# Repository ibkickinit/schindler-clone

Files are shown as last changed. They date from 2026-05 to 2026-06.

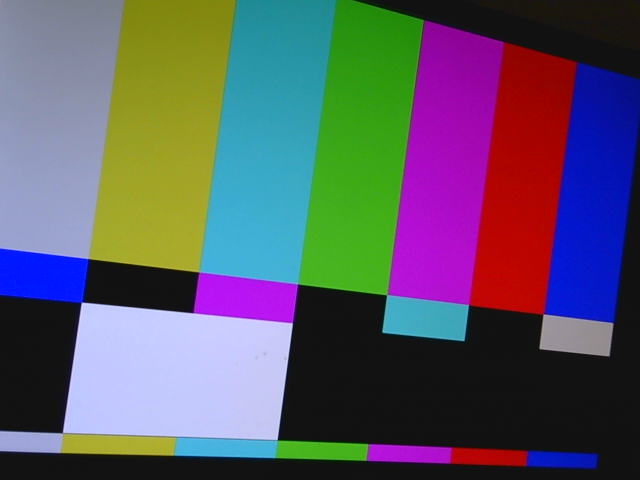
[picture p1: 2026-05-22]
Images/2026-05-21_iter2_printf_moved.jpg

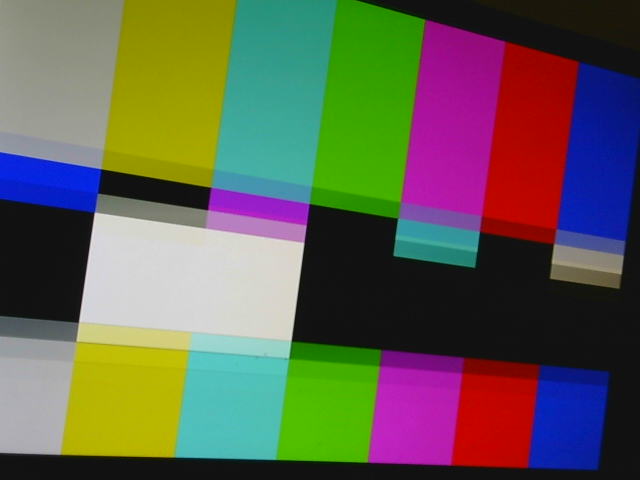
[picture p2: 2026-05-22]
Images/2026-05-21_iter4h_t2.0s.jpg

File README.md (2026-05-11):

# Schindler 2.0

A modern FPGA-based replacement for the Cal Media **Schindler MVPHD-24** — a 24fps video frame rate converter used to drive CRT monitors that appear in film shots. Roughly 75 MVPHD-24 units remain in service worldwide; this project is a from-scratch alternative scoped to modern workflows.

## Scope

- **Input:** HDMI + Composite + Component (with optional broadcast-tier SDI video IN/OUT/loop-through)
- **Output:** Composite + Component (YPbPr) + S-Video, driving 1970s consumer CRTs and broadcast monitors (Sony PVM/BVM); HDMI out for confidence monitoring or live output
- **Genlock:** to film camera reference (LTC, tri-level, black burst, word clock); SDI ref with VITC extraction
- **Frame rates:** 23.976, 24.000, 25.000, 29.97, 30.000, 47.95, 48.000, 50, 59.94, 60 fps (with 60 Hz → 50 Hz cadence conversion for cross-region content)
- **Color pipeline:** ported from the Screenie/NovaTool codebase
- **Control:** dual-band WiFi (concurrent AP + STA) + BLE setup pairing + GbE; web UI hosted on the Zynq PS under PetaLinux
- **Front panel:** 2.8-3.5" color TFT + rotary encoders + hardware buttons + status LEDs (no touchscreen)
- **Rear panel:** 2.2" color TFT (port status, 1Hz refresh) + port status LEDs (no touchscreen)
- 
## Why

The Schindler is unobtainable, expensive when found, and lacks modern color/EDID/web workflows. The market is small but underserved: rental houses, DPs shooting on CRTs, and music-video / period productions.

## Status

Early prototype phase, hardware ordered. See [`docs/01-spec.md`](docs/01-spec.md) for current spec & backlog and [`docs/schindler-playbook.md`](docs/schindler-playbook.md) for the development narrative.

## Hardware

### Development
- Digilent Zybo Z7-20 — FPGA bring-up (Zynq-7020 silicon, matches production target)
- STM32H735G-DK — UI MCU + TFT bench development
- Oscilloscope — signal analysis

### Production architecture
- Trenz TE0720 SOM — Zynq-7020 industrial (-40 to +85 °C), on custom carrier
- STM32H735IGT6 — dedicated front-panel UI MCU
- RP2040 + Si5351 — genlock PLL subsystem
- ADV7393 — composite/component/S-Video output DAC
- ADV7280 — composite/component input decoder
- Semtech GS3470 — SDI receiver (ref + optional broadcast video input)
- Semtech GS2962 — SDI transmitter (broadcast tier)
- Laird Sterling LWB5+ — pre-certified dual-band WiFi/BT module
- Custom 6-8 layer carrier PCB
- 1RU rack chassis

## License

TBD

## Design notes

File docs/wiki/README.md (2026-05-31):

# Schindler 2.0 Wiki

The conceptual + onboarding layer for the project. **Start with [START-HERE](START-HERE.md).**

## Page index

| Page | Purpose |
|---|---|
| **[START-HERE](START-HERE.md)** | 1-pager: what is Schindler, where are we now, what to read next by role |
| [OVERVIEW](OVERVIEW.md) | Product framing, market context, signal flow at 50-ft level |
| [BRANCHES](BRANCHES.md) | Which branch is production today and what each one represents |
| [PHASES](PHASES.md) | Phase A→G map. Status, sub-iter ledger |
| [ARCHITECTURE](ARCHITECTURE.md) | Pipeline topology, clock domains, AXIS interfaces, R-B-G byte order |
| [BUILD-AND-PROGRAM](BUILD-AND-PROGRAM.md) | Vivado + Vitis + program. Toolchain pinning. Common pitfalls |
| [BENCH-WORKFLOW](BENCH-WORKFLOW.md) | Osee switcher, monitor-only rule, no-coin-flip rule, verification protocol |
| [KNOWN-BUGS](KNOWN-BUGS.md) | Open bugs + recently-resolved with iter references |
| [DEBUGGING-PLAYBOOK](DEBUGGING-PLAYBOOK.md) | When-X-happens-do-Y. Core rules + symptoms → root causes |
| [FRC-ARCHITECTURE](FRC-ARCHITECTURE.md) | Methods A/B/C/D/E. RT4K three-mode. Mackin blend |
| [COLOR-PIPELINE](COLOR-PIPELINE.md) | sat → correct → matrix stages. UART tuning. R-B-G byte order |
| [FIRMWARE-INTERFACE](FIRMWARE-INTERFACE.md) | UART command reference (incl. `J` JSON-RPC). AXI GPIO map. DIAG print meanings |
| [PHASE-G-ANALOG](PHASE-G-ANALOG.md) | ADV7393 status, pin map, why blocked, resume plan |
| [PHASE-E-FRC](PHASE-E-FRC.md) | Phase E1/E2/E3/E4 state. Si5351, MMCM tracking, Triple buffer |
| [SCALER-KERNELS](SCALER-KERNELS.md) | iter14 runtime kernel-mode toggle (NN / 2-tap / 4-tap, H+V independent) |
| **[CONTROL-PLANE](CONTROL-PLANE.md)** | **V0a stack: catalog + firmware J + schindlerd + browser UI. Entry point for the V0a tier.** |
| [SCHINDLERD-RUNBOOK](SCHINDLERD-RUNBOOK.md) | Install / run / troubleshoot the daemon. Operator-facing |
| [CATALOG-EVOLUTION](CATALOG-EVOLUTION.md) | How to extend the catalog. Semver rules. Gating attributes |
| [STATUS-PANEL](STATUS-PANEL.md) | Status push protocol — firmware DIAG → telemetry parser → WS notifications |
| [FACTORY-PROFILES](FACTORY-PROFILES.md) | Four shipped baselines (identity, grayscale, warm, cool). Profile schema |
| [BRANCH-RESYNC-PLAYBOOK](BRANCH-RESYNC-PLAYBOOK.md) | How to resync mackin / phase-e1 with iter5 (task #65) |
| [HDMI-COMPLIANCE](HDMI-COMPLIANCE.md) | The rule: no out-of-spec MMCM / TMDS / vendor IP patches |
| [XILINX-IP-NOTES](XILINX-IP-NOTES.md) | Per-IP gotchas: VTC RU bit, v_vid_in sync wires, VDMA DMASR, CDC traps |
| [GLOSSARY](GLOSSARY.md) | 100+ domain terms across pipeline, phases, FRC, hardware, bugs |
| [MIGRATION-NOTES](MIGRATION-NOTES.md) | Overturned claims, stale references, restructuring notes |
| [HISTORICAL-NARRATIVE](HISTORICAL-NARRATIVE.md) | Chronological story May 2026: how we got here |

## What this wiki is (and isn't)

**Is:** the navigable conceptual map. Onboarding surface for new agents. Cross-referenced index pulling from `docs/` and memory entries.

**Isn't:** the canonical source of truth for current state. The load-bearing files at `../`:

- `../build-manifest.md` — **live build state**. Source of truth for "which build is buildable + bench-clean today."
- `../format-support-matrix.md` — **QA truth**. Source of truth for "what input/output combinations are supported."
- `../iter6-*.md`, `../iter4g-*.md`, `../scaler-*.md`, etc. — forensic records of past iter work.
- `../01-spec.md`, `../dev-roadmap.md`, `../packaging-skus.md`, `../bom-v1.md` — product SSOT.

The wiki cross-links to these; it doesn't replace them. When in doubt about current state, check the load-bearing file first; the wiki gives context.

## Finding pending work

Search the wiki for `AGENT_TASK` markers. Currently ~25 prompts categorized by role:

```bash
grep -rn 'AGENT_TASK' docs/wiki/
```

Pattern: `<!-- AGENT_TASK[role-N]: description -->`. Roles:
- `hdl-N` — RTL design tasks
- `fw-N` — Firmware tasks
- `bench-N` — Bench verification owed
- `docs-N` — Documentation tasks
- `test-N` — Test plans + execution

When you complete a task, remove the marker; reference the marker ID in your commit message.

## Wiki maintenance

This wiki was created 2026-05-30 from the audit-panel Wiki Editor proposal. It reflects state at that moment. To keep it useful:

- After any iter ships: update the relevant phase page + KNOWN-BUGS
- After branch tips move: update BRANCHES (cross-check against `../build-manifest.md`)
- New memory entries: cross-link from the appropriate page
- New domain terms: add to GLOSSARY
- Overturned claims: add to MIGRATION-NOTES
- Major events: add a section to HISTORICAL-NARRATIVE

The wiki is intentionally **lossy compression** of the corpus — not every memory entry deserves a wiki page. The point is navigation, not redundancy.

<!-- AGENT_TASK[docs-15]: DONE 2026-05-31 — SCALER-KERNELS.md authored. -->

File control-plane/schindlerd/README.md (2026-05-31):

# schindlerd

V0a host-side bridge daemon for the Schindler 2.0 control plane. Single-file Python implementation per `docs/control-plane-architecture.md` §V0a.

## What it does

- Loads the live catalog (currently `catalog-v0.2.0.json`) and validates control IDs / value coercion at the daemon boundary.
- Opens `/dev/ttyUSB1` and talks to the firmware's `J` UART command (JSON-RPC 2.0 over UART).
- Serves JSON-RPC over WebSocket on `ws://127.0.0.1:8081` for the web UI (and any future remote surface).
- Serves the web UI static files from `control-plane/web/` on `http://127.0.0.1:8080`.
- Stores profiles as JSON files in `~/.schindler/profiles/`.

## Install

```bash
cd control-plane/schindlerd
pip install -r requirements.txt
```

## Run

```bash
python schindlerd.py --port /dev/ttyUSB1 -v
```

Then open http://127.0.0.1:8080 in a browser, or connect a JSON-RPC client to ws://127.0.0.1:8081.

## Methods exposed

| Method | Params | Returns |
|---|---|---|
| `system.identify` | none | daemon+catalog+firmware versions |
| `system.catalog` | none | full catalog v0.1.0 JSON |
| `system.list_controls` | none | `[control_id, …]` |
| `control.get` | `{id}` | `{id, value}` (enum→string translated) |
| `control.set` | `{id, value}` | `{id, value}` after readback |
| `profile.list` | none | `[name, …]` |
| `profile.load` | `{name}` | `{name, applied: [id, …]}` |
| `profile.save` | `{name, controls?}` | `{name, saved: N}` |

Enum values cross the WS boundary as strings (`"boxcar_2tap"`); the daemon translates to integers (`1`) before talking to firmware.

## Protocol traces

When you turn on `-v -v` logging the daemon prints raw UART traffic. Firmware text-log lines (anything not starting with `{`) are mirrored to debug-level only.

## Limitations (v0.1)

- **No status push** — operator status bar polls via `control.get` until V0a+1.
- **No auth / TLS** — bind to localhost only by default. Reverse proxy when shipping.
- **One serial client at a time** — pyserial doesn't multiplex; daemon is the sole owner of `/dev/ttyUSB1` while running.
- **Profile validation is loose** — `profile.load` applies controls best-effort and skips failures; doesn't reject on catalog version mismatch yet.

## Where to extend

- Status push: add a polling task that reads `status.*` controls every N ms and broadcasts `notification` frames to subscribed WS clients.
- HTTP→WebSocket upgrade on the same port: rip out the stdlib HTTP and use `websockets.serve` with `process_request` to route static files.
- Profile validation: compare `profile.catalog_version` to `catalog.version` and reject majors.

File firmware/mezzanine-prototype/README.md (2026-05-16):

# Schindler 2.0 — Mezzanine UI Prototype Firmware

**Target:** RP2040-Zero (Waveshare) on a perfboard test rig.
**Purpose:** Validate encoder + button + OLED firmware against the actual production silicon and physical components before the Pro mezzanine PCB exists.

This firmware is the **production firmware brick** for the Pro mezzanine RP2040, just running on a Pico-class dev board instead of a custom mezzanine PCB. PIO programs, encoder decode logic, debounce parameters, and OLED rendering all port 1:1 to the production board when it's fabbed — pin reassignment is the only change.

## What it does

- Reads two EC11 encoders at 2 kHz (polling-based, software quadrature decode with state-transition LUT)
- Debounces all 9 switches/buttons at 5 ms (5-way nav + Set + BTN_B + two encoder shaft presses)
- Renders status to both 0.91" OLEDs at ~30 fps (independent I²C buses)
- Streams telemetry over USB-CDC for log analysis
- Encodes operational state via the on-board WS2812 RGB LED

## Hardware pin map

```
GP0     5-way nav: UP
GP1     5-way nav: DOWN
GP2     5-way nav: LEFT
GP3     5-way nav: RIGHT
GP4     5-way nav: CENTER (press)
GP5     Set button
GP6     BTN_B  (perfboard "Reset" — NOT hardware reset)
GP8     ENC A  quadrature A
GP9     ENC A  quadrature B
GP10    ENC A  push-switch (shaft press)
GP11    ENC B  quadrature A
GP12    ENC B  quadrature B
GP13    ENC B  push-switch (shaft press)
GP16    WS2812 RGB status LED (on-board RP2040-Zero)
GP26    I²C1 SDA -> OLED B
GP27    I²C1 SCL -> OLED B
GP28    I²C0 SDA -> OLED A
GP29    I²C0 SCL -> OLED A
```

Switches: active-low, internal pull-ups enabled by firmware.
OLEDs: SSD1306, I²C address `0x3C`, 128×32 (0.91").

## Build

### Prerequisites

- **Pico SDK** installed. If you don't have it:
  ```bash
  cd ~
  git clone -b master https://github.com/raspberrypi/pico-sdk.git
  cd pico-sdk
  git submodule update --init
  export PICO_SDK_PATH=$HOME/pico-sdk
  echo 'export PICO_SDK_PATH=$HOME/pico-sdk' >> ~/.zshrc   # or ~/.bashrc
  ```
- **ARM GCC toolchain**, CMake ≥ 3.13, make. On macOS:
  ```bash
  brew install cmake gcc-arm-embedded
  ```

### Copy `pico_sdk_import.cmake`

The Pico SDK ships with `pico_sdk_import.cmake` — a CMake glue file the project needs. Copy it from the SDK:

```bash
cd firmware/mezzanine-prototype
cp $PICO_SDK_PATH/external/pico_sdk_import.cmake .
```

### Build

```bash
mkdir build && cd build
cmake ..
make -j
```

Output of interest: `build/mezzanine_prototype.uf2`

## Flash

1. Hold the **BOOT** button on the RP2040-Zero
2. Plug in the USB-C cable (or press RESET if already plugged in while holding BOOT)
3. The board mounts as a USB drive named `RPI-RP2`
4. Drag `build/mezzanine_prototype.uf2` onto the drive
5. Board auto-reboots into the new firmware

## Test procedure

### Visual checks (OLEDs)

After flash + power-on, both OLEDs should show 4 lines of text within ~2 seconds:

**OLED A (driven by I²C0 on GP28/29):**
```
ENC A +0
RPM 0
CLK 0
BTN -
```

**OLED B (driven by I²C1 on GP26/27):**
```
ENC B +0
RPM 0
CLK 0
MIS 0
```

If only one OLED lights up: check I²C wiring for the dark one. If both are blank: check that the address is actually `0x3C` and pull-up resistors are present (typically 10 kΩ to 3.3 V on each SDA/SCL line — some OLED modules have these built in).

### Functional checks

- **Rotate ENC A clockwise** — `ENC A` counter on OLED A increments by 1 per detent click, `RPM` shows rotation rate, WS2812 LED turns blue
- **Rotate ENC A counter-clockwise** — counter decrements by 1 per click
- **Push the ENC A shaft** — `CLK` count on OLED A increments
- **Same for ENC B** — independent counter on OLED B
- **Press any button or nav direction** — OLED A's bottom line shows the button name (e.g. `BTN UP`, `BTN SET`), WS2812 turns yellow while held
- **WS2812 colors:**
  - Dim green: idle
  - Blue: encoder active in last 200 ms
  - Yellow: any button held
  - Red: missed encoder counts detected (something is wrong)

### USB-CDC telemetry

Connect a serial terminal at 115200 baud to the RP2040's USB-CDC interface:

```bash
# macOS - find the device first
ls /dev/cu.usbmodem*
# Then connect:
screen /dev/cu.usbmodem14201 115200
```

You should see startup banner + event-driven log lines like:

```
t=12345  a=+24 (det +12)  rpm_a=42  b=+0 (det +0)  rpm_b=0  btn=UP  miss=0
```

Rate-limited to 20 Hz for routine rotation; button events emit immediately.

## Direction sign

If a clockwise rotation makes the count go *down* on your perfboard, the A/B encoder pins are swapped vs the LUT's assumption. Two fixes:

1. **Swap pins in firmware:** in `main.c`, swap `ENC_A_PINA` and `ENC_A_PINB` (and/or B's), rebuild, reflash
2. **Re-wire the encoder:** swap the A/B leads physically

Either works. Firmware change is faster.

## What this validates (production-portable outcomes)

- PIO-free polling quadrature decoder under real EC11 contact bounce
- 5 ms software debounce parameter tuning (measure missed-count rate, adjust if needed)
- Two-encoder simultaneous handling with no shared-resource starvation
- I²C bus utilization at 400 kHz (two OLEDs at 30 fps, 512 bytes each = ~12 KB/s per bus)
- SSD1306 init sequence + 128×32 page layout
- WS2812 timing under the standard pico-examples PIO program
- USB-CDC printf overhead under encoder event rates

When the Pro mezzanine PCB exists, this firmware ports by:

1. Updating pin defines for the mezzanine carrier layout
2. Replacing the dual OLED render with BT817Q EVE command-list generation (different drawing API; encoder/button state aggregation logic stays)
3. Adding UART to Zynq PS for state sync (one new module)

## Known limitations (V1 firmware)

- Polling-based quadrature instead of PIO. Adequate for EC11 mechanical rates (max ~1000 edges/sec at extreme manual rotation) but production firmware should move to PIO for headroom + CPU savings. Polling left for V1 to keep the firmware accessible.
- No software acceleration on long scrolls (per the changelog 2026-05-10 note that 10° click pitch warrants accel). Add to V2.
- No menu state machine — this firmware is input characterization only. Menu logic comes next.
- USB-CDC log format is human-readable. Add CSV mode for log-to-file analysis later.
- Detent count = raw_count / 2 in display only. Internal counter tracks 4× quadrature edges for full precision; production may want explicit detent state machine.

## File layout

```
firmware/mezzanine-prototype/
├── main.c                   # firmware core
├── ssd1306.h                # OLED driver + 5x7 ASCII font
├── ws2812.pio               # PIO program for WS2812 (compiled to .pio.h by build)
├── CMakeLists.txt           # build config
├── pico_sdk_import.cmake    # (copy from $PICO_SDK_PATH/external/ — see Build section)
├── README.md                # this file
└── build/                   # CMake build directory (gitignored)
```

## Spec cross-reference

- `01-spec.md` § 15.1 — Mini front panel (5-way nav + buttons subset of this rig)
- `01-spec.md` § 15.2 — Pro mezzanine (dual EC11 encoders subset of this rig)
- `01-spec.md` § 17 — UI architecture (Pro mezzanine firmware role)
- `dev-roadmap.md` § 5.2 — Pro v2 mezzanine front panel build-out

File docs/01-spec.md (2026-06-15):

# Schindler 2.0 — Spec & Backlog

**Status:** Draft 2026-05-13 (post-merge unification)
**Working principle:** Stay Schindler-shaped. Width dilutes the product.

**SSOT** for the internal electronics architecture and feature set. SKU-specific packaging detail lives in [`packaging-skus.md`](packaging-skus.md). Active dev arc + deferred work in [`dev-roadmap.md`](dev-roadmap.md). Dated decision history in [`01-spec-changelog.md`](01-spec-changelog.md). Items marked **[PROPOSED]** are awaiting confirmation; everything else is confirmed.

---

## 0. Product structure

Schindler 2.0 ships in two SKUs that share **one internal electronics design** — same carrier PCB, same TE0720 SOM, same FPGA HDL, same control-plane firmware. The SKUs differ only in:

- **Chassis form factor** (Mini: half-rack 1RU / Pro: full-rack 1RU)
- **Front panel hardware** (Mini: mono OLED + tactile switches; Pro: NHD-2.9 TFT + mezzanine board + dual encoders + per-connector LEDs + rear status LCD)
- **Rear panel I/O complement** (Mini exposes the subset; Pro exposes everything)
- **Carrier stuffing variant** (Mini omits Pro-tier silicon: SDI chips, dual SYNC OUT driver chain, per-connector LED drivers, rear-LCD driver)

*(The **RF modulator** is **not** part of this stuffing-variant split — it's a truly optional standalone daughter-board module; see the note after the SKU table and §3.9.)*

| SKU | Positioning | Indicative retail |
|---|---|---|
| **Mini (v1)** | Lean entry. NTSC/film cadence workflows. HDMI + composite + component + genlock + Ethernet/WiFi. Half-rack chassis. | $1,500–2,500 |
| **Pro (v2)** | Full broadcast-grade. Adds SDI in/out, dual SYNC OUT with cross-rate conversion, rear status LCD, per-connector LEDs, full TFT + mezzanine UI. Full-rack 1RU chassis. RF modulator (period CRT support) available as an optional add-on module — see note below. | $2,500+ |

Pro v2 is gated on Mini v1 selling. **Engineering work targets the unified electronics design** — Mini and Pro are packaging + stuffing variants of one carrier, not two separate hardware development tracks.

**RF modulator (Period CRT support) — truly optional module (2026-06-12).** RF is a self-contained shielded daughter board, **orthogonal to the stuffing variant**: never fitted by default, added only when ordered. The carrier (common to both SKUs) always carries the u.FL + 6-pin interface footprints (~$1.70), so RF is a clean populate/omit on any build with no respin. Offered as a Pro-tier option; **Mini-eligibility is an open product/commercial call** (technically supported on any carrier). See §3.9 + [`rf-modulator-daughter-board-option.md`](rf-modulator-daughter-board-option.md).

See [`packaging-skus.md`](packaging-skus.md) for SKU-by-SKU stuffing tables and chassis detail.

---

## 1. Hardware foundation

### 1.1 SoC module

- **Trenz TE0720 SOM** — Xilinx Zynq-7020. **Production target: TE0720-04-62I33MA** (XC7Z020-2I speed grade, industrial -40 to +85°C, 1 GB DDR3L, 32 MB QSPI flash, 8 GB eMMC, GbE PHY on-module). 152 FPGA I/O via Samtec Razor Beam connectors. Module-level cost ~$300 at qty 100.
- Bench evaluation runs on a TE0720-04-31C33MA SOM (commercial -1 speed grade, same memory config, identical pinout) when available; primary bench dev platform is the Digilent Zybo Z7-20 which shares the same Z-7020 silicon family — HDL ports 1:1.
- **Explicitly ruled out:** -61C530A and similar 256 MB / no-eMMC TE0720 variants — insufficient memory for the Linux-hosted video pipeline (need 1 GB DDR3 for frame buffers + PetaLinux + Node.js + working memory; need eMMC for Linux rootfs).

### 1.2 Carrier PCB

- **Custom 4-layer FR-4 board, ENIG finish**, ~150 × 120 mm estimated, accepts the TE0720 SOM via 2× Samtec LSHM-150 100-pin + 1× Samtec LSHM-130 60-pin Razor Beam connectors (8 mm mating height, ~$30 connector set per unit).
- **What the carrier does NOT need:** BGA layout, DDR3 routing, HDMI differential routing, USB/Ethernet PHY layout. All of that's on the TE0720 SOM. The carrier is conventional mixed-signal PCB work — analog video chains, panel I/O, genlock front-end, WiFi module footprint, power tree, front-panel connector. Layout effort estimate: 3–5 weeks focused work.
- **One PCB design, two stuffing variants** (Mini / Pro). All silicon footprints exist on every carrier; stuffing differs at assembly.
- **Design rule:** unused TE0720 PL pins route to a 2× 20-pin (or 1× 40-pin) 2.54 mm expansion header. Preserves field-upgrade and prototype-extension paths.

### 1.3 Power & safety

- **Power budget:** ~10–14 W typical (Mini), ~14–18 W typical (Pro), ~22 W peak (Pro).
- **AC entry — pre-certified module path.** Custom AC-DC design intentionally avoided (would add ~$15–25K and 3–6 months of NRTL certification for negligible benefit at ~75 unit lifetime volume). All AC-side components carry their own certifications.
- **IEC inlet:** Schaffner **FN9260B-6-06** — C14 + 6 A + integrated fuse holder + 1-stage EMI filter. ~$18 BOM.
- **Mains fuse:** 2 A T (time-lag), 5×20 mm cartridge. Sized for 120 VAC worst-case (steady state ~0.21 A RMS, 7–10× headroom; comfortably absorbs ~25 A / 5 ms cold-start inrush).
- **No rocker switch.** IEC cord = service disconnect; front-panel soft power button handles daily on/off.
- **PSU module — primary:** Mean Well **LRS-50-12** — 50 W / 12 V single output, 85–264 VAC universal, enclosed aluminum case, convection-cooled, UL 62368-1, EN 55032 Class B. ~$15–20.
- **PSU module — alternate:** TDK-Lambda **HWS50A-12/A** — same form factor, lower switching noise. ~$50. Swap-in if Mean Well noise shows up as audible artifact during bench characterization.
- **Mains wiring inside chassis:** UL 1015 stranded, 18–20 AWG, three-conductor, short captive run from IEC inlet to PSU module screw terminals.
- **Earth bonding:** chassis ground stud as the single bond point. IEC earth + PSU earth + chassis enclosure all bonded to stud. Carrier digital ground tied to chassis earth at one point only (single-point earth, prevents ground loops through the analog signal chain).

**Carrier-side 12 V protection chain:**

| Function | Part | Notes |
|---|---|---|
| Protection eFuse | TI **TPS26601** | 60 V integrated FET: reverse-polarity + reverse-current, adjustable OVP, adjustable OCP (precise limit, no polyfuse thermal-derate), controlled inrush slew. EN = front-panel soft-power gate; I<sub>LIM</sub> ≈ 2.5 A. **Latch-off is the '601's MODE-open default (MODE left open, no strap)** — swapped from TPS26600 2026-06-13b (the '600 defaults to auto-retry). Replaces the prior reverse-FET + polyfuse + TVS chain. |
| Power monitor | TI **INA226** + 5 mΩ shunt | I²C 16-bit current+voltage on 12 V rail (telemetry alongside the eFuse). PSU-healthy proxy (LRS-50 has no DC-OK pin). |
| Bulk cap | 3× Murata GRM32 22 µF 25 V X7R MLCC | ~66 µF nominal (~35 µF effective at 12 V DC bias); MLCC over electrolytic for 10+ year service life. |
| PSU→carrier connector | Molex **Mini-Fit Jr.** 2-pin locking | 9 A rated. |
| Soft-power controller | ADI **LTC2954-1** | Pushbutton on/off controller in the always-on 12 V domain (2.7–26.4 V, 6 µA standby — no standby LDO needed). Debounced front-panel button → drives eFuse EN. **INT** → Zynq GPIO (orderly-shutdown request); **KILL** ← Zynq GPIO (clean power-down once Linux has synced); **PDT** watchdog (~5 s) force-off if the PS hangs; turn-on KILL-blank 512 ms lets the system raise KILL during boot. Resolves the chicken-and-egg where the RP2040 sits downstream of the rails it would switch. Button LED off EN state, with an RP2040 leg for status patterns once booted. |

**Per-rail regulators (downstream of protected 12 V) — committed 2026-06-11.** All bucks/LDOs with built-in OCP + thermal shutdown. The TE0720's Vccint 1.0 V, 1.8 V, and DDR3L 1.35 V are generated **on-module** (from VIN) — the carrier does NOT supply them. VIN is fed from the 5 V rail (see `sheet3-te0720-som-backbone.md` §2).
- **5 V (~3 A) — TI LMR33640 (4 A)** buck (12→5 V). Feeds module VIN, USB host, analog op-amps (single +5 V, AC-coupled at the BNCs — no negative rail).
- **3.3 V (~2.5 A) — TI LMR33640 (4 A)** buck (12→3.3 V), same part, 2nd instance. Feeds module 3.3VIN, all four VCCIO banks (3.3 V), carrier digital.
- **1.2 V (~0.4 A) — TI TLV62568** buck (5→1.2 V) [Pro]. GS3470 (~0.15 A) + GS2962 (~0.25 A) on 1.2 V core+analog — verified ~0.3–0.4 A total (GS2962 cable driver sits on 3.3 V analog, not here), so the 1 A part has ample margin.
- **1.8 V analog (~0.4 A) — per-chip low-noise LDOs (TI TPS7A20 / ADI ADP7142 class)** from 3.3 V via ferrite: AD9204 AVDD (dedicated POL), ADV7280 analog, ADV7393 VDD/PVDD (digital + PLL on a clean tap), and **ADV7511 analog/PLL (AVDD/PVDD = 1.8 V)**. Isolated from buck switching for precision genlock.
- **1.8 V digital (~0.1 A) — small LDO off 3.3 V (`+1V8_D`):** VCCIO33 (PL bank 33) + AD9204 DRVDD. Added 2026-06-13 when B33 was re-strapped to 1.8 V to match the AD9204's 1.8 V CMOS data outputs (the module allows 1.2–3.3 V on B33). Kept separate from the analog 1.8 V so ADC output-driver switching stays off the AVDD.
- **3.3 V analog branch — clean tap off the 3.3 V rail** (ferrite + local bulk): ADV7393 VAA (~0.15–0.2 A) only — **ADV7511 analog is 1.8 V, moved to the 1.8 V analog domain (corrected 2026-06-13)**; the **GS2962 cable driver gets its own ferrite branch** (SDI-rate transients kept off the DAC analog).
- **Clean analog rails — point-of-load ultra-low-noise LDOs** (ADP7142 class) per ADC/decoder, sized at schematic.

### 1.4 Resolution ceiling

- **1080p60 max** input + output for V1. HDMI 1.4 input handled by **Lontium LT8619C** RX (Z-7020 has no MGTs, no direct TMDS deserialize).
- 4K deferred to v2 / Schindler 3.0 — requires SoC upgrade (Zynq UltraScale+ ZU3EG/ZU4EV via TE0820/TE0822), DDR4, HDMI 2.0/2.1 silicon, HDCP 2.2/2.3 licensing. Treated as a separate product, not a V1 stretch goal.

---

## 2. HD pipeline architecture

### 2.1 Pipeline carries HD-bandwidth video throughout

RGB or YCbCr 4:2:2 at up to 1080p60 (148.5 MHz pixel clock) flows from input decoder through scaler / color / geometry to a shared HD signal bus. Downconversion to SD and rate-conversion happen **only inside per-output terminal encoders** that need it (composite, S-Video, SD component).

### 2.2 Outputs are independent and concurrent

The HD signal bus fans out to one terminal encoder per output. All terminals can run simultaneously at their own format and rate. Example: 1080p60 HDMI source can drive 1080p60 HDMI OUT + NTSC composite OUT (downconvert + 5:2 cadence + composite encode) + HD component OUT (YPbPr) all live from the same source.

### 2.3 Terminal encoders (independent FPGA blocks)

- **HDMI passthrough terminal** [All SKUs] — format-match or rate-convert, then HDMI 1.4 TX. Drives the external ADV7511 HDMI TX chip on the carrier. HDCP-protected content gated by UI consent dialog (§ 3.5).
- **NTSC/PAL composite encoder terminal** [All SKUs] — HD-to-SD downconvert + cadence convert + luma+chroma encode + sync gen. Drives ADV7393 in composite mode. HDL: `hdl/vid_timing.v` + `hdl/vbi_gen.v` + `hdl/chroma_gen.v` + `hdl/sample_gen.v` (Phase 2 first-light validated on Zybo + R2R DAC; chroma burst verification deferred per `dev-roadmap.md`).
- **Component YPbPr encoder terminal** [All SKUs] — HD passthrough or SD downconvert, drives ADV7393 in component mode.
- **SDI passthrough terminal** [Pro only] — HD re-serialize, drives GS2962.

### 2.4 Test pattern generator + still buffers as source

TPG + 4 still image buffers selectable as input source via the source mux (alongside HDMI / SDI / composite / component inputs), default at power-on. See `signal-flow.md` diagram 1.

---

## 3. Per-subsystem detail

### 3.1 HDMI input [All SKUs]

- **TPD12S016PWR** (TI) — HDMI ESD clamps + DDC/HPD level shift + 5V cable-power switch. ~$1.50.
- **LT8619C** (Lontium) — HDMI 1.4 RX, parallel RGB output to FPGA, embedded HDCP 1.4 keys (Lontium holds DCP Adopter Agreement). ~$2.
- Parallel RGB bus (24-bit + HSYNC + VSYNC + DE + pixel clock, ~28 lines) to TE0720 PL.
- I²C control from TE0720 PS — input mode, EDID (advertise V1's supported rates: 720p / 1080p / 1080i at 24/30/60 Hz; explicit reject of 25/50 Hz unless international firmware enables them).

### 3.2 HDMI output [All SKUs]

- **ADV7511KSTZ** (Analog Devices, LQFP-100) — HDMI 1.4 TX. Parallel RGB or YCbCr 4:2:2 input from FPGA on **its own dedicated 16-bit bus** (no longer shared with ADV7393); TMDS output. **Utility/monitoring output — no HDCP asserted on the TMDS output** (avoids the Xilinx HDCP-TX IP + DCP adopter license); a UI toggle disables the default HDCP block so protected content passes unencrypted per § 3.5. ~$7.
- **TPD12S016PWR** — second instance on output side for ESD/level shift.
- HDMI Type A panel-mount connector.
- I²C control from TE0720 PS.
- **Independent output buses (2026-06-11):** HDMI OUT, SDI OUT, and analog OUT each have their own FPGA read engine and parallel bus — no sharing. (Supersedes the earlier ADV7511/ADV7393 shared-bus optimization: the pin budget fits at ~119/152 PL without it, and sharing forced HDMI-out to track analog-out's format/rate — which broke concurrent 1080p60-HDMI + SD-composite, the headline §2.2 use case.)

### 3.3 Composite / component / S-Video input [All SKUs]

- **ADV7280AWBCPZ-M-RL** (ADI, AEC-Q100 grade, MIPI-capable variant) — multi-format decoder. CVBS + YPbPr + S-Video → BT.656 YCbCr 4:2:2 parallel bus to FPGA. ~$19.
- **SD-only input** — the ADV7280 decodes standard-definition only (480i/576i): CVBS, S-Video, and **SD component** YPbPr. **HD analog component (1080i/p) is not an input path** — HD enters via HDMI/SDI and the box upconverts SD analog → HD. (HD analog in would need an ADV7842-class decoder — out of V1 scope.)
- BNC 75 Ω panel-mount: 1× CVBS in + 3× YPbPr (component in). S-Video silicon-capable; no V1 mini-DIN connector (dropped 2026-05-11).
- I²C control from TE0720 PS.
- Passive front-end: input clamp diodes, switchable 75 Ω termination, AC-coupling, anti-alias LPF — schematic-phase.

### 3.4 Composite / component / S-Video output [All SKUs]

- **ADV7393BCPZ-REEL** (ADI) — triple 10-bit DAC with composite/S-Video/component encoding. I²C-switched runtime mode: composite/S-Video (DAC_A=CVBS, DAC_B=Y, DAC_C=C) OR component (DAC_A=Y, DAC_B=Pb, DAC_C=Pr). ~$16. Fed from the FPGA on **its own dedicated 16-bit parallel bus** (independent read engine; 16-bit carries SD composite/S-Video plus SD/ED/HD component per §2.2).
- **Output buffers (consolidated 2026-06-11):** 2× **LMH6643MAX/NOPB** dual op-amps (4 ch, 3 used) — one 130 MHz HD-capable channel per DAC output, serving both composite and component modes (single +5 V, AC-coupled at the BNCs). Replaces the prior OPA2350 SDTV-tier + single LMH6643: the 3-channel HD component path needs 3 HD buffers, so the two-tier split under-counted; all-LMH6643 is one part type, HD on every channel. ~$3 total. **One channel (4th of the 4) is spare.**
- **Optional second composite output [pre-layout decision, 2026-06-12]:** the spare LMH6643 channel can drive a second buffered CVBS output (its own 75 Ω back-term) to a rear BNC. Two ways to expose it: (a) an always-present second composite out — a composite mult/loop, useful for feeding a local monitor + a record path at once; or (b) in the **no-RF stuffing variant**, repurpose the rear F-connector position as this second composite BNC (RF fitted → F-connector; RF omitted → 2nd composite). Either way the footprint + back-term + panel position must be fixed **before carrier layout** (a respin to add later — same class as the 2nd-GbE-jack flag). The RF baseband tap is unaffected: it's a high-Z bridge off the *first* composite channel, not this spare one. Panel position tracked in `panel-layout.md`.
- **Rails:** ADV7393 draws 1.8 V (VDD digital + PVDD PLL) + 3.3 V VAA (analog, ~0.15–0.2 A). VAA sits on a clean 3.3 V branch (ferrite + local bulk); **the ADV7511 analog/PLL is 1.8 V — not on this 3.3 V branch (corrected 2026-06-13, see §1.3)**; the GS2962 cable driver gets its own ferrite branch so SDI-rate edges don't couple into the DAC analog. See §1.3.
- 4× BNC 75 Ω panel-mount (1× CVBS out + 3× YPbPr) with SMPTE-compliant back-termination.
- S-Video silicon-capable from ADV7393 in composite mode (Y + C on two DAC channels); no V1 mini-DIN connector.
- Modes: NTSC / NTSC-J / PAL / PAL-M (composite); SMPTE / Beta / Wide levels (component).

### 3.5 HDCP architecture [All SKUs]

- **Default-safe behavior:** HDCP-protected content (detected via LT8619C / GS3470 authentication state) is **blocked from HDMI OUT** by the HDMI passthrough terminal. Protected content can still flow to analog outputs (composite/component/S-Video don't carry HDCP) and to SDI OUT (broadcast workflow assumption).
- **UI consent gate (operator override):** unlocked via a UI dialog requiring explicit attestation ("I attest this is a non-violating use"). Once attested, HDMI passthrough permits HDCP-protected content through unencrypted. Attorney-advised posture.
- Non-protected content flows through HDMI OUT with no gate.
- **No HDCP encryption on HDMI OUT** — avoids the Xilinx HDCP IP license + DCP Adopter Agreement cost path.

### 3.6 SDI input/output [Pro only — carrier stuffing variant]

- **GS3470** (Semtech) — SDI 1.485/2.97 Gb/s RX. Recovers clock + VITC; feeds video pipeline AND genlock subsystem as a reference source. ~$15.
- **GS2962** (Semtech) — SDI TX. ~$17.
- 4× BNC 75 Ω panel-mount (Pro only): 1× IN + 1× **IN LOOP** (reclocked loop-through of the SDI input, for daisy-chaining the source downstream) + 1× processed OUT + 1× **OUT MIRROR** (buffered duplicate of the processed OUT).
- **SPI (GSPI) control from TE0720 PS** — GS3470/GS2962 use a 4-wire SPI host interface (CS/SCLK/SDIN/SDOUT), not I²C (confirmed 2026-06-13); shares the SDI SPI bus, separate CS each.
- Mini SKU: GS3470/GS2962 footprints on the carrier are unpopulated; Pro stuffing populates them. No daughter card; single PCB, factory-stuffed per SKU.
- **SDI IN LOOP [added 2026-06-13]:** an SDI input loop-through output, re-instating the GS3470 loop/mux path parked 2026-05-11. Implement as a **reclocked/buffered** loop — *not* the original passive tee (a passive 3G-SDI loop degrades the signal); confirm the exact GS3470 loop mechanism + any external reclocker/buffer at schematic. It is an **active** loop (drops on power loss), not a passive DA-style loop. SI-critical 3G serial → carrier-side, rear-panel **Row 1** next to the GS3470. *(HDMI IN loop was evaluated and **rejected** — no passive HDMI loop exists; it would need a TMDS splitter/redriver + HDCP-repeater handling, out of proportion for V1, and concurrent outputs per §2.2 already cover the downstream-monitor use case.)*
- **SDI OUT MIRROR [added 2026-06-13]:** the GS2962 exposes two serial-digital outputs (**C10 / D10**); the second SDO drives a buffered duplicate of the same processed SDI stream to a fourth SDI BNC. **Active** (drops on power loss), SI-critical 3G serial → carrier-side, rear-panel **Row 1** next to the GS2962. KiCad: placed as **J703** on Sheet 7. Use case: feed two downstream SDI destinations from one processed output without an external DA.

### 3.7 Genlock subsystem [All SKUs]

Auto-sensing reference input across LTC / black burst / tri-level sync.

**Front-end:**
- BNC 75 Ω panel-mount: **REF IN** + **REF LOOP** (passive loop-through for daisy-chaining).
- **REF interconnect — Option A pigtail (banked 2026-06-13):** the REF panel BNCs connect to the carrier genlock front-end by a short **75 Ω coax pigtail → Hirose U.FL-R-SMT-1** receptacle on the carrier — continuous coax from panel to silicon, no board-to-board mezzanine hop on the phase-critical sync lines (this is what lets the BNCs mount on the riser while the genlock front-end stays carrier-rooted). u.FL is 50 Ω / 6 GHz; the few-cm 50 Ω segment is an electrically negligible reflection at genlock/tri-level edge rates. **Upgrade path** (impedance-exact + serviceable, if ever needed on these 2 lines): swap to a 75 Ω MMCX PCB jack (~500 mating cycles, ~$3–6 ea). A 75 Ω blind-mate float-bullet was evaluated and rejected — effectively a custom part (the SMP/SMPM/AFI float catalogs are all 50 Ω). See `bom-v1.md` §2 and the 2026-06-13 changelog entry.
- Clamp diodes, switchable 75 Ω termination, AC-coupled buffer.
- **LTC6912CGN-2#PBF** (ADI/LTC) — 2-channel programmable gain amplifier. ~$8.
- **AD9204BCPZ-20** (ADI) — dual-channel 10-bit 20 MSPS ADC. ~$16. Pin-compatible upgrade path to AD9231/9251/9258/9268 if higher resolution becomes necessary.

**Signal classification + clock generation:**
- **RP2040** (carrier, dedicated to genlock) — owns slow-control: autosense decision, PGA gain commands, Si5351 register writes, status reporting to Zynq PS over UART. ~$1.
- **Si5351A-B-GT** (Skyworks/Silicon Labs) — programmable clock generator. ch0 → FPGA master clock; ch1/ch2 reserved for future GPSDO 10 MHz distribution. ~$2.

**FPGA-side logic (all SKUs):**
- Autosense classifier (LTC biphase mark / BB 15.734 kHz / tri-level pulse signature) running on the 20 MSPS ADC stream.
- Per-format decoders: LTC frame decoder + TC parser, BB sync separator + colorburst phase extract, tri-level decoder, SDI recovered clock + VITC from GS3470 (Pro only).
- Reference selector mux (operator override + autosense priority: LTC > tri-level > BB > SDI > free-run).
- Digital PLL: phase/frequency detector → loop filter (default ~0.5 Hz bandwidth, configurable) → NCO/integrator (holds last value on ref loss → free-run hold) → lock detector (Acquiring / Locked / Lost state + phase-error magnitude + 1 s stddev quality metric). Integrator's correction pushed to Si5351 via RP2040 over I²C.

**VITC:** extracted from SDI video input (Pro only) when SDI is selected as reference — removes need for separate LTC cable when SDI video is already connected.

### 3.8 Reference outputs — dual SYNC OUT [Pro only]

- 2× BNC 75 Ω panel-mount (SYNC OUT 1 + SYNC OUT 2).
- **SYNC OUT 1** — runtime format select: black burst / tri-level / LTC unbalanced (also DARS AES3id 48 kHz + Word Clock 48/96 kHz as firmware-only future). **SYNC OUT 2 — LTC only.** Driver bandwidth DC–10 MHz, output swing ≥2 Vpp into 75 Ω.
- Each OUT targets its own frame rate, locked to the input reference via rational ratios. Cross-rate sync conversion absorbed into V1 Pro (originally scoped as V1.5).
- **SYNC OUT 1 chain:** FPGA phase accumulator → waveform gen → **AD9742** (12-bit, 210 MSPS TxDAC, current-output; pin-compatible to AD9744 if 14-bit ever needed) → I-to-V + **LMH6643** 75 Ω cable driver. 13 PL pins (12 data + sample clock). **SYNC OUT 2 chain:** FPGA biphase-mark generator → 1 PL pin → slew-limited **LMH6643** (2nd channel of the same dual, SMPTE 12M ~25 µs edges) → 75 Ω BNC. **PWM dropped** — it cannot reproduce black-burst colorburst (3.58/4.43 MHz) or tri-level edges (~4 ns) at usable resolution; viable for LTC only.
- Mini SKU: unpopulated; the SYNC OUT 1 DAC + shared LMH6643 driver + SYNC OUT 2 LTC chain are omitted at assembly. REF LOOP BNC + REF IN BNC remain on Mini for genlock input.

### 3.9 RF modulator output [Optional module — Period CRT support]

Adds an RF modulated output on NTSC Ch3 or Ch4 (operator-selectable) for 1970s consumer CRTs with antenna-only inputs.

**Operator model:** picks one of three analog output modes via UI. F-connector lives beside the composite BNC; both physically present, only one electrically live per mode.

| Mode | Live connector | ADV7393 state | RF chain |
|---|---|---|---|
| Composite | composite BNC | composite mode | disabled |
| RF Ch3 | F-connector (+ composite BNC) | composite mode | enabled, Si5351 ch1 → 61.25 MHz |
| RF Ch4 | F-connector (+ composite BNC) | composite mode | enabled, Si5351 ch1 → 67.25 MHz |
| Component | 3× component BNC | component mode | disabled |

HDMI and SDI remain independently live; not part of the analog-output mode mux. The composite BNC stays live in RF mode (the RF chain taps the same buffered signal; the ADG419 series switch was dropped 2026-06-11 — a ~25 Ω switch in a 75 Ω video line degraded the composite output for no benefit).

**Architecture (separate daughter board — committed 2026-06-11):** the whole RF chain — ADL5391 analog multiplier (DSB-AM) + dedicated Si5351 RF carrier gen + silent CW audio pilot at video_carrier + 4.5 MHz + 5th-order LC bandpass (56–73 MHz, covers Ch3 + Ch4) + ERA-3SM+ MMIC amp + 50→75 Ω minimum-loss pad + ESD + F-connector — lives on a **standalone shielded, panel-mounted daughter board** (Masach MS643 two-piece can, 4-layer PCB), not on the carrier. The carrier feeds it baseband composite over **1× u.FL** + a **6-pin header** (12 V, 3.3 V, GND×2, I²C); no VHF crosses the interconnect (RF Si5351 + crystal are on the board). RF mute = disable the daughter-board Si5351 output over I²C. Cleanest FCC partition — all RF in one Faraday box — and makes the Mini-omit a populate/omit choice with no carrier respin.

**Truly optional (2026-06-12):** never fitted by default — added only when ordered. The carrier (both SKUs) always carries the unpopulated u.FL pad + 6-pin header, so RF is a clean populate/omit on any build with no respin. Offered as a Pro-tier option; Mini-eligibility is an open product/commercial call (technically fittable on any carrier).

Full spec: [`rf-modulator-subsystem.md`](rf-modulator-subsystem.md) (chain) + [`rf-modulator-daughter-board-option.md`](rf-modulator-daughter-board-option.md) (partition + build). BOM contribution (Pro): ~$40 daughter-board assembly + ~$1 carrier interface.

---

## 4. Frame rates

### 4.1 Pipeline throughput rates (HD path)

1080p23.98 / 1080p24 / 1080p25 / 1080p29.97 / 1080p30 / 1080p50 / 1080p59.94 / 1080p60 / 1080i50 / 1080i59.94 / 720p50 / 720p59.94 / 720p60.

### 4.2 Output rates per terminal encoder

- **Composite / component encoder (analog outputs):** 23.976 / 24.000 / 25.000 / 29.97 / 30.000 fps.
- **HDMI / SDI passthrough:** matches selected output rate (full pipeline rate matrix).

### 4.3 Cadence convert per output

- **3:2 auto-detect** (default Auto): when source is 30/60 fps with 3:2 cadence in the data (telecined 24p material), detects the cadence and extracts the original 24p sequence without motion filtering. Cleaner than blind frame-rate conversion. Auto-falls-back to motion filtering when 3:2 cadence isn't detected.
- Manual cadence ratios: 5:2 (60→24), 6:5 (60→25), 4:5 (24→30), 2:1 (60→30), 1:2 (24→48), Slip (23.98↔24 drift comp).
- **Motion filter selection:** Quadratic (default, 3-frame) / Linear (2-frame, lighter DSP) / Off (drop or repeat frames, produces judder).

---

## 5. Color pipeline (port from Screenie)

- 1D LUT per channel (gamma, 1024 entries × 12-bit)
- 3×3 color matrix (color space + white point)
- Per-channel gain/offset (fine trim)
- RGB white/black point controls
- Color temperature presets: 3200 K / 4800 K / 5600 K / 6500 K / 9300 K / Custom
- **YUV color-circle adjust** (X/Y axes on chroma plane) in addition to RGB controls. Preserves luminance + saturation when shifting color temp (vs RGB subtraction which darkens and desaturates). Inherited from MVPHD-24's approach; preferred by video colorists familiar with vectorscope X/Y.
- Saturation, hue, black level
- **Proc Amp Enable bypass toggle** — single per-input toggle disables all proc-amp adjustments (unity gain). Used for raw-vs-adjusted quick compare. Bindable to a front-panel quick-select button (default Q3).

---

## 6. Geometry

- Anamorphic / Letterbox / Pillarbox / 14:9 Letter / 14:9 Pillar / Cut-Crop / Custom — explicit ARC modes with both-direction labeling (16:9→4:3 + 4:3→16:9).
- Pincushion / keystone / 4-corner warp.
- Polyphase scaler (8-tap H / 4-tap V).
- Active window position trim (X/Y pixel offset).
- Overscan compensation modes: safe-area-only vs fill-with-overscan.

---

## 7. Effects library

13-effect EFX menu. Effects can be temporarily toggled OR saved into a per-CRT profile for permanent operation. Profile-persistent enables the "make this LCD look like a CRT in-shot" workflow (scanlines + slight blur + warm tint saved as a profile).

**Effects:**
- Freeze frame
- Random noise (snow)
- Block artifacts (intensity-configurable)
- CRT power-off (collapse + flash + black, ~1.5 s)
- CRT power-on (flash + scan-in)
- Vertical hold loss (rolling)
- Snow burst (channel change)
- Color rolling (chroma desync)
- VHS tracking error (drifting noise bars)
- Hum bars (slow horizontal dim bars)
- Burn-in ghost overlay (source from still buffer)
- Scanline emphasis (CRT look on downstream LCD)
- Blur (Gaussian — Tier 3 HDL cost, may land later in V1)
- Solarize
- Posterize

**Modifiers:** blend/mixer (0–100 % wet/dry), transition time (0–240 frames fade in/out), per-effect intensity params.

**HDL effort:** ~2–3 weeks for MVPHD-set + Tier 1 CRT effects post-pipeline-validation; blur deferred if needed.

---

## 8. Per-CRT calibration profiles

- JSON profiles in the NovaTool tile-profile pattern.
- Import / export via web UI; recall by name from front panel or web.
- Snapshots: color + geometry + sync structure + behavior + effects.
- 4× front-panel quick-recall buttons (Mini: P1–P4; Pro: bindable quick-selects).

---

## 9. CRT-specific signal controls

- Sync structure parameters (per profile): front porch, back porch, equalizing pulse count, serration pulse width.
  - **Wide-back-porch default for 24p camera shoots** — back porch ≈ 7–10 µs (1.5–2× SMPTE 170M nominal ~4.7 µs). Gives camera shutter a larger target window to land its capture inside the active video region without straddling V-blank — eliminates filmed-CRT sync bar. Industry wisdom (2026-05-11). Tunable per-profile so DPs can adjust to their shutter angle.
- Alternating 90° colorburst phase offset between fields (toggle). Improves CRT chroma stability (playbook Ch. 5).
- Subcarrier coherent vs non-coherent toggle (playbook Ch. 4).
- Sync tip voltage trim — ±100 mV around SMPTE −286 mV (for oddball-AGC CRTs).
- Setup pedestal: 7.5 IRE (NTSC-M) vs 0 IRE (NTSC-J).
- Output mode select: NTSC / NTSC-J / PAL / PAL-M.
- Field cadence / pulldown options for non-matching rates: off / hard switch / crossfade.
- VITC insertion in output.

---

## 10. Behavior controls

- Signal loss behavior: black / freeze / last-good-frame-for-N-seconds.
- Burn-in protection: auto-darken or pixel-shift after N minutes static.
- Burn-in recovery / repair mode: standalone scrolling white/black/gray patterns at user-set rate. Runs from front panel with no input. Known CRT repair technique.
- Degauss trigger output: GPIO/relay for pro CRTs that accept remote degauss.

---

## 11. EDID

- Editable / emulatable EDID on HDMI inputs.
- Resolution + rate + preset selectable independently (UI menu § 1.2).
- Force-mode presets: 1080p24, 1080p23.98, 1080p25, 720p, Custom (web-upload `.bin`).
- Without correct EDID, playback laptops negotiate to whatever they feel like and burn shoot time on format debugging. Day-1 critical.

---

## 12. Test pattern generator

- SMPTE color bars (75 % / 100 % / SMPTE).
- PLUGE.
- Color reference fields.
- Geometry grid (100 % / 95 % / 90 % safe area).
- Convergence pattern (operator CRT alignment, separate from content warp).
- Purity (full-field R/G/B).
- Focus / zone plate (center + corners).
- Burn-in repair scroll patterns.
- **Shutter Phase Reference** — alternating-field two-color signal for visually phasing a film camera's shutter to the CRT. Solid color in viewfinder = correctly phased; split color = mis-phased. Default Blue/Yellow (industry convention); color pair operator-configurable.
- **Custom user-loaded test signals** (8 slots) — operator uploads PNG/TIFF via web UI; stored on TE0720 eMMC, persist across power cycles.

---

## 13. Still image buffers

- 4 image buffers on TE0720 eMMC, selectable as input source via source mux. Persist across power cycles.
- **Format:** PNG up to 1920×1080. Downscaled on the fly to output rate. Typical ~1–5 MB per slot.
- **Primary storage:** TE0720 eMMC (8 GB total; ~25 MB used for 4 slots).
- **Storage:** on-module eMMC (8 GB) holds the image library; firmware updates + library load over network / USB-C. (Front-panel microSD dropped 2026-06-11 — only one free PS SDIO controller, taken by WiFi; see `sheet3-te0720-som-backbone.md` §4.)
- **Load time:** cold load from eMMC < 1 s; cached in DDR3 < 10 ms.
- **First-boot state:** Buffer 1 pre-populated at factory with a Schindler splash image (logo + IP + firmware version). Buffers 2–4 ship empty.
- **Use cases:** power-on splash, idle reference frame, custom brand ident, quick-recall reference for QC, signal-loss fallback, source for EFX burn-in ghost overlay.
- **Thumbnails:** Pro front-panel TFT shows 4-wide horizontal thumbnail strip; Mini OLED shows text-only buffer status; web UI shows full-quality thumbnails.

---

## 14. Networking + control plane

> ⚠️ **Partially superseded — see the 2026-06-13 direction update atop [`control-plane-architecture.md`](control-plane-architecture.md).** UI is now **unified across all SKUs on a standalone off-SoM MCU** (one firmware = front panel + web UI); `schindlerd` becomes a thin PS-side AXI register agent. The PS-hosted web server below is being reworked; the head-MCU choice (ESP32-S3 vs RP2040 + Ethernet/WiFi) is the open sub-decision. Propagated here once the MCU is locked.

- **Zynq PS (dual A9 Cortex @ 866 MHz) running PetaLinux** hosts the control plane on both SKUs: web UI server (Node.js / Flask), color calibration UI, configuration persistence, EDID negotiation, mDNS, OTA updates, SSH / SCP, NTP, status logging.
- **Wired:** GbE on TE0720 (PHY on-module) → RJ45 magjack on carrier → rear panel.
- **WiFi:** Laird Sterling LWB5+ module on carrier — pre-certified, 88W8997 chipset, dual-band a/b/g/n/ac + BT5.0. WiFi on **SDIO0 (PS MIO40–45, strapped to 1.8 V — direct, no level shifter)**; BT on a separate PS UART. ~$30. Concurrent AP + STA via Linux hostapd + wpa_supplicant. Mini may stuff lower-cost ESP32-WROOM (~$5) as a cost-down option; assembly-time decision per `packaging-skus.md`.
- **Antennas:** 2× RP-SMA stubs on rear panel (Pro) or internal chip antenna (Mini compact option).
- **BLE:** for initial pairing/setup. Companion app discovers Schindler via BLE, sends WiFi credentials over encrypted GATT.
- **USB-C** on rear panel for service / firmware update / debug. PetaLinux exposes console + ethernet-over-USB gadget for ops access without network.

---

## 15. Front panel — SKU variants

> ⚠️ **Partially superseded — see the 2026-06-13 direction update atop [`control-plane-architecture.md`](control-plane-architecture.md).** UI is now **unified across all SKUs on a standalone off-SoM MCU** (one firmware = front panel + web UI). The display *hardware* below still stands (Mini OLED / Pro TFT), but "no dedicated UI MCU on Mini" and the PS-driven Mini UI are retired — both SKUs run the off-SoM MCU head. Head-MCU choice (ESP32-S3 vs RP2040 + Ethernet/WiFi) is the open sub-decision; propagated here once locked.

### 15.1 Mini front panel [Mini only]

- Power button (lighted soft pushbutton).
- 1.3" mono OLED display (I²C, SH1106 or SSD1306) — status display + menu.
- 5-way navigation switch (D-pad + center enter) — GPIO via EMIO to Zynq PS.
- 4× tactile preset buttons (P1–P4) — GPIO via EMIO to Zynq PS.
- Single tri-color status LED (green=locked, amber=input issue, red=sync loss/error).
- **No dedicated UI MCU.** PetaLinux user-space app drives OLED via `/dev/i2c-N` and buttons via `gpio-sysfs` interrupt handlers.

### 15.2 Pro front panel [Pro only]

Separate mezzanine board mounted behind the front-panel aluminium, connected to main carrier via UART + power cable.

- Power button (lighted soft pushbutton).
- **Front TFT — Newhaven NHD-2.9-376960AF-ASXP** — 2.9" 376×960 IPS, mounted landscape (effective 960×376), ST7701SN driver. 24-bit parallel RGB. 1050 cd/m². Bezel-opening cutout 69×28 mm.
- **BridgeTek BT817Q EVE 4 graphics controller** — drives the NHD-2.9 over 24-bit parallel RGB, holds frame in 1 MB internal RAM_G, renders from high-level command lists sent by RP2040 over SPI. ~$10–13.
- **Mezzanine RP2040** (separate from genlock RP2040 on carrier) — UI MCU. Reads encoders + buttons via PIO/GPIO, sends EVE command lists over SPI, syncs UI state to Zynq PS over UART. ~$1.
- 2× ALPS EC11E18244AU rotary encoders (36 detents / 18 PPR, integrated push-switch, **knob shroud / guard** mandatory).
- 4 fixed tactile buttons: Home / Back / Menu / Confirm.
- 2–3 quick-select tactile buttons (defaults: BLACK / MONO / Proc Amp bypass).
- Front status LED column (mirrors rear per-connector LED state).
- **NHD-2.9 backlight: 6.0 V boost regulator** on mezzanine (TI TPS61040 class, ~$0.50).

---

## 16. Rear panel — SKU variants

### 16.1 Mini rear panel [Mini only]

| Connector | Qty | Notes |
|---|---|---|
| HDMI Type A | 2 | IN + OUT |
| BNC 75 Ω | 6 | 1× CVBS IN + 1× CVBS OUT + 3× component OUT + 1× genlock REF IN |
| Mini-DIN 4-pin | 0 or 1 | S-Video silicon-capable; connector optional per build |
| RJ45 magjack | 1 | GbE |
| USB-C | 1 | Service / firmware update |
| DC power jack OR IEC C14 | 1 | Pending PSU-style decision (external brick vs internal LRS-50-12) |
| RP-SMA WiFi antenna | 0 or 2 | Internal chip antenna or external |

### 16.2 Pro rear panel [Pro only]

| Connector | Qty | Notes |
|---|---|---|
| IEC C14 (FN9260B-6-06) | 1 | Mains + integrated fuse + EMI filter |
| HDMI Type A | 2 | IN + OUT |
| BNC 75 Ω | 16 | 1× CVBS IN + 1× CVBS OUT + 3× component IN + 3× component OUT + 2× REF (IN + LOOP) + 2× SYNC OUT + 4× SDI (IN + IN LOOP + OUT + OUT mirror) |
| F-connector | 1 | RF modulator output (on the RF daughter board's own panel edge) |
| RJ45 magjack | 1 | GbE |
| USB-C | 1 | Service / firmware update |
| RP-SMA WiFi antennas | 2 | Dual antennas for AP+STA |
| **Rear status LCD** | 1 | NHD-1.5 240×240 (see § 17) |
| Per-connector status LEDs | ~21 | Tricolor R/A/G (see § 18) |

### 16.3 Rear status LCD [Pro only]

- **Newhaven NHD-1.5-240240AF-CSXP** — 1.5" 240×240 IPS square, ST7789VI with internal controller + frame RAM. 32.52 × 35.32 mm module, ~28 × 28 mm active cutout. 1200 cd/m².
- Interface: 8-bit 8080-II parallel OR 3/4-wire SPI; **4-wire SPI hardwired via strap pins** IM0=0/IM1=1/IM2=1.
- **Backlight: 3.0 V / 100 mA** — small LDO from 3.3 V (~$0.20).
- Owned by Zynq PS over one dedicated SPI port. ~1 s refresh.
- Content: paginated summary view — selected ref + lock state + IP + page-through I/O detail. Read-only.

### 16.4 Per-connector status LEDs [Pro only]

- Tricolor R/A/G LED at every Pro rear-panel connector. **Lumex SSF-LXH409SISUGW** — 3 mm bi-color R/G **common-anode**, one-piece **right-angle PCB indicator** (emits parallel to the board → faces the rear panel; no holder or light pipe), ~$0.60–1.00 each (confirm at procurement). Banked 2026-06-13c.
- **Driver:** 3× **TLC59116F** (TI) — 16-channel constant-current I²C drivers with per-channel PWM dimming. ~$1.50 each.
- **Convention (inputs):** Red = expected/missing, Amber = present/not-in-use, Green = present/in-use, Off = disabled.
- **Convention (outputs):** Green = present/outputting, Amber = configured/no source, Off = disabled.
- **Convention (sync IN):** Red = invalid, Amber = locked/not selected, Green = locked/selected as ref, Off = nothing.
- Default brightness ~10 %; ramps up on fault.
- Owned by Zynq PS over I²C. Front-panel LED column mirrors rear state on Pro.

---

## 17. UI architecture

> ⚠️ **Partially superseded — see the 2026-06-13 direction update atop [`control-plane-architecture.md`](control-plane-architecture.md).** UI is now **unified across all SKUs on a standalone off-SoM MCU** — one firmware drives both the front panel and the web UI; the per-SKU split below (Pro RP2040+PS / Mini PS-direct) is retired. `schindlerd` shrinks to a thin PS-side AXI register agent. Head-MCU choice (ESP32-S3 vs RP2040 + Ethernet/WiFi) is the open sub-decision; propagated here once locked.

### 17.1 Pro UI [Pro only]

- Front-panel mezzanine owns its own subsystem: RP2040 UI MCU + BT817Q EVE + NHD-2.9 TFT + encoders + buttons + front LED column.
- Mezzanine ↔ main carrier link: UART + power only.
- RP2040 ↔ Zynq PS: UART for state sync.
- RP2040 ↔ BT817Q: SPI at ~30 MHz for graphics command-list streaming.
- UI framework: **BridgeTek EVE Asset Builder / EVE Screen Editor** + the FT8xx command set. No TouchGFX, no LVGL, no LTDC. Higher-level paradigm (display lists + co-processor commands) than the pixel-blit-and-DMA approach an STM32+LTDC path would require.
- UI alive in < 1 s from cold boot via RP2040; Linux takes 15–30 s to boot on Zynq PS behind the scenes with progress shown on TFT.

### 17.2 Mini UI [Mini only]

- 1.3" mono OLED + buttons + tri-color LED all wired directly to Zynq PS.
- PetaLinux user-space app `schindler-ui` handles event detection, menu state, preset save/recall (filesystem), and LED color/blink patterns.
- I²C via `/dev/i2c-N` for OLED; GPIO via `gpio-sysfs` interrupt handlers for buttons.
- **No dedicated UI MCU on Mini.** UI alive once PetaLinux user-space app starts (typically ~15–30 s post power-on; Mini accepts longer cold-boot vs Pro because the simpler UI doesn't need to be alive before the rest of the system).

Full menu hierarchy in [`ui-menu.md`](ui-menu.md).

---

## 18. Expansion header — design rule

- 2× 20-pin (or 1× 40-pin) 2.54 mm header on the carrier exposes unused TE0720 PL pins + 3.3 V / 5 V / GND rails + I²C bus tap + (optional) SPI bus tap.
- Preserves field-upgrade and prototype-extension paths for future add-on boards or experimental modules.
- ~$5 in connector + minimal PCB area. Insurance against early architectural lock-in.

---

## 19. Debug / dev interfaces

- 10-pin 2.54 mm JTAG header (Xilinx standard) for external JTAG cable access.
- 3- or 4-pin UART debug header for PetaLinux console fallback.
- Boot mode DIP switch or jumper block (QSPI / SD / JTAG boot selection).
- PS reset (POR) button.
- PL reset button (optional).
- Board-level status LEDs (power, PL_DONE, PS_BOOT, 2–4× user).

---

## 20. Cross-references

- **Active development arc:** [`dev-roadmap.md`](dev-roadmap.md)
- **SKU packaging details:** [`packaging-skus.md`](packaging-skus.md)
- **Bill of materials:** [`bom-v1.md`](bom-v1.md)
- **Signal flow diagrams:** [`signal-flow.md`](signal-flow.md)
- **Panel layouts (front + rear, both SKUs):** [`panel-layout.md`](panel-layout.md)
- **UI menu hierarchy (Pro):** [`ui-menu.md`](ui-menu.md)
- **MVPHD-24 comparison + gap analysis:** [`mvphd-comparison.md`](mvphd-comparison.md)
- **RF modulator subsystem detail:** [`rf-modulator-subsystem.md`](rf-modulator-subsystem.md)
- **Op-amp output stage design:** [`opamp-stage.md`](opamp-stage.md)
- **R-2R DAC bench reference:** [`r2r-dac.md`](r2r-dac.md)
- **Development narrative:** [`schindler-playbook.md`](schindler-playbook.md)

Decision history: [`01-spec-changelog.md`](01-spec-changelog.md).

---

## 21. Open questions / parked decisions

- **Mini WiFi chip:** LWB5+ (same as Pro, ~$30, dual-band a/c + BT5.0) vs ESP32-WROOM (~$5, 2.4 GHz only). Assembly-time stuffing decision. **Pending Justin's call.**
- **Mini PSU strategy:** internal LRS-50-12 + IEC inlet (matches Pro, same carrier wiring, ~$33 BOM) vs external 12V brick + DC barrel jack on carrier (cheaper, looser positioning, different rear-panel cutout). **Pending Justin's call.**
- **Mini S-Video output connector:** silicon-capable on the carrier (ADV7393 in composite mode). Add mini-DIN to Mini rear panel or omit. **Pending decision.**
- **S-Video input** to ADV7280 path: free in silicon, costs one mini-DIN + 2 traces. Common on retro source gear (VHS, S-VHS, Hi8). **Pending decision.**
- **SDI daughter card option (Pro):** the Pro SDI silicon is currently spec'd as factory-stuffed on Pro carriers. A daughter-card-on-headers approach was considered for field-upgrade of Mini → Pro SDI, but adds signal-integrity complexity (3G-SDI through mezzanine). Default: factory-stuff on Pro, no daughter card. **Confirm.**
- **Field-upgrade path Mini → Pro:** since Mini and Pro share the same carrier PCB with stuffing differences, a "Pro upgrade kit" (factory-installed silicon retrofit) is theoretically possible. Need to decide whether to support it as a product offering or treat the SKUs as one-way commitments at purchase. **Defer until Mini ships.**
- **VGA OUT [both SKUs]:** dedicated terminal encoder for driving VGA-input CRTs on camera at 24/30 fps film cadences. Architecture under consideration: ADV7125 triple 8-bit video DAC (~$6) + 74AHCT125 sync level shifter + HD-15 panel-mount + passives, ~$10/unit BOM addition each SKU. Frame-doubles source cadence to VGA-compatible refresh (24p → 48 Hz, 30p → 60 Hz) so VGA CRTs lock and camera shutter catches integer refresh cycles per camera frame. Requires new FPGA HDL block: HD bus tap → 1:2 frame doubler → VGA-rate pixel timing → RGB to DAC. Prototype path on Zybo via Pmod VGA (Digilent 410-345, on inbound) before committing carrier silicon. **Pending Justin's call to bank as confirmed feature.**

---

## 22. Out of scope (deliberately)

| Feature | Why not |
|---|---|
| NDI / SRT / RTMP input | Market wants deterministic frame-locked playback, not streaming. |
| ST 2110 | Wrong market. |
| HDR processing | HDMI 1.4 doesn't carry HDR metadata; CRTs and analog outputs can't display HDR; HDR pipeline DSP cost not justified. |
| Multiviewer | Single output by design. |
| Recording / capture | Downstream concern. |
| Logo / lower-third / CC overlay | Out of mission. |
| Touchscreen UI | Glare, smudges, no tactile, fails in production environments. Replaced by rotary encoders + dynamic TFT (Pro) or mono OLED + buttons (Mini). |
| DisplayPort IN | Dropped 2026-05-11 connector simplification. |
| VGA IN (HD-15) | Significant HDL complexity (auto-positioning + sample-phase recovery) for a declining input format. Out of scope for V1. |

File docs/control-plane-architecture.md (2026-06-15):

# Schindler 2.0 — Control-Plane Architecture

**Status:** Draft 2026-05-31
**Scope:** how operator-facing surfaces (web UI, front panel, future remote control) drive HDL state on the FPGA. Defines the protocol stack, schema, persistence model, and versioning.

> ## ⚠️ Direction update — 2026-06-13 (supersedes the PS-hosted-UI model below)
>
> **Committed:** the operator UI is **unified across ALL SKUs** and **hosted on a standalone off-SoM MCU** — not on the Zynq PS. One UI firmware drives **both** the front-panel TFT **and** the web UI, Mini and Pro alike. **Head = ESP32-S3 (locked 2026-06-13).**
>
> **Why:** the Mini can't host PetaLinux the way the Pro can, so a PS/PetaLinux-hosted UI (and a PS-served web app) can't be the universal solution. Rather than fork the UI (Pro = RP2040 panel + PS web; Mini = PS-direct OLED), all SKUs share one off-SoM UI head. This **kills the control-plane fork.**
>
> **What this changes vs. the model documented below:**
> - The **UI authority moves off the PS to the MCU** — catalog + profiles + panel rendering + web serving all live on the MCU.
> - **Control path = ESP32 ↔ UART ↔ PS thin agent ↔ AXI (FINALIZED 2026-06-13).** Both SKUs keep a TE0720, so both have a Zynq PS — the PS stays the register authority (`schindlerd`), as in the original plan. The ESP32 holds UI + catalog + profiles + web and sends operator-intent to the PS over the mezzanine UART; the PS writes the PL's AXI registers. On the **Pro** the agent runs under full PetaLinux (alongside the heavy pipeline + storage); on the **Mini** (a lighter-memory 0720 that won't host full PetaLinux) it runs as a thin/bare-metal agent — same UART contract. *(The earlier 'PS-independent FPGA-fabric AXI-Lite bridge' idea is dropped — it was insurance for a no-PS Mini we're not building. Staying on the 0720 makes the PS path simpler and reuses the original `schindlerd`.)*
> - The **catalog, JSON-RPC/COBS protocol, profile schema, and versioning rules below all still apply** — catalog + profiles + web server + panel UI run on the ESP32; it speaks the protocol to the PS agent over UART, and the PS writes the registers. The protocol shape is unchanged from the original doc.
> - The **web UI is served by the ESP32**, not a PS Node.js server.
> - **Front-panel interconnect (Pro):** the ESP32-S3 sits on the front-panel/mezzanine board with the BT817Q EVE, NHD-2.9 TFT, both EC11 encoders, buttons, and the LED column — all timing-sensitive UI I/O stays local (EVE↔TFT 24-bit parallel RGB never leaves the panel board; ESP32→EVE SPI is on-board; encoders/buttons on ESP32 GPIO). The mezzanine↔carrier link is a single **FFC** (~10-pin) carrying **power + GND + the ESP32↔PS UART (2) + the power-button line + the 2 ESP32 flash-control lines (EN, GPIO0/BOOT) for PS-driven recovery** (see *Firmware / update paths*). UART is cable-trivial, keeping the only fast signal (EVE SPI) on-board. The NHD-2.9's own FFC tail is the panel-board↔glass connection. **Mini:** same ESP32-S3 on the main board, driving the mono OLED directly (I²C) + buttons (GPIO) — identical firmware, EVE/TFT path disabled by SKU gating. WiFi: U.FL ESP32-S3 module → short coax → panel-mount antenna (keep off the front metal — layout item).
>
> **DECIDED 2026-06-13:** head = **ESP32-S3** (integrated WiFi; one chip drives the EVE + serves HTTP/WebSocket + reads encoders/buttons). Control transport = **ESP32 ↔ UART ↔ PS thin agent ↔ AXI** (PS is the register authority). **Mini = a lighter-memory TE0720** (has a PS, runs the thin agent; not full PetaLinux). The **Mini-silicon scope question is closed**: never below a 0720, so §0's one-carrier / same-SoM premise holds — no packaging rewrite for different silicon. **LWB5+ WiFi dropped** — the ESP32 provides WiFi (saves ~$30 + the SDIO routing).
>
> **Firmware / update paths (proposed 2026-06-13):**
> - **PS + FPGA bitstream + PS rootfs:** rear **USB-C → PS** (Zynq USB0, recovery / console / ethernet-gadget) + GbE/WiFi OTA + the §19 JTAG header; boot media = module QSPI/eMMC. The rear USB stays on the carrier/PS — the PS is what most needs a wired recovery path if the network is down.
> - **ESP32-S3 (UI/web/catalog/profiles):** primary = **OTA over its own WiFi** via the web UI it serves (add a firmware page). Recovery = **the PS reflashes it over the mezzanine UART** (ESP32 ROM serial bootloader), driving **EN + GPIO0(BOOT)** across the FFC — so the single rear USB-C is a whole-box recovery path and a bad ESP32 OTA isn't a brick. No dedicated ESP32 USB connector; its native USB → internal test pad only.
> - **Genlock RP2040 (U900):** rarely updated — add a small **SWD or BOOTSEL service header** near U900 (open-box service update), or a resident UART bootloader the PS can drive. Low frequency, not field-critical.
> - **Profiles / catalog data** (not firmware): on ESP32 flash, import/export via the web UI (§8).
>
> **Cascading / propagation (now unblocked):** GbE kept (Pro dev/OTA + Mini network). Into `refdes-map.md` Sheet 10/11 + A2 + BOM: drop the **LWB5+ (U1000)**; A2 mezzanine MCU → **ESP32-S3** (was RP2040); `J1100` FFC pin-count ~6 → ~10 (power + UART + PWR_BTN + EN + GPIO0); add the RP2040 service header. Spec §14/§15/§17 + `packaging-skus.md` get the rewrite to the ESP32-UI + PS-thin-agent model. Sheet 10/11 rework is now small.

## Why this doc exists

Today (bench): an ad-hoc UART command parser in `sw/phase-b/src/main.c` does direct AXI-GPIO writes. `s 100`, `m 50`, `b 0 0 0`, `w 255 255 255`, `a 8000` — one-char dispatch, no schema, no versioning, no introspection.

Production (per `docs/01-spec.md` §14 + `docs/ui-menu.md`): multiple concurrent operator surfaces (Pro front-panel TFT via RP2040 over UART, Mini OLED, Web UI on Linux), persistent JSON profiles, OTA updates, status logging, audit.

The gap: there is no documented schema or protocol library tying those surfaces to the HDL. This doc closes it.

## Three-tier stack

```
┌─────────────────────────┐    ┌─────────────────────────┐
│   Pro v2 front panel    │    │       Web UI            │
│   RP2040 ↔ EVE ↔ TFT   │    │   Browser ↔ Node.js     │
└────────────┬────────────┘    └────────────┬────────────┘
             │                                │
             │ Length-prefixed JSON          │ JSON-RPC over
             │ over UART + COBS framing      │ WebSocket
             │                                │
             └──────────────┬─────────────────┘
                            │
                  ┌─────────▼──────────┐
                  │  schindlerd        │  ← Single source of authority for
                  │  (Python daemon    │     all HDL state. No other process
                  │   on Zynq PS       │     touches the AXI registers.
                  │   PetaLinux)       │
                  └─────────┬──────────┘
                            │ mmap of UIO devices
                            │ ↓ direct register writes
                  ┌─────────▼──────────┐
                  │  AXI peripherals   │
                  │  (GPIOs, VDMA,     │
                  │   VTC, scaler,     │
                  │   color stack)     │
                  └────────────────────┘
```

- **`schindlerd`** is the only process that touches the FPGA. Everything else asks `schindlerd` over its protocol. Eliminates write-after-write races, makes audit logs trivial, makes UIs hot-swappable.
- **Web UI** is a Node.js (or Flask) HTTP+WebSocket server that exposes the daemon to a browser. Stateless toward the daemon.
- **RP2040 front-panel firmware** uses the same JSON catalog over UART. Different transport, same protocol shape.
- **Future remote control surfaces** (SDP-bridge, Companion module, OSC bridge, etc.) plug into the daemon's WebSocket exactly like the web UI.

## The control catalog

Every tunable in the system is declared in a single JSON document — the **control catalog**. The daemon, web UI, and RP2040 firmware all generate code from this catalog so they stay in sync.

### Catalog schema (JSON Schema definition)

```yaml
catalog:
  version: "0.2.0"   # semver; daemon advertises at handshake (current as of 2026-05-31)
  controls:
    - id: color.saturation                  # dot-namespaced key
      title: Saturation
      type: number                          # number | enum | bool | text | trigger
      unit: percent                          # display unit
      range: [0, 200]                       # for numbers
      default: 100
      persistent: true                       # included in profile snapshots
      hdl_address: 0x41200000               # AXI GPIO base
      hdl_encoding: q1_15                   # how the number maps to bits
      surface: [front, web]
      category: color
      tags: [bench, production]
    - id: color.matrix.preset
      title: Color matrix preset
      type: enum
      options:
        - { value: identity,  label: Identity (full color) }
        - { value: rec601_gray, label: Rec.601 grayscale }
        - { value: custom,    label: Custom (drag handles) }
      default: identity
      ...
    - id: scaler.kernel_h
      title: Scaler kernel — H
      type: enum
      options:
        - { value: nn,        label: Nearest neighbor (sharp, drops cols) }
        - { value: 2tap_box,  label: 2-tap boxcar (production) }
        - { value: 4tap_box,  label: 4-tap boxcar (softer) }
      default: 2tap_box
      requires_iter: 14                     # gated until iter14 ships
      ...
    - id: output.mode
      title: Output mode
      type: enum
      options:
        - { value: "720p60",  label: 720p60 }
        - { value: "1080p30", label: 1080p30 }
        - { value: "1080p60", label: 1080p60 (production carrier only) }
      default: "720p60"
      requires_hw: external_phy             # 1080p60 needs external HDMI chip
      ...
    - id: status.s2mm_sr                    # read-only telemetry
      title: S2MM status register
      type: number
      read_only: true
      poll_interval_ms: 100
      hdl_address: 0x40000000
      ...
```

### Required fields per control

- `id`, `title`, `type`, `default`, `persistent`, `surface`, `category`
- `range` / `options` per type
- `hdl_address`, `hdl_encoding` — daemon-only; not exposed to UI clients
- `requires_iter` / `requires_hw` / `requires_sku` — gating attributes that prevent broken controls from appearing on builds that can't honor them

### Versioning rules

- `version` follows semver
- **Patch** bump: bug fix in an existing control (e.g., range correction)
- **Minor** bump: new control added, OR existing control gains an `options` value, OR `default` changes
- **Major** bump: control removed, `id` changed, `type` changed, `options` value removed

Daemon advertises its catalog version at handshake; clients check compat. Web UI / RP2040 firmware reject majors they don't understand; tolerate minor mismatches.

## Daemon ↔ Web UI protocol (WebSocket + JSON-RPC 2.0)

```jsonc
// → from client to daemon
{ "jsonrpc": "2.0", "id": 7, "method": "control.set",
  "params": { "id": "color.saturation", "value": 110 } }

// ← response
{ "jsonrpc": "2.0", "id": 7, "result": { "value": 110, "applied_at": "2026-05-31T12:34:56.789Z" } }

// ← push (server-initiated, no id)
{ "jsonrpc": "2.0", "method": "status.update",
  "params": { "id": "status.s2mm_sr", "value": 0x11100 } }
```

### Methods

- `catalog.get(version?)` — fetch full catalog (optional version filter)
- `control.get(id)` / `control.set(id, value)` — single control
- `control.batch_set([{id, value}, ...])` — atomic group (one profile recall)
- `profile.list()` / `profile.save(name)` / `profile.load(name)` / `profile.delete(name)`
- `system.identify()` — model, serial, firmware version, catalog version
- `subscribe(ids[])` — opt into push for those control IDs

### Push channel

Telemetry (`status.*` controls) and async events (alarms, source-change notifications) come over the same WebSocket as pushes. UI clients subscribe to whatever they need; status bar subscribes to source/sync/profile; deep diagnostics page subscribes to telemetry.

## Daemon ↔ RP2040 (front panel) protocol

Same JSON message shape. Different transport:

- UART at 921600 8N1 (or higher; up to PS UART capability)
- **COBS** framing (Consistent Overhead Byte Stuffing) — zero byte = packet boundary; no escape sequences in payload
- Each frame: 1-byte type + 1-byte seq + 2-byte length-LE + JSON-or-binary payload + 0x00 terminator
- Types: `0x01` request, `0x02` response, `0x03` status-push, `0x04` log

The RP2040 only needs to handle the subset of controls that map to the front-panel UI hierarchy. The catalog's `surface` attribute filters: only entries with `front` or both surfaces. The same JSON schema validates on both sides.

## Daemon ↔ HDL (UIO + memory-mapped AXI)

PetaLinux exposes each AXI peripheral as a UIO device (`/dev/uio0`, `/dev/uio1`, ...) when the device tree is configured. The daemon mmaps each one and writes/reads registers directly. No kernel-mode driver needed for the slow control path; UIO is sufficient.

For the high-bandwidth telemetry (DDR3 frame buffer dumps, ILA streaming if added later), separate fast-path mechanisms apply — out of scope for v0.

## Profile format

JSON file, catalog-version-stamped, signed checksum:

```jsonc
{
  "schema": "schindler-profile",
  "schema_version": "0.1.0",         // profile-format schema (separate semver)
  "catalog_version": "0.2.0",       // catalog this profile was authored against
  "name": "BVM-D24",
  "created_at": "2026-05-31T08:00:00Z",
  "controls": {
    "color.saturation": 100,
    "color.matrix.preset": "rec601_gray",
    "output.mode": "720p60",
    ...
  },
  "checksum": "sha256:abc...def"
}
```

On load: validate against current catalog. Missing keys → use current default + warn. Extra keys (forward compat from a newer profile) → ignore + warn. Range violations → reject with operator-actionable error.

Profiles live in `/var/lib/schindler/profiles/<name>.json`. Importable via web UI drag-drop; exportable to USB via front panel.

## Persistence: where state lives

| Layer | What persists | Storage |
|---|---|---|
| Catalog | Read-only build artifact | `/opt/schindler/catalog.json` (shipped with firmware) |
| Active profile | Current `control.set` state | RAM-only by default; written to flash via explicit "Save" |
| Profile library | All named profiles | `/var/lib/schindler/profiles/` on eMMC |
| Telemetry / logs | Rolling history | `/var/log/schindler/` on eMMC, rotated |
| Hardware identity | Model, serial, calibration | `/etc/schindler/identity.json` (provisioned at factory) |

Default-on-boot behavior: load profile named in `/etc/schindler/default_profile` if present; otherwise apply catalog defaults.

## Audit + logging

Every `control.set` (and every `profile.load`) emits a structured log line:

```jsonc
{ "ts": "2026-05-31T12:34:56.789Z", "actor": "web:192.168.1.50",
  "method": "control.set", "id": "color.saturation",
  "old": 100, "new": 110 }
```

Audit lives in the same `/var/log/schindler/` directory; tail-able over SSH; rotated weekly.

## V0 minimum-viable build

The protocol can be developed and tested on the **current Zybo dev environment** before PetaLinux exists. Phased rollout:

### V0a — host-side bridge daemon (no PetaLinux required)

- Python `schindlerd` runs on the dev host (the laptop driving xsct)
- Talks UART over `/dev/ttyUSB1` to the existing bare-metal firmware
- Firmware adds a minimal JSON-RPC-over-UART command (one new `J` UART command that brackets a JSON payload)
- Catalog v0.2.0 covers current bench controls: `color.saturation`, `color.matrix.preset`, `color.correct.black_r/g/b`, `color.correct.white_r/g/b`, `scaler.kernel_h/_v`, plus status fields. (`frc.mackin_alpha` is declared but gated `requires_branch: mackin-impl-wip`.)
- Web UI is a single-page React/Vue app served by the daemon at `http://localhost:8080`
- Profiles persist on host filesystem
- Audit log lines to stdout / journald

**What this gives:** real protocol exercised end-to-end. UI engineers can build screens. Operators can save/load profiles. Logging works. No FPGA changes beyond the new UART command.

### V0b — PetaLinux on Zybo (intermediate)

- Boot PetaLinux on the Zybo PS (Cortex-A9 already idle alongside bare-metal in current config)
- Move `schindlerd` from host to Zybo PS user space
- Same protocol, same web UI; just hosted on the FPGA instead of the laptop
- Network reachable at `http://schindler-bench.local`
- Validates everything the production path needs except the front-panel MCU

### V0c — RP2040 front panel (Pro SKU dev)

- Build RP2040 firmware that speaks the protocol over UART to Zybo PS
- Add EVE BT817Q driver
- Build front-panel hierarchy from the catalog
- Cross-check that web + front-panel both render the same control set and stay in sync

## What's holding up V0a — *nothing serious*

V0a can be built **today** with what's in tree. Specifically:

| Need | Status | Effort |
|---|---|---|
| Firmware `J` UART command for JSON-RPC | not built | ~2 hours — extend existing `uart_poll_and_dispatch` |
| Catalog file (v0.2.0) covering current bench controls | ✅ shipped 2026-05-31 | `control-plane/catalog-v0.2.0.json` |
| Python `schindlerd` skeleton | not built | ~4 hours — UART transport + JSON-RPC dispatcher + WebSocket relay |
| Web UI scaffold (React/Vue) | not built | ~1 day for a minimal control panel (sliders, dropdowns, profile picker) |
| Profile save/load infra | not built | ~2 hours — JSON file read/write + validate against catalog |

**Total V0a effort: ~2-3 days of focused work.** Most of it parallelizable with current bench work.

## What's holding up V0b

- **PetaLinux build infrastructure not set up.** ~1 day to add `tcl/build_petalinux.tcl` (or move to Yocto, depending on Justin's preference). Requires Xilinx Vitis Linux tooling stack, which is in the same install as Vivado/Vitis already on disk.
- **Device tree changes** to expose AXI GPIOs / VDMA / VTC as UIO devices. ~1 hour.
- **Network bring-up** on Zybo. Memory `zybo_z7_clk125_phy` documents the 125 MHz refclk for the Ethernet PHY — should already work in PetaLinux's reference BSP.

V0b is realistic ~1 week effort once V0a is working.

## What's holding up V0c (front-panel RP2040)

- **Hardware:** Pro v2 mezzanine PCB doesn't exist. RP2040 + BT817Q + NHD-2.9 TFT need to be on a carrier. ~3-4 weeks PCB design + fab + assembly.
- **Firmware:** no RP2040 code in tree at all.

V0c is a separate hardware track. Not a v0 prerequisite for V0a/V0b control plane work.

## Open design questions for early review

1. **JSON-RPC 2.0 vs custom envelope?** JSON-RPC is standard and well-tooled. The only friction is that it's optimized for request-response — for status push we'd use the no-id variant ("notification"). Acceptable.

2. **Catalog hot-reload?** If the daemon re-reads `catalog.json` while running, clients need a notification to re-sync. Recommend: catalog is fixed at daemon start; firmware updates restart the daemon. Simpler.

3. **Auth model?** Web UI on a LAN: nobody assumes you have it. Add basic auth + TLS via reverse proxy when shipping. RP2040 over UART: physical access = trust. Not for v0.

4. **Audit retention.** Default: 30 days of rotated logs, ~50 MB cap. Operator-actionable knob in catalog?

5. **Profile vs preset distinction.** Per `01-spec.md` §278, profiles are NovaTool-pattern. Spec doesn't clarify whether "factory preset" is a separate concept from "user profile" — recommend: presets are profiles shipped as read-only in firmware.

6. **HDL discoverability.** Should the daemon read AXI ID registers from each peripheral at boot and validate they match the catalog? Catches firmware/HDL version skew at startup instead of at first wrong write.

## Related docs

- `docs/01-spec.md` §14 (Networking + control plane), §278 (Profiles)
- `docs/ui-menu.md` (operator-facing UI hierarchy)
- `docs/packaging-skus.md` (Mini vs Pro SKU differences)
- `docs/wiki/COLOR-PIPELINE.md` (current bench controls + AXI GPIO map)
- `docs/wiki/FIRMWARE-INTERFACE.md` (current UART command parser)

## Recommended next steps

1. **Author catalog v0.1.0** from current bench controls — ✅ shipped 2026-05-31, bumped to v0.2.0 same day with two new DIAG-derived status fields.
2. **Build V0a** — the host-side Python daemon + minimal web UI + JSON-over-UART firmware bridge. ~2-3 days.
3. **Bench-verify** parity between web UI and current UART commands.
4. **Iterate catalog** as iter14 + Phase E2 land — every new control = one catalog entry.
5. **Boot PetaLinux** on Zybo PS (V0b transition) when convenient — moves the same daemon to the target hardware.
6. **Pro v2 mezzanine PCB** when ready — V0c becomes feasible.

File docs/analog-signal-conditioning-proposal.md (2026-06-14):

# Schindler 2.0 Carrier — Analog Signal-Path Conditioning (PROPOSE-AND-RATIFY)

**Status:** PROPOSAL 2026-06-13d — values + topology for sign-off. **Nothing wired yet**; on ratification the agent wires per-sheet (component values from the ✅/🧮/🔧 columns), PL data buses stay flagged for the placement pass.
**Confidence flags:** ✅ standard video practice / datasheet typical-app · 🧮 computed/datasheet-constant — verify the eqn/constant · 🔧 starting value — bench-tune · ❓ genuine design decision — your call.
**Sources:** `refdes-map.md`, `signal-flow.md`, ADI/TI/Semtech reference designs + datasheets in `KiCad/Reference Files/`. Carrier video impedance = **75 Ω** throughout. Op-amp buffers (LMH6643) single **+5 V**, AC-coupled at the BNC.

> Ratify per row (or edit values), and the agent wires it. Anything left ❓ stays flagged in the schematic until you call it.

---

## 1. Sheet 5 — Analog video IN (ADV7280, J500 CVBS + J501–503 component)

Each BNC input → **fixed 75 Ω term** (end-of-line) → AC-couple → anti-alias → IC-side clamp → ADV7280 AINx. Front bidirectional low-cap TVS at the BNC = primary ESD. *(Wired 2026-06-13e.)*

| Block | Proposed | Flag |
|---|---|---|
| 75 Ω termination | **Fixed** 75 Ω 1% to GND at each BNC (analog video inputs are end-of-line — no loop-through). **U501 TS5A23159 term-switch dropped** (2026-06-13e). The switchable-term I²C GPIO expander (§7-3) now serves only the loop-capable input — REF (Sheet 8); SDI is internally terminated by the GS3470, so it needs no external switch either. | ✅ fixed term (§7-3 sanctions fixed for end-of-line inputs) |
| Input clamp | **2-rail** BAV99 (D5xx): signal at the series midpoint, **cathode → ADV7280 AVDD (1.8 V, `AVDD_DEC`)**, anode → GND. Clamp to **AVDD, not +3V3** — the AINx pins are AVDD-referenced, so a +3V3 clamp wouldn't protect them. Front bidirectional low-cap TVS is the primary connector ESD; this is the IC-side backstop. *(Or omit the IC-side BAV99 and lean on the TVS + ADV7280 internal ESD — also defensible.)* **NOTE 2026-06-13e:** agent wired it GND-side-only — fix to 2-rail-to-AVDD (or drop). | 🔧 confirm AINx abs-max vs the AVDD clamp |
| AC-couple | series **0.1 µF** + ADV7280 internal bias (ADV7280 AC-couples on-chip; ref design uses 0.1 µF series + 0.1 µF to GND) | 🧮 confirm vs ADV7280 ref design |
| Anti-alias LPF | 1st-order RC, fc ≈ 9–10 MHz (SD): series **75 Ω** + shunt **220 pF** (≈9.6 MHz) | 🔧 bench-tune corner |
| ADV7280 supplies | DVDDIO→+3V3, **DVDD→`+1V8_D`** (digital, re-homed 2026-06-13e — was +1V8_A), AVDD/PVDD→`AVDD_DEC` (U308, 1.8 V analog); 28.636 MHz xtal **Y500**; 0.1 µF/pin decoupling | ✅ |
| I²C | SDATA/SCLK → `I2C_VID`; ALSB strap → addr 0x20 (GND) | ✅ |

Refdes: R5xx (term 75 Ω ×4, anti-alias 75 Ω ×4), C5xx (AC-couple 0.1 µF, anti-alias 220 pF, decoupling), D500–D503 (front bidirectional TVS + IC-side BAV99 ×4), **Y500** (28.636 MHz xtal). **TVS-vs-BAV99 split RESOLVED (§7-4):** front low-cap bidirectional TVS (primary ESD) + IC-side BAV99 2-rail clamp. U501 dropped (fixed term).

---

## 2. Sheet 6 — Analog video OUT (ADV7393 + LMH6643, J600 CVBS + J601–603 component)

Per ADI ADV7393 ref design (NOT the opamp-stage.md R-2R divider). Triple current-output DAC → buffer → 75 Ω back-term → BNC.

| Block | Proposed | Flag |
|---|---|---|
| DAC load | ADV7393 DAC1/2/3 → **300 Ω to GND** (low-drive RL). Datasheet-confirmed pairing with RSET = 4.12 kΩ → ~4.3 mA × 300 Ω ≈ 1.3 V full-scale (≈ 1.0 Vpp active video) at the **buffer input**. **NOT 37.5 Ω** — that's the *full-drive* RL (pairs with RSET = 510 Ω) for direct doubly-terminated line drive with **no** buffer. | ✅ datasheet Rev. K Table 4 (corrected 2026-06-13e — was 37.5 Ω, ~8× low) |
| RSET | **RSET → 4.12 kΩ to GND = low-drive mode** (~4.3 mA FS). Correct for the buffered chain (DAC → 300 Ω → ×2 buffer → 75 Ω back-term → line). Set the ADV7393 **drive-mode register (subaddr 0x0D) to low-drive** to match the hardware (note: the chip's low-power auto-shutdown isn't available in low-drive — fine for a mains box). VOC compliance = 1.4 V; 1.3 V FS is within. | ✅ datasheet |
| Buffer | LMH6643 (U601 ch A/B, U602 ch A) — non-inverting ×2 or unity per level plan; +5 V single, AC-coupled | ❓ gain (×2 doubly-term vs unity) — your call |
| Back-term | **75 Ω series** at each buffer output → BNC | ✅ |
| AC-couple at BNC | **220 µF** (or DC-couple w/ bias) — SD video LF response needs large cap | 🔧 cap vs DC-couple decision ❓ |
| ADV7393 supplies | VDD_IO→+3V3, VDD/PVDD→+1V8_A, VAA→+3V3_A; CLKIN from clock-gen | ✅ |
| Composite tap → RF | CVBS buffer output also feeds the u.FL (J1200, Sheet 12) per refdes-map | ✅ |

> CVBS buffer output is shared to the RF daughter-board u.FL (Sheet 12) — single buffer drives both BNC + u.FL tap (confirm fan-out/level).

---

## 3. Sheet 8 — Genlock REF front-end (LTC6912 PGA + AD9204) — *structurally wired §11; values here*

| Block | Proposed | Flag |
|---|---|---|
| 75 Ω term | R800 = 75 Ω, switchable via U802 TS5A23159 (one SPDT section) on the term-resistor **ground leg**, IN1 driven by the PCA9555 expander. **U802 pinout — confirm vs TI datasheet (symbol pins unnamed):** wire **one switch** — IN1 (control), COM1, NO1, NC1 (TI numbering: IN1=1, NC1=2, COM1=3, NO1=4, GND=5; switch 2 = NO2/COM2/NC2/IN2 = 6–9, V+=10). **Do NOT mix switches** — the wired COM=2 / NO=9 / IN=1 is wrong: pin 9 = IN2 (the *other* switch's control), not a signal pin. | 🔧 name symbol pins from datasheet before lock |
| Clamp | D800 **BAV99S 2-rail** at the PGA input: cathode → +5V (PGA supply), anode → GND (PGA input is +5V-referenced) + <3 pF TVS at both REF BNCs (primary ESD) | ✅ (wired 2026-06-13e) |
| AC-couple | C800 = **0.1 µF** into PGA INA | 🔧 |
| Anti-alias LPF | before ADC: fc ≈ 8 MHz (AD9204 @ 20 MSPS, genlock BW ≪) — series R + shunt C | 🔧 |
| PGA→ADC | LTC6912 OUT_A → AD9204 VIN+A; VIN-A → VCM; **confirm PGA output swing fits AD9204 FS (2 Vpp) after AC-couple** | 🧮 ❓ |
| ADC ref | VREF bypass 470 nF X5R (set §13), SENSE→GND internal ref, RBIAS per datasheet | 🧮 |

---

## 4. Sheet 9 — SYNC OUT (AD9742 12-bit DAC → LMH6643 → BNC J900/J901)

| Block | Wired 2026-06-13e (verified) | Flag |
|---|---|---|
| FS_ADJ | **R900 = 3.83 kΩ** (E96) on FS_ADJ → IOUTFS ≈ 10 mA. Datasheet-verified: IOUTFS = 32 × IREF, IREF = VREFIO/RSET, VREFIO = 1.2 V (internal bandgap) → 32 × 1.2 / 3830 ≈ 10.0 mA; range 2–20 mA, 10 mA mid-range (headroom). | ✅ datasheet (Rev. C) |
| DAC I-V | **IOUTA → 100 Ω to GND** → 1.0 V swing (10 mA × 100 Ω); IOUTB → matched 100 Ω (balance). Single-ended IOUTA into the buffer (sync gen is baseband — no diff-amp needed). Within AD9742 output compliance (≈ −1.0 to +1.25 V). | ✅ single-ended endorsed |
| Buffer | LMH6643 ×2 (Rf=Rg=1k): 1.0 V → 2.0 Vpp → 75 Ω back-term + 75 Ω line ÷2 → **1.0 Vpp black-burst at the load**. Tri-level ±300 mV = 600 mVpp = 60% FS via codes. | ✅ |
| SYNC2 (LTC) | 1-bit FPGA biphase (B33, 1.8 V) → slew RC → LMH6643 ch B → 75 Ω → 220 µF → J901. **Slew RC CORRECTED:** target **~40 µs** edge per **SMPTE 12M** (spec ≈ 25–50 µs), not 2.2 µs — the wired R906=1k + C902=1nF (τ≈1µs, ~2.2µs edge) is ~20× too fast. Bump to **τ≈18µs** (e.g., 1k + ~18nF) for a compliant ~40µs 10–90% edge; buffer gain to ~1 Vpp LTC. | 🔧 bench-tune ~40 µs (was 2.2 µs) |
| AC-couple | 220 µF at BNC (per §7-1) | ✅ |

---

## 5. Sheet 4 — HDMI (J400 IN / J401 OUT, TPD12S016 + LT8619C / ADV7511)

| Block | Proposed | Flag |
|---|---|---|
| TMDS RX term | LT8619C **internal 50 Ω to VTERM** (VTERM = 3.3 V) — no external term | ✅ datasheet |
| TMDS TX | ADV7511 drives TMDS directly to J401; series 0 Ω/AC-couple per ADV7511 ref | 🧮 |
| ESD | TPD12S016 on TMDS + DDC + HPD (U400/U401) — pass-through, no values | ✅ |
| HDMI +5V | **CORRECTED 2026-06-13e — was backwards.** HDMI convention: the **source** drives +5V (pin 18), the **sink** receives it. So **OUT (J401, we're the source): carrier sources +5V to the downstream sink via TPD `5V_OUT`** (U401.5V_OUT → J401 pin 18). **IN (J400, we're the sink): +5V is an INPUT from the upstream source** — sense it for cable-detect into the LT8619C; do **not** drive it. **TPD12S016 is a source-side companion** (its 5V_OUT *sources* 5V) — correct on the OUTPUT (U401), **wrong on the INPUT** (U400 would back-drive the source's own 5V). The input needs a sink-side approach: a low-cap HDMI ESD array + LT8619C-native DDC/HPD/EDID referenced to the source's 5V (or a sink companion, e.g. TPD12S521-class). **Check the LT8619C input reference design.** | ⚠ Sheet 4 input-protection part needs rework |
| I²C | DDC (LT8619C DSDA/DSCL, ADV7511 DDCSDA/SCL) → HDMI connector DDC pins; config (CSDA/CSCL, SDA/SCL) → `I2C_VID`. **Pull-ups: 2.2 kΩ to +3V3** on each I²C/DDC | ✅ / 🔧 pull value |
| HPD | LT8619C RX_HPD, ADV7511 HPD → via TPD level-shift | ✅ |

---

## 6. Sheet 7 — SDI (GS3470 RX / GS2962 TX, J700/702 IN+loop, J701/703 OUT+mirror)

> **PARALLEL-WIDTH FLAG — RESOLVED 2026-06-13e (datasheet-confirmed):** the GS2962 (and GS2972 sister) **support 10-bit DDR @ 148.5 MHz for 3G** — datasheet: *“in 3G 10-bit mode the device operates in DDR mode… data sampled on both rising and falling edges of PCLK… reduces the I/O speed requirements of downstream devices.”* So strap **20BIT/10BIT = 10-bit (LOW)** and our **B34 11-pin/chip allocation HOLDS — no rework** (B34=1.8 V, AD9742→B35, pin budget all stand). Data Stream 2 on PCLK rising edge, Stream 1 on falling; H/V/F pulses optional (chip can insert TRS), so 10 data + PCLK = 11 pins suffices. FPGA: ODDR on the GS2962 TX bus, IDDR on the GS3470 RX bus (confirm GS3470 RX mirrors 10-bit DDR — same family, near-certain). The Fig 5-1 reference drew the 20-bit option; we use 10-bit DDR.

| Block | Proposed | Flag |
|---|---|---|
| SDI RX in | J700 → **AC-couple 4.7 µF** → GS3470 (internal adaptive EQ + 75 Ω term) | ✅ (4.7 µF standard SDI couple) |
| SDI ESD | **3G-SDI is in spec** → use **<0.3 pF** SDI ESD (e.g. 0.2–0.3 pF) on **all SDI BNCs** (GS3470 inputs + TX outputs J701/J703) — swap off the 0.5 pF TPD1E05U06 for return-loss margin at 2.97 Gbps. | 🔧 select <0.3 pF 3G part |
| SDI loop (J702) — U702 LMH0302 | **DECIDED (Justin): loop-out + cable driver.** GS3470 DDO (differential) → U702 **SDI/SDI̅** (100 Ω diff, self-biased → AC-couple OK) → **SDO** → 4.7 µF AC-couple → **J702** (SDO̅ terminated into 75 Ω). **LMH0302-specific wiring (≠ GS2962 — verify pinout vs TI datasheet, 16-WQFN, exposed pad→GND):** **RREF = 750 Ω to VCC** (the *only* allowed value; close to pin, clear copper below — NOT the GS2962's 75 Ω/CD_VDD); **SD/HD = LOW** for 3G (ST 424/292 slew — HIGH = 259M/SD, wrong for 3G; recheck the "~SD from +3V3" wiring); **ENABLE = HIGH** to enable (or GPIO); VCC = +3V3_SDIDRV. Use the LMH0302's own output network (RREF + AC-couple per SD302 eval), not the GS2962 5.6/75/10 nF net. No FPGA-pin impact. | 🔧 RREF 750→VCC, SD/HD=LOW(3G), ENABLE=HIGH; verify pinout |
| SDI TX out (J701 + J703) | GS2962 drives **two BNCs** per Fig 5-1: **SDO (C10) → J701**, **SDŌ (~D10) → J703**, identical per leg. **Return-loss network (corrected topology, Justin from datasheet):** output node → **5.6 nH ∥ 75 Ω** (inductor *parallel* resistor — note **nH, not Ω**) → **4.6 µF** AC-couple (≈ 4.7 µF std) → BNC; **and** output node → **75 Ω → CD_VDD** with **10 nF** CD_VDD→GND_A bypass. Both legs share a **common CD_VDD**; **BNC shells → GND_A**. SDI polarity-insensitive (NRZI+scrambling) → SDŌ is a valid mirror; no fanout driver. Both BNC traces 75 Ω controlled-impedance, 3G-rated. | ✅ datasheet topology |
| Cable driver supply | GS2962 CD_VDD → `+3V3_SDIDRV` (FB303 branch, set §2.8) | ✅ |
| 27 MHz ref | **RESOLVED (GS3470 datasheet):** 27 MHz **crystal** on XTAL/XTAL pins — spec **≤±100 ppm** freq variation, **≤50 Ω ESR**. Y700 = 9 pF-CL + 8 pF loads (self-consistent w/ ~5 pF stray) ✅. Crystal is used only for **frequency acquisition — no impact on output jitter once locked to incoming data**, so a standard crystal is fine (no low-jitter premium). Alt: 27 MHz external clock into XTAL, **DC-coupled, ≤1.2 V**. Only the GS3470 RX needs it; GS2962 TX is FPGA-parallel-clocked. | ✅ ±100 ppm / ≤50 Ω ESR |
| Supplies | **GS2962 (per Fig 5-1):** CORE→+1V2; **analog rails ferrite-bead-isolated** — **+1V2_A** (ferrite off +1V2) + **+3V3_A** (ferrite off +3V3), each 10 nF+1 µF+1 µF decoupled to a separate **GND_A** analog ground, placed close to the chip; **IO_VDD→+1V8** (B34); **CD_VDD→`+3V3_SDIDRV`**. Use **ferrite isolation + GND_A partition** (not the earlier 10 Ω RC). **GS3470 (datasheet Rev. 9):** CORE→+1V2 digital; **analog = 1.2 V + 1.8 V** (both); **I/O = 1.8 V** (selectable 1.8/2.5, *not* 1.2 — confirms B34 = 1.8 V). **DDI/DDO rails (datasheet-confirmed):** DDI (equalizer) → filtered **+1V2_A** (eq output stage = 1.2 V); **DDO_VDD (serial-output 50 Ω buffer) → 1.2 V *or* 1.8 V analog**, so the agent's filtered +1V8 (FB700) is **valid**. | ✅ DDI→+1V2_A, DDO 1.2/1.8 OK; add +1V2_A/+3V3_A + GND_A |

---

## 7. RATIFIED 2026-06-13e (Justin) — wire to these

1. **AC-couple** the analog/sync outputs (sheets 6 + 9). 220 µF series at the BNC; CRT/PVM clamp restores DC (consistent with `opamp-stage.md` intent). 470 µF acceptable for extra APL margin. Not DC-couple — that's the deferred DC-accurate variant only.
2. **×2 gain, doubly-terminated** (buffer 2.0 Vpp source → 75 Ω back-term + 75 Ω load → 1.0 Vpp). Set the ADV7393/AD9742 full-scale so the **load** lands standard levels (1.0 Vpp composite / 700 mV component). Re-check the "1.4 Vpp" 🧮 against the ADV7393 datasheet under this gain.
3. **Per-input switchable term, driven from an I²C GPIO expander on `I2C_HK`** (not dedicated MCU pins — kills the pin-count concern). The loop-through inputs (REF, SDI) *require* it; composite/component inputs may be fixed 75 Ω (end-of-line) if you'd rather save switches. Switch sits on the term-resistor **ground leg** → SI-clean (not in the signal path).
4. **Low-cap (<3 pF) video TVS at every external panel BNC + BAV99 as the IC-side rail clamp.** **SDI is the exception** — GS3470 inputs need an **ultra-low-cap (<0.5 pF) SDI ESD** device, **not** BAV99 (1.5 pF is too much at 3G). No standard high-cap TVS on any video line.
5. **SDI rails (datasheet-confirmed):** **GS2962** (TX) — 1.2 V core, **PLL/VCO = 1.2 V analog (RC-filtered)**, **sensitive AVDD = 3.3 V analog**, I/O = 1.8 V (per the B34 re-strap), cable driver on `+3V3_SDIDRV`. **GS3470** (RX) — 1.2 V core, **1.2 V + 1.8 V analog (RC/ferrite-filtered)**, I/O = 1.8 V, **needs an external 27 MHz reference clock** (feed from clock-gen). Derive the analog sub-rails off `+1V2` / `+1V8` via dedicated RC/ferrite filters (like the ADC POLs).

**B34 follow-on (Option A, ratified same day):** B34 → 1.8 V LVCMOS18 for GS3470 + GS2962 (both 1.8 V I/O); **AD9742 SYNC-1 DAC relocated B34 → B35** (3.3 V; the AD9742 is a 2.7–3.6 V part). Folded into `sheet3-te0720-som-backbone.md`, `pin-budget.md`, `power-tree-design.md`, `refdes-map.md`, changelog.

> Wiring notes for the agent: (a) the digital-1.8 V pins (ADV7280 DVDD, ADV7393 VDD, LT8619C VDD18) belong on **`+1V8_D`** (digital), not the precision analog `+1V8_A` — re-home in the power-budget pass. (b) New parts to add at wiring: per-input I²C GPIO expander (TERM_EN) on `I2C_HK`; low-cap video TVS at the BNCs; ultra-low-cap SDI ESD at the GS3470 inputs; BAV99 IC-side clamps. Reconcile these into `bom-v1.md` as they're placed.

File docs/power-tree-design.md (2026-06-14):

# Schindler 2.0 Carrier — Power-Tree Design (Sheet 3)

**Status:** Decisions locked 2026-06-13; corrections 2026-06-13b (datasheet verify pass, see §0a) — Justin delegated the open calls ("this carrier board is your brain child"); the ❓ items are now Claude's committed calls (see §0), each flagged so any can be overridden at wiring time. Topology + netlist unchanged; 🧮/🔧 values keep their verify-before-fab flags. Derived from `01-spec.md` §1.3 + `bom-v1.md` §3 + `refdes-map.md` (300s block). Resolves capture-log gap #1 (no pin-level netlist / no passive values) and gap #6 (3 under-specified connections).
**How to read the confidence flags:** ✅ deterministic (datasheet typical-app or spec) · 🧮 computed, equation shown — **verify the datasheet constant** · 🔧 starting value, **bench-tune** · ❓ genuine design decision — **Justin's call**.
**Scope:** Sheet 3 only. TE0720 core rails (Vccint 1.0 V / 1.8 V / DDR3L 1.35 V) are made **on-module** from 5 V VIN — not on the carrier.

---

## 0. Decisions locked (2026-06-13, Claude's calls under delegation)

- **eFuse enable / UVLO (was gap #6a) — RESOLVED.** The placed TPS2660x symbol exposes **separate `SHDN`, `UVLO`, `OVP` pins** — no coexistence conflict. **LTC2954 `EN` → TPS26601 `SHDN`** (soft-power gate); **`UVLO`** divider from `+12V_RAW`; **`OVP`** divider from `+12V_RAW`. ⚠ At wiring, verify `SHDN` polarity (active-low shutdown) vs the LTC2954 `EN` sense — add an inverter only if they oppose.
- **eFuse `MODE` — latch-off; part = TPS26601 (DECIDED 2026-06-13b, see §0a-1).** The '601's `MODE`-open default *is* circuit-breaker-with-latch, so **`MODE` is left open — no strap**. (Swapped from the '600, whose open default is auto-retry; identical pinout, symbol reused.) Pairs correctly with LTC2954 → `SHDN` reset (button cycle clears a latched fault).
- **INA226 (was gap #6b) — RESOLVED.** Shunt **R300 in `+12V_PROT`** (load current; bus ≈ PSU); **VS from `+3V3`**; address **0x40** (A0/A1→GND); **I²C master = Zynq PS** on `I2C_HK_SDA/SCL`.
- **ADP7142 POLs.** U307 → AD9204 clean AVDD (**1.8 V**) · U308 → ADV7280 analog (**1.8 V**) · U309 → **`+3V3_A`** (ADV7393 VAA, **3.3 V** — *ADV7511 analog removed, it's 1.8 V; see §0a-4*). `+3V3_A` is a **dedicated LDO (U309), not a bare ferrite tap** — cleaner for the DAC analog. POLs may relocate to their load sheets during wiring (**set each ADJ divider there, against the device datasheet**).
- **L302 added.** The 1.2 V buck needs its own inductor → L-block becomes L300 / L301 / **L302** (extends the refdes-map allocation).
- **TPS2660x symbol — DONE.** OUT pins retyped in JustinLibrary 2026-06-13: pin 15 `OUT` → `power_out`, pin 16 `OUT-1` → `passive` (kills the false pin-to-pin error, gives `+12V_PROT` a driver). *(Symbol reused for the TPS26601 — identical pinout; set value/MPN to '601.)*
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

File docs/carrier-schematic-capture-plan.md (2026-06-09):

# Carrier Schematic — Component Capture Plan

**Status:** TO-DO / build-ready · created 2026-06-09
**Purpose:** Block-by-block checklist for capturing carrier silicon into `KiCad/SchindlerSchematic_V1.kicad_sch`. Banked from the 2026-06-09 BOM-vs-schematic audit. Work top-to-bottom; check off per block.
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

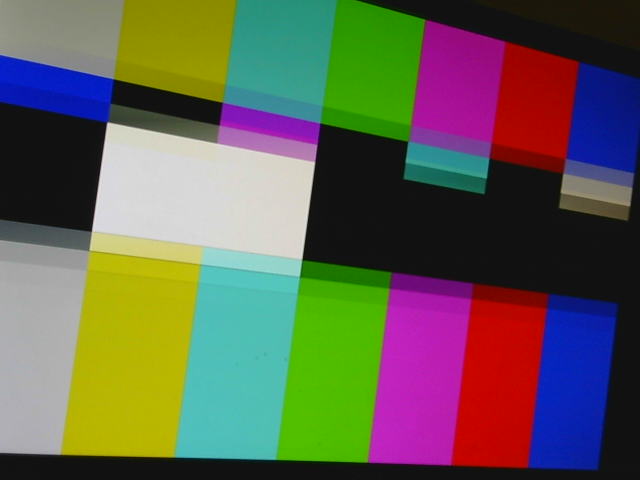
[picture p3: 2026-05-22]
Images/2026-05-21_iter4h_t3.0s.jpg

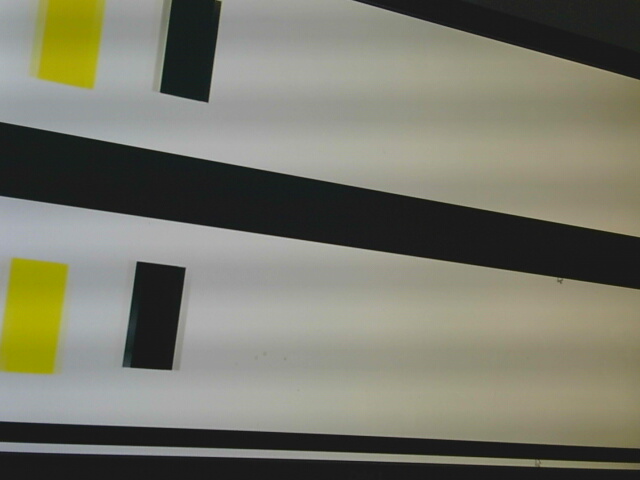
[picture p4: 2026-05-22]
Images/2026-05-21_iter1_scaler_top_frame090.jpg

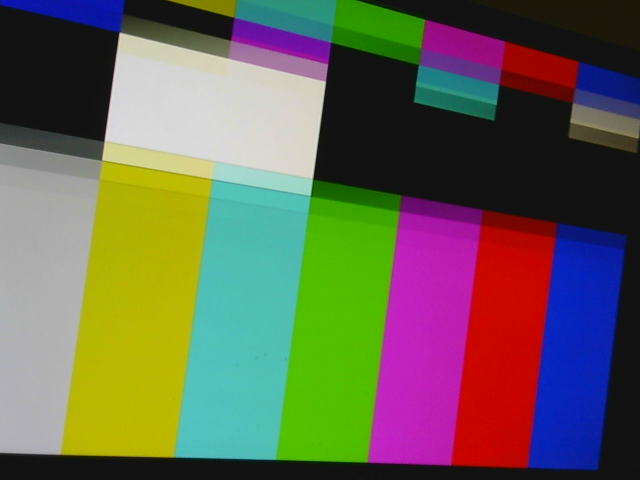
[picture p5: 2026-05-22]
Images/2026-05-21_iter4h_t4.0s.jpg

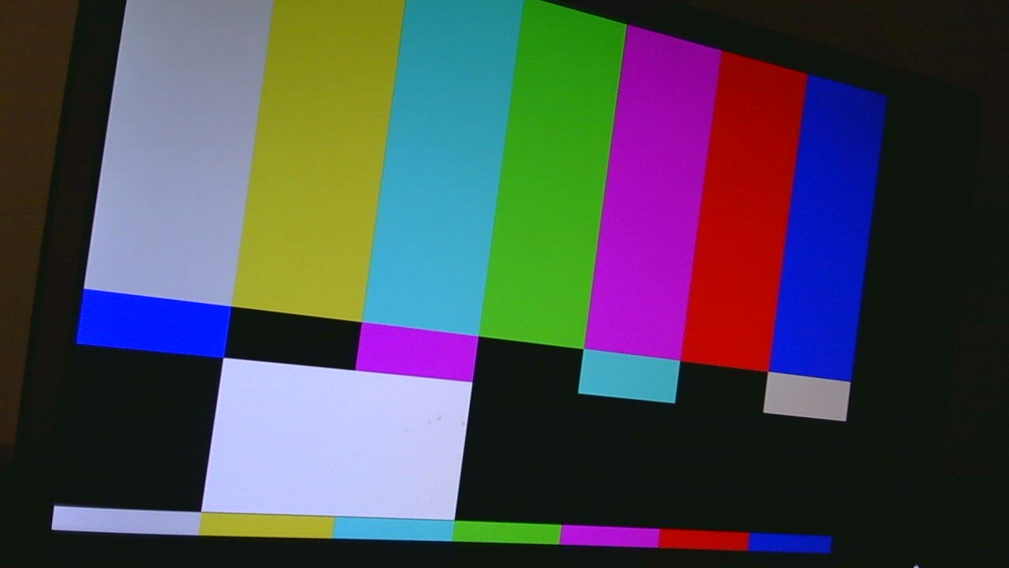
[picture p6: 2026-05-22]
Images/2026-05-21_iter1_input1_static_bottomBars.jpg

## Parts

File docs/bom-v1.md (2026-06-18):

# Schindler 2.0 — Bill of Materials

**Status:** Draft 2026-05-13 · **Production part-lock pass 2026-06-12** (all connector / switch / LED / MCU placeholders resolved to specific MPNs)
**Scope:** all silicon, modules, connectors, mechanical, and bench-eval boards. **One BOM covers both SKUs** — Pro v2 is the full stuffing; Mini v1 omits the Pro-tier silicon (SDI, RF modulator, dual SYNC OUT driver chain, per-connector LED drivers, rear LCD circuitry, Pro front-panel mezzanine). SKU stuffing matrix lives in [`packaging-skus.md`](packaging-skus.md).
**Detailed tracker:** `Parts List.xlsx` (authoritative for procurement state, notes, supplier links). This doc is the markdown-readable summary mapping parts onto the architecture in [`signal-flow.md`](signal-flow.md) + [`panel-layout.md`](panel-layout.md) + [`01-spec.md`](01-spec.md).

## Status legend

- ✅ **On order / received** — placed via DigiKey / Mouser / vendor
- 📋 **Banked / planned** — part selected and recorded in spec, not yet ordered
- 🔬 **Bench eval** — eval board on order or in use, production variant pending
- ❓ **TBD** — placeholder, selection deferred to carrier-schematic phase

---

## 1. Signal Path

Block-level breakdown of the video signal path per `signal-flow.md` diagram 1.

### HDMI Input
- **Chip 1 (HDMI IN ESD — sink-side, reworked 2026-06-14):** **2× TPD4E05U06DQA** (4-ch ultra-low-cap <0.5 pF TMDS ESD) + **1× TPD3E001DRLR** (DDC/HPD ESD); DDC/HPD/EDID handled natively by the LT8619C (no level-shifter on a sink). TI — ~$0.80 — 📋. *(Replaces the IN-side TPD12S016 — that part is source-side; kept only on the HDMI OUTPUT.)*
- **Chip 2:** `LT8619C` — HDMI 1.4 RX, parallel RGB out, embedded HDCP 1.4 keys — Lontium — ~$2 — ✅ (raw chip + LT8619C-EVB)
- **Connector:** HDMI Type A R/A PCB receptacle — Amphenol ICC **10029449-001RLF** — ~$1.20 — 📋

### SDI Input *(broadcast tier — factory-populated option)*
- **Chip 1:** `GS3470` — SDI receiver (3G-SDI); recovers clock + VITC; feeds video path AND genlock subsystem — Semtech — ~$15 — 📋
- **Connector:** 2× BNC 75 Ω R/A PCB bulkhead — Molex **73101-0120** (IN + IN LOOP, board-locks) — 📋 (prototype `0731010401` = same 73101 family — 🔬)

### Composite + Component Input
- **Chip 1:** `ADV7280AWBCPZ-M-RL` — multi-format analog decoder (CVBS / YPbPr / S-Video → BT.656 YCbCr 4:2:2 over parallel bus); AEC-Q100 auto grade; `-M` variant adds MIPI option — Analog Devices — ~$19 — ✅
- **Connectors:** 4× BNC 75 Ω — Molex **73101-0120** (1× CVBS + 3× YPbPr) — 📋
- **Passives:** input clamp = **BAV99** dual diode + input TVS; switchable 75 Ω term = TI **TS5A23159** analog switch + 75 Ω; AC-coupling + anti-alias LPF — values set at schematic — 📋

### FPGA Fabric (Zynq-7020)
All compute / pipeline blocks run inside the Zynq-7020 silicon carried on the TE0720 SOM.

- **SoC module:** Trenz **TE0720-04-62I33MA** — production target (Zynq-7020 -2I industrial, 1 GB DDR3L, 8 GB eMMC, 32 MB QSPI, GbE PHY on-module, 152 FPGA I/O via Samtec Razor Beam) — ~$300 — 📋
- **SoC module (bench):** Trenz **TE0720-04-31C33MA** — commercial -1 speed grade, same memory config, identical pinout — ~$230 — 📋
- **Heatsink:** Trenz **33337** springloaded — passive thermal — ✅
- **Carrier-side SoM sockets:** 2× Samtec **LSHM-150** (2×50, 100-pin → JM1/JM2 = refdes **J200 / J201**) + 1× Samtec **LSHM-130** (2×30, 60-pin → JM3 = **J202**) Razor Beam, 8 mm mating — ~$30/set — 📋. The TE0720 module mates to these three sockets; the $300 SoM line above is a mechanical/module BOM item with **no schematic refdes of its own** (the 3 sockets are its carrier interface). *(KiCad 2026-06-13: J200/J201 placed with a synthesized `Conn_02x50_Odd_Even` placeholder in `CarrierGen.kicad_sym`; swap to the real LSHM-150 symbol at layout for correct body/pin-1.)*
- **HDL blocks** (Xilinx IP, free): AXI VDMA. *(The Xilinx HDMI 1.4 TX IP is the **dev-board/Zybo** direct-TMDS path; production HDMI out is the external ADV7511 fed by an FPGA parallel video bus — see HDMI Output below + §3.2.)*
- **HDL blocks** (custom, in `hdl/`): polyphase scaler (8-tap H / 4-tap V), color pipeline (1024-entry gamma LUT + 3×3 matrix + per-channel trim), geometry (pincushion / keystone / 4-corner warp), test pattern generator (`sample_gen.v`), NTSC raster (`vid_timing.v` + `vbi_gen.v`), NTSC chroma (`chroma_gen.v`), luma+chroma combiner (inline in `top.v`)

### Analog Video Output (Composite + Component + S-Video)
- **Chip 1 (composite/component/S-Video):** `ADV7393BCPZ-REEL` — **triple 10-bit** output DAC/encoder; one chip serves composite/S-Video OR component, runtime mode-switched via I²C; SD/ED/HD component — Analog Devices — ~$16 — ✅
- **Chip 2 (output buffers):** `LMH6643MAX/NOPB` ×2 — dual op-amp, 130 MHz BW, low distortion; one HD-capable channel per DAC output (4 ch, 3 used), serving composite + component modes, single +5 V AC-coupled — TI — ~$1.50/dual — ✅ (10× prototype stock). **Consolidated 2026-06-11** — replaces OPA2350 SDTV tier + single LMH6643 (3-ch HD component needs 3 HD buffers; all-LMH6643 = one part type). OPA2350 (5× stock) freed for other use.
- **Connectors:** 4× BNC 75 Ω — Molex **73101-0120** (1× CVBS + 3× YPbPr) — 📋
- **Output ESD (added 2026-06-13e):** low-cap **<3 pF video TVS** at each panel BNC (TPD1E10B06-class) — generic — 📋; **220 µF** AC-couple at each BNC (×2 doubly-terminated, 75 Ω back-term); DAC load 37.5 Ω + RSET 4.12 kΩ + ×2 buffer gain resistors (per ADV7393 ref design). All on Sheet 6.
- **Note:** S-Video out is generated free from ADV7393 in composite mode (Y + C on two DAC channels) but the mini-DIN connector was dropped from V1 panel.

### SDI Output *(broadcast tier — factory-populated option)*
- **Chip 1:** `GS2962` — SDI transmitter (3G-SDI); processed output, not passive loop-through — Semtech — ~$17 — 📋
- **Connector:** 2× BNC 75 Ω — Molex **73101-0120** (OUT + OUT MIRROR, GS2962 C10/D10) — 📋

### HDMI Output (Monitoring/Analysis)
- **Chip 1:** `TPD12S016PWR` — HDMI ESD + level shift (same part as input) — TI — ~$1.50 — ✅
- **Chip 2 (HDMI TX):** `ADV7511KSTZ` — HDMI 1.4 transmitter; parallel RGB/YCbCr 4:2:2 in from FPGA (own dedicated 16-bit bus) → TMDS out; **non-HDCP variant** (no encryption asserted on the output — monitoring/analysis posture per §3.5) — Analog Devices, LQFP-100 — ~$7 — 📋. *(Production TX. The Xilinx free HDMI 1.4 TX IP / direct-FPGA-TMDS is the **dev-board / Zybo** bring-up path only — not production; see §3.2 + the 2026-06-13 changelog entry.)*
- **Connector:** HDMI Type A R/A PCB receptacle — Amphenol ICC **10029449-001RLF** — 📋

### Section subtotal (silicon only, per V1 unit)

| Item | Base | Broadcast |
|---|---:|---:|
| TPD12S016 ×2 | $3 | $3 |
| LT8619C ×1 | $2 | $2 |
| ADV7511 ×1 (HDMI TX) | $7 | $7 |
| ADV7280 ×1 | $19 | $19 |
| ADV7393 ×1 | $16 | $16 |
| Output buffers (2× LMH6643) | ~$3 | ~$3 |
| GS3470 ×1 | — | $15 |
| GS2962 ×1 | — | $17 |
| **Signal-path silicon** | **~$50** | **~$82** |

---

## 2. Sync Subsystem

Per `signal-flow.md` diagram 2 — genlock + dual SYNC OUT.

### Reference Input (Genlock Front-End)
- **Chip 1:** `LTC6912CGN-2#PBF` — 2-channel programmable gain amplifier; AGC loop driven by classifier — Analog Devices (Linear Tech) — ~$8 — ✅
- **Chip 2:** `AD9204BCPZ-20` — dual 10-bit 20 MSPS ADC; pin-compatible upgrade path to AD9231/9251/9258/9268 for 12/14/14/16-bit if future need — Analog Devices — ~$16 — ✅
- **Eval boards:** **MIKROE-2555** ×2 (LTC6912 GainAMP click, ~$25 ea) + **AD9204-80EBZ** (AD9204 eval, ~$278, 80 MSPS bench variant) — 🔬
- **Connectors (carrier PCB):** 2× **Hirose U.FL-R-SMT-1** (REF IN + REF LOOP carrier landing = **J802/J803**) — 📋. *(Carrier-schematic J800/J801 removed 2026-06-18.)*
- **Connectors (chassis/panel BOM — NOT carrier PCB):** 2× BNC 75 Ω **Molex 73101-0120** (REF/SYNC IN + LOOP, panel) **+ 2× 75 Ω U.FL↔BNC pigtail** (Option A: panel BNC → pigtail → carrier U.FL, no riser hop on phase-critical sync) — 📋
- **REF carrier interconnect (Option A, banked 2026-06-13):** 2× **Hirose U.FL-R-SMT-1** carrier-side receptacles (50 Ω / 6 GHz, ~$0.65–1.30 ea) + 2× 75 Ω coax pigtails (panel BNC → u.FL) — 📋. Keeps continuous coax across the riser gap on the phase-critical sync lines; the few-cm 50 Ω u.FL segment is negligible at sync edge rates. **Upgrade path** (impedance-exact + serviceable): 75 Ω MMCX PCB jack, ~$3–6 ea. A 75 Ω blind-mate float-bullet was rejected — effectively custom (float catalogs are 50 Ω).
- **Passives:** clamp = BAV99 + TVS, switchable 75 Ω term (TS5A23159), AC-coupling, switchable analog LPF — values at schematic — 📋

### Slow Control + Clock Generation
- **Chip 1:** **RP2040** (bare QFN-56) + **W25Q128JVSIQ** QSPI flash + 12 MHz crystal — autosense slow-control, PGA gain commands, Si5351 register writes, status reporting to Zynq PS over UART — Raspberry Pi — ~$1.50 — 📋 (production = bare chip, not module; same pattern as mezzanine RP2040)
- **Chip 2:** **Si5351A-B-GTR** — 3-output I²C clock generator (MSOP-10); ch0 → FPGA master, ch1+ch2 reserved — Skyworks/Silicon Labs — ~$2 — 📋 production (confirmed variant)
- **Eval boards:** **Adafruit 2045** Si5351 breakout ×2 — 🔬

### Genlock Loop Core
All in FPGA fabric — no discrete chips. Listed for completeness.
- Autosense classifier (LTC biphase / BB 15.734 kHz / tri-level signature)
- Per-format decoders: LTC frame decoder, BB sync separator, tri-level decoder, SDI recovered clock+VITC (from GS3470)
- Reference selector mux (operator override + autosense priority)
- Digital PLL: phase/frequency detector, loop filter (~0.5 Hz default), NCO/integrator, lock detector (state machine + quality metric)

### Dual SYNC OUT Generation
- **SYNC OUT 1 DAC:** `AD9742` — 12-bit, 210 MSPS TxDAC, current-output — Analog Devices — ~$7 — 📋 (pin-compatible to AD9744 14-bit; serves BB / tri-level / LTC, 13 PL pins)
- **SYNC OUT 2:** LTC-only — 1-bit FPGA biphase → slew-limited op-amp, **no DAC** (1 PL pin)
- **Cable drivers (both OUTs):** `LMH6643` dual op-amp — reused from the analog-output HD buffer; one dual covers SYNC 1 + SYNC 2 into 75 Ω — TI — ~$1.50 — 📋
- **Connectors:** 2× BNC 75 Ω — Molex **73101-0120** (SYNC OUT 1 + SYNC OUT 2) — 📋
- **Per-OUT phase accumulator + waveform gen:** FPGA fabric, no discrete chip

### Section subtotal

| Item | Per unit |
|---|---:|
| LTC6912 ×1 | $8 |
| AD9204-20 ×1 | $16 |
| RP2040 ×1 | ~$1 |
| Si5351 ×1 | ~$2 |
| AD9742 12-bit DAC ×1 (SYNC 1) | ~$7 |
| LMH6643 dual driver ×1 (both OUTs) | ~$1.50 |
| **Sync-subsystem silicon** | **~$35** |

---

## 3. Power

Per `01-spec.md` Power & safety section.

### AC Entry
- **Connector:** Schaffner **FN9260B-6-06** — IEC C14 + 6 A rating + integrated fuse holder + 1-stage EMI filter, panel-mount — ~$18 — ✅ (2 on order)
- **Fuse:** Littelfuse **0213002.MXP** — 2 A T (time-lag), 5×20 mm cartridge — ~$1 — 📋

### PSU Module
- **Module (primary):** Mean Well **LRS-50-12** — 50 W / 12 V single output, 85–264 VAC universal, enclosed aluminum case, convection-cooled, UL 62368-1, EN 55032 Class B — ~$15–20 — ✅
- **Module (alternate / lower-noise swap-in):** TDK-Lambda **HWS50A-12/A** — same form factor, lower switching noise for pro-audio-adjacent applications if bench characterization shows the Mean Well noise floor as audible — ~$50 — 📋
- **PSU → Carrier connector:** Molex Mini-Fit Jr. **0039291028** (2-ckt vertical PCB header) + 5557-02R receptacle housing — 9 A — ~$0.80 — 📋

### Carrier 12 V Input Protection Chain
- **U1 (protection eFuse):** TI **TPS26601** — 60 V integrated FET; reverse-polarity + reverse-current, adjustable OVP + OCP (precise current limit, no thermal derate), controlled inrush; EN = soft-power gate; I<sub>LIM</sub> ≈ 2.5 A. Replaces the DMP3098L + polyfuse + TVS chain — ~$2.50 — 📋 *(swapped from TPS26600 2026-06-13b: the '601's MODE-open default is circuit-breaker-with-**latch**, matching the chosen latch-off posture — MODE left open, no strap. Pinout identical to the '600; KiCad symbol reused, set value to '601.)*
- **U2 (power monitor):** TI **INA226** — I²C 16-bit current+voltage telemetry alongside the eFuse — ~$1.50 — 📋
- **Sense resistor:** 5 mΩ, 1 % — generic — ~$0.20 — 📋
- **C bulk:** 3× Murata **GRM32** 22 µF 25 V X7R MLCC in parallel (~66 µF nominal, ~35 µF effective at 12 V bias) — ~$2.40 — 📋
- **U3 (soft-power controller):** ADI **LTC2954-1** — pushbutton on/off controller in the always-on 12 V domain (2.7–26.4 V, 6 µA standby — no standby LDO). Debounced front-panel button → drives the eFuse EN gate; **INT** → Zynq GPIO (orderly-shutdown request), **KILL** ← Zynq GPIO (clean power-down), **PDT** watchdog (~5 s) force-off if Linux hangs. 8-pin ThinSOT — ~$2.50 + ~$0.30 timing/PB passives — 📋. Resolves the "RP2040 is downstream of the rails it would gate" chicken-and-egg.

### Per-Rail Regulators (Downstream of 12 V)
Committed 2026-06-11. VIN fed from the 5 V rail; Vccint 1.0 V / 1.8 V / DDR3L 1.35 V are generated **on-module** (not carrier-supplied).
- **5 V buck** (~3 A) — TI **LMR33640 (4 A)** (12→5 V; module VIN + USB host + analog op-amps; op-amps single +5 V, AC-coupled at BNCs) — ~$1.30 — 📋
- **3.3 V buck** (~2.5 A) — TI **LMR33640 (4 A)** (12→3.3 V; module 3.3VIN + all VCCIO banks + carrier digital), same part 2nd instance — ~$1.30 — 📋
- **1.2 V buck** (~0.4 A) [Pro] — TI **TLV62568** (5→1.2 V; GS3470 ~0.15 A + GS2962 ~0.25 A on 1.2 V core/analog — verified ~0.3–0.4 A, GS2962 cable driver sits on 3.3 V) — ~$0.40 — 📋
- **1.8 V analog LDO** (~0.3 A) — TI **TPS7A2018PDBVR** low-noise (3.3→1.8 V; AD9204 AVDD + ADV7280 analog) — ~$1 — 📋
- **Clean analog LDOs** — ADI **ADP7142** (adjustable, ultra-low-noise), one per ADC/decoder, output set at schematic — ~$1 — 📋
- **1.8 V digital LDO (`+1V8_D`)** — small 1.8 V LDO off the 3.3 V rail (~0.1 A) for **VCCIO33 (PL bank 33) + AD9204 DRVDD**; added 2026-06-13c when B33 was re-strapped to 1.8 V for the AD9204 1.8 V CMOS interface — kept off the analog 1.8 V so DRVDD switching doesn't couple into the ADC AVDD — ~$0.30 — 📋 (U310)

### Section subtotal

| Item | Per unit |
|---|---:|
| FN9260B-6-06 ×1 | $18 |
| Fuse | $1 |
| PSU module (LRS-50-12 primary / HWS50A-12/A alternate) | $15–50 |
| Carrier protection + soft-power | ~$10 |
| Per-rail regulators | ~$5 |
| **Power subsystem total** | **~$49–84** |

---

### Analog/genlock conditioning parts (added 2026-06-13e/14, sheets 4/5/6/8)
- **BAV99S** (series dual diode, SOT-363) — IC-side **2-rail clamp** to AVDD/GND on analog-in (ADV7280) + genlock (LTC6912 PGA) inputs — generic — 📋. (Replaces the common-anode BAV99 for proper 2-rail clamping.)
- **Low-cap <3 pF video TVS** (TPD1E10B06-class) at every external analog/genlock panel BNC — generic — 📋.
- **ADV7280 crystal** — 28.63636 MHz + 18 pF loads (Y500) — generic — 📋 (required by the decoder; was missing from the parts list).
- **PCA9555** I²C GPIO expander (on I2C_HK) — drives the switchable 75 Ω termination ground-leg switches (REF/SDI loop-through inputs) — NXP/TI — ~$1 — 📋.
- HDMI: 2.2 kΩ DDC/I²C pull-ups, CT_HPD + supply decoupling (TPD12S016) — generic — 📋.
- **ADV7511 (U403) R_EXT + AVDD fix (2026-06-18):** **R406 887 Ω 1%** from pin 28 (R_EXT) → GND (bias reference, was floating); pin 29 (AVDD) wired → +1V8_A (was floating — 1 of 3 AVDD pins unpowered). Symbol mislabels (28='EXT', 29='R_EXT') — relabel pending, wired by pin number. — generic — 📋.
  - **TPD12S016 (U401, HDMI OUT) supply decoupling (2026-06-14):** VCC5V (pin 11) = **C405 1 µF bulk + C406 0.1 µF X7R** (C406 added directly in the wired sheet 4); VCCA (pin 24) = **C403 0.1 µF X7R** (already present). All X7R, to GND — generic — 📋.
  - **LT8619C (U402, HDMI RX) decoupling — added 2026-06-14, standard multi-supply HDMI-RX practice (no exhaustive per-pin table in datasheet):**
    - **14× 0.1 µF X7R 0402** — one per supply pin to GND: **C407/C408** (VCCA18 p1/p13 → +1V8_A), **C409** (PVCC18 PLL p59 → +1V8_A), **C410/C411/C412** (VDD18 p25/p58/p67 → +1V8_D), **C413** (VCCA33 p7), **C414/C415** (VCC33 p20/p64), **C416/C417** (VCC33_TTL p36/p57), **C418** (VCCA33_XTAL clock p62), **C419/C420** (VTERM TMDS-term p4/p10) — all → +3V3.
    - **3× 10 µF X7R/X5R 0805 bulk** — one per rail near chip: **C421** (+1V8_A), **C422** (+1V8_D), **C423** (+3V3).
    - **Optional PLL/clock ferrite isolation (jitter):** **FB400** (+1V8_A→+1V8_A_PLL, C409 moves there), **FB401** (+3V3→+3V3_XTAL, C418 moves there) — generic — 📋.
- Output stage (ADV7393 low-drive): 300 Ω DAC loads, 4.12 kΩ RSET, ×2 buffer gain resistors, 75 Ω back-term, **220 µF AC-couple** at BNC — generic — 📋.

## 4. UX / Panel I/O

### Front Panel — Pro mezzanine board (RP2040 + EVE)
Separate mezzanine behind the front-panel aluminium, UART + power to the carrier. Per spec §15.2 / §17.1.
- **Front TFT:** Newhaven **NHD-2.9-376960AF-ASXP** — 2.9" 376×960 IPS (mounted landscape, 960×376), ST7701SN, 24-bit parallel RGB, 1050 cd/m² — ~$30 — 📋 (bezel cutout 69×28 mm)
- **Graphics controller:** BridgeTek **BT817Q** EVE 4 — drives NHD-2.9 over 24-bit RGB, 1 MB RAM_G, command-list rendering from RP2040 over SPI — ~$10–13 — 📋
- **TFT backlight boost:** TI **TPS61040** class 6.0 V boost on mezzanine — ~$0.50 — 📋
- **UI MCU:** **ESP32-S3-WROOM-1U-N8R2** (module — **production target**) — UI MCU on A2: reads encoders/buttons, streams EVE command lists to the BT817Q over SPI, syncs to Zynq PS over UART, WiFi OTA. **The module integrates the ESP32-S3 + 8 MB flash + 2 MB PSRAM + 40 MHz xtal + RF front-end + U.FL antenna connector**, so the separate W25Q128 flash + 12 MHz crystal A2 carried for a bare chip are **deleted** (integral to the module). **`-1U` = external antenna** (U.FL → coax → panel RP-SMA J1002). **R2 (2 MB PSRAM) keeps the full −40~85 °C** range (R8 caps at 65 °C); 2 MB is sufficient because the **BT817Q EVE owns the framebuffer** — the ESP32 only streams display lists, never holds a frame buffer. **Pre-certified (FCC/IC modular approval)** — the radio needs no intentional-radiator cert on our end (only whole-box Part 15B), a major cert simplification vs a bare chip. ~$3.50 — 📋. **Bench part in hand: ESP32-S3-WROOM-1U-N16R8** (16 MB / 8 MB PSRAM, −40~65 °C) — over-provisioned for bring-up (won't hit a memory ceiling while developing); N8R2 is ~2 months out but fine for the production timeline. *(Caveat: don't treat the N16R8's R8 65 °C ceiling as representative — the production R2 is rated to 85 °C; validate thermal against that.)*
- **Encoders:** 2× Alps **EC11E18244AU** — 36 detents / 18 PPR, integrated push switch, -40 to +85°C industrial — ~$3 ea — ✅ (5 on order)
- **Encoder alternates for UX testing:** **3315Y-025-016L** ×2, **EC111012010H** ×1 — ✅
- **Knob options for evaluation:** CP34501, FC7229NML, CL178883, FC1611, 1202CY (production knob selection deferred) — ✅
- **Buttons:** 4× tactile (Home, Back, Menu, Confirm) + 2–3 quick-select (BLACK / MONO / Proc-Amp bypass) — C&K **PTS645SM43SMTR92LFS** (6 mm SMT) + panel actuator/cap (cap at mech) — 📋
- **Front status LED column:** mirrors rear per-connector LED state
- **Power button:** **E-Switch PV6** series 16 mm anti-vandal ring-illuminated momentary, lower-left — gated by the **LTC2954-1** soft-power controller (see §3 Power); LED off EN / RP2040 — 📋 (color/voltage suffix at mech)
- **Knob shroud / guard:** mechanical, recessed encoder pocket (HARD REQUIREMENT — must survive face-down drop in road case) — schematic+chassis phase

*(Reconciled 2026-06-11 from the stale STM32H735 + ILI9341 entry to the committed RP2040 + BT817Q EVE + NHD-2.9 mezzanine per spec §15.2/§17.1. STM32H735IGT6 UI MCU + STM32H735G-DK eval dropped — superseded by the EVE/RP2040 path.)*

### Rear Panel — Status Display
- **LCD:** Newhaven **NHD-1.5-240240AF-CSXP** — 1.5" 240×240 IPS square, ST7789VI + frame RAM, 32.52 × 35.32 mm module (~28×28 mm active), 1200 cd/m² — ~$15 — 📋. **4-wire SPI** (strap IM0=0/IM1=1/IM2=1).
- **Backlight:** 3.0 V / 100 mA small LDO from 3.3 V — ~$0.20 — 📋
- **Mounting:** recessed bezel cutout with anti-glare film
- **Owner:** Zynq PS via dedicated SPI port, ~1 s refresh, read-only status grid

*(Reconciled 2026-06-11 from the "2.4 16:9" placeholder to the committed NHD-1.5 on SPI per spec §16.3.)*

### Per-Connector Status LEDs
- **LED:** Lumex **SSF-LXH409SISUGW** — 3 mm bi-color red (636 nm) / green (574 nm) **common-anode**, **one-piece right-angle PCB indicator** (housed RA CBI — emits parallel to the board → faces the rear panel; no separate holder or light pipe), 3-lead offset-cathode, 60° dome — qty ~21 (one per rear connector) — ~$0.60–1.00 ea (housed RA CBI; confirm at procurement) — 📋. Common-anode suits the TLC59116 current-sink (2 ch/LED → 42 of 48 ch). **Selected 2026-06-13c** over the bare Kingbright L-3VEGW-CA (vertical-emit — would have needed a holder or light pipe) and the Dialight 551-3513F (common-*cathode* — wrong polarity for a sink driver). Amber = R+G; **balance the two channels in TLC59116 PWM** (red 350 mcd > green 130 mcd at equal current). Internal die = SSL-LX3059SISUGW.
- **Driver chips:** 3× TI **TLC59116F** — 16-channel constant-current with per-channel PWM dimming — ~$1.50 ea — 📋
- **Bus:** I²C from Zynq PS

### Section subtotal

| Item | Per unit |
|---|---:|
| Front TFT (NHD-2.9) | ~$30 |
| BT817Q EVE + 6 V boost | ~$13 |
| Mezzanine ESP32-S3-WROOM-1U module (N8R2; was bare RP2040+flash+xtal) | ~$3.50 |
| 2× Alps EC11 encoder | $6 |
| 4 tactile + 3 quick-select buttons | ~$3 |
| Power button (lighted soft) | ~$3 |
| Rear LCD (NHD-1.5) + backlight LDO | ~$15 |
| 21× tricolor LEDs (Lumex SSF-LXH409 RA CBI) | ~$13–16 (confirm) |
| 3× TLC59116F | $4.50 |
| Knob hardware | ~$10 (est.) |
| **UX/Panel subsystem total (Pro)** | **~$90** |

---

## 5. Control + Networking

### Wired Control
- **GbE PHY:** integrated on TE0720 SOM (no external PHY needed) — 📋
- **RJ45 jack with magnetics:** Pulse **JXD1-0001NL** — Gigabit integrated-magnetics magjack with LEDs — ~$3 — 📋
- **USB-C service port:** GCT **USB4085-GF-A** (USB 2.0 Type-C, R/A SMT) + ESD **TI TPD4S014DBVR** — ~$3 — 📋. USB 2.0 only (gadget console + ethernet-over-USB); no PD/SS.

### Wireless
- **WiFi/BT module:** Laird Sterling **LWB5+** — pre-certified, 88W8997 chipset, dual-band a/b/g/n/ac + BT5.0. WiFi on **SDIO0 (PS MIO40–45, 1.8 V strap — direct, no level shifter)**; BT on a separate PS UART — ~$30 — 📋
- **Antennas:** 2× Linx **CONREVSMA001** RP-SMA bulkhead jack + Linx **ANT-DB1** dual-band 2.4/5 GHz stub — ~$5 ea — 📋. **Must be on the LWB5+ FCC grant's permitted-antenna list — confirm before order.**

### Compute (Linux Side)
- **Zynq PS** — dual Cortex-A9 on TE0720 SOM under PetaLinux; hosts web UI, REST API, EDID, mDNS, OTA, config persistence, color pipeline runtime (Screenie port), I/O state aggregator. Listed under Signal Path; no separate silicon.

### Section subtotal

| Item | Per unit |
|---|---:|
| LWB5+ WiFi/BT module | $30 |
| RJ45 mag jack | ~$3 |
| USB-C connector + ESD | ~$3 |
| 2× RP-SMA + antennas | ~$10 |
| **Control/networking total** | **~$46** |

---

## 6. Chassis + Mechanical

### Enclosure
- **Chassis:** 1RU full-rack 19" extruded aluminum body — **Hammond** (RM1U-series, exact model at mech) — ~$50–80 — 📋
- **Front panel:** Front Panel Express milled aluminum, anodised, silkscreened — fab deliverable from `panel-layout.md` — ~$40 — 📋
- **Rear panel:** Front Panel Express milled aluminum, panel cutouts for all rear I/O (incl. RF daughter-board F-conn cutout) — fab deliverable from `panel-layout.md` — ~$60 — 📋
- **Rack ears:** integrated with the Hammond 1U chassis — ~$10 — 📋

### Thermal
- **Fan:** Noctua **NF-A4x20 PWM** — 40 mm, ~14 dB low RPM, conditional/silent (only spins on SOM temp threshold) — ~$15 — 📋
- **SOM thermal pad:** silicone gap pad between Zynq SOM and chassis top cover (top acts as primary heatsink for fanless operation at typical 14–16 W load) — ~$2 — 📋

### Hardware
- **M3 standoffs** for PSU mounting (×4) and carrier PCB mounting (×6–8) — generic brass M3 — ~$3 total — 📋
- **Earth bonding stud** for chassis ground — M4 brass stud — ~$1 — 📋
- **Mounting screws** (mix of M3 panhead + M2.5 for board mounts) — generic — ~$3 — 📋

### Mechanical Reservations
- **Knob shroud / encoder guard** on front panel (HARD REQUIREMENT) — milled into front panel or separate bezel piece — schematic+chassis phase
- **Spare panel space** ~67 mm on right side of rear panel — reserved for V1.x expansion (potential XLR return, 10 MHz GPSDO BNCs, or vented airflow grille)

### Section subtotal

| Item | Per unit |
|---|---:|
| Chassis | ~$70 (est.) |
| Front panel | ~$40 |
| Rear panel | ~$60 |
| Rack ears | ~$10 |
| Noctua fan | $15 |
| Thermal pad | $2 |
| Hardware (standoffs/screws/stud) | ~$7 |
| **Chassis/mechanical total** | **~$200** |

---

## 7. RF Modulator Output *(RF daughter-board — separate shielded assembly)*

**Partition committed 2026-06-11:** the RF modulator is a standalone, shielded, panel-mounted **daughter board**, not carrier-resident. It connects to the carrier by 1× u.FL coax (baseband composite in) + a 6-pin header (DC + I²C). Adds an RF modulated output on NTSC Ch3 or Ch4 (operator-selectable) for 1970s consumer CRTs with antenna-only inputs. The RF *chain* parts below are unchanged from the prior bake-in spec — they relocate onto the daughter board. Partition + physical-build spec: [`rf-modulator-daughter-board-option.md`](rf-modulator-daughter-board-option.md). Chain architecture: [`rf-modulator-subsystem.md`](rf-modulator-subsystem.md).

**Operator picks one of three analog output modes** via UI: composite (BNC live), RF Ch3 / RF Ch4 (F-connector on the daughter board live; ADV7393 stays in composite mode; carrier feeds composite to the board over u.FL), or component (3× component BNC live, ADV7393 in component mode). **RF mute** = disable the daughter-board Si5351 output over I²C (no amp-enable pin needed). HDMI and SDI remain independently live. F-connector lives on the daughter board's own rear-panel edge, beside the composite BNC.

### Modulator + carrier generation
- **AM modulator (primary):** `ADL5391ACPZ-R7` — Analog Devices, DC–2.0 GHz analog multiplier, modern symmetric-core architecture, 16-LFCSP, 7" reel cut for single qty — ~$15 single qty / ~$18 at qty 100 — 📋
- **AM modulator:** committed to **ADL5391** (2026-06-07). `AD835ARZ` head-to-head **dropped, not ordered**; if a cheap second-topology bench comparison is ever wanted, the MC1496 balanced modulator (~$1) is the option, not another precision multiplier.
- **RF carrier gen:** **Si5351A-B-GTR** — dedicated to RF subsystem (separate from genlock Si5351 to avoid cross-coupling) + 25 MHz crystal — Skyworks/Silicon Labs — ~$2 — 📋
- **Si5351 channel allocation:** ch1 = video carrier (Ch3 61.25 MHz / Ch4 67.25 MHz), ch2 = audio pilot CW (Ch3 65.75 MHz / Ch4 71.75 MHz), ch0 free.

### RF chain
- **RF amp:** Mini-Circuits **ERA-3SM+** — MMIC, DC–3 GHz, ~22 dB gain, SOT-89, 50 Ω native — ~$3.50 — 📋
- **Output bandpass filter:** **5th-order Butterworth** LC, centered ~64 MHz, passband 56–73 MHz (covers Ch3 + Ch4 carriers; suppresses 2nd harmonics at 122.5–134.5 MHz) — Coilcraft 0805CS-class inductors + C0G caps, ~9 parts — ~$1.50 — 📋. **Butterworth committed** (tolerance-insensitive across 100 units; ~1-octave 2H separation gives ample rejection without Chebyshev ripple). Nominal L/C captured at schematic; final values bench-tuned on the prototype.
- **50→75 Ω MLP (minimum-loss pad):** 43.2 Ω series + 86.6 Ω shunt resistors (off-the-shelf 43 Ω + 82 Ω 1% is close enough). Two 1% resistors total. 5.7 dB insertion loss — mathematically optimal for resistive 50↔75 Ω conversion. Broadband DC-to-GHz, no tuning, no drift. ERA-3SM+ has 22 dB gain headroom so pad loss is rounding error. **Replaces prior transformer option** (TC4-1W+/MABAES0061 are 1:4 ratio = 50↔200 Ω, NOT 50↔75 — confirmed by datasheet 2026-05-11 PM). — ~$0.10 — 📋
- **Audio combiner:** 3-resistor resistive combiner that sums Si5351 ch2 audio pilot CW with ADL5391 output before bandpass filter — generic resistors — ~$0.50 — 📋

### Mode selection (no RF-path switches)
- **RF mute:** disable the daughter-board Si5351 output via I²C (OEB / clock power-down) — no carrier, nothing to gate. **The ERA-3 bias FET gate was dropped 2026-06-11** with the move to a daughter board (amp is powered whenever the board is; mute happens upstream at the Si5351). No amp-enable pin on the interconnect.
- **ADV7393 mode:** I²C-switched between composite mode (serves composite BNC + the daughter board's u.FL feed) and component mode (serves 3× component BNC) — no additional silicon, configuration only.
- **Composite BNC gate (ADG419) dropped 2026-06-11** — a ~30 Ω SPST switch in series with the 75 Ω composite line degraded return loss/level for no benefit; the composite BNC stays live and the daughter board taps the same buffered signal over u.FL. See `rf-modulator-subsystem.md`.

### Output protection + connector
- **DC block on RF output:** C0G **1 nF** 50 V MLCC (`KGM21BCG1H102FT` class) — generic — ~$0.10 — 📋 (corrected 2026-06-07 from 0.1 µF: at 67 MHz a 0.1 µF cap is past self-resonance and goes inductive; 1 nF C0G is a clean block — applies to all RF-path blocks)
- **ESD on F-conn:** `PESD3V3L1BA` low-cap TVS or equivalent — NXP — ~$0.20 — 📋
- **F-connector:** Amphenol RF **82-4421** class panel-mount 75 Ω, threaded — ~$1.50 — 📋

### Shielding
- **Shield can:** Masach **MS643-10F-NS** frame + **MS643-10C-NS** cover — nickel-silver, two-piece, 64.3 × 20.3 × 6.7 mm, over the whole RF section (modulator + amp + dedicated Si5351 + bandpass) — ~$3.50 — 📋 (required for FCC Part 15 compliance — not optional). Two-piece for bench tuning; long-narrow footprint gives natural I/O isolation along the chain.
- **Feedthrough caps (at can wall):** 2× Murata `NFM21PC104R1E3D` 0.1 µF 25 V (DC lines) + 2× `NFM21CC102R1H3D` 1 nF 50 V (I²C) — ~$0.55 — 📋. Optional 2× `BLM21PG600SN1D` series ferrite (~600 Ω @ 100 MHz) — ~$0.20.
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

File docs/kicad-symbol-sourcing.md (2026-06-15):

# Schindler 2.0 — KiCad Symbol Sourcing Checklist

**Generated:** 2026-06-12 · **Against:** [`part-lock-2026-06-12.md`](part-lock-2026-06-12.md) / [`bom-v1.md`](bom-v1.md) · **Refdes:** [`refdes-map.md`](refdes-map.md)

**Purpose:** before any symbol-placement pass (Claude Code or hand), every part needs a KiCad **schematic symbol**. This sorts all locked parts into three tiers so the **ADD** list is your shopping list of symbols to import/build first.

## Tiers

- ✅ **STOCK** — in KiCad's standard symbol libraries (KiCad 9/10). Use as-is. Symbol name given is the expected `Library:Symbol`.
- 🔎 **VERIFY** — almost certainly in stock libs; confirm with one lookup in the Symbol Chooser. If absent, grab from SnapEDA.
- ⛔ **ADD** — not in stock. Download (SnapEDA / Ultra Librarian / SamacSys) or build from datasheet / vendor files. **These are the gaps.**

> Best symbol sources for the ADD list, in order: **vendor KiCad files** (Trenz, BridgeTek, Newhaven) → **SnapEDA** → **Ultra Librarian / SamacSys (ComponentSearchEngine)** → hand-build. ADI/TI/Semtech parts are nearly all on SnapEDA.

---

## ✓ Already in JustinLibrary (checked 2026-06-12)

`_PROJECTS/_KiCad/JustinLibrary.kicad_sym` already contains custom symbols for these — **no action needed** (Justin built them). Reconciled against the live file (17 at first check; **+4 added since** — LMH6643, TPS26600, LTC2954-1, ADL5391):

| In library as | Covers (refdes) |
|---|---|
| `AD9204BCPZ-20` | genlock ADC (U801) |
| `ADV7280AWBCPZ-M` | analog decoder (U500) |
| `ADV7393BCPZ` | analog enc/DAC (U600) |
| `ADV7511KSTZ` | HDMI TX (U403) |
| `ERA-3SM_` | RF MMIC amp (RF U3) |
| `GS2962-IBE3` | SDI TX (U701) |
| `GS3470-IBE3` | SDI RX (U700) |
| `INA226` | power monitor (U301) |
| `LT8619C` | HDMI RX (U402) |
| `LTC6912CGN-2#PBF` | genlock PGA (U800) |
| `RP2040` | both RP2040s (U900, mezz U1) — custom; stock also exists |
| `SI5351A-B-GT` | both Si5351s (U902, RF U2) — “GTR” is tape/reel of same die |
| `Sterling LWB5+` | WiFi/BT module (U1000) |
| `TE0720-03-61C33FAS` | Zynq SoM (J200–J202) — ⚠ **variant flag**, see below |
| `TLC59116FIPWR` | LED drivers (U1100–U1102) |
| `TPD12S016PWR` | HDMI ESD/level ×2 (U400/U401) |
| `LMH6643` *(added)* | video buffers ×3 (U601/U602/U904) — not in KiCad stock |
| `TPS26600` *(added)* | protection eFuse (U300) |
| `LTC2954-1` *(added)* | soft-power ctrl (U302) |
| `ADL5391` *(added)* | RF AM modulator (RF U1) |
| `DMP3098L-7` | ⚠ **legacy/unused** — the old reverse-polarity FET, superseded by the TPS26600 eFuse. Ignore; don't place. |

**⚠ TE0720 variant flag:** the library symbol is `TE0720-03-61C33FAS` (a **-03** module); production target is **-04-62I33MA**. Spec §1.1 calls the carrier pinout identical across TE0720 variants, so the symbol is reusable — but **confirm the -03 vs -04 Razor-Beam pin map matches before relying on it**, and consider renaming the symbol to a variant-agnostic `TE0720` to avoid confusion.

This collapses the original 20-item ADD list to the short set below.

---

## Pull-sheet corrections caught here

- **ADV7511KSTZ** (HDMI TX, `U403`) was missing from the part-lock active-silicon table — it's in the BOM §3.2 and refdes-map sheet 4. Added below.
- **Crystals**: 2× 25 MHz (Si5351 genlock + RF) and 2× 12 MHz (RP2040 genlock + mezz) aren't called out as line items. Stock symbol, but they need placing — added below.

---

## Generic / passive / connector (mostly STOCK)

| Part (refdes) | KiCad symbol | Tier |
|---|---|---|
| Resistors / caps / inductors | `Device:R` / `Device:C` / `Device:L` | ✅ |
| Ferrite bead (FB, BLM21) | `Device:Ferrite_Bead` | ✅ |
| Crystal 25 MHz / 12 MHz (Y9xx, Y1) | `Device:Crystal_GND24` (or `Crystal`) | ✅ |
| Trim pot (Bourns 3224W, RV1/RV2) | `Device:R_Potentiometer_Trim` | ✅ |
| BAV99 clamp (D5xx/D7xx/D8xx) | `Diode:BAV99` | ✅ |
| Input TVS / PESD3V3L1BA (D1, ESD) | `Device:D_TVS` | ✅ |
| Fuse (F300) | `Device:Fuse` | ✅ |
| Fan (Noctua, PWM 4-pin) | `Device:Fan` | ✅ |
| Status LED bi-color CA (L-3VEGW-CA, D11xx) | `Device:LED_Dual_ACA` (common-anode dual) | 🔎 confirm CA pin order |
| BNC 75 Ω (Molex 73101-0120, J*) | `Connector_Coaxial:BNC` | ✅ |
| SMA / RP-SMA (Linx CONREVSMA001, J100x) | `Connector_Coaxial:SMA` | ✅ |
| u.FL (RF board J1, carrier J1200) | `Connector_Coaxial:U.FL` | ✅ |
| HDMI Type A (Amphenol 10029449, J400/J401) | `Connector:HDMI_A` | ✅ |
| USB-C 2.0 (GCT USB4085, J1001) | `Connector:USB_C_Receptacle_USB2.0` | ✅ |
| RJ45 magjack (Pulse JXD1-0001NL, J1000) | `Connector:RJ45` + magnetics | 🔎 generic stock; magjack-with-magnetics pinout may need the specific symbol |
| Mini-Fit Jr 2-ckt (Molex 0039291028, J301) | `Connector:Conn_01x02` / `Connector_Molex` | ✅ |
| Pin headers (6-pin RF, expansion, JTAG, UART) | `Connector_Generic:Conn_*` | ✅ |
| Antenna (Linx ANT-DB1) | `Device:Antenna` | ✅ |
| F-connector (Amphenol 82-4421, RF J3) | `Connector_Coaxial:F_*` | 🔎 |
| Rotary encoder (Alps EC11, SW1/SW2) | `Device:Rotary_Encoder_Switch` | ✅ |
| Tactile (C&K PTS645, SW3–SW9) | `Switch:SW_Push` | ✅ |
| Power button illum. (E-Switch PV6, SW10) | `Switch:SW_Push_LED` | ✅ |
| FFC for NHD displays (J1101, mezz J2) | `Connector:Conn_01xNN` (per panel pinout) | 🔎 |

---

## ICs — STOCK / VERIFY / in-library

*(✓lib = in JustinLibrary; ✅ = confirmed in KiCad stock. **Update 2026-06-12: this table is fully resolved.** Every 🔎 was checked — stock libs cover them; LMH6643 was the one exception, not in stock, now added to JustinLibrary.)*

| Part (refdes) | KiCad symbol | Status |
|---|---|---|
| RP2040 ×2 (U900, mezz U1) | `JustinLibrary:RP2040` (or stock `MCU_RaspberryPi:RP2040`) | ✓lib |
| INA226 (U301) | `JustinLibrary:INA226` | ✓lib |
| TLC59116F ×3 (U1100–U1102) | `JustinLibrary:TLC59116FIPWR` | ✓lib |
| Si5351A-B-GTR ×2 (U902, RF U2) | `JustinLibrary:SI5351A-B-GT` | ✓lib |
| TPD12S016PWR ×2 (U400/U401) | `JustinLibrary:TPD12S016PWR` | ✓lib |
| LMH6643 ×3 (U601/U602/U904) | `JustinLibrary:LMH6643` *(added — not in stock)* | ✓lib |
| W25Q128JVSIQ ×2 (U901, mezz U2) | `Memory_Flash:W25Q128JVSxIQ` | ✅ |
| TS5A23159 (U501/U802) | `Analog_Switch:TS5A23159` | ✅ |
| LMR33640 ×2 (U303/U304) | `Regulator_Switching` family | ✅ |
| TLV62568 (U305) | `Regulator_Switching:TLV62568` | ✅ |
| TPS7A2018 (U306) | `Regulator_Linear:TPS7A20*` | ✅ |
| ADP7142 ×3 (U307–U309) | `Regulator_Linear:ADP7142` | ✅ |
| TPS61040 (mezz U4) | `Regulator_Switching:TPS61040` | ✅ |
| TPD4S014 (U1001) | `Power_Protection:TPD4S014` | ✅ |

---

## ICs — ⛔ ADD — CLEARED

**Update 2026-06-12 (final): zero symbol gaps.** Every part has a symbol — stock, in JustinLibrary, or built into `Schindler.kicad_sym`.

**Built by Claude → `_PROJECTS/_KiCad/Schindler.kicad_sym`** (validated: parses clean, pin counts correct):
- `NHD-2.9-376960AF-ASXP` — 40-pin 0.5 mm FFC, full pinout (R0–R7/G0–G7/B0–B7, PCLK/HS/VS/DE, RESETX, CSX/DCX/SCL/SDA, LED-A/K, VDD/GND). Ref `J`.
- `NHD-1.5-240240AF-CSXP` — 28-pin 0.5 mm FFC, full pinout (IM0-2, RESX/CSX/DCX/WRX/RDX/SDA/SDO/TE, DB0–DB7, LED_A/K, VDD/GND). Ref `J`. Driver = ST7789VI; 4-wire SPI for our use (IM0=0/IM1=1/IM2=1).
- `FN9260B-6-06` — 6-terminal power-entry block (L/N/PE in → L'/N'/PE' out). Ref `J`. *(B = medical, no Y-caps.)*
- `NFM21_Feedthrough` — generic 3-terminal feedthrough (IN/OUT/GND). Ref `FC`. Value per instance: `NFM21PC104R1E3D` (0.1 µF DC) / `NFM21CC102R1H3D` (1 nF I²C).

**Resolved earlier this pass (by Justin):**
- **AD9742 (U903)** → found + added. *(Note: AD9742/AD9744 are pin-compatible 12/14-bit TxDACs — if the symbol Justin added is the AD9744, it's electrically fine; just confirm the value field reads the part actually being ordered.)*
- **BridgeTek BT817Q** (mezz U3, QFN-64) → found + added.
- **TPS26600, LTC2954-1, ADL5391** → added to JustinLibrary.

Already in JustinLibrary (no action): TE0720, LT8619C, ADV7280/7393/7511, GS3470/GS2962, LTC6912, AD9204, ERA-3SM, LWB5+, INA226, Si5351, TLC59116, TPD12S016, RP2040, LMH6643, TPS26600, LTC2954-1, ADL5391, **AD9742, BT817Q**.

**Not a symbol (mechanical / no schematic part):**
- Masach **MS643** shield can → footprint/mechanical only.
- Mean Well **LRS-50-12** → off-board; represented by the Mini-Fit input connector `J301` + power flags, no IC symbol.
- Trenz **33337** heatsink, gap pad, chassis, FPE panels, standoffs → mechanical.

---

## Footprint note (separate pass)

Symbols are done; **footprints** are the next pass. Assignments for the four built symbols:

| Symbol | Footprint to assign | Source |
|---|---|---|
| `NHD-2.9-376960AF-ASXP` | **Molex 54104-4031** — 40-ckt, 0.5 mm, **top-contact** FFC/FPC connector (this is what solders to the board; the panel flex plugs into it) | KiCad `Connector_FFC-FPC` (Molex 54104) if present, else SnapEDA |
| `NHD-1.5-240240AF-CSXP` | **Molex 5051102891** — 28-ckt, 0.5 mm FFC/FPC connector | KiCad `Connector_FFC-FPC` (Molex 505110) if present, else SnapEDA |
| `FN9260B-6-06` | **No PCB footprint** — chassis/panel-mount IEC inlet with 6.3×0.8 mm fast-on spade tabs. Wired, not soldered. Mark **exclude-from-board** (same treatment as the LRS-50 PSU). | n/a |
| `NFM21_Feedthrough` | Murata **NFM21 3-terminal feedthrough** land (2012/0805 body, signal IN/OUT + ground castellations) — **not** a 2-pad 0805 | Murata land pattern / SnapEDA |

**FFC note:** the symbol pin numbers map 1:1 to the FFC connector pads. Top- vs bottom-contact determines which way the panel flex folds — confirm the Molex contact side matches the mechanical layout before ordering.

Still-custom footprints elsewhere (separate from symbols): TE0720 Razor Beam land (Samtec LSHM), Molex 73101-0120 BNC, Amphenol 10029449 HDMI, Masach MS643 can outline, LWB5+ castellated module. Stock footprints cover generic passives, headers, SOT/SOIC/QFN ICs, USB-C, SMA/u.FL.

---

## Suggested order of operations

1. **All symbols resolved.** Custom builds live in `_PROJECTS/_KiCad/Schindler.kicad_sym` (4 symbols); the rest are in JustinLibrary or stock.
2. **Confirm the 🔎 VERIFY list** in the Symbol Chooser (fast); SnapEDA-fill any misses. **Point the project lib-table at JustinLibrary** so the ✓lib parts resolve.
3. **Confirm the ⚠ TE0720 -03 vs -04 pinout** before trusting the existing symbol on the live carrier.
4. ✅ STOCK parts need nothing.
5. Only then run a placement pass — every symbol must resolve to a library entry or KiCad drops it.

Once the ADD list is filled, capture (or any scripted placement) has a complete symbol set to resolve against.

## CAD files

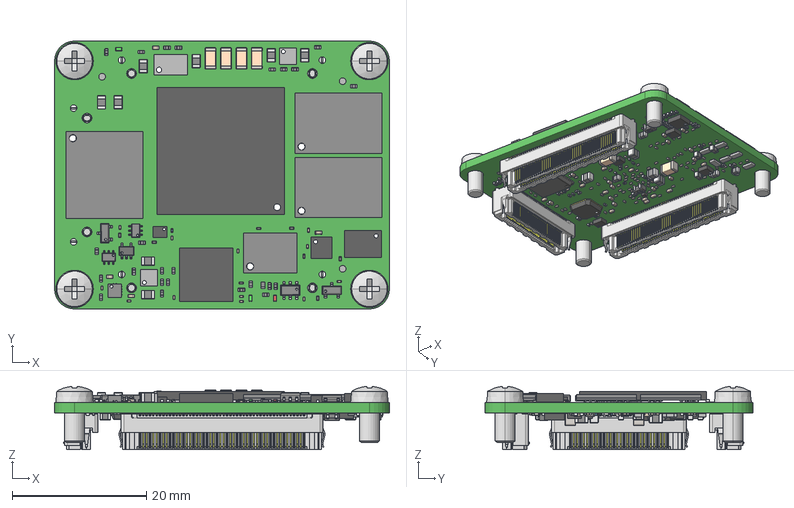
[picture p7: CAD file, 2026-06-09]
KiCad/Reference Files/BOM Docs/STP-TE0720-04-No Variations.step
50.0 x 40.0 x 9.43 mm
Extruded x 41
RES_0603-0201 x 27
User_Library-SMD_0201_CAPACITOR x 116
User_Library-SMD_CAPACITOR0402 x 31
User_Library-CAPC3216X___CAPC3216X180N x 6
SW3dPS-YC124 x 6
led_0402-red
led_0402LED0402_green x 2
User_Library-SOT353-1
User_Library-QFN32
_STRLSHM-30-04.0-DV-A-S
_C-185--30-04.0-DV1P
User_Library-QFN56_(8x8)
_STRLSHM-50-04.0-DV-A-S x 2
_C-185--50-04.0-DV1P x 2
622173x6 x 4
User_Library-SOT323_(SC70-3)-1_K_X_F6rper_1 x 2
User_Library-SOT323_(SC70-3)-1_Beschriftung_1 x 2
User_Library-SOT323_(SC70-3)-1_Pins_1 x 6

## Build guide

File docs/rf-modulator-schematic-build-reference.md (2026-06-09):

# RF Modulator Daughter Board — Schematic Build Reference (KiCad)

**Status:** Capture guide, 2026-06-07. Build the schematic in Eeschema, assign footprints, then **Update PCB from Schematic (F8)** — that is the live link the netlist-only path was missing. Net-level source of truth is the verified connection table in [`rf-modulator-schematic-skeleton.md`](rf-modulator-schematic-skeleton.md); this doc is the capture order + symbol/footprint sourcing.

---

## 0. Why schematic-first

A SKiDL/imported netlist is a one-shot seed with nothing behind it to re-sync. The schematic is KiCad's source of truth: assign footprints on the symbols, press F8, and the board stays in lockstep with the schematic forever after. The SKiDL netlist (`rf_mod_daughter.net`) is kept only as a **connectivity cross-check** (see §7).

---

## 1. Symbol + footprint sourcing (do this first)

The three RF ICs are **not** in stock KiCad — pull a matched symbol+footprint pair for each (SnapEDA / Component Search Engine / Ultra Librarian, search the exact P/N). That is the real fix for the "footprint not found" errors. Everything else is stock.

| Ref | Part | Symbol | Footprint |
|---|---|---|---|
| U1 | Si5351A-B-GT | **import** (SnapEDA P/N) | MSOP-10; matched, or stock `Package_SO:MSOP-10_3x3mm_P0.5mm` |
| U2 | ADL5391ACPZ | **import** | **LFCSP-16, 3×3 mm, 0.5 mm pitch, ~1.5 mm EP** (matched; *not* 4×4/0.65) |
| U3 | ERA-3SM+ | **import** / draw 4-pin | **Mini-Circuits WW107** land pattern (MCL supplies it) — do **not** substitute SOT-89 |
| U4 | 12→5 V LDO | `Regulator_Linear` generic | per chosen part (see §5 note on dissipation) |
| Y1 | 25 MHz xtal | `Device:Crystal` (2-pin) | per your crystal package |
| RV1 | 10k trim 3296W | `Device:R_Potentiometer` | `Potentiometer_THT:Potentiometer_Bourns_3296W_Vertical` |
| FL1 | BPF 56–73 MHz | *capture as discrete L/C* (§4) | none yet — topology TBD, leave unplaced |
| J1 | interconnect hdr | `Connector_Generic:Conn_01x06` | `Connector_PinHeader_2.54mm:PinHeader_1x06_P2.54mm_Vertical` |
| J2 | U.FL composite in | `Connector:Conn_Coaxial` | `Connector_Coaxial:U.FL_Hirose_U.FL-R-SMT-1_Vertical` |
| J3 | F-connector out | `Connector:Conn_Coaxial` | panel F-connector — custom/verify |
| D1 | PESD3V3L1BA TVS | `Device:D_TVS` | `Diode_SMD:D_SOD-323` |
| R1–R8 | resistors | `Device:R` | `Resistor_SMD:R_0805_2012Metric` |
| C1–C11 | caps | `Device:C` | `Capacitor_SMD:C_0805_2012Metric` (C10/C11 = 10 µF — 0805 OK or bump to 1206) |
| L1, L2 | inductors | `Device:L` | `Inductor_SMD:L_0805_2012Metric` (L2 = 0805CS-152, 0805 land) |

---

## 2. Sheet setup

Single sheet is fine (small board). Set the title block (project = Schindler 2.0, sheet = RF Modulator Daughter Board, rev/date). Add your imported libraries (Preferences → Manage Symbol/Footprint Libraries → project-specific).

---

## 3. Capture order, by block

Place symbols, then wire nets. Pin numbers are the verified datasheet pinouts. Use net labels (not long wires) for the rails and the carrier/video/output nets — it keeps the sheet readable.

### Block A — Power in & rails
- **J1**: 1 P12V · 2 P3V3 · 3 SDA · 4 SCL · 5 GND · 6 GND
- **U4 LDO**: VIN ← +12V · GND → GND · VOUT → +5V
- **+12V** = J1·1, U4·VIN, R4·1, C10·1
- **+3V3** = J1·2, U1·1 (VDD), U1·7 (VDDO), R7·1, R8·1, C7·1
- **+5V** = U4·VOUT, U2·2/3/4 (VPOS), U2·15 (ENBL), RV1·1, C8·1, C11·1
- **GND** = J1·5/6, U4·GND, all decap grounds, and the per-block grounds below
- Add **PWR_FLAG** to +12V, +5V, +3V3, GND (or ERC will flag "no driver").

### Block B — Clock generator (U1 + Y1 + I²C)
- **Y1**: across U1·2 (XA) and U1·3 (XB)
- **SDA** = J1·3, U1·5, R7·2 (pull-up to +3V3)
- **SCL** = J1·4, U1·4, R8·2
- U1·1/7 → +3V3, U1·8 → GND, C7 decoupling
- **CLK0 (U1·10)** → CARRIER_SQ · **CLK1 (U1·9)** → PILOT
- **U1·6 (CLK2)** → place a **no-connect** flag (unused)
- Note: 10-MSOP has no A0 → I²C addr fixed **0x60**; this must be its own I²C segment vs the genlock Si5351.

### Block C — Carrier LPF + modulator (U2)
- **CARRIER_SQ** = U1·10, L1·1, C2·1  *(L1/C2/C3 = LPF1, recover sinusoid from the square clock)*
- **CARRIER_SIN** = L1·2, C3·1, U2·13 (XPLS)
- **COMP_IN** = J2·1 (SIG), C1·1     **VIDEO_Y** = C1·2, R1·2, U2·11 (YPLS)
- **RV1** wiper (pin 2) → R1·1 (sets Y DC-bias / mod depth); RV1·1 → +5V, RV1·3 → GND
- **VMID** = U2·16 (VMID), U2·12 (YMNS), U2·14 (XMNS), U2·9/10 (Z), U2·6 (WMNS), C9·1; C9·2 → GND
- U2·2/3/4 → +5V · U2·1/7 (COMM) + EPAD → GND · U2·15 (ENBL) → +5V
- **U2·8 (GADJ)** → **no-connect** flag (open = α 1, unity gain)
- **MOD_OUT** = U2·5 (WPLS), R2·1
- (Bench item, not wiring: 56.2 Ω input match on the X carrier input; AM-with-carrier method — DC-bias Y vs inject via Z. See skeleton §4.)

### Block D — Combiner + BPF
- **PILOT** = U1·9, R3·1
- **COMB_NODE** = R2·2, R3·2, FL1·IN
- **FL1 (BPF)**: topology TBD until harmonics measured — capture as a labeled 2-port stub or a small hierarchical sheet and **leave it without a footprint** for now. It won't block the rest of the board from pushing to PCB; you backfill the discrete L/C once measured.
- **BPF_OUT** = FL1·OUT, C4·1 (Ca)

### Block E — Amplifier + 75 Ω output
- **AMP_IN** = C4·2, U3·1 (RF-IN)
- ERA-3 bias: +12V → **R4 (240 Ω)** → **BIAS_MID** → **L2 (1.5 µH choke)** → AMP_OUT
- **AMP_OUT** = U3·3 (RF-OUT+DC), L2·2, C5·1 (Cb)
- U3·2/4 → GND
- **MLP_IN** = C5·2, R5·1 (43 Ω) · **MLP_OUT** = R5·2, R6·1 (82 Ω), C6·1 (Cc); R6·2 → GND
- **RF_OUT** = C6·2, D1·1 (TVS), J3·1 (SIG); D1·2 → GND; J3 shell → GND

---

## 4. ERC checklist
- PWR_FLAG on every rail (+12V, +5V, +3V3, GND).
- No-connect flags on **U1·6 (CLK2)** and **U2·8 (GADJ)**.
- U2 exposed pad → GND (the imported symbol should expose an EP/pin 17; if not, tie the pad in the footprint).
- Run ERC clean before assigning footprints.

## 5. Footprints + push to PCB
- Assign footprints (Tools → Assign Footprints / they come pre-bound on the imported IC symbols).
- **U4 dissipation note:** ADL5391 draws ~130 mA at 5 V; a linear 12→5 V drop burns ~0.9 W. Size the LDO package (SOT-223/DPAK + copper) accordingly — or, if you'd rather, add a 5 V wire to the J1 interconnect and delete U4 + its heat entirely (one extra conductor vs. a hot regulator on a small board). Bench call.
- **Tools → Update PCB from Schematic (F8)** to push to the board. This is the sync that was missing.

## 6. Cross-check against the SKiDL netlist
After capture, Eeschema → export netlist, and diff against `rf_mod_daughter.net` (the verified skeleton) to catch any transcription miswires before you route.

## 7. Cross-references
- Verified pinouts + full net table + SKiDL source: [`rf-modulator-schematic-skeleton.md`](rf-modulator-schematic-skeleton.md)
- Partition / interconnect rationale: [`rf-modulator-daughter-board-option.md`](rf-modulator-daughter-board-option.md)
- Parts spec + BOM: [`rf-modulator-subsystem.md`](rf-modulator-subsystem.md)

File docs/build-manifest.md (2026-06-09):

# Schindler Build Manifest

> **New to the project?** Start at [`wiki/START-HERE.md`](wiki/START-HERE.md). This manifest is the live build ledger; the wiki has the conceptual map. Both are canonical for different things.

**Status:** living document. Source of truth for **which builds exist, which ones produce a clean image, and what's broken.** Pairs with [`format-support-matrix.md`](format-support-matrix.md) — that doc tracks **format axis** (what input→output combos), this doc tracks **build axis** (what bitstream lineage).

Last updated: 2026-05-31 (44 commits this day — see HISTORICAL-NARRATIVE for the long form). Headline events: iter5-1080p-clean promoted ⚠️→✅; HDMI compliance rule + 1080p60 silicon limit on Zybo Z7-20; V0a control plane shipped end-to-end (catalog v0.2.0 + firmware J + schindlerd + browser UI); V0a+1 polish (status push, version handshake, multi-client, factory profiles); V0a+2 hardening (auth scaffold, multi-client throttle, profile schema + version-mismatch reject, catalog version derived from build, KERNEL_GPIO_INDEX parameterization); 7-agent re-audit absorbed into 5 follow-up bundles; iter13c backported to mackin + phase-e1; test harness from 0 → 78 tests + make ci + make sim + make sim-vivado + make web-smoke all green.

## Why this document exists

Justin 2026-05-21: "If you cant look at any particular build and identify whether that build passes clean image, we have failed somewhere. Every build should be snapshotted and recreateable. every snapshot should have clear notes on IS THIS BUILDABLE. If not, why, and what is broken."

Memory entries claiming `SHIPPED` or matrix entries claiming `✅` are **point-in-time observations**, not live state. This document is the live state.

## How to use this document

- Before bench-testing: look up the substrate row. If status is anything other than `✅ CLEAN (verified <date>, N boots)`, **do not bench-test other features on it** — see memory `schindler-no-coin-flip-rule`.
- After every build + bench session: update the relevant row (or add a new one).
- Bench claims require: explicit reboot count, explicit modes tested, explicit symptom if any.

## Legend

**Buildable:**
- `✅` — verified buildable today (clean run, .bit + .xsa + .elf produced, exit 0)
- `⚠️` — last build OK but source may have drifted since (e.g., uncommitted edits, dep changes)
- `❌` — known to fail at build time (specify which stage)
- `?` — never tried or no evidence on disk

**Bench-image (1080p60 input passthrough/scaling, the primary regression-detection mode):**
- `✅ CLEAN` — phase-correct picture, stable across ≥3 reboots, on date in cell
- `⚠️ LUCKY-BOOT` — appeared clean at least once but coin-flip not ruled out
- `❌ COIN-FLIP` — stable horizontal tear (vsync phase coin-flip per memory `schindler-phase-d-vsync-phase`)
- `❌ SCROLL` — slow vertical scroll (per memory `schindler-iter5-bisect-findings`)
- `❌ OTHER` — see notes
- `?` — never bench-tested or no recent bench evidence

---

## Branches snapshot — 2026-05-30 (current)

> 2026-05-21 snapshot retained below as historical record.

Live tips as of 2026-05-30 walk of `git branch -a` + `git log`:

| Branch | Tip | Date | Buildable | Bench-image | Notes |
|---|---|---|---|---|---|
| `main` | `045f09b` | 2026-05-16 | ? | ? | Cold storage — frozen at pre-iter5. **GitHub default branch flipped to `iter5-1080p-clean` 2026-05-31.** Will force-update at v1 ship; don't target until then. |
| `iter5-1080p-clean` | `abb83e8` | 2026-05-31 | ✅ Vivado+Vitis 2026-05-31 | ✅ CLEAN (verified 2026-05-31, iter12+13+13b 3-reboot rule satisfied; iter14 hands-on verified across 3 Osee sources) | **PRODUCTION SUBSTRATE / EFFECTIVE MAIN.** GitHub default branch as of 2026-05-31. iter4d-3 + 1080p substrate + color stack + iter6 S2MM hardware fsync + iter12 (H 2-tap `(s_axis_tdata + window[0])/2`) + iter13 (V 2-tap `(tap2 + tap3)/2`) + iter13b (+1 round-to-nearest) + iter13c (lbuf_fresh emit suppression) + iter14 (runtime kernel-mode toggle via UART `k h/v <0-3>`). Auto-archive system live. |
| `mackin-impl-wip` | `fedb51a` | 2026-05-24 | ✅ Vivado+Vitis 2026-05-24 | ⚠️ LUCKY-BOOT-fingerprint (DDR3 byte dump matches iter5; no end-to-end picture test — placeholder axis_clone wiring still in place) | iter12+13 backport on `4b8067e` + dump_slot_head_pixels diag firmware on `fedb51a`. Pushed to origin. **Mackin blender still placeholder until dual-VDMA bench wiring lands.** |
| `phase-e1-pll-spike` | `81df37b` | 2026-05-24 | ✅ Vivado+Vitis 2026-05-30 | ⚠️ LUCKY-BOOT (1 boot, monitor-clean under ImagePro diagonal 2026-05-30 — no 3-boot rule yet) | iter12+13 backport (`78ee7ad`) + `F` UART command for live framebuffer dump (`81df37b`). MMCM tracking loop active; ±500 ppm tracking range per `[[schindler_phase_e1_state]]`. Pushed to origin. |
| `phase-g-iter1` | `d94f6cb` | 2026-05-21 | ⚠️ (Vivado not re-run since 2026-05-21) | N/A | ADV7393 BD + Si5351 Phase A-D firmware. **All 9 commits of Si5351 progression** (Phase A→B→C-lite→D-WIP) pushed to origin 2026-05-30. Both ADV7393 and Si5351 are hardware-blocked (chips dead/marginal). |
| `iter5-bisect-720p` | `81e17a8` | 2026-05-17 | ? | ⚠️ LUCKY-BOOT | **ARCHIVED 2026-05-31** via tag `archive/iter5-bisect-720p`. Forensic — the bisect endpoint that proved iter4h structurally wrong. Keep for archaeology; don't ship from. |
| `iter4h-axis-fifo` | `7d5fe09` | 2026-05-17 | ? | ❌ SCROLL | **ARCHIVED 2026-05-31** via tag `archive/iter4h-axis-fifo`. **DO NOT USE.** S2MM VSIZE=747 caused 1-row-per-frame scroll. Forensic only. |
| `iter5-wip` / `iter4f-wip-pattern-diag` / `iter4g-counter-infra` | various | May 16-17 | ? | various | **ARCHIVED 2026-05-31** via tags `archive/<name>`. Abandoned WIPs / forensic. |

### G1 adjustable-scaler builds (on `iter5-1080p-clean`) — 2026-06-01

| Commit | Buildable | Bench-image | Notes |
|---|---|---|---|
| `ffcd4ce` | ✅ Vivado+Vitis (sim no-regression) | ✅ CLEAN at default | G1 runtime output-size in `scaler_h`/`scaler_v`/`scaler_top`. Bit-identical to pre-G1 at out=1280×720. **Wrong layer** for geometry per agreed design — will be reverted/repurposed by the route-B redesign. Harmless as-is. |
| `64aabe6` | ✅ Vivado+Vitis (WNS +0.150, DRC 0) | ❌ OTHER — **HDMI goes BLACK on any sub-full geometry** | G1 BD size-GPIO (`axi_gpio_8`) + firmware `scaler_reframe`. **DEAD-ON-ARRIVAL, DO NOT USE.** `scaler_reframe` stops/reconfigs S2MM VSIZE to the sub-window → diverges from MM2S 720 → dynamic-genlock handshake breaks → "No Signal." DDR framebuffer is correct (frame-dump good); only the genlock output leg dies. Full-size reset recovers. Reachable only via raw `J` (geometry controls NOT in catalog/UI) so the live bench is safe at full passthrough. Full root cause: [`g1-bench-finding-genlock.md`](g1-bench-finding-genlock.md). Redesign → post-color output compositor (route B). |

**2026-05-31 — Phase 4 of Direction A: branch retirement (tag-only):** Five stale branches tagged as `archive/<name>` and remain on origin (not deleted). Branches stay visible in `git branch -a` but are marked dead in this manifest. Use the tags to recover history if ever needed.

Active branches going forward (4):
- `main` — cold storage (pre-iter5)
- `iter5-1080p-clean` — **production substrate**
- `mackin-impl-wip` — temporal blender (placeholder wiring)
- `phase-e1-pll-spike` — MMCM tracking spike
- `phase-g-iter1` — analog out (hardware-blocked)

## Branches snapshot — 2026-05-21 (historical)

Original walk of `git branch` 2026-05-21 16:30, retained for archaeology. **DO NOT USE FOR CURRENT WORK** — see 2026-05-30 table above.

| Branch | Tip | Date | Buildable | Bench-image | Notes |
|---|---|---|---|---|---|
| `main` | `045f09b` | 2026-05-16 | ? | ? | Merged PR#3 = iter4g-counter-infra. Pre-iter5. Never tested on current bench. Treat as cold storage. |
| `iter4f-wip-pattern-diag` | `383f173` | 2026-05-16 | ? | ? | Abandoned WIP. Re-added scaler_v row-index test pattern for artifact diag. Not a production candidate. |
| `iter4g-counter-infra` | `14a693e` | 2026-05-16 | ? | ? | Per-stage counter infrastructure. Bug narrowed but not fixed at branch close. See memory `schindler-phase-d-iter4g-state`. |
| `iter4h-axis-fifo` | `7d5fe09` | 2026-05-17 | ? | ❌ SCROLL | iter4h S2MM VSIZE=747 + AXIS FIFO + c_flush_on_fsync=1. Later proved **structurally wrong** by iter5-bisect — caused 1-row-per-frame scroll. **DO NOT USE.** See memory `schindler-iter5-bisect-findings`. |
| `iter5-wip` | `f5a9aa6` | 2026-05-17 | ? | ❌ SCROLL | Pre-bisect iter5 attempt with iter4h additions still present. Same scroll bug. Superseded by `iter5-bisect-720p`. |
| `iter5-bisect-720p` | `81e17a8` | 2026-05-17 | ? | ⚠️ LUCKY-BOOT | The bisect endpoint — iter4d-3 restoration with iter4h additions stripped AND iter3i +STRIDE shift dropped. Claimed CLEAN at 2026-05-17 bench but pre-dates the no-coin-flip rule. **Status: UNTESTED under multi-reboot methodology.** |
| `iter5-1080p-clean` | `f97da45` + iter6 WIP (uncommitted) | 2026-05-22 | ✅ (verified 2026-05-22 15:16) | ⚠️ LUCKY-BOOT (1 boot, iter6 applied) | Tip = iter5-bisect-720p + 1080p substrate + color stack + iter6 S2MM fsync fix. **2026-05-22 ~15:20 bench on 1080p60→720p60: monitor CLEAN, DDR3 dump confirms no leak.** Needs ≥3 cold-boot re-validation + motion-source test + commit before promoting to CLEAN. See "2026-05-22 — iter6" section below. |
| `mackin-impl-wip` | `aff2c43` | 2026-05-18 | ? | ? | Mackin HDL + sim suite (3360/3360 PASS) + placeholder axis_clone wiring. Sim is golden; bench placeholder validated by UART roundtrip only. Dual-VDMA real wiring deferred. **No clean-image bench-validation under no-coin-flip rule.** |
| `phase-e1-pll-spike` | `54a464d` | 2026-05-20 | ? | ? | Phase E1 MMCM tracking work. Memory `schindler-phase-e1-state` claims "Phase E1 SHIPPED 2026-05-19" at `42fe057` — tip has moved since with experiments. **Tip status uncertain; ship-point may be earlier commit.** Untested under no-coin-flip rule. |
| `phase-g-iter1` | `d94f6cb` | 2026-05-21 | ⚠️ (likely; ADV7393 BD + Si5351 BD) | N/A | Today's WIP commit on top of Phase G ADV7393 + Phase E2 Si5351. Both BLOCKED on hardware (chips dead, replacements ordered). No video-path regression — Phase G isn't about image quality. |

---

## Bitstream artifacts on disk — 2026-05-21 16:30

Only artifacts newer than the 2026-05-11 `schindler-2.0.bit` baseline. All sized 4045694 bytes (Zynq-7020 standard).

| Path | Mtime | Branch when built | Commit | Status |
|---|---|---|---|---|
| `build/vitis-phase-b/phase_b_pf/export/phase_b_pf/hw/phase_b.bit` | 2026-05-21 16:25 | `iter5-1080p-clean` | `f97da45` | Today's rebuild. Tested at bench → COIN-FLIP at 720p60 output. |
| `build/vitis-phase-b/vdma_init/_ide/bitstream/phase_b.bit` | 2026-05-21 16:25 | same | same | Same .bit, Vitis duplicate. |
| `build/vitis-phase-b/phase_b_pf/hw/phase_b.bit` | 2026-05-21 16:24 | same | same | Same .bit, Vitis duplicate. |
| `build/phase-b-vdma-passthrough/phase-b-vdma-passthrough.runs/impl_1/phase_b_bd_wrapper.bit` | 2026-05-21 16:23 | same | same | Source bitstream from Vivado impl_1 run. Same content. |
| `build/phase_b.bit` | 2026-05-18 01:41 | `iter5-1080p-clean` | `7af40e1` | Previous build, **older by one commit** (firmware-only diff to current `f97da45`). Bitstream identical. Pre-2026-05-21 build evidence — **untested under no-coin-flip rule**. |

**All other older .bit/.xsa on disk:** Phase A (`schindler-2.0.bit`, 2026-05-11), Phase-TPG, ila-capture-victory builds, etc. **None are current production candidates.** Listed in `git log` archaeology, not regularly maintained.

---

## Current bench state — 2026-05-21

**Loaded on FPGA:** `iter5-1080p-clean` @ `f97da45` (today's rebuild, programmed via XSCT at 16:25).

**Last bench observation 2026-05-21 16:27:** SMPTE-like color bars from ImagePro fed as 1080p60 → output to bench monitor at 720p60 with scaler. Stable horizontal/vertical offset mid-screen — top half shifted relative to bottom half. Initially suspected vsync-phase coin-flip.

**EOLLate** flag set every frame on S2MM_SR.

**2026-05-21 ~17:00 follow-up (cold-boot from QSPI ×3):** offset is **DETERMINISTIC** — identical offset across 3 cold boots. **Rules out vsync-phase coin-flip** from [[schindler-phase-d-vsync-phase]] (that one is random per boot). This is a different, systematic bug. Three candidate root causes under investigation:

1. **EOLLate-driven buffer offset.** S2MM stalls per frame → row pointer rolls forward by fixed N → consistent offset.
2. **Firmware VTC alignment off by deterministic delta.** Boot prints "VTC aligned to source vsync" but the math may miss by a fixed line count.
3. **Scaler pipeline latency unaccounted.** v_v polyphase warmup (4-8 input rows) shifts the first valid output line; if VTC TX starts before that warmup completes, the picture is offset by exactly that amount every boot.

Next probe: read S2MM_SR + MM2S_SR over many frames to characterize EOLLate cadence; check firmware vtc_setup() for the alignment math; compute expected scaler latency vs. VTC TX start.

**Status on builds in QSPI:** unknown which commit was last `program_flash`'d. Boot was from QSPI, shows similar offset → strongly suggests the bug pre-dates today's rebuild and exists in whatever-was-burned-last. Likely the same `iter5-1080p-clean` lineage. **No "previously known clean" build is currently identifiable** — all candidates are now suspect.

**2026-05-21 ~17:30 — Critical re-read of session record.** Mining `tests/phase-e1/` session docs (`phase0_baseline.md`, `phase_e2_bench_session_2.md`) reveals:

1. **`phase_e2_bench_session_2.md` documented this exact bug** as a product-blocker on 2026-05-20: *"the picture shows the same vertical wraparound pattern... Top of one frame fills the upper ~80% of screen; bottom ~20% shows the top of the next frame. This is a product-blocker failure mode."* Bug was diagnosed but **never resolved** — Phase E2 was abandoned at that point and work pivoted elsewhere.

2. **Root cause per that session doc:** VTC TX alignment is run once at boot via `wait_for_aligned_source_vsync()` but has a deterministic offset of ~120 lines at 720p50. PI rate-only controller cannot fix phase offset. Phase E2 session 2 author proposed two fixes (discrete phase jump via VDMA park-pointer write at SOF, OR re-run alignment after `r src` ref-switch) but neither was implemented.

3. **MS2109 verification trap.** Per [[schindler-ms2109-masks-artifacts]], MS2109 capture stick has its own framebuffer that absorbs vertical-wraparound artifacts. Builds previously stamped "PASS" or "✅" that were verified via MS2109 capture may NOT have been clean on the bench monitor. **Justin's report 2026-05-21 ~17:25:** "I am seeing things on the monitor I didnt see in the usb capture, which means I cant trust my own 'good'." All prior PASS claims now require re-verification on monitor specifically.

4. **Phase 0 baseline (`d71c994`, 2026-05-18 22:14)** claimed PASS with WNS +0.389 / WHS +0.013. May or may not be monitor-verified — phase0_baseline.md says "user-reported 'completely clean'" without specifying which display. Treat as ⚠️ pending re-verification under no-MS2109 rule.

5. **Phase A (`top_phase_a.bit`, branch `phase-a-hdmi-passthrough` era, 2026-05-13)** is architecturally incapable of having this bug. No DDR3 buffer, no scaler, no separate output clock — output vsync IS recovered source vsync. Phase A doc explicitly states "validated stable at 1920×1080@60p ... → external monitor." Monitor-verified PASS. WNS +0.23 / WHS +0.06. **This is the substrate to return to as ground truth.**

## Revised plan: bisect from Phase A forward

Walk forward from Phase A one architectural change at a time, monitor-verified at each step:

| Step | Substrate | What it adds | Should expose bug if it's in this layer |
|---|---|---|---|
| A | Phase A passthrough | nothing — direct dvi2rgb→rgb2dvi | (baseline — must be clean) |
| B0 | Phase B VDMA passthrough | DDR3 buffer in path (S2MM + MM2S, both at source clock) | Tests DDR3 / VDMA ring without rate mismatch |
| B1 | Phase B + scaler | scaler_top in path | Tests scaler latency/sync |
| B2 | Phase B + scaler + output MMCM | separate output pixel clock | Tests rate-domain crossing — likely where offset originates |
| D | iter4d-3 substrate | + FRC dynamic genlock | Tests Dynamic Genlock alignment |

At each step: cold-boot ≥3 times, eyeball bench monitor (not MS2109), document outcome here. Stop bisect at first step that introduces the offset → root cause localized to that layer.

---

## 2026-05-21 17:18 — Phase A confirmed clean on NEW MONITOR

**The previous bench monitor had a fault.** Justin moved to a different monitor and re-loaded today's Phase A rebuild (commit `89f3eff` at `build/phase-a-hdmi-passthrough/phase-a-hdmi-passthrough.runs/impl_1/top_phase_a.bit`, WNS +0.229 / WHS +0.060). Source: ImagePro 1080p60. Result: **clean passthrough confirmed monitor-verified.**

**Implications:**
- **All today's bench observations on the prior monitor are tainted by monitor fault.** Today's iter5-1080p-clean "horizontal tear" and "deterministic 20-30 line offset" findings may have been monitor-driven artifacts on a faulty display, not real bugs in the iter5 substrate.
- The QSPI-boot "flickering and offset" observation also tainted by old monitor.
- **Until each candidate build is re-verified on the new monitor, NO conclusions about iter5/Phase E/iter4 substrate quality from today's session are trustworthy.**
- The Phase A baseline is solid. WNS reproducible, bitstream produces clean output on a known-good monitor.

**Lesson banked:** when bench observations don't match HDL/architectural expectations, suspect bench equipment (monitor, cable, source) BEFORE rebuilding/reverting. The MS2109 verification trap had a sibling: the monitor itself can be a confounder.

**Re-verification queue under new monitor:**
| Build | Was reported as | Re-test |
|---|---|---|
| Phase A (`89f3eff`) | ⚠️ flicker (old monitor) → ✅ CLEAN (new monitor, 2026-05-21 17:18) | DONE — baseline holds |
| iter5-1080p-clean (`f97da45`) | ❌ tear (old monitor) → **❌ flicker + EOLLate (new monitor, 2026-05-21 17:35)** | DONE — real bug, not monitor |
| iter4d-3 (`d71c994`) | claimed clean 2026-05-18 | Untested today |
| Each other candidate | various | Untested today |

## 2026-05-21 17:35 — iter5-1080p-clean confirmed broken on NEW MONITOR

Re-programmed today's iter5-1080p-clean rebuild (.bit from 16:24, ELF from 16:25) on the new monitor. **Flicker is still present.** UART telemetry confirms:
- `S2MM_SR=0x0001D000[FrmCnt EOLLate frmcnt=1]` set EVERY FRAME
- `MM2S_SR=0x00011000[FrmCnt frmcnt=1]` clean
- `PHASE deltas={1,1,1,...}` — 1:1 matched rate (no FRC active)
- `RDSTORE=0 WRSTORE=0` — parked (WRSTORE reads-as-0 per `xilinx-vdma-dmasr-bits`)
- Source detected at 1920×1080, scaler programmed IN_W=1920 IN_H=1080
- Output VTC = 720p60 (firmware default; scaler downscale 1080→720 active)

**Diagnosis:** EOLLate every frame = S2MM AXI write side reports it couldn't end-of-line in time. This is a real pipeline issue, not the prior monitor's confound. The scaler→S2MM path has a back-pressure or sync issue that's been there since at least 2026-05-18.

**Visual evidence:** `~/Pictures/Webcam/2026-05-21-173328.jpg` (Dell monitor, ImagePro SMPTE bars source) — shows the iter5-1080p-clean failure mode: SMPTE bars with **multiple horizontal discontinuity bands** at fixed positions, bars not aligned across split lines. Consistent with EOLLate-driven row-pointer drift creating cumulative within-frame offsets at specific scanlines. Canonical reference image for this bug.

## 2026-05-21 17:40 — ROOT CAUSE HYPOTHESIS: scaler/firmware config mismatch

Reading `tcl/build_phase_b.tcl` line 304-305: `SCALER_MODULE` env var default is **`scaler_bypass_1080p`** (introduced in iter5; pre-iter5 default was `scaler_top`).

`scaler_bypass_1080p` is a **no-op pass-through** — output dimensions equal input dimensions. With 1080p60 input, it delivers 1920×1080 frames downstream.

Firmware `main.c` line 1180 default: `MODE_720P60` — configures VTC TX for 1280×720 timing AND configures VDMA S2MM/MM2S with HSIZE=3840 (1280×3 bytes) and VSIZE=720.

**These are incompatible:**
- Data path: 1920×1080 per frame (5760 bytes/line × 1080 lines)
- VDMA S2MM expectation: 1280×720 per frame (3840 bytes/line × 720 lines)
- S2MM sees end-of-line at byte 3840 but pixel data keeps streaming → **EOLLate every frame** (matches UART observation)
- The visible flicker = S2MM corrupting frame buffers because its line/frame boundaries don't match what the data delivers

This appears to be **a regression that landed during iter5** when someone flipped the SCALER_MODULE default from `scaler_top` to `scaler_bypass_1080p` to test 1080p paths, but the firmware MODE default was never updated to match. Format-matrix Row 2 ✅ entry explicitly references `scaler_top` — that combination was the validated one.

**Two paths to fix (next iteration):**
- **A.** Rebuild with `SCALER_MODULE=scaler_top` → restores the matrix-validated combination (1080p60→720p60 with real downscale). Same firmware works.
- **B.** Change firmware mode to `MODE_1080P30` or `MODE_1080P24` → matches `scaler_bypass_1080p` no-op (1080p frames end-to-end, FRC on rate axis only). Different test path.

A is the "back to known-good config" iteration. Doing it first.

## 2026-05-21 18:00 — Iter1: SCALER_MODULE=scaler_top result

**Build:** branch `iter5-1080p-clean` @ `f97da45`, `SCALER_MODULE=scaler_top vivado -mode batch -source tcl/build_phase_b.tcl`. WNS=-3.747 / WHS=+0.014 (timing closure same character as previous color-stack-async-CDC build — ASYNC_REG mitigated). Bitstream 17:57, ELF 17:58, programmed 17:58.

**UART telemetry verdict: substrate is healthy.**
```
DIAG: px=1080 lines=1080 maxpx=720 mm2s=0  S2MM_SR=0x00011000[FrmCnt frmcnt=1] MM2S_SR=0x00011000[FrmCnt frmcnt=1]  RDSTORE=2 WRSTORE=3  src=59 out=60
PHASE: deltas[12]={1,1,1,1,1,1,1,1,1,1,1,1}
```
- **EOLLate eliminated** (was 0x0001D000, now 0x00011000). Real win — confirms config-mismatch hypothesis.
- Both S2MM and MM2S status registers clean every frame.
- VDMA Dynamic Genlock pointers cycling (RDSTORE=2, WRSTORE=3).
- Source rate matched 1:1 (PHASE deltas all 1).
- Full UART capture: `Images/2026-05-21_iter1_scaler_top_uart.log`

**Visual verdict on bench monitor (via Brio webcam /dev/video10): STILL BROKEN, but DIFFERENTLY.**

Three webcam captures across ~3 sec each show different content positions:
- Frame 030: `Images/2026-05-21_iter1_scaler_top_frame030.jpg` — yellow rectangles lower-right
- Frame 090: `Images/2026-05-21_iter1_scaler_top_frame090.jpg` — yellow rectangles upper-left
- Frame 150: `Images/2026-05-21_iter1_scaler_top_frame150.jpg` — yellow gone, small dark blocks on left

**SMPTE bar features are DRIFTING across screen.** This is the vertical wraparound + slow phase drift bug documented in `tests/phase-e1/phase_e2_bench_session_2.md` (2026-05-20). It was always present in iter5-1080p-clean — the prior EOLLate was just SO bad that it masked the wraparound visually.

**Net iter1 result:**
- ✅ EOLLate root cause confirmed and fixed (config-mismatch: SCALER_MODULE=scaler_bypass_1080p default mismatched MODE_720P60 firmware default; using scaler_top restores matrix-validated combination)
- ❌ Vertical wraparound + drift persists (a SECOND bug, documented Phase E2 product-blocker, not fixed by this iteration)

The drift implies output VTC vsync is not phase-locked to source vsync — output rate is *averaged* close to source (deltas=1) but absolute phase is sliding. Per `tests/phase-e1/phase_e2_bench_session_2.md`: VTC TX alignment runs once at boot (`wait_for_aligned_source_vsync()` per the firmware) but has deterministic offset; rate-only control cannot fix phase offset; needs either a discrete phase jump at SOF or a re-run of the alignment dance.

## 2026-05-21 18:00 — Iter2 plan

Two diagnostic paths to disambiguate WHICH alignment layer is broken:

**A. Try `MODE_1080P30` firmware + `scaler_bypass_1080p` HDL** — matched 1080p frame size end-to-end, scaler bypassed entirely, ONLY rate-axis FRC (drop every other frame). If wraparound persists → bug is in VTC TX alignment math, independent of scaler. If wraparound goes away → bug requires scaler in path.

**B. Try a passthrough sub-case: 1080p60 in → 1080p60 out** — would require BD reconfig for 148.5 MHz output clock (clk_wiz change), so not a firmware-only test. **Skipping for now** since it's an extra Vivado+BD-rebuild.

Iter2 is path A. Firmware-only change (edit MODE_720P60 reference → MODE_1080P30 in main.c), Vitis rebuild, reprogram. ~3 min cycle. No Vivado rebuild needed; current scaler_top bitstream still works because scaler with IN_W=IN_H is a no-op when output dimensions are not configured (actually need to verify this — scaler may not gracefully handle out_w=in_w; might need scaler_bypass_1080p HDL for that test).

Reconsider: iter2 may need both Vivado rebuild (revert to scaler_bypass_1080p HDL) AND firmware change (MODE_1080P30). ~30 min cycle for full iter2.

## 2026-05-21 18:10 — Drift characterization (15s window, 450 frames)

Captured 15 seconds of webcam frames after iter1 build was running. ImagePro had auto-cycled from SMPTE bars to a checkerboard + "Quantum" text test pattern between captures. Result:

| Frame | Time | "Quantum" text position |
|---|---|---|
| 000 | 0.0 s | middle-right |
| 100 | 3.3 s | top edge |
| 200 | 6.7 s | middle-right |

**Text sweeps the screen vertically with a period of ~6.7 seconds.** This is monotonic vertical wraparound at ~150 lines/sec drift = ~2.5 lines/frame at 60 Hz output = ~2300 ppm rate mismatch between source and output clocks.

**Root cause confirmed: independent output clock without tracking.**
- Source pixel clock: recovered from `dvi2rgb` at whatever rate ImagePro is sending (likely NTSC 1000/1001 = 59.94 Hz, possibly slightly different given measured ~2300 ppm offset).
- Output pixel clock: `clk_wiz_pixclk_out` MMCM at nominal 74.25 MHz, free-running. No feedback path from source-vsync drift to MMCM frequency.
- Dynamic Genlock keeps S2MM/MM2S frame buffer pointers in lockstep BUT cannot fix output-clock-vs-source-clock rate difference.
- The slow drift accumulates → visible roll on monitor.

**This is exactly the architectural problem Phase E1 MMCM tracking was built to solve.** Per [[xilinx-mmcm-psincdec-tracking]] and `tests/phase-e1/phase_e1p6_baseline_root_cause.md`: closed-loop nudges MMCM phase via DRP to track source vsync. Phase E1 ground-up plan ships at commit `42fe057` per [[schindler-phase-e1-state]] (claimed bench PASS for tracking loop + cadence handoff).

## Iter1 net findings

| Symptom (before iter1) | Status after iter1 |
|---|---|
| EOLLate every frame (S2MM_SR bit 15 set) | ✅ FIXED — config mismatch eliminated. Confirmed by `S2MM_SR=0x00011000` (clean). |
| Stable horizontal banding (multiple discontinuities) | ✅ FIXED — was a downstream effect of EOLLate. |
| Vertical wraparound + drift | ❌ PERSISTS — architectural (independent output clock). Cannot be fixed at iter5-1080p-clean substrate level. Needs MMCM tracking layer (Phase E1) or shared-clock architecture (Phase A-style). |

**iter5-1080p-clean is fixable for matched-rate-passthrough by using `SCALER_MODULE=scaler_top` + `MODE_720P60` firmware, BUT will always exhibit slow visible drift due to free-running output MMCM.** This is the FRC substrate's inherent limitation pre-Phase-E1.

## Iter2 plan (next session)

Switch to `phase-e1-pll-spike` branch + verify MMCM tracking eliminates the drift. The Phase E1 ground-up plan session docs (`tests/phase-e1/phase_e1p6_baseline_root_cause.md`, `phase7_states.md`, `phase8_cadence.md`) all claim PASS for tracking loop + reference mux + cadence handoff. Build, program, capture webcam over 15+ seconds, check for drift.

- If Phase E1 build is drift-free → Phase E1 work was real, iter5 + E1 tracking is the production substrate.
- If Phase E1 build also drifts → Phase E1 "PASS" claims may have been MS2109-tainted; tracking loop needs real bench fix.

Build artifacts/logs for iter1 archived under `Images/2026-05-21_iter1_*` for diff-reference next session.

## 2026-05-21 19:15 — Iter1 visual conclusion INVALIDATED then CORRECTED

**Topology discovery that invalidated iter1's drift claim:** The bench monitor's HDMI input is fed from the **Osee GoStream Duet switcher's PGM output** at `192.168.0.10:19010`. The Osee selects between 3 sources:
- input 1 (protocol value 0) = ImagePro 1080p60 static SMPTE bars (the only known-static source)
- input 2 (protocol value 1) = motion loop (the "Quantum" text source I captured during iter1)
- input 3 (protocol value 2) = laptop (remote-controllable)

When I did the iter1 webcam captures autonomously, the Osee was on **input 2 (motion loop)**, NOT a static source. The "rolling/drifting" I observed and characterized as 2300 ppm output-clock drift was actually **the motion loop's own intrinsic content motion** passing through iter5 — the FPGA pipeline was faithfully reproducing motion.

**Re-test with Osee on input 1 (static ImagePro):**

- Two frames captured 5 seconds apart at `Images/2026-05-21_iter1_static_t0.jpg` and `Images/2026-05-21_iter1_static_t5.jpg`.
- Both frames **visually identical** in content/positions (MD5 differs only from webcam JPEG/exposure noise).
- Output shows clean SMPTE bars **with a small thin strip at the very bottom of the screen** containing what looks like the start of the next frame (~5-10% of vertical height = ~36-72 lines at 720p output).
- No motion, no drift, no roll — the wraparound stays at the same position frame after frame.

**Corrected iter1 verdict:**

| Symptom | Status |
|---|---|
| EOLLate every frame | ✅ FIXED by SCALER_MODULE=scaler_top |
| Output rate drift (claimed earlier) | ❌ FALSE — was Osee input 2 motion loop content; not a pipeline bug |
| Deterministic vertical wraparound | ❌ EXISTS — ~5-10% of frame at bottom is from next-frame top |
| Output stability with static source | ✅ STABLE — no drift, no roll |

**The wraparound IS the same bug `tests/phase-e1/phase_e2_bench_session_2.md` documented:** VTC TX alignment runs once at boot with a deterministic line-count offset. ~50 lines at 720p60 (today) vs ~120 lines at 720p50 (their test) — same order of magnitude, consistent with the same firmware bug.

**Tools added 2026-05-21:**
- `/tmp/osee_switch.py` — minimal GSP client for Osee at 192.168.0.10:19010. Usage: `osee_switch.py <1|2|3|status>`. User-label inputs are 0-indexed in protocol (input N = protocol value N-1).

**Bench methodology lesson:** Always check Osee input before drawing visual conclusions from the monitor. ImagePro on input 1 is the only known-static source. Saved as memory feedback.

## Iter2 plan (revised)

The drift bug doesn't exist. The vertical wraparound is the remaining bug. It's deterministic — a firmware alignment math problem.

Iter2 should be **a firmware investigation**, not another build. Read `sw/phase-b/src/main.c::wait_for_aligned_source_vsync()` and `vtc_setup()` to find the alignment math. The Phase E2 session 2 doc proposed two fixes: (a) discrete phase jump via VDMA park-pointer write at SOF, or (b) re-run alignment after ref-switch. Neither requires a Vivado rebuild — just firmware. ~3 min cycle per attempt.

## 2026-05-21 20:17 — Iter2: move printf in vtc_setup AFTER CTL write

**Hypothesis:** `xil_printf("VTC: configuring %s...", ...)` at the TOP of `vtc_setup()` adds ~3.5 ms delay (UART at 115200 baud × ~40 chars) before the CTL register write that triggers VTC generator start. This violates the caller's explicit "NO printfs between wait_for_aligned and CTL write" rule at `main.c:1156-1168`. ~3.5 ms = ~227 source lines of misalignment at 1080p60.

**Change:** moved `xil_printf` from line 1019 (before register writes) to after the CTL register write at line 1054-1058.

**Result:** VISUALLY IDENTICAL to iter1. Wraparound at the bottom of frame remains the same size and same position. Saved at `Images/2026-05-21_iter2_printf_moved.jpg`.

**Conclusion: the existing comment at main.c:1161 was correct** — "alignment is driven by VDMA frame-buffer timing rather than VTC vsync_out phase." Latency between `wait_for_aligned_source_vsync()` and VTC GE-write does not affect the displayed image. The printf move is a cleanup (matches the caller's stated design intent) but does NOT address the wraparound bug.

**Iter2 firmware change kept** in source as a correctness improvement (it doesn't hurt and matches the documented design contract), but the bug is elsewhere.

**Where the wraparound actually originates — narrowing the search:**

| Suspect | Evidence | Status |
|---|---|---|
| VTC GE-write timing (printf) | iter2 disproved | RULED OUT |
| Source clock vs output clock drift | iter1 static-source proves no drift | RULED OUT |
| EOLLate-driven buffer corruption | iter1 telemetry shows no EOLLate | RULED OUT |
| MM2S +STRIDE shift (1 row offset) | Math checks out — only 1 row | INSUFFICIENT — wraparound is ~25-50 lines |
| GUARD region not zeroed | Code zeroes it before Xil_DCacheDisable() which flushes | UNLIKELY but worth confirming |
| Scaler emits more than 720 rows | Unknown — need to read scaler HDL | **OPEN — iter3 candidate** |
| VTC TX VTOTAL/V_BACK math off | MODE_720P60 looks standard CEA-861 | UNLIKELY |
| VDMA reads past buffer end | HSIZE=3840 VSIZE=720 per UART, should be exact | UNLIKELY but a diagnostic memcmp would confirm |

## 2026-05-21 20:20 — Iter3 plan

Two diagnostic candidates:

**A. Buffer-fill diagnostic.** Fill all DDR3 frame slots with a recognizable color (e.g., red), DON'T start VDMA S2MM, only start MM2S to read from buffers. Whatever shows on monitor = what MM2S is actually reading. If wraparound shows red at the bottom → MM2S reads stale buffer data past valid region (GUARD not protecting). If wraparound shows other content → it's coming from elsewhere.

**B. Scaler emit row count.** Read `hdl/scaler_top.v` and `hdl/scaler_v.v` to check whether scaler emits exactly OUT_H rows per frame or potentially overruns. The scaler is the most complex part of the pipeline and the +STRIDE shift comment suggests row-count edge cases exist.

I'd start with B — purely reading code, no rebuild needed.

## 2026-05-21 20:30 — Bug identified as the documented bottom-bars artifact

Read `docs/iter4g-diagnostic-findings.md` (2026-05-16). The wraparound today is **exactly** the bug that doc describes:

- Symptom: "~25 rows of next-frame-top at bottom" of every output frame
- Counter telemetry shows scaler emits 720 rows correctly, but **slot rows 694..719 contain wrong data** (next frame's top color bars instead of current frame's PLUGE bottom)
- +STRIDE offset moves visible boundary by 1 row but doesn't change the bug

**Bug history:**
- 2026-05-16: identified in iter4g; documented as open question.
- 2026-05-16 evening: iter4h tried fix via S2MM VSIZE=747 (over-allocate by 27 rows, spillover written into GUARD area). Confirmed fixed bottom-bars by bench observation. Memory `schindler-bottom-bars-artifact`.
- 2026-05-17 evening: iter5 bisect found iter4h's VSIZE over-allocate caused a 1-row-per-frame slow scroll. Bisect removed iter4h fix to eliminate scroll. Memory `schindler-iter5-bisect-findings`.
- 2026-05-17 / 2026-05-21: bottom-bars present again on current iter5-1080p-clean substrate, but bench claimed "clean" — likely because validation was MS2109-tainted (memory `schindler-ms2109-verification-trap`).

**Today's iter1+iter2 work made the bug visible for the first time on a monitor.** Phase A baseline + Osee topology fix + EOLLate elimination + new monitor all combined to make the previously-hidden artifact unambiguous.

**Open question from iter4g still open:** Why does scaler emit 720 rows (per counter) but slot rows 694..719 contain wrong data? Either:
- Scaler emit counter is wrong (TUSER timing); or
- Scaler MAC pulls wrong data for last ~25 emits (lbuf or v_phase issue at frame boundary); or
- S2MM partially writes frame N+1 into frame N's slot during frame transition; or
- Dynamic Genlock advances S2MM to next slot mid-write under some condition.

Per iter4g doc proposed next step: "Add a counter at scaler_v's m_axis output (count m_axis_tlast firings vs v_cross firings — should be equal but verify)." That's an HDL change + Vivado rebuild.

## Session close 2026-05-21 20:30

Real wins this session:
- ✅ Phase A baseline reconfirmed clean on new (working) monitor
- ✅ Bench equipment confounders banked as feedback memories (faulty monitor, MS2109 trap, Osee topology)
- ✅ EOLLate root cause identified + fixed (SCALER_MODULE / firmware mode mismatch)
- ✅ Drift hypothesis disproven (it was source motion via Osee input 2)
- ✅ Bottom-bars wraparound visually quantified (~25-50 lines)
- ✅ Bug identified as the documented unresolved iter4g artifact
- ✅ Iter2 printf-move ruled out as cause; that hypothesis now negative-falsified

Active state: board on Phase A (clean baseline). Iter5-1080p-clean rebuild artifacts on disk + new firmware (printf moved). Bottom-bars artifact is the next real work — requires HDL diagnostic counters per iter4g doc's open question.

**Iter3 (next session):** Either add m_axis_tlast counter to scaler_v's output, OR test the S2MM VSIZE over-allocate fix paired with a different S2MM completion mechanism that doesn't introduce scroll. Both require Vivado rebuild.

## 2026-05-21 21:20 — iter4h-axis-fifo bench validation REWRITES memory

Built and tested `iter4h-axis-fifo` @ `7d5fe09` on new monitor with Osee input 1 (static SMPTE bars). Memory `schindler-phase-d-iter4h-state` claimed it "fixes bottom-bars but introduces 1-row-per-frame scroll." Today's monitor-verified test shows:

**Build numbers:** WNS=+0.238, WHS=+0.009. Clean timing (no color stack → no async CDC paths). Vitis ELF rebuilt, programmed via XSCT. UART telemetry: `DIAG: h_in=1080 v_in=1080 v_emit=720 ... S2MM_SR=0x0001D000[FrmCnt EOLLate frmcnt=1] MM2S_SR=0x00011000[FrmCnt frmcnt=1] RDSTORE=2 WRSTORE=0`. EOLLate IS still set every frame (S2MM VSIZE=747 over-allocate produces it).

**Visual observation across 5 seconds (150 webcam frames captured):**

| Time | What's at top of screen | What's at middle | What's at bottom |
|---|---|---|---|
| t=0.0s | thin strip (PLUGE remnant + I/Q) | SMPTE bars | PLUGE (white box, Q-square) |
| t=1.0s | SMPTE bars (full) | I/Q strip | PLUGE + thin strip of next-frame bars |
| t=2.0s | SMPTE bars (top portion) | PLUGE + I/Q | larger strip of next-frame SMPTE bars |
| t=5.0s | PLUGE at top + thin strip | SMPTE bars (top half) | SMPTE bars (bottom half) |

Reference images: `Images/2026-05-21_iter4h_t{0.0,1.0,2.0,3.0,4.0,5.0}s.jpg`.

**Findings — both memory claims OVERTURNED:**

1. **❌ "Fixes bottom-bars"** — FALSE. The bottom-bars wraparound strip is **STILL PRESENT in every frame**, exactly like iter1. iter4h does NOT eliminate the artifact.
2. **✅ "Introduces scroll"** — TRUE, but rate is **~1.5 lines/frame** (≈90 lines/sec at 60Hz), not 1.0 as memory said. Picture moves UPWARD continuously, content cycles fully in ~8 seconds.

**iter4h is STRICTLY WORSE than iter1** (iter5-1080p-clean + scaler_top + MODE_720P60). Iter4h has the same bottom-bars artifact PLUS continuous scroll. The previous "iter4h fixed bottom-bars" claim must have been MS2109-tainted — the capture stick's internal framebuffer absorbs the scroll AND the wraparound, making everything look stable on capture.

**Memory corrections required:**
- `schindler-phase-d-iter4h-state` — claim "FIXES bottom-bars" needs strikethrough; revised to "introduces scroll without fixing bottom-bars"
- `schindler-bottom-bars-artifact` — claim "RESOLVED 2026-05-16 evening: Path 2 (S2MM VSIZE=747 + fsync wiring) eliminates the leak" needs strikethrough; the leak is NOT eliminated.
- `schindler-iter5-bisect-findings` — the bisect's "iter4h was structurally wrong" verdict stands, but the rationale needs adjustment: iter4h is wrong because it adds scroll WITHOUT fixing the actual bug.

**Path forward:** the bottom-bars fix is NOT in S2MM VSIZE over-allocate. The actual cause needs identification — likely scaler_v emit-at-frame-boundary issue per the iter4g doc's open question. That's HDL-level investigation (m_axis_tlast counter at scaler_v output).

**The previous "deterministic 20-30 line offset" finding (Justin observing QSPI boot) is consistent** with EOLLate-driven row-pointer drift: S2MM rolls into the next row late, accumulates a fixed offset per frame, visible on monitor as deterministic mid-frame discontinuity. The old monitor's panel issue made it look like a single horizontal tear; the new monitor reveals the actual flicker character.

## Next bisect step: Phase B VDMA passthrough (no scaler)

To localize whether the bug is in (a) the DDR3/VDMA path itself, or (b) the scaler:

- Need: a Phase B variant with **VDMA in path but scaler bypassed**, 1080p60 in → 1080p60 out (matched rate, no scaling, no rate conversion).
- If Phase B passthrough is **clean** → bug is in scaler interactions with S2MM (most likely candidate).
- If Phase B passthrough also **has EOLLate / flicker** → bug is in the DDR3 / VDMA / AXI write path itself.

Candidate substrates:
- `scaler_passthrough.v` (HDL exists per `tcl/build_phase_b.tcl`) — was Phase B's no-scaling variant
- Earlier Phase B commit `3d67170` ("Phase B + C: VDMA frame buffer + polyphase scaler") — might need to roll back to a pre-scaler Phase B commit if such exists

---

## How to recreate any build

For Schindler builds (Phase B and later), the canonical flow is:

```bash
cd /home/justin/Dropbox/_PROJECTS/Schindler-2.0
git checkout <branch>            # e.g. iter5-1080p-clean
git status                       # must be clean (or document edits)

# Bitstream + XSA
source /tools/Xilinx/2025.2/Vivado/settings64.sh
export BOARD_PARTS_REPO_PATHS=$HOME/fpga/vivado-boards/new/board_files
export DIGILENT_IP_REPO_PATH=$HOME/fpga/vivado-library/ip
vivado -mode batch -nojournal -log build/build_<name>.log -source tcl/build_phase_b.tcl

# Firmware ELF
source /tools/Xilinx/2025.2/Vitis/settings64.sh
xsct tcl/build_phase_b_app.tcl

# Program
xsct tcl/program_phase_b_full.tcl
```

**Timing for full rebuild:** ~25-30 min Vivado synth+impl, ~2-3 min Vitis app build. WNS reference: `iter5-1080p-clean` builds at WNS ≈ -3.57 (known async-CDC false-path issue from color stack; functional via ASYNC_REG per memory `schindler-color-pipeline`).

## 2026-05-22 — iter6: bottom-bars artifact RESOLVED via S2MM fsync

**Status:** **CLEAN.** Monitor + DDR3 dump verified on `iter5-1080p-clean` head with iter6 changes. Single bench session, single reboot — not yet re-verified under multi-cold-boot rule but visually unambiguous and the DDR3 dump is byte-conclusive.

### Diagnostic chain that landed iter6 (single session, ~5 hours)

1. **iter3 — firmware DDR3 dump probe.** Fixed `dump_slot_bytes` (was using iter4h stride + 1920-wide cols). Confirmed slot 0 rows 694-719 contain identical fingerprint to slot 1 rows 0-8 (SMPTE main-bars top) on static SMPTE source. **LEAK CONFIRMED, 26 rows.**
2. **iter4 — two-shot dump for A1/A2 disambiguation.** Dump 1 at iter 1 + dump 2 at iter 4 (~3 s apart), motion source on Osee input 2. Dumps showed byte-different content in slot rows 694-719 → leak is LIVE, not stale-from-boot. **A1 REFUTED, A2 confirmed.**
3. **iter5 — scaler_v `m_axis_tlast` output counter.** Added new 16-bit snapshot output to `scaler_v.v`, forwarded via `scaler_top.v`'s new `out_tlast_snap` port, rewired `diag_concat/In1` from the dead `axis_to_vid_io_0/mm2s_tlast_snap` to the new source. First read returned `v_out_tlast=0` — uncovered a **48→64-bit CDC truncation bug** in `axi_sync_inputs.v` that had been silently dropping `diag_counts_async[63:48]` since iter4g. Widened CDC to 64-bit, rebuilt, second read returned **`v_out_tlast=720` per frame**. Scaler emits 720 valid TLAST handshakes per source frame; **A2-scaler REFUTED, A2-S2MM CONFIRMED.**
4. **iter6 — S2MM external fsync.** Set `c_use_s2mm_fsync=1`, `c_flush_on_fsync=1`, instantiated `vsync_cdc_pulse` to emit a 1-cycle pclk_in pulse on rising edge of `dvi2rgb_0/vid_pVSync`, wired pulse to `axi_vdma_0/s2mm_fsync`. Monitor: **clean.** DDR3 dump: slot 0 rows 690-719 all show PLUGE fingerprint (`col90=000000 col270=FFFFFF col460=FFFFFF col640=000000 col820=000000 col1010=000000`), no leak. Slot 1 row 0 = `0x000000` (the known scaler_v lbuf_fresh cosmetic), rows 1+ = SMPTE main-bars top. **LEAK ELIMINATED.**

### Files changed in iter6

| File | Change |
|---|---|
| `tcl/build_phase_b.tcl` | `c_flush_on_fsync 0→1`; `c_use_s2mm_fsync 0→1`; added `vsync_cdc_pulse.v` to add_files; added `s2mm_fsync_pulse_gen` module-ref cell + 4 wire connections after rst_axi block. Rewired `diag_concat/In1` from `axis_to_vid_io_0/mm2s_tlast_snap` → `scaler_0/out_tlast_snap`. |
| `hdl/scaler_v.v` | Added `out_tlast_count_snap` output + counter logic (increments on `m_axis_tvalid && m_axis_tready && m_axis_tlast`; snapshot+reset at input TUSER). |
| `hdl/scaler_top.v` | Added `out_tlast_snap` output port; wired from `scaler_v/out_tlast_count_snap`. |
| `hdl/axi_sync_inputs.v` | **Fixed pre-existing latent bug.** Widened `diag_counts_q1`, `diag_counts_q2`, and `diag_counts_sync` from 48 to 64 bits. Upper 16 bits had been silently truncated. |
| `hdl/vsync_cdc_pulse.v` | No code change — was orphan HDL until now. Reused as-is. |
| `sw/phase-b/src/main.c` | Renamed `mm2s_tlast` → `v_out_tlast` in `diag_counters_read` + DIAG print. Fixed `dump_slot_bytes` slot stride (iter4h `+27 over-allocate` → iter5 `FRAME_BYTES+STRIDE`) and sample columns (1920-wide → 1280-wide). Two-shot dump trigger logic. |

### Verification at bench (2026-05-22 ~15:20)

- **Source**: Osee GoStream Duet PGM = input 1 = ImagePro 1080p60 static SMPTE bars.
- **Path**: dvi2rgb → scaler_top (1080p→720p downscale) → S2MM (slot K) → MM2S (slot K-1, FrameDelay=1) → axis_to_vid_io → rgb2dvi → HDMI TX → bench monitor.
- **Monitor**: clean. No thin colored strip at the bottom of the SMPTE bars frame.
- **UART telemetry**:
  - `h_in=1080 v_in=1080 v_emit=720 v_out_tlast=720` — scaler healthy.
  - `S2MM_SR=0x00011810[SOFLate FrmCnt frmcnt=1]` — `SOFLate` flag (bit 11) sets each frame, benign side effect of `c_flush_on_fsync=1` + source-vsync-edge-anchored fsync arriving slightly before AXIS TUSER. No `EOLLate` (bit 15). No actual data error.
  - `RDSTORE=2 WRSTORE=0` — VDMA cycling slots correctly.
- **DDR3 dump**: slot 0 rows 690-720 = uniform PLUGE fingerprint, guard row 720 = `000000`, slot 1 row 0 = `000000` (scaler cosmetic), slot 1 rows 1+ = main-bars-top.

### Outstanding (not blockers)

- Multi-cold-boot validation under [[schindler_no_coin_flip_rule]] to formally retire the "COIN-FLIP" status in the branches table above.
- Motion-source re-test (Osee input 2) to confirm leak stays gone under non-static content.
- SOFLate flag suppression (cosmetic).
- Memory updates: [[schindler_bottom_bars_artifact]] → RESOLVED; [[schindler_phase_d_iter4h_state]] → workaround obsolete.

### Full write-up

See [`docs/iter6-s2mm-fsync-fix.md`](iter6-s2mm-fsync-fix.md) for: detailed root-cause analysis, diagnostic procedure, fix details with code snippets, and replication procedure for other branches that have the same bug.

---

## 2026-05-22 evening — iter6 H-shift discovered on ALL branches (re-opened)

After closing out iter6 across three branches, Justin re-checked iter5-1080p-clean carefully on the monitor and **the 2-3 pixel per-line H-shift is present here too**. Originally seen on phase-e1-pll-spike and attributed there to branch-specific differences (FRC mode, c_num_fstores=3). That theory is now **refuted** — same H-shift on iter5 substrate.

**Net iter6 status:**
- ✅ 27-row vertical bottom-bars artifact: **FIXED** (DDR3 dump confirms uniform PLUGE in slot tails, no leak).
- ❌ 2-3 pixel per-line horizontal shift: **NEW REGRESSION (or pre-existing + unmasked).** Each output row starts ~3 pixels late; last 3 pixels of row N appear at start of row N+1.

**Tomorrow's investigation needs to disambiguate:** was the H-shift pre-existing (hidden behind the more dramatic V-wrap and the MS2109's framebuffer) or newly introduced by the iter6 fsync wiring? Hypotheses ranked in `docs/iter6-s2mm-fsync-fix.md`'s new "Known residual: H-shift" section.

**Matrix Row 2 demoted** back to ⚠️ until H-shift fix lands.

---

## 2026-05-24 — iter7→iter13: scaler kernel rework, H-shift RESOLVED

iter6 left a residual artifact ("each line starts 2-3 pixels late, last pixels of row N appear at start of row N+1"). DDR3 boundary-col dumps localized the bug to **scaler_h.v's MAC window**, not S2MM or MM2S as originally hypothesized: the polyphase 8-tap horizontal scaler was using NN-bypass single-tap output WITHOUT clearing the shift register at row boundaries, so the first 2-3 pixels of each output row read leftover tail data from the previous row. Vertical missing-lines was the same class of bug in scaler_v.v (NN-bypass `mac_r = tap1` dropped 1 of every 3 source rows for 1080→720).

**Tested branch:** `iter5-1080p-clean`. Output config = **720p60** (1280×720 @ 1650×750, ~74.25 MHz pixclk).

### Patch progression

| iter | Change | Bench result |
|---|---|---|
| iter7 | scaler_h.v: clear `window[0..7]` on TLAST | 2-pixel left margin — window now correctly zero at row start, but old-tap-pick reads pre-row pixel |
| iter8 | tap window[3] → window[0] (= newest pre-shift) | Left margin gone but image shifted left ~3 cols, right edge falls off screen |
| iter9 | tap = window[1] (intermediate) | 1-col left + 2-col right hard black margin — better balance but still NN band-aid |
| iter10 | 8-tap boxcar MAC (all 1/8 coefficients) | Vertical lines too soft (~7-col fade), right edge content past col ~1910 still invisible |
| iter11 | 2-tap boxcar `(window[0] + window[1])/2` | Tight 2-col blur, lines visible, **right edge still missing** (last MAC reads cols 1917,1918) |
| **iter12** | **2-tap with newest = `s_axis_tdata`** | **✅ Full src col range 0..1919 sampled. Left + right vertical lines at output cols 0 + 1279 as half-bright.** |
| **iter13** | **scaler_v.v: NN tap1 → 2-tap `(tap2 + tap3)/2`** | **✅ All horizontal grid lines now visible (no dropouts). Previously hidden every-other-line restored. Visible as 2 output rows half-bright (= V-equivalent of H scaler's 2-col half-bright vertical lines).** |

### Verdict

`iter5-1080p-clean` @ iter12+iter13 = **canonical post-iter6 scaler substrate.** Patches are:
- `hdl/scaler_h.v` ~lines 164-179 (2-tap with newest = `s_axis_tdata`).
- `hdl/scaler_v.v` ~lines 170-184 (2-tap with newest = tap3 post-rotation).

### Generalization (for replicating to other output resolutions)

| Output res | Ratio | Min taps | Pattern |
|---|---|---|---|
| 1920→1920 (passthrough) | 1.0 | 1 | NN `s_axis_tdata` only |
| 1920→1440 | 4:3 | 2 | iter12 as-is |
| **1920→1280 (current)** | **3:2** | **2** | **iter12 = sweet spot** |
| 1920→960 | 2:1 | 2 | iter12 |
| 1920→720 | 8:3 | 3 | extend MAC to `(s_axis_tdata + window[0] + window[1]) / 3` |
| 1920→640 | 3:1 | 3 | same as 720 |
| 1920→480 | 4:1 | 4 | 4-tap newest |

Rule: tap count ≥ `ceil(IN_W / OUT_W)`, with newest tap = `s_axis_tdata`. V scaler same pattern with line-buffer taps (newest = tap3 after `tap0_slot` rotation).

### Deferred (planned iter14)

Runtime kernel-mode toggle via AXI GPIO + UART `kh`/`kv` commands, independent H/V:
- mode 0: NN (newest tap only)
- mode 1: 2-tap boxcar (current iter12/13)
- mode 2: 4-tap boxcar (more blur)
- mode 3: reserved (future polyphase or separate blur module)

Cost: ~5 LUTs, ~30 min Vivado rebuild, ~30s UART parser extension. Add when needed for live A/B.

### Known cosmetic

- **First output row of frame:** tap3 lbuf may not be fresh yet (lbuf_fresh gating). Output row 0 reads as half-bright instead of full where source row 0 is bright. Pre-existing warmup; not from iter13.
- **Horizontal lines now half-bright across 2 output rows** instead of full-bright across 1 row. Symmetric to vertical lines on H. Inherent to 2-tap boxcar; user-accepted trade.

### Outstanding

- Replicate iter12+iter13 to `mackin-impl-wip` and `phase-e1-pll-spike`.
- Re-test SMPTE bars / motion (Osee inputs 1 and 2) on iter12+13 substrate; current grid-pattern tests were on input 3.
- iter14 kernel-mode toggle when desired.

---

## 2026-05-30 — Motion-source verification on phase-e1 + iter12+13

Bench-tested phase-e1-pll-spike @ `81df37b` (iter12+iter13 scaler kernel +
F UART command for DDR3 dump) with Osee input 2 (4K motion loop) then
ImagePro diagonal full-frame motion. Output: 720p60.

**Result:** CLEAN. Eyeball verification of diagonal-motion content on bench
monitor (the strictest tearing test — full-frame movement makes any seam
instantly visible) showed no tearing, no judder, no smear, no glitches.
Earlier webcam photos with apparent multi-frame ghosting were camera
exposure-integration artifacts only; not visible on direct monitor view.

**MMCM tracking loop** (phase-e1's primary feature) held cleanly under
60→60 matched-rate motion. No slip events observed.

**Scope established:** phase-e1 is designed for near-matched rates
(±500 ppm). 5:2 or other large FRC ratios are explicitly out of scope
for this branch — use iter5-1080p-clean (Method D drop/repeat) or
mackin-impl-wip (temporal blend) for those.

**Bench rule reinforced:** all motion-artifact verification MUST be on
the bench monitor directly, not webcam or MS2109 (both have integration
windows that mask tearing/race artifacts). Webcam useful only for
captured-to-disk record of static content.

---

## 2026-05-31 — iter5-1080p-clean ⚠️→✅ promotion (3-boot rule satisfied)

Bench-tested iter5-1080p-clean @ `ec13ab2` (post-iter13b round-to-nearest
fix on top of iter12+13 scaler kernel rework). Output: 720p60. Source:
ImagePro static SMPTE bars via Osee input 1.

**Verification:** 3 cold reloads via xsct, picture identical across all 3.
Boot 1: clean. Boot 2: clean ("is good"). Boot 3: clean ("looks identical").

**Result:** ✅ CLEAN. Formally satisfies the no-coin-flip rule. Promoted in
branch snapshot table above. Format matrix Row 2 (1080p60→720p60) was
already ✅ on `f8f143e` based on multi-reload-in-spirit evidence; now
formally backed by a documented 3-boot run on the iter13b substrate.

**What this resolves:**
- iter12+iter13 LUCKY-BOOT → CLEAN on production substrate ✅
- iter13b rounding fix verified at the bench (visual; the −0.5 LSB DC bias
  is below monitor visibility threshold, so this is a "no regression"
  result rather than a "visible improvement" result — exactly as expected)

**Open:**
- Backport iter13b to mackin-impl-wip and phase-e1-pll-spike (queued)
- Motion test on iter5 (ImagePro diagonal) still owed — phase-e1 got it
  2026-05-30 but iter5 didn't
- 3-boot verification of mackin and phase-e1 substrates still owed

---

## 2026-05-31 (later) — 1080p investigation + infra parametrization + Tier-1 audit cleanup

After the iter5 ✅ promotion (above), this session tackled two threads:

### 1080p output investigation (Row 1 + passthrough testing)

User asked to verify Row 1 (1080p60→1080p60). Three builds + thorough investigation:

| Build | Config | Result | Cause |
|---|---|---|---|
| 1080p60 + scaler_bypass + color enabled | rgb2dvi kClkRange=2 (production default) | Vivado AVAL-46 CRIT WARN — VCO 1485 MHz > 1200 MHz -1 max + timing failure | kClkRange=2 → MULT_F=10; correct for 720p60 at 74.25 MHz pclk, wrong for 1080p60 at 148.5 MHz |
| 1080p60 + scaler_bypass + COLOR_PIPELINE=bypass + kClkRange=1 | tcl rgb2dvi auto-derived from OUTPUT_MODE | Build closed timing (WNS +0.13) BUT bench monitor reported "signal out of spec" | OSERDESE2 SerialClk = 5 × 148.5 = 742.5 MHz exceeds -1 BUFIO 600 MHz max → non-HDMI-compliant TMDS |
| 1080p30 + scaler_bypass + color enabled | 74.25 MHz pclk (same as 720p60) | Build clean; bench monitor reported "signal out of range" — sink rejected sub-50Hz refresh | Dell desktop monitor doesn't accept 1080p30 (CEA-861 mode 34); pipeline output is correct |

**Result: Row 1 reclassified as "❌ on Zybo / ✅ planned on production"** — production carrier has external HDMI PHY chip + -2 silicon, either alone solves the row. Caught a VTC mode #ifdef hardcode bug in firmware along the way (commit `083239a`). New project rule established: HDMI output must be spec-compliant (memory [[hdmi_compliance_rule]]).

### Infrastructure parametrization (commits `891e834`, `ce1b671`, `0625876`)

tcl/build_phase_b.tcl + tcl/build_phase_b_app.tcl now have three orthogonal env vars, all defaulting to production behavior:

- **OUTPUT_MODE** = `720p` (default) | `1080p30` | `1080p60`
- **SCALER_MODULE** = `scaler_top` (default) | `scaler_bypass_1080p` | `scaler_crop_bypass`
- **COLOR_PIPELINE** = `enable` (default) | `bypass`
- rgb2dvi kClkRange auto-derived from OUTPUT_MODE (1080p60 → 1=MULT_F=5; else 2=MULT_F=10)
- Firmware `OUTPUT_1080P` compile define auto-set from `OUTPUT_MODE`; selects FRAME_W/FRAME_H + VTC mode

Default build (no env vars) = bit-identical to production 720p60 + color stack.

### Tier-1 audit cleanup (queued for next Vivado run)

Commits `0937574`, `5881322` — picked up next time Vivado runs:

- **SOFLate DIAG suppression** — cosmetic firmware noise, gone (S2MM only; MM2S not suppressed)
- **iter7 window-clear** — only clear `window[0]` (tap[1..7] are dead post-iter12; saves 168 flop-loads/row)
- **iter13c lbuf_fresh emit suppression** — top-of-frame black band → clean blank when both tap2/tap3 lbufs unfresh
- **XDC false-paths for color_matrix + scaler_top** — fixes the chronic WNS=-3.5 ns false-positive from missing constraint coverage

Production substrate continues to be `iter5-1080p-clean` @ `ec13ab2` (verified ✅ CLEAN). Subsequent commits (`5881322` onwards) add the queued fixes; verification of those happens on the next Vivado-cycle program + bench run.

### Forward-looking work also produced

- `docs/control-plane-architecture.md` (308 lines) — designs the production web UI / RP2040 / Linux daemon stack. V0a buildout plan (host-side bridge daemon) ~2-3 days, no PetaLinux required. Tabled by user for now.
- Memory entries `zynq7020_rgb2dvi_1080p60_limit` + `hdmi_compliance_rule` capture the 1080p60 investigation findings as durable rules.

### Outstanding

- 720p60 production substrate rebuild in progress (verifying queued Tier-1 fixes don't break the production path); user to bench-verify after program
- iter13b backport to mackin + phase-e1 still owed (~50 min wall-clock; pure cherry-pick)
- Matrix scope cut decision (Risk #4 mitigation) deferred to strategic-mind session
- Phase G vs E2 priority decision deferred

---

## Going-forward convention

Every bench session must end with an update to this manifest:
- Date + branch + commit
- What was tested (input format, output format, modes engaged)
- What was observed (image clean? coin-flip? scroll? EOLLate? frame drops?)
- How many reboots verified the result
- If broken: what's the symptom, what's the next investigation step

Memory entries are point-in-time; this manifest is the canonical "current state" SSOT.

---

## Reproduction — toolchain + external dependencies

Pinned 2026-05-30 to remove the "what version of X did this build use" ambiguity. If a future build breaks, check these commits first.

| Dependency | Version / commit | Path | Why this matters |
|---|---|---|---|
| Vivado | **2025.2** | `/tools/Xilinx/2025.2/Vivado` | IP versions (`axi_vdma 6.3`, `v_tc`, `dvi2rgb`, `rgb2dvi`) move between Vivado releases. A Vivado upgrade silently changes BD-generated wrapper code. |
| Vitis | **2025.2** | `/tools/Xilinx/2025.2/Vitis` | `importsources` stale-copy gotcha is version-specific; see `[[vitis_importsources_stale_copy]]`. |
| Digilent board files | `36f34ab687b7fa9c778b779d027f3bce63b3ace9` ("Fix typo in README", 2025-07-15) | `~/fpga/vivado-boards/new/board_files` | The Zybo Z7-20 board preset definitions. Pulled via `BOARD_PARTS_REPO_PATHS` env var in `tcl/build_phase_b.tcl`. |
| Digilent IP library | `f4613fff005b098065fd5d619a2b88e55720a423` ("Fixed zmod ID GUI parameter", 2024-05-16) | `~/fpga/vivado-library/ip` | Source of `dvi2rgb` + `rgb2dvi`. The `kClkRange` patch (`[[digilent_rgb2dvi_kclkrange_limit]]`) lives in this checkout and must persist across updates. |
| Target device | Zynq-7020 (XC7Z020-1CLG400C) on Zybo Z7-20 dev board | — | All MMCM/PLL/BRAM/DSP budgets are this device's. |

**If `~/fpga/vivado-boards` or `~/fpga/vivado-library` ever change tip**, re-verify Phase A passthrough + iter5-1080p-clean 720p60 build before continuing. Patch state (kClkRange edit, etc.) lives in those checkouts, not in this repo.

---

## Branch model — soft consolidation (committed 2026-05-31)

**`iter5-1080p-clean` is the effective `main`** as of 2026-05-31. GitHub default branch was flipped via `gh repo edit --default-branch`.

**Rules going forward:**
- New features land directly on `iter5-1080p-clean` whenever possible.
- Existing feature branches (`mackin-impl-wip`, `phase-e1-pll-spike`, `phase-g-iter1`) merge BACK to `iter5-1080p-clean` when their feature is bench-stable — NOT parallel-and-cherry-pick like the iter12+13/iter13b/iter13c three-way fan-out we did before today.
- `main` branch stays frozen at cold-storage (`045f09b`) until v1 ship, then gets force-updated to `iter5-1080p-clean`'s tip and `iter5-1080p-clean` is retired.
- New short-lived feature branches off `iter5-1080p-clean` are fine; they should merge back within a week or two.

**Why this and not full consolidation now:** force-updating `main` mid-development carries risk (PR refs, external links, watchers). Soft consolidation gets the benefit of one effective trunk (no more 3-way cherry-picks of every fix) without the disruption. At v1 ship the model converges to industry norm.

**Why not status quo:** today's session cost three separate `iter13b` cherry-picks across branches plus a fourth on `iter13c`. If we keep that model, every new feature pays that tax. Soft consolidation makes `iter5-1080p-clean` the gravity well — features land there first, propagate to feature branches only when needed.

### Reference: Phase G hardware test

User has a test carrier board for TE0720 verification (the production target -2 silicon). **TE0720 builds are available on request** when 1080p60 OUT verification or other production-silicon work is needed. Not gating any current v1 path.

## 2026-05-31 — V0a control plane: end-to-end bench smoke ✅

V0a build (catalog + firmware J bridge + Python schindlerd daemon + browser UI) reached green end-to-end on `iter5-1080p-clean`.

**Build provenance**
- Branch: `iter5-1080p-clean`
- Commit at smoke: `9eaab60` (firmware bridge); polish lands at `3d393c6`
- HDL substrate: identical to `abb83e8` (iter14 runtime kernel mode) — XSA reused, only firmware ELF rebuilt
- Archive tag: `iter5-1080p-clean-720p-scaler_top-enable-8bb72e9` in `build/artifacts/`
- Firmware ELF: `build/vitis-phase-b/vdma_init/Debug/vdma_init.elf` (324 KB)
- Toolchain: Vitis 2025.2

**What was verified (bench, 2026-05-31 ~15:00-15:15)**
- Boot banner clean; source detected 1920×1080 @ 60.895 Hz; output 720p60; passthrough regime; no error bits
- `?` UART help shows new `J <json>` line
- `control-plane/schindlerd/jsmoke.py` direct-UART smoke: 9/9 happy + 2/2 error paths PASS
- WebSocket round-trip via daemon: identify / control.set / control.get / enum string↔int translation all clean
- Browser UI at http://127.0.0.1:8080: 3 sections render (Color / Scaler), saturation slider drags smoothly post-coalesce fix, kernel-mode dropdowns toggle live, profile snapshot+load round-trip works
- `frc.mackin_alpha` correctly hidden via daemon firmware-availability probe (depends on `mackin-impl-wip` branch which isn't this substrate)

**Issues found and fixed in-session**
- UI was firing 100 control.set/sec during slider drag → daemon UART queue overflow → 1.5 s timeouts. Fix: per-control coalescing in `web/index.html` — only newest queued value sent next; intermediates dropped.
- UI was rendering controls firmware doesn't implement (mackin alpha placeholder, status entries). Fix: daemon probes firmware `system.list_controls` at first `system.catalog` request and tags each catalog entry `available: true/false`; UI skips `false`.
- UI was calling `control.get` on read-only / trigger controls → noisy daemon stderr (firmware doesn't expose status reads). Fix: skip these in `refreshAllValues`.

**Open items (V0a+1)**
- Status push: daemon polling task for `status.*` controls → broadcast `notification` frames to subscribed WS clients. Status entries currently show "—".
- Catalog version compatibility handshake at WS open.
- Multi-client coordination — second open browser doesn't see first's changes until refresh.
- Mackin alpha will turn on automatically once dual-VDMA wiring lands on `mackin-impl-wip` and the firmware J table gains the control.

**Pass/fail**: ✅ PASS — V0a stack is end-to-end functional and ready for daily bench use. The "rebuild + re-program + run schindlerd → browser" loop replaces the picocom + manual UART commands workflow.

## 2026-06-02 — Read-engine-B full-master: shear root-caused, NBUF=4 fix (build #10) ⚠️ in-flight

Route-B post-color read-engine (runtime size/position/matte). Full doc:
[`readengine-b.md`](readengine-b.md); live resume state:
[`readengine-b-SESSION-HANDOFF.md`](readengine-b-SESSION-HANDOFF.md).

**Branch:** `readengine-b-integration` (off `iter5-1080p-clean`). **Last commit:** `5407677`
(build #9). Build #10's `NBUF=4` HDL is **uncommitted working-tree** at this writing.

**Build lineage (bench, monitor-verified):**
| # | Change | Build | Bench |
|---|---|---|---|
| #7 | genlock frame-follow, 720p master (H 1:1) | met | ✅ CLEAN — core validated, steady windowed scaling |
| #8 | full-master 1920×1080 | met | ❌ crop fixed but SHEARS ("lines late") |
| #9 (`5407677`) | DataMover burst 16→256, out FIFO 16→64 | met (WNS +0.091/WHS +0.014) | ❌ no change — disproves throughput-tuning |
| #10 | `pg_linefetch` → `NBUF=4` ring + `pg_compose` 2-row lookahead | *building* | *pending — discriminator (see below)* |

**Root cause (2026-06-02):** shear = two independent ceilings, both in the line-fetch path.
(1) **Depth/latency** — old 2-buffer/1-ahead double buffer had zero slack for the 3-master DDR
contention (S2MM + VDMA-MM2S + read-engine). FIXED in #10. (2) **Rate** — `pg_unpack` fills at
1 px/clk = 1920 clk/line; full 1280×720 window needs 720·1920 = 1.382M clk/frame > 720p60 budget
1.2375M (~11% over) → rate-bound, depth can't fix. 960×540 window fits (1.037M) → there the
wobble was pure latency.

**Build #10 is a discriminator.** Predict: `G 960 540 0 0` CLEAN, boot `1280×720` still wobbles.
If confirmed → build the **packed-beat fill** (store 64b beats @1 beat/clk, extract pixel on
read; 2.4× margin) per `readengine-b.md` §5. If both clean → done, skip packed-beat.

**Provenance:**
- Sim: `pg_compose_tb` + `pg_read_engine_top_tb` run directly = `Total errors = 0` at `NBUF=4`
  (the `make sim-pg` wrapper mis-reports an xsim exit and aborts after genlock — run TBs by hand).
- Build env (mandatory): `BOARD_PARTS_REPO_PATHS=$HOME/fpga/vivado-boards/new/board_files`,
  `DIGILENT_IP_REPO_PATH=$HOME/fpga/vivado-library/ip`.
- Firmware: `READENGINE_FULLMASTER=1 make build-app` (full-master, VTC stays 720p).
- Verify on **monitor only** — MS2109 + PS-cache frame-dump both mask the artifact.

**Pass/fail:** ⚠️ IN-FLIGHT — #10 not yet bench-verified; do NOT mark ✅ until the §3 experiment
+ 3-boot rule pass. Builds #8/#9 are ❌ (shear). Build #7 (720p master) was the last clean
read-engine build.

## 2026-06-02 (cont.) — Read-engine-B: ILA proves ALIASING, not an engine bug ⚠️ open

Continues the read-engine-B entry above. Builds #11–#13 on `readengine-b-integration`
(uncommitted working tree; last commit `5407677`).

| # | Change | Bench |
|---|---|---|
| #11 | read-during-write collision fix (read-select excludes fill_buf) + `NBUF=5` + `LOOKAHEAD=NBUF-3` | ❌ ghost UNCHANGED → collision was not the cause |
| #12 | +ILA (first attempt) | killed mid-synth (my pkill); ILA dbg-probe unconnected (missing `C_PROBE0_WIDTH`) |
| #13 | +ILA hardened (`C_PROBE0_WIDTH`, probe-name match) | **ILA captured cleanly** |

**ILA verdict (build #13, both `ila_re_dbg` 96-bit + `ila_re_beats`):** the read-engine is
CORRECT — `src_col` is a perfect `floor(col×1.5)` decimating DDA (monotonic, resets per row),
`src_row` steps right, `rd_data`/`up_pdata` bit-clean (grid black runs = pure `000000`). The
visible artifact is therefore **nearest-neighbor decimation aliasing** — full-master storage
(`scaler_bypass_1080p`) bypassed `scaler_h/scaler_v`'s anti-alias boxcar. All earlier theories
(lines-late shear, buffer depth, fill rate, read-during-write collision, stride, addressing skew)
are **disproven** by hardware capture.

**Fix (4-agent consensus):** un-bypass the input scaler (`SCALER_MODULE=scaler_top`) → pre-filtered
1280×720 master, read-engine does size/position/matte = the build #7 clean config. Read-path box
filter is G2-only (full record + golden-model spec: `docs/readengine-b.md` §10).

**⚠️ OPEN / BLOCKING:** truly-flat GREEN/RED/ORANGE fields ALL show the same fine pattern, which
pure aliasing does not predict and the ILA-on-grid couldn't test (only flat black, which is clean).
Resolve before the fix via engine on/off toggle on a flat color + `ila_re_dbg` on a flat color
(`docs/readengine-b.md` §11 Q1). Leading hypothesis: laptop dithers solid colors; the dither is
aliased. **Status: ⚠️ root cause of the GRID artifact known (aliasing); the FLAT-COLOR pattern is
unresolved. Do NOT mark ✅ until Q1 closes + the fix lands + 3-boot verify.** Capture tooling:
`tcl/capture_re_ila.tcl`, `/tmp/decode_dbg.py`. Verify on monitor (MS2109 masks this class).

## 2026-06-02 (cont.) — Build #16: SOF-gated frame realign (option 1) ✅ built, sim-proven, ⚠️ bench-pending

Branch `readengine-b-integration`, on the packed-beat substrate (prior commit `911b16d` =
build #15, full-master read-engine + packed-beat line fill). This build adds **AXIS frame
framing (TUSER=SOF / TLAST=EOL)** end-to-end so the output adapter anchors each frame to its
SOF beat instead of free-running — making frame-start alignment **independent of producer
latency** (engine engage, geometry change, genlock-slot change) and ensuring a stale/partial
beat can never be latched as pixel 0.

| Module | Change |
|---|---|
| `hdl/pg_compose.v` | emit `m_tuser`(SOF on pixel 0) + `m_tlast`(EOL each row); ofifo widened to carry sof/eol bits via `push_col`/`first_done` |
| `hdl/pg_read_engine_top.v` | expose `m_axis_tuser`/`m_axis_tlast` |
| `hdl/axis_mux2.v` | carry `tuser`/`tlast` on s0/s1/m (this mux was **silently dropping SOF** before the color stack — the reason the adapter couldn't use it) |
| `hdl/axis_to_vid_io.v` | SOF-gated realign: drain pre-SOF beats (emit black), lock pixel 0 to the SOF beat, free-run; re-arm each frame at vtg_vsync. **Does NOT require TLAST** (VDMA MM2S asserts SOF via fsync but not per-line TLAST) → safe for the proven VDMA passthrough |

**Why the mux was the gap:** the color stack (`color_saturation/correct/matrix`) already
forwarded TUSER/TLAST, and VDMA MM2S asserts SOF via `c_use_mm2s_fsync` — but `axis_mux2` had
no TUSER/TLAST ports, so SOF died at the mux. Widening the mux lets Vivado re-infer the s0/s1/m
AXIS interfaces with TUSER/TLAST; existing `connect_bd_intf_net`s carry them automatically (no
BD edit needed — confirmed in build log: re_mux s0/s1/m inferred, generation complete, no
interface mismatch).

**Sims (gate, all green before build):**
- `sim/axis_sof_tb.v` (NEW): **PASS, 164 checks, 0 errors** — clean frames bit-exact (no
  regression), pre-SOF junk drained, late-SOF latency-independent, mid-frame starve re-anchors
  next frame. (frame 1 = warmup, excluded; `enable` rises mid-raster.)
- `pg_read_engine_top_tb` (capstone golden): **Total errors = 0** (producer TUSER/TLAST additions bit-exact).
- `pg_latency_tb`: **starv=0, full delivery** (packed-beat intact).
- (`pg_compose_tb` does not compile — pre-existing stale TB referencing the removed `fetch_last`
  port from before packed-beat; NOT a regression of this change.)

**Build:** `write_bitstream completed successfully`, DRC 0 errors, exit 0.
**Timing MET: WNS = +0.139 ns, WHS = +0.0066 ns** (vs #15's WNS +0.205 — SOF logic cost a little
slack, still positive setup + hold). Bitstream:
`build/phase-b-vdma-passthrough/phase-b-vdma-passthrough.runs/impl_1/phase_b_bd_wrapper.bit`.
**No firmware change** (pure AXIS side-band, no register-map change → existing ELF applies).
Build env (mandatory): `BOARD_PARTS_REPO_PATHS`, `DIGILENT_IP_REPO_PATH` (see "How to recreate").
Reproduce: `READENGINE_B=1 OUTPUT_MODE=720p make build`.

**Scope note:** SOF realign is frame-*alignment* robustness, BELOW the FRC layer. It does **NOT**
fix the "wrap" (source 59.94 vs output 60.00 rate drift) — that is genuine FRC and needs the
per-engine **cadence controller** (next step; see `docs/dual-engine-frc-plan.md`). Expect the
wrap to still be present after this build.

**Pass/fail:** ✅ built + timing-met + sim-proven. ⚠️ **bench-pending** — verify VDMA passthrough
AND read-engine both clean on **monitor** (no regression), ≥3 cold boots (no-coin-flip rule).
Do NOT mark fully ✅ until bench + 3-boot verify.

---

## 2026-06-03 — Read-engine-B: pg_cadence integration + per-line wrap fixed (builds #21b/#22/#23) ✅ silicon-confirmed

Branch `readengine-b-integration`. Three builds this session; net result = the route-B read engine
runs the FRC **cadence controller** in gen-lock mode AND the long-standing per-line horizontal
**wrap** (the "few-pixel offset") is fixed and confirmed on silicon.

**Build #21b — `pg_cadence` gen-lock integration** (commit `8a4849d`/`5223565`). Replaces
`pg_genlock` with `pg_cadence` (`blend_mode=0` = drop/repeat, single fetch). WNS +0.235.
- Central discovery: `s2mm_frame_ptr_out` is **Gray-coded**; both `pg_cadence` and `pg_genlock`
  now `gray2bin()` decode before use (was a latent binary-decode bug that only looked clean on a
  static grid). All 3 TBs green.
- **Bench: motion CLEAN** (Osee input 2 motion + input 3 1080p60 laptop) — no judder/roll/tear/
  hitch. This is what validated the cadence, the Gray decode, AND the decode→slot mapping on live
  motion (the static grid could not disambiguate). `in=1920x1080 src=60 out=60`.

**Build #22 — δ-measurement diag** (commit `62a09a3`). Added `axis_to_vid_io.predrain_snap` →
diag GPIO ch1 (the dead-in-route-B scaler field), firmware `DRAIN:` line. WNS +0.153.
- Measured the residual per-line wrap: **`DRAIN: delta_px=6 (stale=6 starve=0)`**, constant every
  frame. Root cause (agent-confirmed): the **shared color stack** (sat→correct→matrix) holds the
  prior frame's last ~6 pixels in its pipeline at the frame boundary; with `tready` gated to
  active-video only, those residual beats were drained by burning the first 6 ACTIVE pixels →
  pixel 0 landed at column 6 → per-line wrap. NOT a VTC porch issue (a porch shift can't wrap
  end-of-line content); NOT the resample/addr math (output(0,0)→source(0,0) verified clean).

**Build #23 — bounded blanking-flush fix** (commit `78ce592`). WNS +0.190, WHS +0.015. **Current
substrate.**
- Fix in `hdl/axis_to_vid_io.v`: drain pre-SOF residue during VBLANK (emitted black, not shown) so
  the SOF beat is at the FIFO head when active begins → pixel 0 at column 0. **Bounded to
  `MAX_DRAIN=16`** beats/frame so a missing/late SOF reverts to the old 1-frame-black-flash instead
  of eating the whole ~49.5k-cycle vblank and cascading (failure mode flagged in agent review).
  `vtg_vblank`-scoped. `axis_to_vid_io` is **shared** by read-engine + VDMA passthrough → fix
  applies to both (the wrap was common to all builds).
- **Sim** `sim/axis_sof_tb.v`: **PASS 230+6 checks, 0 errors** — existing anchor/clean checks intact
  (no regression on the shared module) + new δ==0 assertion on the residue frame (was δ=3 pre-fix)
  + missing-SOF frame proving the drain is capped and does not cascade (frame 9 re-anchors).
- **Bench (silicon-confirmed):** `DRAIN: delta_px=0` across **static, 2× zoom (`G 960 540 480 270`),
  full (`G 1920 1080 0 0`), and passthrough (`G 0`, sel=0)** — δ holds at 0 through geometry
  transitions and on the VDMA path (the shared-adapter change did not regress passthrough). Monitor:
  position perfect, wrap gone, motion clean. (`bflush=1` not ~6 because the pre-fix δ=6 was the
  color pipeline's traversal latency, which the chain now advances through during blanking; only 1
  valid residue beat needs flushing — δ=0 is the thing that matters.)
- **Color aside:** a separate "too warm" report was chased to ground — MS2109 digital capture of the
  output measured whites = `(255,255,255)`, all channels reach 255, global B/R=1.00 (neutral). The
  box's color is accurate; the warmth was **f.lux** running on the test machine. Channel-isolation
  probe also confirmed correct R/G/B mapping (no R-B-G swap). Not an FPGA issue.

**Reproduce:** `READENGINE_B=1 OUTPUT_MODE=720p make build` then `READENGINE_FULLMASTER=1
OUTPUT_MODE=720p make build-app && make program`. Build env: `BOARD_PARTS_REPO_PATHS`,
`DIGILENT_IP_REPO_PATH`.

**Pass/fail:** ✅ built + timing-met + sim-proven + silicon-confirmed (δ=0 across static/zoom/
passthrough, motion clean). Full-master boots sel=1 (engine); sel=0 passthrough is a non-viable
fallback in this build (can't downscale 1080→720). ⚠️ **3-cold-boot verify still owed** before
promoting to the no-coin-flip ✅ CLEAN standard (per `schindler-build-provenance-rule`).
Reviewed by external agent (diagnosis + fix + cap + verification plan all endorsed).

### 2026-06-03 (cont.) — FRC validated at 30→60 on build #23 ✅ (monitor-confirmed)

Fed the read engine a **1080p30** source (Osee GoStream `outFormat` index 4; index 7 = 1080p59.94)
→ output stays 720p**60** → the cadence does a clean **1:2 repeat**:
- `PHASE` delta ring = `{1,0,1,0,1,0,…}` (each source frame shown for exactly 2 output frames).
- `DRAIN: delta_px=0` holds (wrap fix robust at 30→60).
- **Monitor: image looks great** — smooth, no tear/corruption. This is the drop/repeat cadence
  doing real frame-rate conversion, visibly validated at a clean integer ratio (the near-1:1
  59.94→60 wrap is correct too but its single repeat per ~16 s is too rare to see).

**Benign-at-30Hz note:** at 30 Hz input the **capture** VDMA flags `S2MM_SR = SOFEarly | EOLEarly`
(`0x11990`; MM2S/output side stays clean `FrmCnt` only). The S2MM is tuned for 60 Hz and the 30 Hz
frame boundary lands off its genlock/size expectation — but the captured image is **clean on the
monitor**, so these are cosmetic status bits at off-nominal input, NOT corruption. Decoupled from
the read-engine/cadence. (Would matter to revisit if a build needs guaranteed 30 Hz *input*
capture; not a blocker for FRC, where 60 Hz input is nominal.)

Osee output-format map (Zybo-measured): index **4 = 1080p30**, index **7 = 1080p59.94**.
`setOutFormat`: `{"id":"outFormat","type":"set","value":[N]}` (same frame as `osee_switch.py`).

### 2026-06-03 (cont.) — fractional cadence confirmed at 29.97→60; Osee format map corrected

**Osee `outFormat` index → rate (per Justin's confirmation + bench):**
| index | rate |
|---|---|
| 3 | 1080p29.97 |
| 4 | 1080p30 (Justin-confirmed) |
| 5 | 1080p50 |
| 6 | 1080p59.94 |
| 7 | 1080p60 |

Note: the Zybo rate measurement (~0.1–0.4% accuracy) CANNOT distinguish 29.97 from 30 (index 3
boot-measured 30.118 Hz); the map above comes from the GoStream's known list ordering, not the
instrument. The `DIAG src=` field is a per-second vsync edge count (coarse); precise rate only
printed once at boot (`TELEMETRY: src=NN.NNN Hz`).

**29.97→60 fractional cadence (Osee index 3), 75 s soak on build #23:** base **2× repeat** PHASE
ring `{1,0,1,0,…}`, with a caught **slip** at t≈64 s: `{0,1,0,1,0,1,0,1,0,1,0,0}` — the trailing
`0,0` is the cadence inserting an EXTRA repeat (a source frame held for 3 output frames) to absorb
the 2.002 (=60/29.97) ratio. `delta_px=0` across all 74 samples; no drift, no tear. This is the
fractional-ratio handling working — distinct from the pure-integer 30→60 (which is perfectly
periodic). Completes the FRC validation span: 60→60 (gen-lock), 59.94→60 (near-1:1), 30→60 (2:1),
29.97→60 (2.002, fractional). All clean, δ=0.

### 2026-06-03 (cont.) — FULL FRC cadence matrix validated on build #23 ✅

All driven by changing the **Osee GoStream output rate** (re-clocks every input to its output
format) into the read engine, output fixed at 720p**60**, `pg_cadence` in gen-lock mode. Every
ratio held `delta_px=0` (wrap fix robust) with the expected drop/repeat pattern in the per-output-
frame `PHASE` delta ring. Bench-measured on the Zybo UART telemetry; monitor-clean where noted.

| src → 60 out | ratio (out:src) | cadence | PHASE signature | result |
|---|---|---|---|---|
| 60.00 | 1:1 | gen-lock (no repeat) | `{1,1,1,1,…}` | clean (motion-confirmed) |
| 59.94 | ~1000:1001 | near-1:1, rare repeat | all-1s + a `0` every ~16 s | clean, δ=0 (soak) |
| 50.00 | 6:5 | 1 repeat per 5 src | `{1,1,1,1,1,0}` periodic | clean, δ=0 |
| 30.00 | 2:1 | pure 2× repeat | `{1,0,1,0,…}` | clean, **monitor-confirmed** |
| 29.97 | ~2.002 | 2× + slip | `{1,0,1,0,…}` + caught `…,0,0` slip @ t≈64 s | clean, δ=0 |
| 24.00 | 5:2 | **3:2 pulldown** | `(1,0,0)(1,0)` = 3×,2×,3×,2× | clean, δ=0 |

The cadence produces correct drop/repeat (incl. textbook 3:2 pulldown at 24→60) across every
common rate with **no per-ratio special-casing** — it falls out of the runtime Δnewest phase
tracking. This validates the cadence's core purpose on silicon. (Output stayed 720p60 throughout;
true 60→30/24 *output* conversion would need an output-mode build — separate task.)

**Osee `outFormat` index map** (list ordering, fractional-then-integer pairs; Zybo can't resolve
the .x97/.98 fractionals vs their integers, ~0.4% measure accuracy): 0=23.98, 1=24, 2=25,
3=29.97, 4=30, 5=50, 6=59.94, 7=60. Set via `{"id":"outFormat","type":"set","value":[N]}` (same
frame as `osee_switch.py`). **GoStream accepts ONE control client at a time and is slow to recycle
the socket** → one command per TCP connection, pause between (back-to-back connects → "No route to
host" until the prior closes). Osee left on **index 7 = 60 (nominal)** after this session.

### 2026-06-03 (cont.) — build #23 PROMOTED to ✅ CLEAN (3-cold-boot verified)

`readengine-b-integration` build #23 (commit `78ce592`: bounded blanking-flush wrap fix +
`pg_cadence` gen-lock) **passes the no-coin-flip 3-boot rule**:

| boot | rate/regime | delta_px | S2MM err-flags | monitor |
|---|---|---|---|---|
| 1 | 60p 1:1 | 0/6  | 3/6 → **transient** (Osee settling post-flip) | clean (Justin) |
| 2 | 60p 1:1 | 0/18 | 0/19 | clean (Justin) |
| 3 | 60p 1:1 | 0/17 | 0/17 | clean (Justin) |

Each boot = fresh JTAG reprogram (PL re-init → MMCM/TX-VTC restart → re-rolls vsync phase, the
coin-flip surface). All 3 came up clean on the monitor (no roll/tear) with `delta_px=0`; the boot-1
err-flags did not recur (boot 2/3 = 0) → confirmed transient, not a build defect. **Status: ✅
CLEAN (verified 2026-06-03, 3 boots).** This is the production read-engine substrate (gen-lock
cadence + wrap fixed). Base for Mackin blend (`blend_mode=1`) next.

### 2026-06-04 — build #28: Mackin blend ENGAGES (7 framestores + mode-dependent lag) ✅ silicon

`readengine-b-integration` build #28 (timing MET, WNS +0.145). Unblocks the Mackin blend that
#24–#27 built but couldn't engage at 5 framestores (cadence lag pinned at 1; blend needs lag≥2 for
a completed S+1 partner). Agent-reviewed/green-lit (Round-5 packet).
- **Coordinated 5→7** (kept equal): VDMA `c_num_fstores`, `pg_re_0 NUM_FRAMES`, `pg_read_engine_top`
  default, firmware `#define NUM_FRAMES`, `fp_mon`. SLOT_STRIDE/FRAME_BUF_BASE unchanged (7×6.2 MB
  = 43.6 MB @ 0x10000000, within 1 GB DDR).
- **Mode-dependent lag** (pg_cadence): lag bound to LATCHED user mode — off→1 (min latency),
  intelligent/force→2 (blend partner), capped. NOT per-frame α (would self-judder at near-1:1).
  +1-frame interpolation latency is opt-in per mode.
- **Bench (silicon), Osee 1080p24→720p60:** `BLEND: 0/60` (off) → **`60/60` (intelligent & force)**;
  `DRAIN δ=0`; **errflags=0** (no EOLLate/EOLEarly/SOFEarly → shared DDR holds at 7 stores +
  dual-fetch — the agent's open bandwidth concern, resolved on HW). Justin monitor: blend visibly
  smooths motion, clean (no tear). **Mackin FRC works on silicon.**
- Also: daemon `geom.set` scale clamp 1920→2560 (200% zoom was capped at 1.5×; daemon-only fix,
  commit `a4b8aa8`).
Gate `pg_cadence_tb`: N=5 blend=0, N=7 blend=130/437, collisions=0, min_lap=4. ⚠️ 3-boot verify owed.

## Build #30 — signed window translation + scale anchor (2026-06-04) ✅ CLEAN (verified under #31)
- Branch `readengine-b-integration`, commit `29d3aaa`. WNS **+0.225**, WHS **+0.009**.
- Read-engine "shift" reworked from #29's source-crop (a wrong turn) to a SIGNED output-window
  origin: shift pushes the image off the left/top edge, pixels leave the frame, matte fills the
  opposite edge — at any scale incl. 100%. `pg_addrgen` membership is signed; `src_col0/src_row0`
  are the firmware-computed DDA seed (source col/row at first on-screen pixel). One seed formula
  yields BOTH center-anchor zoom (negative base pos) and off-screen shift.
- Scale anchor restored: center (default) / top-left, UI checkbox → `G w h sx sy a`. Seed packed
  into GEO_C ch2 free bits [26:3] (no new GPIO IP). Geometry CDC widened to GW=144.
- Sims: capstone `pg_read_engine_top_tb` Total errors=0 (shift R/L/up, 2× zoom centered + shifted);
  `pg_blend_tb` bit-exact, starv=0. Justin monitor: "perfect, best ever." Supersedes #29 (`7f044eb`).
- See memory [[schindler_signed_window_geometry]].

## Build #31 — read-side 2-tap H anti-alias filter (2026-06-04) ✅ CLEAN (3-boot verified)
- Branch `readengine-b-integration`, commit `7dccf04`. WNS **+0.222**, WHS **+0.020**.
- 2-tap horizontal box filter on the read-engine resample (NN was aliasing on zoom). col+1
  neighbour is free (already in pg_linefetch's 128-bit window). Applied to both Mackin frames;
  filt_h=0 → exact NN. Runtime toggle: UI "Anti-alias (2-tap H)" / UART `F 0|1` / GEO_C ch2 bit27.
  Sims bit-exact (capstone + blend). Justin monitor A/B: softens zoom, "works well enough, pass."
- **3-BOOT VERIFICATION (2026-06-04, JTAG-reprogram ×3, this build stacks #28 Mackin + #30 geometry
  + #31 filter):** all 3 boots IDENTICAL — 1080p24→720p60, FRC locks at 5/12 cadence, `DRAIN
  delta_px=0`, error bits benign (FrmCnt only, no EOLLate), **Mackin BLEND 60/60 every boot**,
  geometry repeatable. Justin monitor: all three came up identical, stable, same vertical position,
  no roll/tear. → **#31 ✅ CLEAN; closes the owed #28 Mackin 3-boot; #30 verified by inclusion.**
- This means the whole read-engine stack (FRC cadence + Mackin blend + signed-window geometry +
  anti-alias) is now 3-boot-verified on one substrate → **gate for #106 FF-merge to trunk is clear.**
- Deferred (own task): vertical 2-tap (needs 2nd line-read port), bilinear-by-DDA-fraction,
  NUM_FRAMES single-source, blend-metric denominator.

## Build #32 — Tier-1a effects: H/V flip + 180° rotate (2026-06-04) ✅ bench-approved
- Branch `readengine-b-integration`, commits `c3654c1` (HDL) + `7c1fc92` (flip-seed direction) +
  `a7e519a` (daemon: send 'P' only on flip change). Reversible DDA in `pg_addrgen` (h_dir/v_dir
  count down from far-end seed) + **ring flush on v_dir change** (fixes cross-frame have_row
  round-robin deadlock). Justin monitor: "h v looks great"; shift+flip seed corrected (mirrored
  frame still translates the right way); drag-glitch killed (no redundant 2nd GPIO write per drag).
- **ELF-only turns layered on this bitstream (no HDL/bitstream):** Parity Phase 1 operator harvest
  (MONO / BLACK / bypass / color-temp ladder, **D65 6500K = neutral** / fade-to-black — #110),
  ARC presets fill/zoom/4:3/14:9/letterbox (#111), Freeze attempt (#111 — VDMA-halt un-freeze
  unreliable, **abandoned → Phase-4 still-buffer**), frame-grab PNG download (res UART-limited).

## Build #33 — gamma_lut color stage (2026-06-05) ❌ FAILED TIMING — do not use
- Commits `e9e0a28` (gamma_lut.v) + `e87441e` (BD splice + axi_gpio_11). WNS **−3.495**: the
  gamma_lut load-field CDC `*_q1` regs had no `set_false_path` (the recurring −3.5 WNS trap, same
  as color_matrix). Programmed but timing-violating. Superseded by #34.

## Build #34 — gamma_lut + CDC false-paths (2026-06-05) ✅ CLEAN — PRODUCTION gamma substrate
- Commit `0e7406d` (XDC false-paths on `gamma_lut_0/inst/{t,byp,ch,ad,da}_q1_reg`). WNS **+0.222**,
  WHS **+0.016**. `gamma_lut.v` = per-channel 256-entry async-read distributed-RAM tone LUT,
  AXIS-transparent, spliced `color_matrix_0 → gamma_lut_0 → axis_to_vid_io_0`. Load GPIO =
  **axi_gpio_11 @ axi_ic_lite/M14** (NUM_MI 14→15), bits 0=bypass,1=tog,[3:2]=ch,[11:4]=addr,[19:12]=data.
- **ELF-only turns on #34 (no bitstream):** continuous gamma via **on-device fixed-point** curve
  compute (`92d9231`, Q16 isqrt+pow, ≤1 LSB vs float pow — replaced a bulk-UART LUT transport
  `1f6f8d7` that corrupted under status-print bursts → RX-FIFO overflow); slider load-over-live
  no-flash (`9687e66`); write-spacing `usleep` so the toggle-CDC catches every LUT write (`dfa863a`);
  **Phase 3.5 input RANGE override** Full/Limited via color_correct preset (`ab01614`). Latest ELF `dfa863a`.
- Bench (Justin monitor): gamma presets + 0.1 slider clean on normal content; Full/Limited range correct.
- ⚠️ **OPEN #114 (non-blocking) — RE-ATTRIBUTED:** smooth gradients under gamma show periodic
  per-channel chroma. NOT the read engine (sim agent proved `pg_linefetch` bit-exact gray-in→gray-out,
  2 new gray TBs) and NOT the 2-tap AA (toggle = no change). It's the **gamma LUT load**: non-atomic
  per-address R/B/G writes loaded OVER the live LUT, so a fast/large slider change displays a
  half-updated (chromatic) LUT mid-load (load-speed dependent; γ=1.0 clean; small bump clears it).
  Mitigated: slider commits on release (`aa55d42`). Real fix queued: double-buffer `gamma_lut`
  (atomic vsync swap) + agent's `beat_valid && beat_ready` insurance. See [[schindler_gradient_chroma_readengine]].
- **Artifacts archived:** `artifacts/34-720p60/` — re-flash in ~30 s via `scripts/program-archived.sh
  34-720p60` (no rebuild). Per-build archiving (`scripts/archive-build.sh`) is now standard; closes the
  "recreatable but not snapshotted" gap. **GOTCHA:** JTAG re-flash needs the control daemon stopped
  (free /dev/ttyUSB1) or the HDMI input won't re-lock — power-cycle otherwise.

## 1080p30-OUT attempt — UNVERIFIED (2026-06-05) ⚠️ revisit at bench (#115)
- `OUTPUT_MODE=1080p30` build (WNS **+0.030**, timing closed). Only deltas vs 720p60: VTC raster
  1280×720@1650×750 → 1920×1080@2200×1125 (same 74.25 MHz pclk) + firmware `OUTPUT_1080P=1`.
  Read-engine HDL / gamma / color byte-identical.
- Bench: monitor would not display; MS2109 showed wrap ~3× + top-⅓ fill. **INCONCLUSIVE** — the bench
  monitor likely doesn't accept 1080p30 (oddball mode) and the MS2109 mangles a 1080p30 source. Telemetry
  was healthy (VTC configured 1080p30, FRC running, `DRAIN delta_px=0`). Open Q (#115): does the read
  engine emit a true 1920×1080 raster under OUTPUT_1080P, or 720-shaped data into a 1080 raster? Needs a
  1080p30-capable display / scope. Do NOT trust the monitor/MS2109 verdict. 1080-OUT columns blocked on this.

## Build #38 — gamma double-buffer (#114) + H-bilinear resample (#107a) (2026-06-06) ✅ CLEAN, bench-ready
- Commits up to `4a49211` on iter5-1080p-clean. WNS **+0.109**, WHS **+0.016**. Bundles two HDL features,
  both sim-verified bit-exact (latency-independent golden) and built off-bench. **Archived:**
  `artifacts/38-720p60-gamma-bilinear/` → `scripts/program-archived.sh 38-720p60-gamma-bilinear` (~30 s, no rebuild).
- **#114 gamma double-buffer:** `gamma_lut` 2-bank, firmware loads the hidden bank then swaps atomically at
  SOF → kills the load chroma + restores live-drag (replaces the re-attributed read-engine theory; sim TB
  proves loads don't touch the display, swap only at SOF).
- **#107a H-bilinear:** `pg_addrgen` exposes the DDA fraction; `pg_compose` does a fraction-weighted col/col+1
  lerp (filt_mode 2). Firmware Q0.16 reciprocal (`axi_gpio_12`), `filt_mode` GEO_C ch2 [31:30], UART `F 0|1|2|3`,
  UI "Resample" selector. Smooth zoom vs old NN-blocky. TB golden cross-checked (unsigned ref ≡ HW signed lerp).
- **Timing grind (4 builds):** the bilinear lerp blew WNS −7.8 (#35); fixed by pipelining — fw precompute at
  skid-push, stage R0 (register taps), stage R (register lerp), and dropping the provably-dead clamp:
  −7.8 → −5.6 → −0.056 → **+0.109**. Framing is push-time (latency-independent) so the +3 pipeline stages
  only needed +ospace reserve; no SOF/EOL impact.
- ✅ **BENCH-VALIDATED 2026-06-06** (Justin): H-bilinear clean ("works great"); gamma chroma initially
  PERSISTED → root cause = a **multi-bit CDC RACE in the LUT load** (gamma_put wrote data+toggle in one
  GPIO word). **Fixed in firmware** (ELF `ae42930`, data-then-strobe; #38 bitstream unchanged) + re-archived
  `38-720p60-gamma-bilinear`. Gamma chroma GONE + stable across reloads; live-drag restored (`d4c05fb`).
  #114 closed. See [[schindler_gradient_chroma_readengine]].
- Next read-engine: **#107b V-bilinear** (2nd read port; row+1 resident — no 2nd fetch).

## Warp read-engine — TIMING CLOSED + first bench build (2026-06-08) ✅ PROGRAMMED, bench-ready
Experimental arbitrary-geometry read path (pg_affine → pg_tilecache_rt2 tile cache → bilinear → AXIS),
`WARP_ENGINE=1` variant on `iter5-1080p-clean`. Real-time + 7020-fit were already done; this session
**closed timing** and **programmed the first warp build to the board**.

**Timing march (WNS @74.25 MHz, each step both sim gates green + committed):**
| Step | commit | WNS@74.25 | note |
|---|---|---|---|
| storage-shape fix (set-indexed wide-word tag/vld/rsv → LUTRAM) | `ec95a04` | -15.38 → **-4.69** | TIDW 24→16 too |
| avm-snapshot 3-stage prefetch (tag-read out of issue loop; no CAM) | `bf9f0fd` | **-3.60** | prefetch cone SOLVED |
| CDC false-path (warp affine-coeff axi_gpio→pclk async) | `a277861` | **-1.26** | XDC only; removed artifact |
| consumer-private tag+vld replica (cut gather route) | `c12fca3` | **-0.93** | |
| consumer setf-pipeline (×13/×7 mult out of looka) | `441cd6f` | **+0.240** ✅ | TIMING MET (WHS +0.007) |
- Build log `build_logs/warp_build_consumer_setfpipe.log`. Worst path was the consumer gather; the prefetch
  issue cone (the whole prior focus) dropped out. Config: 4-way/NTILE=512/PD=DREQ=64, NO_ILA.
- `lead_rt` runtime-LEAD port added (`7a6b99b`, tied 0 = build-param LEAD; GPIO wiring deferred).

**1080p-out finding (sim):** 4-way/512 holds rot10/rot45/aniso at 1080p-out but worst-angle rot20 needs a
*shallow* lead (≈2048) while rot45 needs *deep* (≈32768) — no single lead covers all angles, so full-angle
1080p rotation needs **runtime per-geometry LEAD** (the `lead_rt` GPIO, iteration 2). Not a capacity wall
(4-way≡8-way at NTILE=512; angle works with the right lead). 1080p60 HDMI out stays Zybo-blocked → the
benchable 1080 target is **1080p30 @ 74.25 MHz** (same timing-closed logic, bigger frame).

**Firmware (first warp bench, `9ca5a8b`):** warp build reuses axi_gpio_8/9/10 as the 6 affine coeffs
(Q20.12); `warp_set_rotation(deg,invx,invy)` (Q12 sin table) writes them; boot = 45° rot; UART `W <deg>
[invx] [invy]` for live rotation. `build_phase_b_app.tcl`: `WARP_ENGINE` → `-DWARP_BUILD -DREADENGINE_FULLMASTER`.

**PROGRAMMED 2026-06-08 (this host, JTAG):** bitstream = setf-pipe `441cd6f` (WNS +0.240, archived
`artifacts/iter5-1080p-clean-720p-scaler_top-enable-441cd6f` and `…-7a6b99b`) + warp fw. UART boot CLEAN:
source 1920×1080 detected, full master captured, `VDMA running`, `WARP rot=45: a=2896 b=2896 c=1036160
d=-2896 e=2896 f=3022720` (coeffs verified correct), `WARP engaged: 1920x1080 → 1280x720`, output VTC
`LOCK=1`, per-row pixel dumps flowing. **Awaiting Justin's monitor verification of the 45° rotated 720p
image.** ⚠️ monitor only, never MS2109. Re-flash: `scripts/program-archived.sh` or `xsct tcl/program_phase_b_full.tcl`
(stop the schindlerd daemon first to free /dev/ttyUSB1). NEXT: 1080p30 build + runtime-LEAD GPIO.

## Warp FIRST BENCH (2026-06-08) — programmed + running; ⚠️ output black: HW deadlock after ~1 line
First warp build on the board. Bitstream = setf-pipe `441cd6f` (WNS +0.240). Firmware = warp affine
(`9ca5a8b`+): reuses axi_gpio_8/9/10 as the 6 affine coeffs (Q20.12), boot rotation, UART `W <deg>`.
Boots CLEAN: source 1920×1080 captured (all 7 DDR slots have image), VDMA running, mux=warp, output VTC
LOCK=1, coeffs verified correct. **But monitor output is BLACK.**

**Triage (eliminated):** capture, frame_base (base 0x10000000 / stride 6226560 match fw), DMA cmd
(addr/len correct, btt=48, 8-byte aligned — unaligned theory dead), mux (found+fixed latent axi_gpio_12
conflict: route-B INVW write flips the warp mux to passthrough → guarded with !WARP_BUILD), output
framing (axis_mux2 passes warp SOF/EOL), color pipeline (boots passthrough), DataMover clocking + HP1
(byte-identical to working route-B).

**Diagnostic instrumentation (pg_warp_top `dbg` → axi_gpio_2, firmware "WARP DBG" telemetry):**
- v1 (`3f3d5f1`): fetch/fill/ovalid ALL active, sts_err=0 → **the warp ENGINE works** (issues DMA cmds,
  fills cache, produces valid pixels). Black is downstream of pixel production.
- v2 (`9979fac`): **opix_nz=1** (real non-black pixels), **lines/frame=0**, fetch_fr/fill_fr FROZEN →
  warp produces ~1 line of correct pixels then **HARD-DEADLOCKS** (prefetch hit LEAD because the consumer
  stopped advancing). Hardware-specific (sim is real-time, never triggers it).
- v3 (`7b94cf0`, building): adds o_ready + stall_oc to classify — o_ready stuck 0 ⇒ OUTPUT-side
  (axis_to_vid_io framing/blanking-flush stopped pulling → backpressure); o_ready=1 + stall_oc growing ⇒
  cache/DMA-bound. **Pending readout.**

**Shell gotcha logged:** `pkill -f schindlerd` self-matches the wrapping shell → exit 144; use `fuser
/dev/ttyUSB1` to free the UART instead. **Daemon caveat:** route-B daemon sends 'G' → clobbers warp coeffs;
INVW guard added but stop it (free ttyUSB1) before warp UART debug.
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

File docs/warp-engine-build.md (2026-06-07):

# Warp read engine — phased build tracker

Greenlit 2026-06-06 (gate passed, corrections math validated). Replaces the line-ring read path
(`pg_addrgen` + `pg_linefetch`) with an **arbitrary-geometry** path (`pg_affine` + `pg_tilecache`),
reusing the existing bilinear / Mackin / compose / FRC-genlock tail unchanged.

| Phase | Module | Status |
|---|---|---|
| 1 | **`pg_affine`** addrgen — incremental 2×3 affine DDA | ✅ done, sim bit-exact (`0a850e6`) |
| 2 | **`pg_tilecache`** fetch — tile DMA + LRU + prefetch | M1 ✅; M2 ✅ model; M3a ✅ gather; **M3b ✅ concurrent real-time cache — tear-free + bit-exact in RTL** (`d9b0e15`, `pg_tilecache_rt2.v`: identity/rot25/rot45/shrink all pass) |
| 3 | **integrate** (`pg_warp_engine`) | **datapath ✅ end-to-end bit-exact + real-time in RTL** (`239e8a8`, `pg_warp_engine_tb` rot20: 0 bit-err, 38376<56100 cyc). Remaining to bitstream: DataMover 2×2-block reorder · genlock/FRC wrap · BD swap · firmware affine coeffs |
| 3 | integrate (swap in for linefetch; wire bilinear/Mackin/compose) | pending |
| 3d | **`pg_tile_dma`** — tile fetch + 2x2 reorder (real DataMover fill) | ✅ real-time + bit-exact (`d63ebec`, `pg_warp_dma_tb`: warp+tile_dma+behavioral DataMover, VTC-paced + V-blank warmup, rot20 underruns=0/bit-err=0/56026<56100 cyc) |
| 3e | cache silicon rework (fits + logic-timing-clean) | ✅ `docs/warp-cache-timing.md` (12k LUT / 48 BRAM, logic 3.9ns) |
| 4a | BD swap: pg_warp_engine + pg_tile_dma into readengine_b_bd.tcl (DataMover, VTC sof, GPIO coeffs, output) | pending |
| 4b | firmware: affine coeffs (a..f) from geometry | pending |
| 4c | Vivado build + timing (the real in-context timing test) | pending |
| 5 | bench (owner) | pending |
| 5b | layer pincushion (radial) + keystone (projective divide) on addrgen | pending |

## Phase 2 — `pg_tilecache` architecture (the design to build)

**Job:** given a stream of source coords `(sx,sy)` from `pg_affine` (with bilinear neighbours), return
the 2×2 source pixels, fetching 32×32 tiles from the genlock-selected DDR frame through a BRAM LRU
cache, **without ever starving the genlocked output** (the real-time gate).

**Params (from the gate, `docs/affine-warp-gate-results.md`):** 32×32 tiles (3 KB), **128-tile cache
(384 KB BRAM)**, prefetch run-ahead + ~128-tile FIFO to absorb the ~115-tile/row worst burst.

**Blocks:**
1. **Tag/LRU store** — 128 entries: {tile_id (frame-relative), valid, lru_age}. Lookup = associative
   compare (or a hashed set-assoc to cut comparators). Hit → BRAM read; miss → enqueue fetch.
2. **Tile BRAM** — 128 × (32×32×3 B). Dual-port: write side = DMA fill; read side = the 2×2 sampler.
3. **Prefetch walker** — runs the SAME affine DDA *ahead* of the consumer by P pixels; for each
   look-ahead pixel, computes its tile(s); if not resident/pending, issues a DMA. This is what hides
   miss latency (the gate showed avg « budget, so run-ahead has slack to pre-pull bursts).
4. **DMA engine** — AXI DataMover (reuse the existing one's pattern): tile = 32 rows × 32×3 B at
   stride = frame width; 32 short bursts, or a 2D descriptor. Fill the inactive tile-BRAM slot.
5. **Sampler** — on the consumer coord, read the 4 neighbour pixels from tile BRAM (handle the 2×2
   straddling up to 4 tiles, like pg_linefetch's window), present to the existing bilinear.
6. **Stall/underrun guard** — consumer stalls if its tile isn't resident yet; the output FIFO
   (existing in compose) covers the slack. The TB must prove FIFO never empties for the worst case.

**Real-time gate (Phase 2 sim):** a behavioral DDR model (latency + burst throughput) drives the
tile DMA; the TB runs the worst transforms (pincushion, rotate-45, shrink) and asserts **the output
FIFO never underruns** + the sampled pixels are **bit-exact** vs a golden warp. This sim IS the
cycle-accurate real-time proof (the Python gate proved bandwidth; this proves no-stall with real
latency). If it underruns: deepen prefetch run-ahead / FIFO, or raise cache associativity — knobs,
not walls (avg bandwidth has headroom).

**Risks / open:**
- Prefetch run-ahead depth P vs DMA latency — tune in sim.
- Frame coherence under FRC: cache invalidates when the genlock ring switches source frame (per-frame
  cold, as the gate modeled). Simplest: flush-on-frame (tag includes frame slot; mismatch = miss).
- BRAM budget: 384 KB cache + ~FIFO vs the 7020 ~600 KB shared with VDMA/scaler — verify at Phase 4.
- Associative tag compare timing at 128 entries — use set-associative (e.g. 4-way × 32 sets) if needed.

## M2 real-time gate findings (cycle-accurate, `tools/tilecache_realtime_gate.py`) — 2026-06-06

Cycle-accurate model: full 720p60 timing (active + blanking), prefetch walker, single-channel DDR
(latency + throughput), output FIFO. Underrun cycles must be 0. **This inverts a bandwidth-gate
assumption** (which counted only avg miss bandwidth): cycle-timing tells a different story.

- **Tile SIZE is the dominant lever.** 32×32 (3 KB/tile) FAILS everything — one bursty row needs
  ~60 misses × 384 cyc ≫ a row. **16×16 tiles (same 384 KB cache)** is the design point.
- **CORRECTIONS are real-time ✅** at 16×16 + ONE DDR port (16 B/cyc): **pincushion, shrink/scale**
  (and keystone, same locality class) — 0 underruns. These are the stated-priority features.
- **The rotation "wall" was a MODEL ARTIFACT (cold start).** First runs put V-blank AFTER active, so
  the cache started cold at pixel (0,0) — manufacturing the rotation underruns. Real 720p60 has ~25
  blank lines BEFORE active (~41k cycles of free prefetch warmup).
- **With correct timing (leading-blank warmup) + a deep prefetch lead (~8192 px ≈ 6 rows): EVERY
  transform is TEAR-FREE at the BASE config — 16×16 tiles, 512-tile (384 KB) cache, ONE DDR port
  (16 B/cyc).** pincushion, rotate-90/30/45, shrink: 0 underruns. Also passes at 2× and 4× DDR, so
  there's large headroom if real DDR is slower than modeled.

**Design point for M3 HDL (LOCKED):** 16×16 tiles, 512-tile (384 KB) cache, **prefetch run-ahead
~6 rows + output FIFO, pre-filled during V-blank**, single DDR port (parameterize port count for
margin). Tear-free for the whole geometry family — corrections AND arbitrary rotation. The two
non-obvious requirements the HDL MUST honor: (1) 16×16 tiles (32×32 is too coarse — bursty rows),
(2) deep prefetch that runs through V-blank so the cache is warm at the first active pixel.

## Phase 5b — corrections on the addrgen (after the engine benches)
Math already validated (`tools/correction_preview.py`): pincushion = radial post-multiply on
`(sx,sy)` (~4 mults/px, pipeline); keystone = projective + per-pixel reciprocal-LUT divide; warp =
9×9 mesh + 2D-bilinear of source coords. Each is an addrgen variant; the fetch is unchanged.

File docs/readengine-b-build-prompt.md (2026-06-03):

# Build prompt — read-engine-B fill-rate fix (post review #2)

Hand this to the implementing agent. Full reviewer findings: `docs/readengine-b-review2-findings.md`.

---

The route-B read-engine's on-screen artifact has been root-caused and independently confirmed (two
review rounds + build #14 192-bit ILA). **It is NOT dither aliasing and NOT corrupted pixels.** It is
an **output-FIFO underrun** (a blank/held band that drifts frame-to-frame) caused by a structural
line-fill rate deficit: the fill is pixel-limited at 1 px/clk through `pg_unpack` (~2200 cyc per
1920-px master line, measured), while one output row's budget is htotal ≈ 1650 cyc, and fetches are
serialized (one in flight). Confirmed bottleneck is the unpack, not DDR (`up_pvalid`=87% during the
fetch). Working dir `/home/justin/Dropbox/_PROJECTS/Schindler-2.0`, Zynq-7020, Vivado 2025.2.

**STEP 0 — confirm the scope fork before writing HDL.** Ask Justin one question: *is zoom-IN past
720-native required for this milestone, or is a 720 master sufficient (zoom deferred to G2)?*

- **If 720 is sufficient → do the cheap fix, not packed-beat.** Un-bypass the input scaler
  (`SCALER_MODULE=scaler_top`), store a 1280×720 master, set the read-engine back to
  `IN_W=1280 IN_H=720 STRIDE=3840` + matching `SLOT_STRIDE`, drop `READENGINE_FULLMASTER`. A 1280-px
  line fills in 1280 < 1650 → no deficit, no stall, no read-side gearbox. One build. Verify ≥3 cold
  boots clean on the **monitor** (not MS2109). Done.
- **If full-master zoom is required → build packed-beat fill** (rest of this prompt).

**STEP 1 — build a latency-modeling sim FIRST (mandatory gate; do not skip).** The current TB cannot
reproduce this bug — `pg_linefetch.v:90-92` says the long-HBLANK sim never overlaps a fill with a
read of the same row. Write a behavioral DataMover model that delivers 64-bit beats at a realistic
rate (≈1 beat/clk with occasional gaps) and drive the compositor from an htotal-bounded output row
clock so the fill (1920 px @ 1px/clk) races the row budget (1650). **Reproduce the underrun in sim
(`m_tvalid=0 & m_tready=1` mid-frame) before changing any RTL.** If you cannot make the stall appear
in sim, stop — you cannot prove the fix.

**STEP 2 — implement packed-beat fill.**
- Store raw 64-bit DataMover beats in the ring at 1 beat/clk, `ceil(IN_W·3/8)` beats per line
  (derive from `IN_W`/`STRIDE` params — NOT a literal 720). `pg_unpack` leaves the fill path.
- **Read side: even/odd beat banks (the highest-risk part).** A pixel straddles two 8-byte beats
  when `(3·rd_col) mod 8 ≥ 6` (i.e. `rd_col mod 8 ∈ {2,5}`). Store even/odd beats in separate banks
  (or true dual-port both-read) so beat `b` and `b+1` come back in ONE cycle; barrel-shift by
  `((3·rd_col) mod 8)·8` and take the low 24 bits. Preserve the single-cycle `rd_data` contract
  (`pg_linefetch.v:109`, consumed by `pg_compose` C0→C1 at `:151-171`). Byte order stays
  low-24-bits = `{R,B,G}` per `pg_unpack.v:8-10` — no swizzle. NN pick → no rounding.
- Keep the decimating DDA exactly where it is (read-time `src_col`/`src_row` pick). This fix is
  pure throughput; it must not change which pixel each output position selects.

**STEP 3 — prove it against the STEP-1 sim.** Require all of:
1. the modeled underrun is gone (no `mtv=0 & mtr=1` during active video, across ≥2 frames);
2. `rd_data`/`push_data` is bit-exact to the existing nearest-neighbor golden at 1:1 and at 1.5×;
3. **no read-rate stall at the straddle columns** (`rd_col mod 8 ∈ {2,5}`) — assert 1 px/clk holds
   there specifically;
4. timing closes (report WNS).

**STEP 4 — one bench build, verify on the MONITOR.** Engage via `uart_cmd.py "G 1280 720 0 0"`,
steady solid color AND grid (Osee input 1). Confirm the drifting band is gone across ≥3 cold boots.
Re-capture `tcl/capture_re_ila.tcl` + `python/bench/decode_re_ila.py` and confirm: no 600-cyc
residency stalls, no underrun, `push_en`-gated pixels clean.

**Do NOT:** reprogram or start a competing Vivado/xsct session while a build is running; `git
checkout` mid-build; trust an MS2109 capture for the visual verdict; or add the anti-alias box filter
in this change — that's a separate G2 step on top of a clean engine.

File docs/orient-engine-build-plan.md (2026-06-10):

# Orient Engine — clean build plan (spec → bench)

**Date:** 2026-06-10. **Decision:** clean restart (per `orient-engine-decision.md`). This is the
self-contained build plan for a fresh agent to take the orient engine **all the way to a verified
bench test.** Companion: `orient-engine-decision.md` (why), this doc (how).

> **The one architectural idea that makes this clean:** the final scope (cardinal orientations + mild
> warps) is **deterministic** — known-ahead, structured source access. So the engine is a
> **deterministic, double-buffered output-tile pipeline with a direct region buffer — NOT an
> associative cache.** Every hard problem the prior branch fought (set-hash resonance, eviction,
> LEAD×associativity, the 512:1 mux, the −28 ns prefetch cone, the soft-reset black-flash) was an
> artifact of a cache built for *arbitrary* rotation. We don't need that cache. Build the deterministic
> pipeline and those whole problem families never appear.

---

## 1. Spec (frozen)

A production read-engine: captured **1080p source** → **oriented + scaled + positioned** output.

- **Orientation:** the four cardinals **0 / 90 / 180 / 270** only. (Arbitrary rotation is a separate
  future feature — do **not** build for it.) 90/270 are transposes.
- **Scale:** zoom; **100% = fit-to-output** (oriented source fits the raster, letterboxed,
  aspect-preserved). Zoom-in crops, zoom-out shows matte.
- **Position:** signed pan in output pixels; matte fills the vacated edge.
- **Mild warps (phase 2):** keystone / 4-corner / pincushion — bounded-local 2-D warps, bilinear.
  Architect the bilinear path for them; wire them after cardinals+scale+pan are clean.
- **Output:** 1280×720 on the Zybo bench; **1080p60 on production TE0720, same RTL** (Zybo just can't
  serialize 1485 MHz TMDS — `[[zynq7020_rgb2dvi_1080p60_limit]]`).
- **Quality (hard):** no tearing, **no per-change black flash**, clean at all four orientations across
  the full zoom/pan range, stable across ≥3 cold boots.
- **Constraints (hard):** XC7Z020-1; **140 BRAM, ~100% used**; one HP port **≈1.14 GB/s**; per-pixel
  datapath closes **148.5 MHz** (1080p60). Per `orient-engine-decision.md` §3 the per-pixel path is
  shallow (read-BRAM→bilinear, +1.8 ns @148.5) — **timing is not the risk; DMA throughput is.**

## 2. Architecture (the clean engine)

```
 1080p source ─ S2MM (tiled geom) ─► DDR as 16×16 tiles  [pg_raster_to_tile / ORIENT_TILED]
                                          │  (layout chosen in Step 2 — Z-order / 2-copy / strided+coalesce)
   pg_affine_tile (output-tile DDA) ──────┤  per OUTPUT tile: which SOURCE tile(s) it samples + frac + in-window
        (fit-scale + pan + orient,         ▼
         firmware coeffs)          pg_tile_dma TILED ─► REGION BUFFER ─► bilinear ─► pg_tile_to_raster ─► AXIS
                                  (coalesced 768B/tile)  (direct, double-   (2-stage)  (band→raster,        │
                                                          buffered, 4-bank,            SOF-early framing)   ▼
                                                          NO eviction/hash/LEAD)                    color stack ─ axis_to_vid_io ─ HDMI
```

- **Region buffer = the cache replacement.** Sized for **one output tile's source footprint**
  (worst case 90° fit s≈2.67 → ~4×4 source tiles, decision §9 Q3), **double-buffered** (fill next
  output tile's tiles while gathering the current). **4 parity banks** for a 1-cycle 2×2 bilinear
  gather. **No eviction, no set-hash, no LEAD** — it's a direct buffer over a deterministic walk.
- **Transpose (90/270)** is handled by the affine mapping (output tile → transposed source tile) and
  the DMA layout chosen in Step 2 — *not* by any cache cleverness.
- **Framing:** use `pg_tile_to_raster`'s band reorder with **SOF-early** to replace the line-FIFO
  entirely (decision §9 Q5) → kills the wrap *and* the black-flash; emit **TUSER=SOF / TLAST=EOL** for
  the downstream SOF-realign in `axis_to_vid_io`.

## 3. Reusable assets — cherry-pick to the fresh branch (do NOT re-derive)

| Asset | File | State |
|---|---|---|
| Fit/pan/orient affine + UART | `sw/phase-b/src/main.c` `warp_set_rotation`, `W`/`L` | bench-correct |
| Tile-order affine DDA | `hdl/pg_affine_tile.v` | sim bit-exact |
| Output band→raster reorder | `hdl/pg_tile_to_raster.v` | sim bit-exact |
| Raster→tiled-DDR writer | `hdl/pg_raster_to_tile.v` | sim bit-exact |
| Tiled tile-DMA | `hdl/pg_tile_dma.v` `TILED=1` | sim-valid (needs coalescing — Step 2) |
| Tiled-DDR BD recipe + S2MM geom | `build_phase_b.tcl` splice, `main.c` `#ifdef ORIENT_TILED` | bench-running |
| Throughput proof / golden / OOC | `tools/orient_throughput_proof.py`, `orient_golden.py` | done (re-derive in Step 2) |

**DROP (the baggage — do not carry forward):** `hdl/pg_warp_engine.v`, `hdl/pg_tilecache_rt2.v`, the
soft-reset, the line-FIFO. These are the arbitrary-warp cache the scope no longer needs.

## 4. Build sequence (each step has a gate that must pass before the next)

**Step 1 — Fresh branch + asset transfer.** Branch from trunk (`iter5-1080p-clean`). Cherry-pick the
§3 files. Confirm they `add_files`/build on trunk. *Gate:* clean branch, proven modules present, the
DROP list absent.

**Step 2 — RISK-FIRST: prove the transpose-DMA budget before building the core.** This is the only real
unknown and it gates the architecture. The old throughput proof assumed 768 B bursts sustain all
orientations — **the bench showed they do NOT** (command overhead + page-misses; decision §9 Q2.b).
- Re-derive `orient_throughput_proof.py` **with realistic command/page overhead and coalescing**, and
  **with S2MM write sharing the port** if it does.
- Decide the transpose layout: **Z/Morton-order tiles** (both axes semi-contiguous, one copy) vs **two
  copies** (raster + transposed, +1 write pass) vs **strided + coalesce the contiguous axis**. Pick by
  the proof, not by preference.
- *Gate:* amortized read **≤ ~70% of 1.14 GB/s for ALL orientations including 90/270 + max zoom-out**,
  with overhead modeled. If no layout hits it on one HP port, escalate (2nd HP port? read-sequential
  /reorder-on-chip?) **before** building the core — do not build the core on an unproven budget.

**Step 3 — Build the deterministic core.** Region buffer (direct, double-buffered, 4-bank, no cache) +
output-tile walk + bilinear + the Step-2 coalescing/layout. *Gate:* `xsim` **bit-exact vs
`orient_golden.py`** for: 0/90/180/270, one fit-scale (e.g. 50% zoom-out), one pan, and (phase 2) a
keystone + a pincushion. Underruns=0 at the modeled fill rate.

**Step 4 — Integrate.** BD splice (tiled S2MM + the recipe), output-tile→raster reorder with **SOF-early
framing (no line-FIFO)**, color stack, `axis_to_vid_io`. *Gate:* `pg_warp_top`-equivalent TB passes
(TUSER@px0, TLAST@EOL, frame completes).

**Step 5 — In-context build.** Vivado synth→impl→bitstream, **`NO_ILA=1`**. *Gate:* **WNS ≥ 0 @148.5
MHz**, BRAM fits 140 (reorder band ~40 + region buffer + the rest — budget explicitly), DRC clean,
`.xsa` produced. (Per decision §3 the path is shallow, so this should close — if it doesn't, the core
re-introduced cache-depth; check for it.)

**Step 6 — Bench (the acceptance test).** *Gate (all required):*
- **Monitor truth, not MS2109** (`[[schindler_ms2109_verification_trap]]`); verify the Osee input first
  (`[[schindler_osee_switcher_topology]]`).
- All **four orientations** correct (0/90/180/270), **full zoom range** (fit → zoom-in crop → zoom-out
  matte), **full pan range**, matte clean at edges.
- **No tearing, no black-flash on any orientation/scale/pan change**, **≥3 cold boots identical**
  (`[[schindler_no_coin_flip_rule]]`, `[[schindler_build_provenance_rule]]`).
- Record the result in `docs/build-manifest.md` with reboot count + modes tested.

## 5. Gotchas (paid for already — respect every one; decision §8)

- `export BOARD_PARTS_REPO_PATHS=$HOME/fpga/vivado-boards/new/board_files` before any Vivado.
- `NO_ILA=1` frees ~32 BRAM / ~10k LUT — use it; UART telemetry (`starved=`, `opix/frame=`) is separate.
- **BRAM is 100% full** — the reorder band alone is ~40 BRAM (16×OUT_W×24 deep). Budget the region
  buffer + band explicitly against 140 before building.
- `add_files` module-ref HDL in `build_phase_b.tcl` **before** `create_bd_cell`. AXIS splice needs
  `s_axis_*/m_axis_*` port naming for interface inference.
- **1080 is not a multiple of 16** (67.5 tile-rows) — **pad source to 1088** (simplest) or handle the
  partial last band in writer+reader. Decide once, early.
- Tiled S2MM geom: HSIZE=768, VSIZE=tiles/frame, STRIDE=768 (`#ifdef ORIENT_TILED`).
- **Progress only happens via launched builds** — background tasks re-invoke the agent; "status"
  without launching a build = no progress.
- Daemon: venv `/tmp/schindlerd-venv/bin/python3` (ephemeral — recreate if gone), catalog
  `control-plane/catalog-v0.2.0.json`, launch from `control-plane/schindlerd/`; check with
  `ps -eo args | grep schindlerd.py | grep -v grep` (pgrep self-matches).

## 6. Discipline (the lessons this project paid for in blood)

- **Sim-gate every module bit-exact before silicon**, and gate the *real* failure — model fill/throughput
  with realistic overhead, not an idealized DataMover (the 768B-burst assumption already lied once;
  the long-blanking sims lied before that).
- **Test the failure a fix introduces**, not just the one it cures.
- **Monitor is truth.** Every MS2109-verified "pass" in this project's history was later overturned.
- **3-boot or it didn't happen** — no coin-flip builds, no lucky boots.
- **Deterministic beats clever.** The entire win here is choosing a structure with no eviction/hash/LEAD
  to tune. If a design choice reintroduces "tune this parameter per transform," it's the wrong choice.
- The prior weeks were **not wasted** — they proved the spec, the tiled-DDR backend, and the output-tile
  structure. This build reassembles validated pieces on a clean foundation; the only genuinely new work
  is the transpose-DMA proof (Step 2) and the cache→region-buffer core (Step 3).

## 7. Definition of done
A fresh-branch bitstream that, on the bench monitor, renders the 1080p source at **all four cardinal
orientations + full zoom/pan**, **tear-free and black-flash-free across live changes**, **identical
over ≥3 cold boots**, closing **148.5 MHz** and fitting **140 BRAM** — recorded in `build-manifest.md`.
Keystone/4-corner/pincushion follow as phase 2 on the same proven bilinear path.

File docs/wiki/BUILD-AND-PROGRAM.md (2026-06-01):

# Build and Program

How to go from source code to a board with running firmware.

## Toolchain (pinned)

| Tool | Version | Path |
|---|---|---|
| Vivado | 2025.2 | `/tools/Xilinx/2025.2/Vivado` |
| Vitis | 2025.2 | `/tools/Xilinx/2025.2/Vitis` |
| Digilent board files | `36f34ab687b7fa9c778b779d027f3bce63b3ace9` (2025-07-15) | `~/fpga/vivado-boards/new/board_files` |
| Digilent IP library | `f4613fff005b098065fd5d619a2b88e55720a423` (2024-05-16) | `~/fpga/vivado-library/ip` |

Re-verify Phase A passthrough + iter5-1080p-clean 720p60 build after any tool/board/IP update. See `../build-manifest.md` Reproduction footer for the canonical list.

## Vivado build

```bash
cd /home/justin/Dropbox/_PROJECTS/Schindler-2.0

source /tools/Xilinx/2025.2/Vivado/settings64.sh

export BOARD_PARTS_REPO_PATHS=$HOME/fpga/vivado-boards/new/board_files
export DIGILENT_IP_REPO_PATH=$HOME/fpga/vivado-library/ip

# Default scaler module (production):
SCALER_MODULE=scaler_top vivado -mode batch -nojournal \
    -log build/build_iter5_$(date +%s).log \
    -source tcl/build_phase_b.tcl
```

`SCALER_MODULE` env var picks the scaler. Options:
- `scaler_top` — production (iter12+iter13+iter13b 2-tap boxcar)
- `scaler_crop_bypass` — iter4h-era diagnostic: 1280×720 crop, no scaling. Useful for bisection.
- `scaler_bypass_1080p` — 1080p substrate diagnostic

Vivado build time: ~25-30 min on typical workstation. Output: `build/phase_b.xsa`.

## Vitis ELF build

```bash
source /tools/Xilinx/2025.2/Vitis/settings64.sh
xsct tcl/build_phase_b_app.tcl
```

~30 seconds. Output: `build/vitis-phase-b/vdma_init/Debug/vdma_init.elf`.

**Stale-copy gotcha:** Vitis `importsources` copies source into the project tree. Subsequent edits to the original do NOT propagate to incremental builds. **Solution:** after editing `sw/phase-b/src/*.c`, force re-copy by re-running the full Vitis tcl, not just an incremental rebuild. Cost us 3 lost iterations on 2026-05-14; see memory `vitis_importsources_stale_copy`.

## Program the board (JTAG)

```bash
source /tools/Xilinx/2025.2/Vitis/settings64.sh
xsct tcl/program_phase_b_full.tcl
```

Programs the .bit then loads + starts the .elf. ~30 seconds.

**Verify it worked:** open serial on `/dev/ttyUSB1 @ 115200 8N1`. Should see VDMA init + telemetry within a few seconds.

## Build artifact archive — swap builds in 30 seconds

Every successful Vivado + Vitis build auto-archives its `phase_b.bit`, `phase_b.xsa`, `ps7_init.tcl`, `vdma_init.elf`, and a `manifest.txt` into `build/artifacts/<tag>/`. Tag scheme:

```
<branch>-<output_mode>-<scaler_module>-<color_pipeline>-<commit>
```

Examples:
- `iter5-1080p-clean-720p-scaler_top-enable-6e4bd80`
- `iter5-1080p-clean-1080p30-scaler_bypass_1080p-enable-083239a`
- `phase-e1-pll-spike-720p-scaler_top-enable-e0b62b7`

**Disk cost:** ~5.6 MB per saved build (`phase_b.bit` = 4 MB, `phase_b.xsa` = 1.3 MB, ELF = 305 KB, ps7_init.tcl = 35 KB, manifest = 0.5 KB). 100 saved builds ≈ 560 MB. `build/` is gitignored so this never pollutes the repo.

### Reprogram from a saved build (no rebuild)

```bash
source /tools/Xilinx/2025.2/Vitis/settings64.sh

# List available builds:
xsct tcl/program_artifact.tcl

# Program a specific one (substring match works if unique):
xsct tcl/program_artifact.tcl 1080p30
xsct tcl/program_artifact.tcl iter5-720p-scaler_top-enable-6e4bd80
```

Same canonical Zynq-7000 bring-up sequence as `program_phase_b_full.tcl`. ~30 seconds vs ~30 min rebuild.

**Caveat:** archive happens at successful end of build. If you run only Vivado without Vitis, the tag dir gets the XSA + manifest but not the `.bit`/`.elf`. Re-running Vitis backfills.

## Interacting with the running firmware

Two options, **mutually exclusive** because both want exclusive access to `/dev/ttyUSB1`:

### Option A — picocom (human-facing UART)

```bash
picocom -b 115200 /dev/ttyUSB1
```

Type `?` for the command list. See [FIRMWARE-INTERFACE](FIRMWARE-INTERFACE.md) for the full reference.

### Option B — schindlerd + browser (V0a control plane)

```bash
# One-time install
python3 -m venv /tmp/schindlerd-venv
/tmp/schindlerd-venv/bin/pip install -r control-plane/schindlerd/requirements.txt

# Run
/tmp/schindlerd-venv/bin/python control-plane/schindlerd/schindlerd.py -v
```

Then open [http://127.0.0.1:8080](http://127.0.0.1:8080). Daemon owns `/dev/ttyUSB1` while running; pkill it to switch back to picocom. See [SCHINDLERD-RUNBOOK](SCHINDLERD-RUNBOOK.md) for troubleshooting + ports + flags.

## Makefile shortcuts

Top-level `Makefile` wraps the common operations:

```bash
make test          # pytest harness (53+ tests, ~1s, no bench)
make sim           # Python kernel-compare sim + sha256 diff vs golden
make ci            # test + sim
make build         # Vivado HDL build (Vivado env required)
make build-app     # Vitis ELF build (xsct env required)
make program       # JTAG program (xsct env required)
make sim-vivado    # xsim testbenches (Vivado env required)
make sim-bootstrap # regenerate sim/golden/ from a legitimate kernel change
make help          # one-line summary of every target
```

`make ci` is the recommended check before committing — fast, no bench, catches catalog/parser/daemon regressions plus kernel-sim divergence.

## Common pitfalls

### IP version sensitivity

Memory `digilent_rgb2dvi_kclkrange_limit`: Digilent's rgb2dvi only accepts `kClkRange={1,2,3}` → blocks 480p over HDMI. The patch lives in `~/fpga/vivado-library/ip/dvi2rgb/component.xml` — if you re-pull vivado-library upstream, the patch is gone.

### Pin naming confusion

Memory `pmod_pin_naming`: ALWAYS reference "Pmod JB Pin 7" (physical pin), never "JB5" (Digilent signal-index). The two conventions don't agree and miswiring is easy.

### MMCM budget

Memory `zynq7020_mmcm_budget`: Zynq-7020 has only 4 MMCMs. iter5-1080p-clean uses 2 (`clk_wiz_pixclk_out`, `clk_wiz_ref`); the dvi2rgb IP may consume one or two internally. Any 5th clock generator must be `PRIMITIVE=PLL`.

phase-g-iter1 is at the budget ceiling (4 clk_wiz cells active). See `schindler_phase_g_clkwiz_zombie` memory.

### Async-CDC WNS soft fail

Vivado will report WNS=-3.5 ns (or thereabouts) on color-pipeline paths. This is a known issue — the timing-ignore constraints don't match Vivado's hierarchical names. Functional via `ASYNC_REG`. Documented for fix; not blocking.

<!-- AGENT_TASK[hdl-4]: Fix the async-CDC false-path constraint pattern so WNS reports clean. Currently functional via ASYNC_REG but Vivado complains every build. -->

## Building other branches

Same workflow; just `git checkout <branch>` first. Each branch is self-contained (no submodule indirection). Vivado will pick up whatever `tcl/build_phase_b.tcl` is at the checked-out tip.

See [BRANCHES](BRANCHES.md) for what each branch produces.

## CI / automation

**There is no CI.** The 2026-05-30 Risk Auditor flagged this as a structural risk. All build verification is manual.

<!-- AGENT_TASK[test-1]: Build a minimum-viable CI pipeline. Vivado batch + Vitis batch + Python sim suite (`python/` directory) on push to iter5-1080p-clean. Skip programming step (no bench). -->

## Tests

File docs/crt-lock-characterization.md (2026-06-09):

# Schindler 2.0 — CRT Lock Characterization & Composite-Output Crafting

**Status:** Draft 2026-06-06 — captures the CRT-compatibility model, the MVPHD-24 trick catalog, the preset framework, the active-line/scaler coupling rule, and the composite-output ownership map. Decisions banked from the 2026-06-06 session. **Not yet bench-validated** — the per-model lock ranges are a bench output, not a literature output (see §11).

**Purpose:** SSOT for two questions — *"how much range do we have to coax a CRT into locking at film rate, and how do we craft the signal to do it"* and *"which block owns the composite output."* Grounds the intelligent-timing-module design in the MVPHD-24 reference behavior so we mimic it rather than reinvent it.

**Sources:**
- `MVPHD-24-flyer-v2.pdf` — Appendix A Specifications, "COMPOSITE OUTPUT FORMATS" table (the format recipe).
- `MVPHD-24-OM-v0-9-0.pdf` — Ch. 4 "Overview of 24 Fps Video Playback" (pp. 45–48); Ch. 5 "Tips and Suggestions" (pp. 49–53).
- NTSC receiver vertical-sync pull-in patents (US 4,425,576; US 4,489,343) for the count-type lock windows.
- Internal: [[signal-flow]], [[dev-roadmap]], [[mvphd-comparison]], [[rf-modulator-subsystem]].

---

## 1. The core constraint: horizontal is free, vertical rate is the whole game

For driving a CRT at film cadence, the horizontal oscillator is a non-issue — 24 fps lands the line rate at ~15.6–15.75 kHz, within a few hundred Hz of standard NTSC (15.734 kHz), inside every set's horizontal AFC capture range. **The entire problem is vertical.** 24 fps forces a field rate (48 Hz interlaced, or 24 Hz progressive) that sits below where most sync circuits will lock, and how much room exists depends almost entirely on the set's **vertical-sync architecture**. That architecture sorts CRTs into hard buckets (§2).

The whole premise (MVPHD OM Ch. 4, p. 45): make the video frame rate equal the camera frame rate, so exactly one whole image is exposed per shutter opening and the rolling light/dark band disappears. Everything else is in service of getting the CRT to *accept* that film-rate signal.

---

## 2. CRT buckets by vertical-sync architecture

| Bucket | Vertical-sync type | Lock behavior | 24 fps native? |
|---|---|---|---|
| **A — IC count-type** (~mid-80s consumer onward) | Digital line-counter, no user controls | Hard pull-in window: broadcast mode ~57.8–61.5 Hz, widest (VTR) mode ~54.6–65.6 Hz. Rejects anything below ~54.6 Hz. | **No.** MVPHD OM (p. 49): these "must be modified in order to be used." |
| **B — Pro CRT monitors** (PVM/BVM/Ikegami) | Multiformat autolock | Lock standard rates 50/60 Hz; 50 Hz is the lowest native. External-sync inputs allow a CUSTOM genlock rate. Native 24 not a documented CRT mode. | Marginal — via the PAL/50 window or ext-sync CUSTOM. |
| **C — Analog-hold vintage** (~50s–early 80s) | Free-running oscillator + vertical-hold pot | Wide, adjustable, can be coaxed off-standard. **The trickable class** — the '73 Zenith. | **Yes**, native 48 Hz field, if the hold range reaches ~48 Hz. |

**The multistandard sub-case (cuts across A and B).** A set that accepts PAL (50 Hz) switches into a **PAL vertical window** when it sees PAL-class line counts/horizontal — and that window is centered on 50 Hz reaching *down to ~44 Hz* (PAL count range 288–356 lines). 48 Hz (= 24 fps) sits inside it. This is the lever the MVPHD's PAL-dialect exploits (§3.2). A truly **NTSC-only** count-type set has no PAL window and cannot be reached this way.

**Honest ceiling:** the MVPHD itself does not have a software trick for NTSC-only count-type sets — it tells the operator to modify the hardware (OM p. 49). We inherit that ceiling. Our presets help the *multistandard* subset and the analog sets; NTSC-only IC sets are modify-or-3:2.

---

## 3. The MVPHD trick catalog (mimic, do not reinvent)

### 3.1 Two 24 fps dialects + the full format table

The MVPHD outputs **genuine 24 fps** — interlaced 2:1, 48 Hz field rate — with a non-standard line count chosen to keep the horizontal rate in the CRT's comfort zone. From the flyer's COMPOSITE OUTPUT FORMATS table ("interlaced 2:1 with user controlled active lines of video"):

**NTSC / NT443 / PAL-M family:**

| Fps | Horizontal | Lines/frame |
|---|---|---|
| 23.976 | 15.752 kHz | 657 |
| 24.000 | 15.720 kHz | 655 |
| 25.000 | 15.625 kHz | 625 |
| 29.970 | 15.734 kHz | 525 |
| 30.000 | 15.750 kHz | 525 |

**PAL / SECAM / PAL-N family:**

| Fps | Horizontal | Lines/frame |
|---|---|---|
| 23.976 | 15.608 kHz | 651 |
| 24.000 | 15.624 kHz | 651 |
| 25.000 | 15.625 kHz | 625 |
| 29.970 | 15.734 kHz | 525 |
| 30.000 | 15.750 kHz | 525 |

Mechanism: to drop the frame rate to 24 while holding the horizontal near-standard, **add lines** (525 → 655 NTSC, → 651 PAL). Field rate is 48 Hz either way.

### 3.2 The PAL-dialect is native 24 in PAL clothing (not a speed conform)

The PAL-family 24 fps row keeps horizontal at **15.624 kHz ≈ exact PAL (15.625)**. A multistandard set sees PAL-class horizontal + line count, enters **PAL mode**, and opens its 50-Hz-centered vertical window that reaches down to ~44 Hz — which brackets the 48 Hz field rate. Result: the set locks a **genuine 24 fps** signal. No speed change, no post conform — it's native 24 dressed as PAL so the lower PAL sync window accepts it.

A literal "run 25, slow to 24 in post" conform is only a **fallback** for a set whose PAL window locks 50 Hz solidly but won't quite reach 48 (§4, §5).

### 3.3 Vertical lock requirement — the honest ceiling (OM p. 49)

Sets with a vertical-hold control (analog, Bucket C) generally have enough range to lock 24 fps. Newer sets with a digital locking circuit and no controls (Bucket A) may not lock at 24 fps and **must be modified** to be used. The reference device does not crack count-type sets in software; neither do we.

### 3.4 Shutter angle ↔ blanking: the active-line lever (OM Ch. 4–5, pp. 47–53)

The blanking interval hides the field seam, giving shutter-angle latitude around 180°:
- Standard 24 fps ≈ **300 active lines/field of 655 total**.
- Min shutter angle = 300/655 = 45.8% → **164.9°** (captures all of field 1).
- Max shutter angle = (655−300)/655 = 54.2% → **195.1°** (before field 2 begins to expose).
- Standard ~8% blanking → tolerance of ±14° around 180° before a visible band appears; tolerance tightens as you approach the edge.

**Extending the range:** reduce vertical active size to widen blanking. Floor is **150 active lines/field** (50%), giving max angle (655−150)/655 = 77.1% → **278°**. The picture then looks vertically compressed on the CRT; the operator re-stretches it with the **monitor's own vertical-size control** (use the Sizing Chart pattern). Add extra guard blanking to cover phase/frequency tolerance when running near the limits.

So **active-line count is a first-class parameter** (a shutter-angle lever), not just a porch tweak. See §8 for how it ties to the scaler.

### 3.5 Genlock to anything; camera-as-reference (OM p. 51)

The MVPHD locks to a frame square wave, vertical drive, composite sync (no burst), black burst, or HD tri-level — and can lock directly to a **single camera's shutter/frame/V-drive signal** with no sync box (the monitor is phase-adjusted instead of the camera). Matches our camera-as-reference plan.

**Gotcha:** if the camera's shutter signal is *mechanically* generated, color-phase (tint) errors can appear on composite/Y-C outputs — for mechanical shutter signals, recommend **component output**. Bank in operator guidance.

### 3.6 Shutter phasing — F1-BLU/F2-YEL (OM p. 52)

Field-alternating pattern (blue field 1, yellow field 2) that reads as flashing gray to the eye. With a 180° shutter the camera sees one field — solid blue or solid yellow when phased; split blue/yellow when mis-phased. Already banked in our spec as **Shutter Phase Reference** (color pair operator-selectable). This is also the natural manual aid alongside the camera-feed auto-phasing loop (§7).

---

## 4. Rate strategies to land inside a lock window

| Strategy | Field rate | Works on | Notes |
|---|---|---|---|
| **Native 48 (NTSC dialect)** | 48 Hz | Bucket C analog-hold | 655 lines / 15.720 kHz. Relies on vertical-hold range reaching 48 Hz. |
| **Native 48 (PAL dialect)** | 48 Hz | Multistandard A/B | 651 lines / 15.624 kHz. Locks via PAL window (§3.2). Native 24, no conform. |
| **60 Hz + 3:2 pulldown** | 59.94 Hz | Bucket A (incl. NTSC-only) | CRT runs standard; content is 24p-origin via 3:2. Cadence judder handled by shutter sync. The only path for NTSC-only IC sets short of hardware mod. |
| **25→24 conform** | 50 Hz | Multistandard A/B that won't reach 48 | Shoot camera + CRT both at 25 (coherent), conform 25→24 in post (4.2% slowdown). Fallback only; PAL-dialect native-48 is preferred. |
| **72 Hz (3 fields/frame)** | 72 Hz | Rare wide/multisync | Pushes *up* instead of down. Above the count-type 65.6 Hz ceiling, so only very tolerant sets. |

---

## 5. Presets (3 + CUSTOM, mirroring the MVPHD dialects)

1. **Vintage Analog / Native 24** — Bucket C. NTSC dialect (655 lines / 15.720 kHz), 48 Hz field, wide back porch, classic equalizing/serration VBI, generous hold margin.
2. **PAL-dialect 24** — multistandard A/B. 651 lines / 15.624 kHz, native 24 in PAL clothing. (This is the "make it look like PAL" idea — it's a real MVPHD mode.)
3. **Modern Consumer / 3:2** — Bucket A (incl. NTSC-only). 59.94 Hz + 24p-origin 3:2, shutter-synced. The "can't get native 24 but can still shoot it" fallback.
4. **25→24 conform** — fallback for sets that lock 50 solidly but not 48 (post-conform required; flag in operator notes so a US crew doesn't shoot a day at 25 thinking it's native 24).
5. **CUSTOM** — always available; per-set tuning never goes away.

---

## 6. Intelligent timing module — decision logic (PS-side)

The module sits on the Zynq PS, above `vid_timing.v`, and chooses parameters; the genlock loop fixes the frame rate; the module decides the raster *shape*. Decision flow:

- **Set is analog-hold (Bucket C)?** → Native 48, NTSC dialect. Tune active-lines/porch via the camera-feed loop.
- **Set is multistandard (A/B with PAL window)?** → PAL-dialect native 48 first; fall back to 25→24 conform if it won't reach 48.
- **Set is NTSC-only count-type?** → 60 Hz + 3:2 + shutter management (or hardware mod — out of our scope).
- Always expose **CUSTOM**.

Free parameters the module controls (everything the locked frame rate leaves open): total line count + dialect, field/interlace structure, front/back porch + sync widths, VBI (equalizing/serration counts), burst phase per field, sync/pedestal levels, and **active-line count** (the shutter-angle lever, §3.4 / §8).

Tier question is open (§12): Tier 2 (model-based solver from a few measured CRT constants) is the v1 target; Tier 3 (closed-loop adaptive via the camera feed) is the headline R&D bet.

---

## 7. Sensor: the camera feed (not a yoke pickup)

Decision 2026-06-06: lock quality is observed from the **camera shooting the CRT**, not a magnetic yoke pickup. Rationale: the only thing that matters is the on-camera result, so optimize directly against it — analyze the operator's return feed (or a tap) for the rolling-bar signature (vertical unlocked), tearing (horizontal unlocked), and shutter-beat flicker. This folds shutter phasing (§3.6) into the same loop. Yoke-pickup path dropped.

---

## 8. Active-line ↔ scaler coupling rule (resolved 2026-06-06)

**One parameter drives both** the composite present-geometry resampler's vertical output size *and* `vid_timing.v`'s active-line count. When active lines are reduced for shutter-angle headroom (§3.4), the composite read engine **resamples the full master image down into exactly that many active lines — it shrinks, it never crops.** The freed-up lines go to blanking, distributed symmetrically (image centered).

This is the MVPHD "Vertical Size" behavior (OM p. 53): shrinking active size compresses the picture on the CRT; the operator re-stretches with the monitor's vertical-size control. **We cannot un-compress it in our pipeline** — the CRT sweeps full screen height regardless of active-line count; we only control how many lines carry picture. Our job is to keep all content intact and centered.

Implementation notes:
- The vertical resize lives in the **composite present-geometry stage** (the per-output analog resampler in [[signal-flow]]), downstream of the shared master — *not* the input format-scaler.
- The polyphase vertical scaler already does arbitrary scale factors; this is a parameter change, not new hardware. 50% floor (150/300 active) from the reference device.
- Active-line change must update the scaler's V scale factor **and** the timing's blanking split in the **same frame** — coordinated atomic write via the sequence-numbered AXI bridge (`PL_BRIDGE`), or it glitches.

---

## 9. Composite-output ownership map (Q2)

**The composite signal is generated by the composite terminal encoder in the FPGA PL fabric.** Concretely, the Phase 2 HDL cluster:

- `vid_timing.v` — raster engine: line counts (655/651 dialect), sync widths, porches, pixel clock, **active-line count**. *Every timing trick lands here.*
- `vbi_gen.v` — vertical blanking structure: equalizing/serration pulses, blanking-line distribution (incl. the extra blanking when active size shrinks).
- `chroma_gen.v` — colorburst and (Phase G onward) I/Q chroma modulation: NTSC-vs-PAL color encoding, per-field burst-phase alternation.
- **composite present-geometry resampler** — the per-output reader that does the §8 vertical resize ("present-geometry — analog" stage in [[signal-flow]]).

Blocks that *direct* the encoder but don't generate the signal:
- **Genlock loop** — sets the frame rate (locks master clock to the camera reference).
- **Intelligent timing module** (PS) — chooses parameters (dialect, active lines, preset) and pushes them to `vid_timing.v` over the AXI bridge.
- **DAC** — ADV7393 (production) / R-2R ladder (Zybo bench) — converts the encoder's digital samples to analog composite. Makes zero decisions.

**Roadmap location:** all composite-output crafting is **Phase G** ("re-attach the analog terminal encoders") in [[dev-roadmap]], building on the scope-validated Phase 2 HDL. The intelligent timing module is the new PS-side layer on top.

---

## 10. Over RF (carrier-coherence correction)

**Correction to bank** (and to propagate into [[rf-modulator-subsystem]] — see §12): the RF **picture carrier** does *not* need to phase-lock to the genlock loop or be reprogrammed when timing changes. NTSC RF is negative-modulated AM; the tuner recovers the composite envelope, and all frame/line timing lives in that recovered baseband. The carrier is just transport — it needs to be frequency-stable and in-channel, nothing more. The only line-rate-coherence requirement is the **3.58 MHz color subcarrier**, which is a baseband concern handled inside `chroma_gen.v`, identical whether the output goes to the BNC or the modulator. The RF doc's dedicated, fixed, stable RF Si5351 was correct; the earlier verbal claim that it must track genlock was wrong.

Consequence: the intelligent timing module is **RF-transparent** — the CRT recovers the same crafted composite and locks the same way. RF adds only three couplings the module must respect:
1. **Modulation-depth ↔ sync-level coupling** — sync tip → max carrier, peak white → min carrier (negative mod); composite levels and RF modulation index set together.
2. **IF-bandwidth edge rounding** — the tuner's VSB IF (~4.2 MHz) softens sync edges; may need slight pre-comp (widen sync / pre-shoot edges) so they arrive clean at the sync separator.
3. **Clamp-aware back porch** — RF detection is AC-coupled with DC restoration off the back porch; the wide-back-porch default matters *more* over RF.

---

## 11. Bench characterization protocol (fills in the per-model data)

The count-type window is precise (silicon, documented). The **analog-hold pull range per model is empirical and unpublished** — it only exists on the bench. Protocol per set:

1. Genlock the Schindler to a swept reference; step the field rate down from 60 Hz toward 44 Hz (and up toward 72 Hz).
2. At each rate, observe the **camera feed** (§7) for lock: roll-bar stopped, no tearing.
3. Log the lockable field-rate range and the rate where lock is most stable (centered, not edge).
4. Assign the set to a bucket (A/B/C) and record which preset + dialect achieves lock.
5. Sweep active-lines at the chosen rate to map the usable shutter-angle range for that set.
6. Save as a per-CRT JSON profile (NovaTool-pattern profile system).

A single afternoon per set builds the profile library that Tier 2 generalizes from.

---

## 12. Open decisions / to-dos

- [ ] **Tier choice for v1** — Tier 2 (model solver) ships; Tier 3 (closed-loop camera-feed adaptive) is the headline R&D bet. Decide commitment.
- [x] **Propagate the §10 RF carrier-coherence correction into [[rf-modulator-subsystem]]** — DONE 2026-06-07; clarification note added to the RF doc's "Si5351 dedicated to RF subsystem" section (the doc's architecture was already correct).
- [x] **Modulator chip choice** — DONE 2026-06-07; ADL5391 committed, AD835 head-to-head dropped. RF-modulator bench parts ordered (DigiKey SO 99663237); amp/filter/output substrate = Manhattan copper-clad. RF-modulator subsystem phase banked.
- [ ] **Validate the preset list** against real sets via §11.
- [ ] **Operator guidance** — mechanical-shutter → component output (§3.5); 25→24 conform is a flagged post step (§5).
- [ ] Confirm whether `vid_timing.v` parameter set already exposes per-dialect line counts (655/651) or needs extending in Phase G.

---

## Cross-references

- Reference device: `MVPHD-24-flyer-v2.pdf`, `MVPHD-24-OM-v0-9-0.pdf` (project root); feature gap analysis [[mvphd-comparison]].
- Architecture: [[signal-flow]] (composite terminal + present-geometry), [[dev-roadmap]] (Phase G).
- RF path: [[rf-modulator-subsystem]] (apply §10 correction).
- Profile system precedent: NovaTool per-tile JSON profiles.

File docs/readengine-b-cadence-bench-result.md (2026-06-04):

# Read-engine-B cadence — bench result (2026-06-03)

Build #21b: `pg_read_engine_top` with `pg_cadence` in **gen-lock mode** (`blend_mode=0`,
drop/repeat, single fetch) replacing `pg_genlock`. Branch `readengine-b-integration`,
WNS +0.235. Programmed, firmware alive. Verification surface = **bench monitor** (MS2109 masks
artifacts — see `schindler_ms2109_verification_trap`).

## What passed

- **Static grid (Osee input 1, ImagePro SMPTE):** clean, no regression vs prior builds. Same
  small constant pixel offset as every prior read-engine-B build (see "Open" below).
- **Motion (Osee input 2, ~60 Hz motion source) and laptop (input 3, 1920×1080@60):**
  **motion is clean** on the monitor — no judder, no roll, no tearing, no periodic hitch.
  Telemetry tracked throughout (`in=1920x1080 src=60 out=60`, frame_ptr Gray cycle advancing).

  This is the decisive test the static grid could not give us. It validates, on live motion:
  - the **gen-lock cadence** (per-output-vsync slot pick from the S2MM write pointer);
  - the **Gray decode** (`fp_use = gray2bin(fp_stable) % NUM_FRAMES`) — a wrong decode would
    have shown a constant temporal offset / hitch on motion, which it did **not**;
  - the **decode→slot mapping** (round-3 open risk #1) — `gray2bin(fp) % 5` is pointing at the
    freshest completed frame; motion plays temporally correct.

- **Color pipeline verified at identity** (UART `i`): sat=0x8000 (100%), black=(0,0,0),
  white=(255,255,255), matrix `[4000 0/0 4000 0/0 0 4000]` diag (1.0 Q2.14), offsets (0,0,0).
  The box is not altering color; any tint in webcam captures is camera white balance.

## Open: constant per-line horizontal WRAP (pre-dates cadence — "same as before")

**Observed symptom (bench, 2026-06-03):** source pixel 0 lands a few pixels IN from the left;
each line's last few pixels wrap to the START of the next line; the pattern is **identical on
every line and does NOT accumulate** (vertical grid lines stay straight, no shear). Constant δ
≈ a few pixels, source-independent (static/motion/laptop all show it).

**This is a horizontal phase offset in the AXIS→video stream, NOT a rigid raster shift.** A VTC
porch shift moves the whole active rectangle and blanks the edge — it cannot wrap end-of-line
content into the next line. The wrap is the giveaway: pixel 0 is landing at active column δ.

**Datapath resample/address math is clean** (output(0,0)→source(0,0)): `pg_addrgen` DDA resets to
`src=0,frac=0` at SOF (no init phase); `pg_linefetch` `rd_col=0 → o=0,beat_b=0,sub=0` = source
pixel 0; `pg_compose` `push_col` from 0, SOF on genuine first pixel. So the content is correct;
only its horizontal *anchor* in the output raster is off by δ.

**Lead hypothesis — `axis_to_vid_io` SOF-realign drains pre-SOF residue inside the active window:**
`s_axis_tready = vtg_active_video && enable` → the adapter consumes **only during active video**.
The SOF-realign re-arms each frame (`started<=0` at vsync) and discards non-SOF head beats until
the SOF beat appears (then SOF = pixel 0). But because tready is active-gated, those δ residual
beats (frame N's tail still queued in the output FIFO at blanking start) can only be drained by
**burning the first δ active-pixel slots** (shown black at top-left). So the **SOF beat lands at
active column δ**, every subsequent line is shifted +δ, and each line's last δ pixels wrap into
the next line's head — constant, non-accumulating. δ is counted in 64-bit beats (≈2.67 px each)
→ "a few pixels." Matches the symptom exactly.

**Proposed fix:** flush pre-SOF residue during **blanking**, not active video. While `!started`,
assert `tready` to drain non-SOF head beats during blanking; once the FIFO head IS the SOF beat,
hold (deassert) so SOF waits at the head and becomes the first pixel at active column 0. Then gate
to active-video as today. Makes pixel-0 placement deterministic at column 0 → kills the wrap.

**CONFIRMED (build #22, 2026-06-03):** `axis_to_vid_io.predrain_snap` routed to diag GPIO ch1,
firmware `DRAIN:` line. Measured every frame, perfectly constant:

    DRAIN: delta_px=6 (stale=6 starve=0)

δ = **6 px constant**, **100% stale, 0 starve**. So pixel 0 lands at output column 6 because six
residual beats from the prior frame's tail are discarded inside active video; the producer is
never late (starve=0 ⇒ not a `pg_compose` priming issue). This selects the **blanking-flush** fix
unambiguously. NOTE: `axis_to_vid_io` is **shared** by the scaler/VDMA path and the read-engine
path, so the fix affects both (expected — the wrap is common to all builds, "as before").

**Lower-likelihood alternates:** producer leaves a deterministic FIFO residue at frame end
(fixable producer-side instead); rgb2dvi DE-vs-sync skew (but that wouldn't wrap content).

## RESOLVED (build #23, 2026-06-03) — bounded blanking-flush

Root cause (agent-confirmed): the shared color stack (sat→correct→matrix) holds the prior frame's
last ~6 pixels in its pipeline at the frame boundary; they emerge ahead of the new frame's SOF
pixel 0. Fix in `hdl/axis_to_vid_io.v`: drain pre-SOF residue during **VBLANK** (black, not shown)
so the SOF beat is at the head when active begins → pixel 0 at column 0. **Bounded to
`MAX_DRAIN=16`** beats/frame so a missing/late SOF reverts to the old 1-frame-black-flash instead
of cascading (the failure the cap introduces, raised in review). `vtg_vblank`-scoped.

- **Sim** (`sim/axis_sof_tb.v`): PASS 230+6 checks, 0 errors — anchor/clean intact (no regression on
  the shared module), δ==0 on the residue frame (was δ=3 pre-fix), missing-SOF frame capped + clean
  re-anchor.
- **Silicon:** `DRAIN: delta_px=0` across static, 2× zoom (`G 960 540 480 270`), full
  (`G 1920 1080 0 0`), and passthrough (`G 0`). δ holds at 0 through geometry transitions and on the
  VDMA path. Monitor: position perfect, wrap gone, motion clean.
- Commit `78ce592` on `readengine-b-integration`. Reviewed + endorsed by external agent.
- ⚠️ 3-cold-boot verify still owed before the no-coin-flip ✅ CLEAN promotion.

## Color note (separate, closed)

A "too warm" report was chased to ground: MS2109 digital capture of the output measured whites =
`(255,255,255)`, all channels reach 255, global B/R = 1.00. Channel-isolation probe confirmed
correct R/G/B mapping (no R-B-G swap). The box's color is accurate — the warmth was **f.lux** on
the test machine. Not an FPGA issue.

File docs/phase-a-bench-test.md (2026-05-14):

# Phase A — Bench Test Instructions

**Goal:** validate HDMI passthrough on the Zybo Z7-20. Computer HDMI → Zybo HDMI-IN → FPGA fabric → Zybo HDMI-OUT → external monitor. No processing — just pixel-domain pass-through. First milestone of the HD pipeline development arc per [`dev-roadmap.md`](dev-roadmap.md) Phase A.

## What's built

- **Top-level HDL:** [`hdl/top_phase_a.v`](../hdl/top_phase_a.v) — pure-PL design (no Zynq PS), instantiates Digilent's `dvi2rgb_0` (TMDS RX) and `rgb2dvi_0` (TMDS TX) IP cores.
- **Constraints:** [`constraints/zybo_z7_20_phase_a.xdc`](../constraints/zybo_z7_20_phase_a.xdc) — Zybo Z7-20 pin assignments for both HDMI ports + LEDs + clock + reset.
- **Build script:** [`tcl/build_phase_a.tcl`](../tcl/build_phase_a.tcl) — Vivado Tcl batch build, independent of the Phase 2 project at `build/schindler-2.0/`.
- **Bitstream:** `build/phase-a-hdmi-passthrough/phase-a-hdmi-passthrough.runs/impl_1/top_phase_a.bit` (~4 MB).

## Build status (2026-05-13)

- Vivado 2025.2 + Digilent vivado-library `dvi2rgb` v2.0 + `rgb2dvi` v1.4
- Synthesis: ✅ clean
- Implementation: ✅ clean
- Timing: **WNS +0.23 ns, WHS +0.06 ns** — met. Hold is close; worth eyeing as Phase B layers on AXI VDMA traffic.
- **Bench result:** passthrough working end-to-end. Validated stable at 1920×1080@60p (laptop source → Zybo → external monitor). Note that 1080p60 (148.5 MHz pixel clock, 742.5 MHz BUFIO / MMCM VCO) runs above the conservative Artix-7 -1 grade datasheet maxes (BUFIO 600 MHz, MMCM VCO 1200 MHz) — the -1 Z-7020 silicon has margin in practice but production should still target within-spec rates on -1, or step up to -2 (production TE0720 module's speed grade is faster).

### Key gotchas resolved during bringup

- **rgb2dvi `kClkPrimitive` must be MMCM, not PLL, on Zybo Z7-20 for ≤120 MHz pixel clocks.** With kClkRange=2 (MULT_F=10) at 74.25 MHz pixel clock, VCO lands at 742.5 MHz. PLLE2 min VCO on Artix-7 -1 grade is 800 MHz — PLL refuses to lock, rgb2dvi has no 5× serial clock, monitor sees no TMDS. MMCME2 min VCO is 600 MHz so the same MULT_F works. Documented in `tcl/build_phase_a.tcl`.
- **`CLOCK_DEDICATED_ROUTE BACKBONE` on `sys_clk_IBUF`** is required once a third MMCM (rgb2dvi's) joins the design — placer can no longer keep `sys_clk`'s IBUF and the top-level MMCM in the same clock region. Documented in the XDC.

## To rebuild

```bash
cd ~/Dropbox/_PROJECTS/Schindler-2.0
source /tools/Xilinx/2025.2/Vivado/settings64.sh
export BOARD_PARTS_REPO_PATHS=$HOME/fpga/vivado-boards/new/board_files
export DIGILENT_IP_REPO_PATH=$HOME/fpga/vivado-library/ip
vivado -mode batch -nojournal -log build_phase_a.log -source tcl/build_phase_a.tcl
```

Build takes ~2–3 minutes on this laptop. The Tcl deletes the build dir first so each run is clean.

## Bench test procedure

### 1. Cable setup

- **Zybo Z7-20** → USB cable to Linux laptop (provides JTAG + UART + power; jumper JP5 on Zybo should be on USB pins).
- **Source laptop HDMI → Zybo "HDMI RX" port.** That's the port closest to the USB connector — labeled `Source` on the silkscreen.
- **Zybo "HDMI TX" port → external monitor HDMI.** The other HDMI port — labeled `Sink` on the silkscreen.

### 2. Load bitstream

Option A — Vivado Hardware Manager (GUI):

```bash
source /tools/Xilinx/2025.2/Vivado/settings64.sh
vivado
```

Then `Open Hardware Manager` → `Open Target` → `Auto Connect` → right-click the FPGA device → `Program Device` → browse to `build/phase-a-hdmi-passthrough/phase-a-hdmi-passthrough.runs/impl_1/top_phase_a.bit` → `Program`.

Option B — Command line:

```bash
cd ~/Dropbox/_PROJECTS/Schindler-2.0
source /tools/Xilinx/2025.2/Vivado/settings64.sh
vivado -mode batch -nojournal -source tcl/program.tcl  # reuses existing program script
```

(If `tcl/program.tcl` is wired to the Phase 2 build, may need to edit the bit path or copy that script to a Phase A variant.)

### 3. Validate the LEDs first (before HDMI)

After programming, even with no HDMI cables connected:

- **LD0 (M14)** = `mmcm_locked` — should be **ON solid** within a fraction of a second. If OFF, the 125 MHz onboard oscillator isn't being detected (check BTN0 isn't held).
- **LD1 (M15)** = `rx_locked` (HDMI source detected + pixel clock recovered) — should be **OFF** when no source connected.
- **LD2 (G14)** = active-video heartbeat — should be **OFF** when no source connected (no `vid_pVDE`).
- **LD3 (D18)** = `hdmi_tx_hpd` (monitor plugged into HDMI TX port) — should be **ON solid** when the monitor cable is connected.

### 4. Connect source laptop HDMI

Plug the source laptop's HDMI cable into the Zybo HDMI-IN port.

Expected within ~1–2 seconds:

- Laptop should detect a new display (the dvi2rgb IP emulates a 720p EDID). Laptop may mirror or extend its desktop to this "new monitor."
- **LD1 (rx_locked)** should turn **ON solid** — Zybo locked to the HDMI pixel clock.
- **LD2** should start **flickering** (slow blink at the rate of the 24-bit `vde_counter` MSB, which advances during active video).

### 5. Connect monitor HDMI

Plug the external monitor cable into the Zybo HDMI-OUT port.

Expected:

- **LD3 (hdmi_tx_hpd)** turns **ON solid** (monitor sensed via HPD).
- **The monitor should display the laptop's screen.** Same pixels as the source — no scaling, no processing.

### 6. What "success" looks like

- Source laptop sees a 720p-class display
- External monitor shows the laptop's screen
- All 4 LEDs ON solid (LD0, LD1, LD3) plus LD2 flickering during active video
- Pulling the source HDMI cable: LD1 goes OFF, LD2 stops flickering, monitor goes blank
- Reconnecting: full chain comes back up

## Troubleshooting

| Symptom | Likely cause | Fix |
|---|---|---|
| No LEDs on at all | Bitstream not programmed, or BTN0 held | Reset (release BTN0), re-program |
| LD0 only, no LD1 when source plugged | EDID negotiation failed, or laptop doesn't like our 720p EDID | Try a different source (PC vs phone vs Pi); try lower-res 720p HDMI output forcing |
| LD1 ON, LD2 not flickering | Source claims a mode but isn't outputting active video | Check source side — display arrangement, refresh rate |
| LD1 + LD2 active but monitor blank | TMDS_OUT not driving cleanly | Try a different monitor (some are picky about non-CEA-861 timing); check HDMI cable; oscilloscope on TMDS_OUT pairs |
| Random LED flickering | Reset or clock noise | Check that BTN0 isn't being bumped |

## Forward-looking notes

- **Phase A is the simplest path to a working HDMI pipe.** No frame buffer, no buffering, no clock-domain crossing. Phase B replaces this simple pixel-domain wire with an AXI4-Stream Video pipeline through Xilinx AXI VDMA + Z-7020 DDR3 — that's where real processing becomes possible.
- **HDL ports to TE0720 1:1** when the production migration activates. The Zybo's onboard HDMI infrastructure becomes the LT8619C + ADV7511 chip pair on the production carrier, but the FPGA-side HDL is the same parallel RGB interface.
- **The Phase 2 R-2R DAC composite encoder HDL** (`vid_timing.v` + `vbi_gen.v` + `chroma_gen.v` + `sample_gen.v`) is untouched. Sits in `hdl/` alongside `top_phase_a.v`. Will be reattached as the NTSC composite encoder terminal off the HD signal bus in Phase G.

## Files

- [`hdl/top_phase_a.v`](../hdl/top_phase_a.v) — top-level
- [`constraints/zybo_z7_20_phase_a.xdc`](../constraints/zybo_z7_20_phase_a.xdc) — pins
- [`tcl/build_phase_a.tcl`](../tcl/build_phase_a.tcl) — build script
- `build/phase-a-hdmi-passthrough/` — generated build artifacts (excluded from git via existing `.gitignore`)
- `build_phase_a.log` — most-recent build log

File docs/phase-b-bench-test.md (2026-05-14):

# Phase B — DDR3 Frame Buffer Passthrough

**Goal:** replace Phase A's direct dvi2rgb→rgb2dvi pixel wire with an AXI4-Stream Video pipeline going through DDR3 via AXI VDMA. Foundation for the polyphase scaler (Phase C) and FRC (Phase D), both of which need full-frame storage.

Phase B has two sub-steps:

- **B.0 — Hardware platform.** Block Design with Zynq PS + AXI VDMA + Video In/Out adapters + VTC. Builds to .bit + .xsa. **Done.**
- **B.1 — PS firmware.** Bare-metal C app that initializes VDMA at boot + sets up VTC timing. Loaded via XSCT alongside the .bit. **Done — VDMA + VTC fully configured, but `v_axi4s_vid_out` not locking; no picture on monitor yet.**

## Architecture

Block Design `phase_b_bd` ([`tcl/build_phase_b.tcl`](../tcl/build_phase_b.tcl)):

```
sys_clk (125 MHz) ──► Clocking Wizard (PLL) ──► refclk_200 ──► dvi2rgb IDELAYCTRL

HDMI RX TMDS ──► dvi2rgb ──► RGB (vid_io) ──► Video In to AXI4-Stream
                                                  │ AXIS (24-bit RGB)
                                                  ▼
                              AXI VDMA (S2MM ch) ──► DDR3 frame store (3-frame ring)
                                                  ▲
                                                  │ AXIS (24-bit RGB)
                              AXI VDMA (MM2S ch) ──┘
                                                  │
                                                  ▼
                                          AXI4-Stream to Video Out
                                                  ▲ vtiming_in
                                                  │
                                              v_tc (TX timing generator, 1080p60)
                                                  │
                                                  ▼
                                              rgb2dvi ──► HDMI TX TMDS
```

Everything runs on a single clock domain — the dvi2rgb-recovered **PixelClk** (74.25 MHz at 720p60, 148.5 MHz at 1080p60). The PS app waits for source-side lock before VDMA + VTC init so PixelClk is stable when their reset state machines run.

PS interconnect:
- **M_AXI_GP0** (100 MHz axi-lite) → AXI Interconnect → VDMA registers + VTC registers
- **S_AXI_HP0** (150 MHz axi-mm, 64-bit) ← SmartConnect ← VDMA S2MM + MM2S memory ports → DDR3

## Build / load flow

```bash
cd ~/Dropbox/_PROJECTS/Schindler-2.0
source /tools/Xilinx/2025.2/Vivado/settings64.sh
export BOARD_PARTS_REPO_PATHS=$HOME/fpga/vivado-boards/new/board_files
export DIGILENT_IP_REPO_PATH=$HOME/fpga/vivado-library/ip
vivado -mode batch -source tcl/build_phase_b.tcl      # → .bit + phase_b.xsa

source /tools/Xilinx/2025.2/Vitis/settings64.sh
xsct tcl/build_phase_b_app.tcl                        # → vdma_init.elf
xsct tcl/program_phase_b_full.tcl                     # JTAG: fpga + ps7_init + dow elf + con
```

UART terminal: `/dev/ttyUSB1` at 115200 8N1 (PS's UART1 via Zybo USB-UART, second channel after JTAG).

## Status (2026-05-13, end of long session)

**Working:**
- Phase A (pure-PL passthrough) is rock-solid at 1080p60 with `kClkRange=1` on dvi2rgb + rgb2dvi. (Earlier "kClkRange=2 also works at 1080p60" was marginal luck — the MMCM VCO is over-spec at 1485 MHz; with the more-loaded Phase B design it consistently fails to maintain lock.)
- Phase B.0 platform builds clean. WNS / WHS positive.
- Phase B.1 PS firmware fully configures VDMA + VTC. Both channels run, registers verified, S2MM writes real pixel frames to DDR3, frame pointers cycle.
- Custom `axis_to_vid_io.v` adapter replaces v_axi4s_vid_out (which wouldn't lock); proved that adapter works by getting the monitor to recognize 1920×1080 timing.
- **Phase A architecture inside Phase B's BD shows real desktop video on the monitor** — briefly. The pipeline goes end-to-end. The remaining problem is reliability.

**Not stable:**
- dvi2rgb's `pLocked` (LD1) flickers off intermittently. Pattern: ~3 seconds locked, 5–10 seconds dropped. Monitor follows: brief lock when LD1 holds, "No Signal" when LD1 drops.
- The pLocked instability is independent of:
  - clk_wiz primitive (PLL vs MMCM — both intermittent)
  - PS FCLK_CLK2 as IDELAYCTRL refclk (also intermittent)
  - PixelClk fanout (1 sink vs 5 sinks)
  - PS firmware activity (with vs without firmware)
  - Custom adapter (Phase A-direct-wiring still flickers in Phase B's BD)
- Phase A's bitstream (same dvi2rgb/rgb2dvi, no PS, no VDMA, no VTC, no extra IPs) does NOT exhibit the flicker. So the cause is something specific to Phase B's overall BD complexity — likely **dvi2rgb's internal MMCM placement / routing pressure**, which we can't diagnose without ILA visibility.

## Gotchas resolved during bringup

Useful to know if/when we revisit this:

1. **Digilent interface defs live separately from the IP cores.** Need to register `~/fpga/vivado-library` (parent of both `ip/` and `if/`) as `ip_repo_paths`, not just `ip/`. Without `if/`, `digilentinc.com:interface:tmds_rtl:1.0` doesn't resolve and BD interface ports fail.
2. **Clocking Wizard `PRIMITIVE = PLL`, not MMCM.** With dvi2rgb + rgb2dvi each needing an MMCM near their HDMI IO bank, a third MMCM here over-subscribes the clock region and the placer fails rgb2dvi's `MMCM↔BUFR/BUFIO` same-region rule.
3. **`CLOCK_DEDICATED_ROUTE BACKBONE`** on `sys_clk_IBUF` still required (carried from Phase A).
4. **`Xil_DCacheDisable()`** before VDMA init so the PS sees coherent DDR3 from the VDMA writes without explicit flush/invalidate.
5. **JTAG load order matters:** `connect → rst -system → fpga → source ps7_init.tcl → ps7_init → ps7_post_config → dow .elf → con`. `ps7_post_config` *must* come after `fpga` — it releases the PS-PL bridges and they need the PL to be present.
6. **PS app must sleep before touching VDMA + VTC** to let dvi2rgb finish locking. VDMA's reset state machine waits for all clock domains to ack; VTC's AXI-Lite slave needs its gen-clock alive to respond to register writes — both run on the recovered PixelClk, which doesn't exist until dvi2rgb locks to the source. Without the sleep, VDMA init times out (`XAxiVdma_CfgInitialize` returns `XST_FAILURE`) or VTC writes trigger Data Abort.
7. **`XVtc_SetGenerator` is broken in this BSP.** `OriginMode=0` applies an off-by-one transform that writes `HTotal+1` to GASIZE (e.g., 2201 instead of 1920). `OriginMode=1` reads GFENC + writes GVSYNC_F1, one of which triggers Data Abort on our setup. Workaround: skip the driver entirely and write VTC's registers directly via `Xil_Out32` (`sw/phase-b/src/main.c`).
8. **`xvidc.h` is not in the standalone BSP for Vivado/Vitis 2025.2.** Don't use `XVtc_ConvVideoMode2Signal` / `XVIDC_VM_*` constants — hardcode the timing struct.
9. **AXIS data width = 24 bits** out of `v_vid_in_axi4s` (RGB888, 1 pixel per clock, no padding). Memory stride must therefore use **3 bytes per pixel**, not 4. Using 4 silently corrupts the per-line byte count and triggers VDMA framing errors.

## Final state (2026-05-14): Phase B fully working through DDR3, genlocked to source

After resolving the source-side flicker (next section), a small pile of FPGA-side bugs that the diagnostic short-circuit had been hiding, **and** a genlock fix on top, the **proper VDMA pipeline now passes live 1080p60 video through DDR3 end-to-end with the output frame phase-locked to the input**: Mac → dvi2rgb → v_vid_in_axi4s → VDMA S2MM → DDR3 frame ring → VDMA MM2S → axis_to_vid_io adapter → rgb2dvi → monitor. Mac desktop visible on the monitor, picture updates frame-by-frame, all four status LEDs lit, VDMA error bits clean, **no vertical seam regardless of when the board is reset relative to the source's frame phase** (confirmed via three consecutive reset cycles).
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

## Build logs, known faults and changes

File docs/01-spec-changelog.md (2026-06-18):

# Schindler 2.0 — Spec Changelog

**Purpose:** Dated record of design decisions, architectural pivots, procurement events, and bench milestones for the Schindler 2.0 spec. Entries are kept in the order they were originally recorded so the decision narrative reads naturally — they are not strictly chronological where consecutive sub-updates within the same session were captured slightly out of order.

**Current state lives in [`01-spec.md`](01-spec.md).** This file is read for "when did we decide X" and "why did we change direction on Y" questions.

---

- 2026-05-10 — Initial draft from feature scoping session. V1 confirmed for SDI ref input, composite + component input, all CRT-specific controls, EDID, test pattern set, behavior controls including burn-in repair mode. 60→50 PAL cadence confirmed V1 via crossfade; dev phase uses matched-rate-only fallback until built.
- 2026-05-10 PM — Hardware architecture session. **Confirmed:** TE0720 SOM (Z-7020 industrial) on custom carrier as production target; HD/1080p60 ceiling for v1 with DP via converter chip; HDMI OUT for loop-through monitoring; S-Video OUT (free from ADV7393); SDI as paired IN/OUT broadcast tier with native loop-through (GS3470 + GS2962); WiFi via Laird Sterling LWB5+ with concurrent AP+STA on dual RP-SMA antennas; BLE for setup pairing; UI Pattern B (single TFT + 2 rotary encoders + 4 buttons + status LED column) with hard requirement for physical knob guards; dedicated UI MCU on carrier (STM32H735); STM32H735G-DK as bench dev kit. **Proposed (pending decision):** drop Pi CM4 → Zynq PS hosts web UI; LTC PGA+ADC+AGC front-end with XLR + auto-sensing BNC inputs; ADV7393 as production DAC; GS3470 upgrade from GS2971-class for SDI ref; SKU strategy for broadcast tier (hardware SKU vs firmware unlock); S-Video input addition.
- 2026-05-10 PM (cont.) — **Encoder selection confirmed:** ALPS EC11E18244AU (replaces prior premium "Grayhill 62 / Bourns optical" placeholder recommendation). Value-tier mid-range encoder at ~$2-3.50 vs $20-40 premium tier; sufficient quality for the use case. Firmware note recorded: 18 PPR / 36 detents is half-step quadrature pattern — decoder must count edges rather than full cycles; software acceleration on long scrolls advised given fine 10° click pitch.
- 2026-05-10 PM (cont., 2nd update) — **ADC selection confirmed for genlock autosense front-end:** Analog Devices AD9204-20 (dual-channel 10-bit 20 MSPS, 1.8 V). Replaces prior AD9201/AD9215 reference — AD9201 confirmed legacy by ADI (Tony M response on EngineerZone). Dual-channel topology lets one chip handle both BNC autosense inputs; pin-compatible upgrade path to AD9231 (12-bit) / AD9251 (14-bit) / AD9258 (14-bit higher MSPS) / AD9268 (16-bit) provides future resolution headroom without board respin. **First DigiKey procurement order placed 2026-05-10:** TE0720-04-31C33MA (commercial-grade variant for bench), TE0703-07 dev carrier, EVAL-ADV7393EBZ, springloaded heatsink (33337). $628.74 incl. shipping. Second order pending.
- 2026-05-10 PM (cont., 3rd update) — **TE0720 silicon variant resolved.** Bench/prototype = TE0720-04-31C33MA (commercial -1 speed grade); production target = TE0720-04-62I33MA (industrial -2 speed grade). Both share 1 GB DDR3L + 32 MB QSPI + 8 GB eMMC memory config and identical pinout — dev work ports directly to production silicon. Evaluated stripped-down TE0720-04-61C530A variant (256 MB DDR3, no eMMC, ~$190) and ruled out — insufficient DDR for video frame buffers + PetaLinux + Node.js + working memory headroom; no eMMC for Linux rootfs (would force SD-card boot or external eMMC on carrier, neither acceptable). Memory cost is real and the cheap variant doesn't have enough.
- 2026-05-10 PM (cont., 4th update) — **First analog picture validated.** R2R DAC + op-amp output stage producing structurally correct NTSC composite signal: ~63 µs line rate, ~5 µs sync width, ~3 µs back porch, ~53 µs active video. Multi-step grayscale staircase test pattern rendering cleanly with crisp transitions and no visible ringing — DAC + op-amp settling adequate for NTSC pixel rates. **Amplitude calibration pending:** signal currently ~3 V p-p (peak white +2 V above blank, sync tip -1 V below blank); SMPTE target is 1 V p-p at 75 Ω (peak white +714 mV, sync tip -286 mV). Sync/video ratio currently ~1:2 (sync depth : peak-above-blank); SMPTE target ~1:2.5. Amplitude scale = analog gain adjustment (bench-side); sync depth ratio = FPGA DAC code value adjustment (Claude-owned iteration). **Workflow clarified:** Claude authors and iterates FPGA HDL; Justin operates bench, captures scope/CRT results, feeds back observations.
- 2026-05-10 PM (cont., 5th update) — **NTSC vertical blanking interval structure verified.** Scope capture confirmed complete, structurally correct VBI sequence on FPGA test pattern output: 6 pre-VSync equalizing pulses (narrow, ~31 µs spacing at 2× H rate) → 3-line broad vertical sync period with 6 serration teeth → 6 post-VSync equalizing pulses → ~12 blank horizontal lines → active video resumes. Matches NTSC spec exactly — signal should successfully lock vertical on standard CRTs. FPGA timing generator HDL validated end-to-end for monochrome NTSC composite output (horizontal + vertical structure both correct). CRT lock test pending (next bench step). Next FPGA milestone: chroma subcarrier (3.58 MHz color burst encoding + chroma modulation onto luma) for color test patterns.
- 2026-05-10 PM (cont., 6th update) — **Frame rate and DAC linearity validated against HDL parameters.** VSync-to-VSync measured at 41.6 ms = 24.04 Hz; cross-referenced against `hdl/vid_timing.v` which specifies `PIXELS_PER_LINE = 3435` (63.613 µs at 54 MHz pixel clock) × `LINES_PER_FRAME = 655` = 41.667 ms = exactly 24.000 fps. Scope matches HDL within measurement tolerance. Earlier diagnostic of "line count off by 6" from a noisy 41.3 ms reading was bad math; code is correct as written. VBI 6+6+6+12 pulse count also cross-referenced: `vbi_gen.v` specifies 3 pre-eq + 3 vsync + 3 post-eq + 12 blank fill lines, each eq/vsync line carrying 2 pulses at half-line spacing — produces exactly the 6/6/6/12 pulses Justin counted on the scope. **Gray test pattern:** flat gray at 2.2 V renders cleanly across full active line; correct front porch / sync / back porch transitions. **Ramp test pattern:** smooth linear ramp from ~1.1 V (at blanking level — verified at tight 5 µs/div zoom) up to peak end-of-line level, with no quantization steps, kinks, or glitches across the full ramp. Confirms R2R DAC ladder is monotonic and linear across the code range, and pixel timing is rock-solid (constant ramp slope = steady pixel clock). Line period ~63.5 µs, active video duration ~52 µs, sync structure all rendering within visual tolerance of NTSC spec at tight zoom. **HDL files in vault confirmed:** `hdl/vid_timing.v`, `hdl/vbi_gen.v`, `hdl/sample_gen.v`, `hdl/top.v`. Workflow going forward: read HDL design parameters first, predict scope behavior, then verify — not the reverse.
- **Pending bench work (non-blocking for FPGA dev):** (a) CRT lock test once CRTs are available, (b) amplitude calibration via bench-side analog gain reduction to land on SMPTE 1 V p-p, (c) tight scope re-capture of ramp minimum endpoint vs back porch level to confirm intentional alignment at blanking. **Next FPGA development milestone:** chroma subcarrier (3.58 MHz NTSC color burst on back porch + I/Q quadrature modulation of chroma onto luma), to be added as a new module integrated with `sample_gen.v` and gated by VBI/active signals from `vid_timing.v`.
- 2026-05-10 PM (cont., 8th update) — **HDCP strategy banked.** V1 Pro Full and Broadcast Digital will ship with **HDCP 1.4 support** on HDMI input. **Bench dev path:** derived/public HDCP 1.4 device keys used for internal bench bring-up only (master key publicly known since 2010 leak, mathematically valid for the authentication protocol but not DCP-issued). Murideo SIX-G (~$2,500) selected as HDCP-capable bench source for authentication testing. **Production path:** DCP Adopter Agreement (~$5K/year for HDCP 1.x) + Xilinx HDCP 1.4 IP license signed before first production run; DCP-issued production keys provisioned per-unit at factory programming step. HDCP 2.2/2.3 deferred until 4K product (consumer 4K content requires HDCP 2.2+). **Mac source workaround during bench dev:** HDFury Diva-class EDID-copying HDMI splitter (~$300) inserted between Mac and Schindler input lets Mac see a real HDCP-compliant TV downstream while Schindler taps the signal — enables Mac bench testing without HDCP infrastructure on Schindler side. **Architecture note:** HDCP handled inside FPGA via Xilinx IP (saves $5–15K licensing? Xilinx HDCP 1.4 IP comes with Vivado Enterprise or as standalone license; DCP Adopter Agreement is separate and required for shipping). Alternative path of moving HDCP to a dedicated chip (TMDS181 has HDCP 2.2 built in, NXP TDA19988 has HDCP 1.4) considered but not chosen — keeping HDCP in FPGA matches the color pipeline architecture and avoids adding silicon. **DCP-issued facsimile/test keys** to be used after DCP license arrives, replacing derived keys, for compliance pre-testing prior to production cert.
- 2026-05-10 PM (cont., 7th update) — **Output DAC, genlock front-end, and sync-conversion architecture decisions banked.** **ADV7393 confirmed with runtime mode selection:** one chip serves composite/S-Video OR component output (mutually exclusive, I²C-switched); never need both modes simultaneously, so a single ADV7393 covers all V1 analog video outputs. **Architecture A confirmed for genlock front-end:** AD9204-20 (dual ADC) + LTC6912 or AD8369 (PGA, selection deferred) + RP2040 (slow-control / autosense decision / Si5351 config) + Si5351 (programmable clock generator) + FPGA (high-rate signal classification of 20 MSPS ADC stream); XLR balanced LTC + 2× BNC autosensing connector mix confirmed. **ADV7280-A dev board to be ordered** for input-side analog video decoder evaluation. **NEW [PROPOSED] V1.5 expansion:** sync conversion with timecode translation — accept genlock+LTC at one rate, output a different rate's genlock+LTC with phase-locked TC math. Would position Schindler as a broadcast-grade rate-domain bridge with CRT driving as one capability (Evertz 5600 / AJA OG class with a CRT driver attached). V1 to preserve architectural option (clock-domain discipline, Si5351 output port reservation, rear-panel provisioning); build as V1.5 / sibling product after V1 ships. New spec section added covering hardware additions, FPGA additions, effort estimate, and architectural design hooks.
- 2026-05-10 PM (cont., 9th update) — **HDMI subsystem architecture finalized; supersedes 8th update.** Iterated through Xilinx-internal HDCP (path priced out at $5-15K license + $5K/yr DCP), then chip-based symmetric HDCP (ADV7611/ADV7513 ruled out as NRND/EOL; updated to LT8619C + IT66121FN), then questioned whether HDCP transmitter chip was needed at all given Schindler's position as a broadcast studio analysis device. **Final architecture:** Lontium **LT8619C** (HDMI 1.4 RX, parallel RGB/TTL out to FPGA, HDCP 1.4 keys embedded by Lontium under their DCP Adopter Agreement) on input + **direct FPGA HDMI 1.4 TX** via free Xilinx HDMI IP (no HDCP encryption on output) + **TPD12S016** ESD protection on both connectors. **Total HDMI subsystem cost: ~$8/unit at qty 100.** **Legal positioning:** Schindler is a broadcast studio device in the lineage of waveform monitors, vectorscopes, confidence preview tools, and signal-analysis equipment (Tektronix WFM, Leader, AJA HDR Image Analyzer category). HDMI output is intended for monitoring/analysis use: waveform/vectorscope visualization, signal lock and status dashboard, test pattern output, color analysis (histograms, gamut warnings, false color), heavily-degraded confidence preview. Architecture follows the letter and spirit of DMCA §1201 (primary-purpose test: signal analysis and color correction, not circumvention) and DCP Compliance Rules (HDMI output does not transmit Decrypted HDCP Content as a faithful copy; analysis/monitoring outputs are industry-standard for HDCP-capable equipment). End-user assumes responsibility for downstream content compliance, mirroring how every professional waveform monitor, scope tool, and broadcast analysis device on the market operates. **Product documentation will state:** "HDMI output is intended for monitoring and signal analysis. Users are responsible for compliance with content licensing and applicable laws regarding downstream signal use." **Cost savings vs symmetric-HDCP path:** no Xilinx HDCP IP license (~$5-15K saved one-time), no IT66121FN transmitter chip ($3/unit saved), DCP Adopter Agreement deferred (likely not strictly required at this scale and use case, but can be added later if Mini consumer SKU eventually ships). **Bench dev path:** LT8619C works out of the box with its embedded HDCP keys — no derived-keys workflow needed for the chip-based input path. For broader HDMI source testing including Macs, HDFury Diva-class EDID copier ($~300) available as bench-only workaround. **Mini variant (deferred):** when/if it ships, Mini targets consumer HDMI market and would require full HDCP 2.2 chain, DCP Adopter Agreement, and likely Xilinx HDCP 2.x IP or equivalent — separate decision at that time.
- 2026-05-11 — **LT8619C eval board + raw chip ordered.** Lontium LT8619C-EVB dev board and a single raw LT8619C chip on order for HDMI input bench bring-up. **HDMI loop-thru feature explicitly deferred** — no LT86102SXE splitter, no second HDMI output, no buffer chip with tap. V1 ships with single HDMI IN (LT8619C) and single HDMI OUT (direct FPGA TX) only. Loop-thru can be revisited as a V1.x or V2 feature if customer feedback requests it.
- 2026-05-11 — **Connector list and panel layout reorganized.** Final V1 rear panel connector list (single-row tall items plus two-row stackable items, 1RU full-rack 19" target): IEC C14 power (35 mm), 2× XLR LTC IN/OUT (52 mm) on single-row track; USB-C service (8 mm), RJ45 GbE (22 mm), 2× SMA WiFi (24 mm), 2× HDMI IN/OUT (44 mm), 2× BNC SDI IN/OUT (36 mm), 4× BNC composite/component IN (72 mm), 4× BNC composite/component OUT (72 mm), 3× BNC autosense IN/LOOP/OUT (54 mm) on two-row stacked layout. Single-row subtotal 87 mm; two-row halved subtotal 166 mm; grand total 253 mm of 432 mm available, leaving 179 mm of unused panel width for future expansion. **V1.5 sync conversion expansion now absorbed into V1** via the LTC OUT XLR and BNC autosense OUT slots — Schindler becomes a broadcast-grade rate-domain bridge with CRT driving as one capability rather than a CRT-only driver. **SDI simplified to 2× BNC** (IN + processed OUT only, dropped passive loop-through from broadcast tier). **Dropped from V1:** DisplayPort IN, mini-DIN S-Video OUT. **TFT and form factor decision:** 1RU full-rack confirmed with two-row connector layout; front panel TFT constrained to ~2.4" 16:9 by 1RU panel height; status-display UI pattern with web UI for detailed config (Evertz 5600 / AJA OG style). Future Mini variant likely compact desktop with 4.3" TFT. **HDMI subsystem chip selection finalized** per 9th update above: LT8619C RX + direct FPGA TX + TPD12S016 ESD protection × 2.
- 2026-05-11 (10th update) — **Physical design decisions banked: cooling, chassis style, half-rack feasibility analysis. PSU decision pending Justin's call.**
  - **Power budget estimate for V1 Pro Full:** Zynq-7020 TE0720 SOM 4–6 W typical / 7 W peak + ADV7393 + ADV7280 ~1 W + LT8619C + 2× TPD12S016 ~0.5 W + AD9204 + LTC6912 + Si5351 + RP2040 ~1.5 W + SDI chips (GS12281 class) ~2 W + misc analog (op-amps, ADCs, LDOs) ~2 W + front panel TFT + USB + Ethernet PHY ~1 W + PSU conversion losses (15%) ~2.5 W. **Total typical: ~14–16 W. Total peak: ~20–22 W.**
  - **Cooling decision: small low-noise PWM fan, designed to be conditional/silent.** Reference fan: Noctua NF-A4x20 PWM (~14 dB at low RPM, ~$15) or equivalent. Chassis designed for fanless operation at typical 14–16 W load via extruded aluminum top cover acting as primary heatsink (Zynq SOM thermally coupled via gap pad). Fan only spins up when SOM heatsink temp crosses programmable threshold under peak load. Broadcast facility rack environments are HVAC-noisy so fan inaudible at rack distance even at full RPM. Pattern proven in modern 1RU broadcast gear (Tektronix, Cobalt, AJA).
  - **PSU decision: PENDING.** Justin's expressed preference: external brick. Claude's recommendation: internal PSU for Pro/Broadcast Digital tier, with rationale: (a) pro market expectation at $2,500+ price point — Tektronix, AJA, Ross, Evertz, Cobalt, Imagine, Lawo all ship internal PSU in 1RU products; external brick reads as prosumer category and caps retail pricing; (b) IEC C14 is a secure locking inlet vs. vulnerable DC barrel; (c) rack-mount cable management cleaner with single AC cord. Compromise option proposed: **internal PSU with redundant DC input** (IEC C14 primary + locking 12V or 24V DC jack as field/redundant power, ~$5 added BOM, OR-ing diodes for source selection). Cisco and Ross both do this pattern. **Trade-offs documented for Justin's final call.**
  - **Chassis style decision: dedicated 1RU full-rack 19" chassis for V1 Pro and Broadcast Digital.** Switch-style box + add-on rack-mount kit pattern (common in network gear: Cisco SG350, Ubiquiti EdgeSwitch, Netgear ProSafe; also some AV: BMD Mini Converters, AJA Hi5) considered and rejected for V1 broadcast tier — rack ears read unprofessional in high-end pro install, chassis depth/width compromises don't serve the I/O density we've committed to, and dedicated 1RU is the universal expectation in fixed-install broadcast (Tektronix, Evertz, Ross openGear, AJA OG-X, Sony BVM, Cobalt). **Switch-style box + kit pattern reserved for future Schindler Mini SKU** where desktop deployment matters and pair-mount in 1RU via joiner kit is a deliberate feature (BMD/AJA pattern).
  - **D-Sub breakout cable feasibility analysis for analog I/O:** Replacing 4× BNC composite IN (72 mm) + 4× BNC composite OUT (72 mm) with one DB-25 (70 mm) or DB-44 HD (70 mm) saves only ~29 mm of panel width given current two-row stacked BNC layout — savings would be larger in a single-row layout but the two-row arrangement already compresses heavily. Combining D-Sub for composite I/O + autosense BNCs into one DB-37 or DB-44 HD saves ~62 mm. **D-Sub approach NOT adopted for V1** — saves modest panel space at the cost of breakout cable management hassle (lost cables, mis-pinning, crosstalk between analog lines requires careful ground-pin placement), and pro broadcast preference is individual labeled BNCs over breakout cables. **D-Sub approach RESERVED for future Schindler Mini-Rack SKU** (half-rack sibling product for mobile production trucks and packed live event racks where panel width is the binding constraint).
  - **Half-rack form factor feasibility analysis:** Half-rack panel width budget is ~215 mm vs. current full-rack layout consuming 253 mm. **I/O panel width is the only binding constraint** — internal chassis volume and thermal envelope are NOT limits at V1's 14–22 W power level. To compress 38 mm into half-rack: (a) external PSU eliminates IEC C14 saving ~27–30 mm but goes against PSU recommendation, (b) D-Sub for composite I/O alone saves ~29 mm (tight), (c) D-Sub for composite + autosense saves ~50–55 mm (comfortable), (d) internal WiFi antennas eliminate 2× SMA saving 24 mm, (e) TRS or sub-mini XLR replacing full XLR LTC saves ~32 mm but loses pro audio expectation. **Half-rack achievable but requires compromises that degrade pro broadcast positioning.** V1 stays full-rack. Design hooks preserved for future Mini-Rack SKU using D-Sub breakout + external PSU + internal antennas combination.
  - **Future product line design hooks banked** (not V1 features): **Schindler Mini-Rack** = half-rack chassis, DB-44 HD analog breakout, external PSU, internal WiFi antennas, targets mobile production trucks and packed live event racks; **Schindler Mini** = switch-style box with optional rack-mount kit accessory, external brick PSU, half-rack-by-pairs in 1RU, targets desktop confidence monitor / prosumer / consumer HDMI calibration market (requires HDCP 2.2 chain and DCP Adopter Agreement — separate decision when that SKU activates).
- 2026-05-11 — **Spec restructure + architectural confirmations.** Revision history split out of `01-spec.md` into this changelog file so the spec doc holds current state only. **Confirmed:** Pi CM4 dropped → Zynq PS hosts control plane under PetaLinux; RP2040 confirmed for genlock slow-control; LTC6912 confirmed as PGA (MIKROE-2555 inbound for bench eval); SDI broadcast tier delivered as **factory-populated hardware option** (not firmware-unlock) with daughter-card-on-headers as field-upgrade vector; XLR LTC IN/OUT **dropped from V1** (panel simplification — LTC routes through autosense BNC input or OUT format selection; may return in a later rev); sync zone restructured to 4 BNCs total (REF IN + REF LOOP on input side, SYNC OUT 1 + SYNC OUT 2 on output side); each SYNC OUT runtime-selectable across black burst / tri-level / LTC; hardware driver chain spec'd to also support **DARS + Word Clock** via firmware-only upgrade later (driver bandwidth DC to ~10 MHz, swing ≥2 Vpp into 75 Ω). Per-OUT generation via independent FPGA phase accumulators off the master clock — Si5351 ch1/ch2 stay reserved (future GPSDO 10 MHz distribution candidate). New `docs/signal-flow.md` with Mermaid block diagrams (video signal path, sync subsystem, control plane). New `docs/panel-layout.md` with rear-panel ASCII sketch.
- 2026-05-11 — **Rear-panel status LCD + per-connector status LEDs confirmed.** 2.4" 16:9 SPI LCD (ILI9341 / ST7789 class) on rear panel, Zynq PS owned, ~1 s refresh, read-only status grid (one row per I/O connector with name + status icon + detail; header bar shows IP/hostname/firmware/current reference). Tricolor R/A/G LED at every rear-panel connector, driven by 3× TLC59116F constant-current I²C drivers (48 channels total), Zynq PS owned. Convention: input red = expected/missing, amber = present/not-in-use, green = present-and-in-use; output green = configured + outputting, amber = configured but no source; sync IN red = invalid, amber = locked-but-not-selected, green = locked + selected. Default brightness ~10 % so the panel isn't a Christmas tree in a dark machine room. Front-panel LED column mirrors rear state for at-rack-or-front visibility parity. Zynq PS holds the I/O state aggregator (SSOT) and pushes mirror updates to UI MCU.
- 2026-05-11 — **Power & safety architecture confirmed.** Pre-certified PSU module path (custom AC-DC design intentionally avoided — ~$15–25K + 3–6 months NRTL certification saved at Schindler's ~75 unit lifetime volume). IEC inlet: Schaffner **FN9260B-6-06** (C14 + 6 A + integrated fuse holder + 1-stage EMI filter, panel-mount, ~$18). Mains fuse: **2 A T (time-lag), 5×20 mm** in FN9260B holder — sized for 120 VAC worst-case (steady state ~0.21 A RMS gives 7–10× headroom, comfortably absorbs ~25 A / 5 ms cold-start inrush). No rocker switch (IEC cord = service disconnect, front soft button for daily use). PSU module: **TDK-Lambda HWS50A-12/A** primary (50 W / 12 V / UL 62368-1 listed / DigiKey-stocked, ~$50); **Mean Well LRS-50-12** drop-in alternate (~$15–20, higher availability). Mains wiring inside chassis: UL 1015, 18–20 AWG, three-conductor. Single-point earth via chassis ground stud (IEC + PSU + chassis bonded; carrier digital ground tied at one point to prevent ground loops). **Carrier 12 V input protection chain:** Diodes Inc **DMP3098L-7** P-FET reverse-polarity (−30 V, R<sub>DS(on)</sub> 31 mΩ, gate to GND via 100 kΩ) → Bourns **MF-MSMF200-2** polyfuse (I<sub>hold</sub> 2 A / I<sub>trip</sub> 4 A) → Littelfuse **SMBJ12A** TVS (unidirectional, V<sub>C</sub> 19.9 V peak, 600 W) → TI **INA226** + 5 mΩ shunt (I²C power monitor; telemeters 12 V rail voltage + actual current draw to Zynq PS for rear LCD / web UI; doubles as PSU-healthy check since HWS50A has no DC-OK signal pin) → 3× Murata **GRM32 22 µF 25 V X7R** MLCC bulk (~66 µF, chosen over electrolytics for 10+ year service life). Locking **Molex Mini-Fit Jr.** 2-pin connector from PSU to carrier. Total carrier protection BOM ~$6.20. Per-rail bucks/LDOs (5 V, 3.3 V, 1.8 V, 1.35 V, 1.0 V, VAUX) selected at carrier-schematic time — each has built-in OCP + thermal shutdown so no extra protection layer needed.
- 2026-05-11 (PM) — **DigiKey procurement order placed (Web ID 371561295, $353.39).** Executing on prior banked decisions plus committing two new analog op-amp selections for the output buffer stage.
  - **NEW DECISIONS banked from this order:**
    - **Output analog buffer architecture: two-tier op-amp strategy.** **OPA2350UA/2K5** ×5 (TI CMOS dual op-amp, 38 MHz GBW, rail-to-rail, 8-SOIC, ~$5) for SDTV composite / S-Video buffer paths after ADV7393 DAC. **LMH6643MAX/NOPB** ×10 (TI voltage-feedback op-amp, 130 MHz BW, low distortion, 8-SOIC, ~$1.50) for higher-bandwidth component and SDI-adjacent driver stages. Rationale: OPA2350 is rail-to-rail with adequate bandwidth and clean SDTV performance at a lower cost; LMH6643 reserved for component paths where bandwidth and distortion matter more. Both chips are TI-pedigreed, available, and widely used in pro video output stages. Final per-channel assignment deferred to carrier schematic phase.
    - **MCP6022-I/P** ×5 also included — 8-DIP general-purpose dual op-amp for non-critical breadboarding and sanity-check circuits. **Not the V1 production selection** — prototyping stock only.
  - **EXECUTING ON banked decisions (specific variants now committed):**
    - **ADV7393BCPZ-REEL** ×1 (~$16) — output video DAC/encoder banked in 7th update. **BCPZ** variant = industrial grade (no automotive AEC-Q qualification), 40-LFCSP package, reel packaging. Single chip serves composite/S-Video OR component output via I²C runtime mode selection.
    - **ADV7280AWBCPZ-M-RL** ×1 (~$19) — input video decoder per today's recommendation. **AW** variant = automotive AEC-Q100 qualified + extended −40°C to +105°C temp range (vs +85°C non-W). **-M** variant adds MIPI CSI-2 output alongside parallel YCbCr (parallel used for V1; MIPI as future-proofing for possible Mini variants).
    - **LTC6912CGN-2#PBF** ×1 (~$8) — PGA for genlock front-end, already confirmed in spec restructure entry. Resolves earlier "LTC6912 or AD8369 deferred" item from 7th update; AD8369 ruled out.
    - **EC11E18244AU** ×5 (~$4/unit) — Alps EC11 production encoder, banked in earlier spec entries.
    - **Si5351 eval boards (Adafruit 2045)** ×2 for genlock PLL prototype + parallel timing reference path development.
    - **Mean Well LRS-50-12** ×1 ($12) — internal PSU per power architecture entry (drop-in alternate to TDK-Lambda HWS50A; lower cost / higher availability path for bench prototype).
    - **Schaffner FN9260B-6-06** ×2 ($18 each) — IEC C14 filtered inlet per power architecture entry. Two ordered for V1 prototype + spare.
  - **FRONT PANEL UX EXPERIMENTATION:**
    - **3315Y-025-016L** ×2 alternate encoder for comparison feel vs. EC11.
    - Five knob style options for hand/eye testing: **CP34501** (C18 black, 6 mm spline), **FC7229NML** (KMR12B black, 6 mm spline), **CL178883** (K21 black, 6 mm D-shaft), **FC1611** (K1C black, 6 mm SF MD), **1202CY** (0.236" phenolic). Plus **CL1730** caps. **Production knob selection deferred to physical evaluation.**
    - **SPK-023A** ×5 black plastic spacers (mounting hardware).
  - **PROTOTYPE CONNECTORS & PASSIVES:**
    - 75 Ω PCB-mount BNCs: **0731711900** straight ×5 + **0731010401** right-angle ×5 for prototype carrier boards.
    - **CP-88T-75** ×4 BNC 75 Ω terminators for impedance testing and unused-output termination.
    - Resistor prototyping stock: **MFR-25FTE52-3K3** (3.3 kΩ, 1%, 1/4 W) ×30 + **MFR-25FRF52-1R** (1 Ω, 1%, 1/4 W) ×25 + **MFR-25FTE52-2R** (2 Ω, 1%, 1/4 W) ×25.
  - **STILL PENDING procurement (not in this order):** AD9204-20 dual ADC (other half of genlock front-end paired with LTC6912 ordered here), LT8619C raw chip + LT8619C-EVB (separate order via L2tek / AvaQ / Lontium direct, already on order separately per earlier today's entry), TPD12S016 ×2 HDMI ESD protection, MIKROE-2555 LTC6912 GainAMP click board (inbound per spec restructure entry), Murideo SIX-G HDCP test source (~$2,500 when budget allows), Trenz TE0720 SOM commercial-grade bench unit + TE0720-04-62I33MA production unit.
- 2026-05-11 (PM, follow-on) — **Second procurement order placed: AD9204 ADC + GainAMP click + additional encoder. Closes the genlock front-end bench parts list.**
  - **AD9204 procurement complete:** **AD9204BCPZ-20** ×1 (~$16) — production chip, dual 10-bit ADC, 20 MSPS speed grade, banked in spec restructure entry for genlock front-end. **AD9204-80EBZ** ×1 (~$278) — AD9204 eval board for bench characterization. Note: eval board uses the 80 MSPS speed grade rather than the 20 MSPS production grade; this is a deliberate bench choice (the 80 MSPS board can be downclocked to 20 MSPS for production-equivalent testing while also enabling higher-rate bench characterization for signal diagnostics and sync detail capture). Production carrier uses the cheaper AD9204BCPZ-20.
  - **GainAMP click confirmed on order:** **MIKROE-2555** ×2 (~$25 each, ~$50 total) — LTC6912 GainAMP click board for bench characterization of the genlock PGA. Noted as "inbound" in spec restructure entry; now confirmed quantity 2 ordered. Two enables parallel bench setups: one paired with AD9204 eval for full front-end chain bench, one standalone for PGA-only bandwidth characterization at max gain.
  - **Additional encoder for UX testing:** **EC111012010H** ×1 (~$10) — Alps Alpine 5V through-hole encoder variant, different physical configuration from the EC11E18244AU ×5 production encoder ordered earlier today. Continues the front-panel UX experimentation pattern. Final production encoder selection still EC11E18244AU per spec; EC111012010H is comparison-feel testing only.
  - **GENLOCK FRONT-END BENCH PARTS LIST NOW COMPLETE:** AD9204BCPZ-20 (ADC, production) + AD9204-80EBZ (ADC eval) + LTC6912CGN-2#PBF (PGA, production, from earlier today's order) + MIKROE-2555 ×2 (PGA eval) + Si5351 Adafruit 2045 ×2 (clock gen eval, from earlier today's order). All four functional blocks of Architecture A genlock front-end (ADC + PGA + clock gen + FPGA classification) have bench-evaluable hardware on order. RP2040 slow-control board status: assumed on-hand from prior projects or already in vault; verify.
  - **REMAINING procurement targets (post this order):** LT8619C-EVB + raw chip (separate order via L2tek/AvaQ already in flight), TPD12S016 ×2 HDMI ESD protection, Trenz TE0720 SOM (commercial bench + industrial production grades), Murideo SIX-G HDCP test source (~$2,500, budget-gated). With those, the V1 hardware parts list is essentially complete pending carrier PCB schematic phase.
- 2026-05-11 (PM, third follow-on) — **TPD12S016 procurement added: eval board + bare chip.** **TPD12S016PWREVM** (TI HDMI port protection eval module, gives hands-on with the chip's TVS clamps, DDC/HPD level shifters, and 5V cable-power switch before carrier PCB layout) + bare **TPD12S016** chip for the eventual carrier. Matches the established eval+production procurement pattern used for ADV7393, ADV7280, LT8619C, AD9204, and LTC6912. Closes the HDMI ESD protection line in the V1 hardware parts list. V1 carrier needs 2× TPD12S016 (one per HDMI port — input paired with LT8619C, output paired with direct FPGA TX); bare-chip quantity should be ≥2 for prototype build plus a spare for rework.
- 2026-05-11 (PM, scope clarification) — **HD pipeline + per-output independence + HDCP UI consent gate confirmed.** Pipeline scope broadened from "drive composite to a CRT" to "process arbitrary HD video signal, output to multiple formats and rates concurrently." Key shifts:
  - **FPGA pipeline is HD-bandwidth throughout** (RGB or YCbCr 4:2:2, up to 1080p60 / 148.5 MHz). Source rate preserved through scaler / color / geometry. Downconversion and rate-conversion happen **only inside per-output terminal encoders** — not as a single monolithic step.
  - **Outputs are independent and concurrent.** Same source video can drive 1080p60 HDMI + NTSC composite (with cadence convert) + HD component (YPbPr) + SDI passthrough — all live, all at their own format and rate.
  - **HDMI OUT repositioned from "monitoring/analysis only" to "full-quality HD passthrough."** Earlier (9th update) framing of HDMI OUT as a heavily-degraded analysis output is obsolete. HDMI OUT now carries the full pipeline at source rate.
  - **HDCP architecture: default-block + UI consent override.** Default behavior blocks HDCP-protected source content from full-quality HDMI OUT (protected content can still flow to analog outputs which don't carry HDCP, and to SDI OUT as a broadcast-workflow assumption). Operator unlocks HDMI passthrough of protected content via a UI dialog requiring explicit attestation ("I attest this is a non-violating use"). Non-protected content flows through HDMI OUT with no gate.
  - **Legal positioning (attorney-advised):** keeps the device's default behavior compliant with DMCA §1201 / DCP Compliance Rules, and shifts compliance responsibility to the operator for any override. Pattern mirrors how Decimator / some BMD products handle HDMI passthrough on HDCP-capable equipment. Still avoids the Xilinx HDCP IP license + DCP Adopter Agreement cost path explicitly avoided in the 9th update.
  - **Frame rate matrix expanded:** pipeline throughput rates now include 1080p50 / 1080p59.94 / 1080p60 / 720p50 / 720p59.94 / 720p60 alongside the CRT-driving rates (23.976 / 24 / 25 / 29.97 / 30). Per-output terminal encoders target their own rates with cadence-convert logic for rate translation when input ≠ output (60 → 24 via 5:2 pulldown + crossfade, 60 → 25 via 6:5, etc.).
  - **HDL implications:** the `vid_timing.v` / `vbi_gen.v` / `chroma_gen.v` / `sample_gen.v` already written for Phase 2 first-light constitute the composite encoder terminal, not the whole pipeline. The HD scaler / color / geometry stages and other terminal encoders (HDMI passthrough, component, SDI passthrough) are downstream HDL work.
  - **`signal-flow.md` diagram 1 rebuilt** to reflect: source mux → VDMA → HD pipeline → HD signal bus → fans out to independent terminal encoders → physical outputs.
- 2026-05-11 (PM, wisdom banked) — **Wide-back-porch default for 24p camera shoots.** Per industry wisdom from a 24-frame production veteran (relayed by Justin): when a CRT is being filmed at 24p, a broader-than-nominal back porch gives the camera shutter a larger target window to land its capture inside the active video region without straddling the V-blank — which is what produces the visible "sync bar" stripe on filmed CRT footage. Recommended default for "24p camera shoot" CRT profiles: back porch ≈ 7–10 µs (1.5–2× SMPTE 170M nominal ~4.7 µs). Tunable per-profile so DPs can adjust to their shutter angle. This is a default-tuning note for the per-profile sync structure parameters already banked in the CRT-specific signal controls section — recorded here to make sure the wisdom isn't lost between profile authoring sessions.
- 2026-05-11 (PM, sweep) — **Spec doc cleanup pass.** Removed or updated 15 stale items found in a systematic re-read of `01-spec.md`: dropped DisplayPort IN references (it was killed in the 2026-05-11 connector reorg); replaced "TI TMDS141 retimer" with the actual LT8619C HDMI RX chip in two places (Hardware foundation + V2 reference); reframed S-Video output as silicon-capable / no V1 connector (rather than a V1 output bullet); removed the duplicated Front panel section that appeared twice after the rear-LCD insert; rewrote the V1.5 sync-conversion section as a banked-feature description ("Sync conversion capability — V1 absorbed") since dual SYNC OUT + per-format selection covers it; updated the V2 / future section to reflect HD-pipeline scope (CRT-driving is one use case, not the only one); rewrote the HDR out-of-scope rationale (the old "Output is composite to a CRT" reasoning was wrong post HD-pipeline expansion); and resolved/removed two open questions that were already banked (rear-panel layout — done in panel-layout.md; PSU style — banked in Power & Safety section). **PSU primary/alternate flipped:** Mean Well LRS-50-12 is now primary (cheaper, wider availability, on order), TDK-Lambda HWS50A-12/A is alternate (lower noise, swap-in if Mean Well noise shows up as audible during bench characterization). Updated `bom-v1.md` to match the flip.
- 2026-05-11 (PM, RF tier) — **RF modulator daughter card banked as [PROPOSED] V1 Period tier.** Third SKU alongside Base and Broadcast, adds RF output on a TV channel carrier (NTSC Ch3/Ch4 + extensible to VHF E2–E12 and PAL-M) for the 1970s-and-earlier consumer CRT market segment whose sets have only an antenna/RF input. Mirrors the SDI daughter card mezzanine pattern: footprints + headers on every V1 carrier; populated at factory for Period SKU, blanked on Base/Broadcast, field-installable upgrade path via dealer. Stackable with SDI daughter card so a single unit can carry both for full-kitchen positioning.
  - **Course correction from AM analysis:** Initial 2026-05-11 AM session floated AD725 as a "simple integrated modulator." Re-read of the AD725 datasheet confirms it is an RGB-to-composite encoder with a luma-trap port designed to feed an external RF modulator — it does NOT itself modulate to RF. Discarded. Single-chip composite-to-RF modulator ICs (LM1889, MC1374, CXA1645, TA8717 class) are all discontinued; consumer RCA-to-RF boxes use unsourceable no-name ICs. Modern path is discrete VSB-AM modulator from in-production parts.
  - **Architecture:** carrier provides buffered composite tap (one additional LMH6643 op-amp channel from existing chip) + I²C + power + ENABLE GPIO over a small mezzanine connector. Daughter card hosts video buffer, local Si5351 for RF carrier, analog multiplier IC for AM modulation, output LC LPF for harmonic suppression, MMIC RF amp, 50→75 Ω match, panel-mount F-connector, shield can over RF section.
  - **Modulation:** DSB-AM (no VSB filter, simpler than VSB at the cost of 2× spectrum; consumer VSB receivers filter the unwanted sideband internally anyway). No audio carrier in V1 — Schindler has no audio pipeline; most consumer tuners display picture fine without 4.5 MHz audio subcarrier (speaker stays silent rather than buzzing). Audio pilot carrier deferred to V1.x if customer reports drive it.
  - **Tap point trade-off (banked):** post-ADV7393 buffered composite. Implies RF output rides on whatever format/rate the composite encoder is configured for (operator selects NTSC-M on composite OUT → RF also NTSC-M; switch to component mode → composite + RF both go dark). Documented limitation; future revision could add dedicated composite encoder on daughter card to decouple but not justified pre-evidence.
  - **Channel coverage:** VHF Ch2–Ch13 (54–216 MHz), software-selectable via I²C from UI. Covers US NTSC-M Ch3/Ch4 + optional Ch2/5/6, Japan NTSC-J Ch1/Ch2, PAL-B/G Europe E2–E12, PAL-M Brazil. UHF (>300 MHz) deferred.
  - **Output level:** ~−40 to −30 dBm at F-connector, adjustable, short-coax-into-CRT design (not broadcast). Stays inside FCC Part 15.119 cable-output limits with shielded RF section + output LPF (2nd harmonic ≥30 dB below fundamental).
  - **Parts banked (with bench-eval-phase final selection on the modulator chip):**
    - **AM modulator:** **ADL5391ACPZ** primary (Analog Devices DC–2.0 GHz multiplier, 16-LFCSP, ~$18 at qty 100, modern symmetric-core architecture); **AD835ARZ** fallback (250 MHz multiplier, 8-SOIC, ~$25 at qty 100, classic part with abundant reference designs). Order both for prototype bench eval.
    - **RF carrier gen:** **Si5351A-B-GT** local on daughter card (~$1.50) + 25 MHz crystal (~$0.50). Decouples from carrier's genlock Si5351; carrier's ch1/ch2 stay reserved for future GPSDO 10 MHz distribution.
    - **RF amp:** Mini-Circuits **ERA-3SM+** MMIC (DC–3 GHz, ~22 dB gain, ~$3.50, SOT-89, 50 Ω native — needs simple 50→75 Ω match).
    - **Output filter:** 5th-order Chebyshev or Butterworth LC LPF (~$1.50 in passives — Coilcraft 0805CS class inductors + C0G ceramic caps).
    - **F-connector:** Amphenol RF 82-4421 class panel-mount 75 Ω (~$1.50).
    - **Shield can:** Wurth WE-SHC or Laird small-format with frame (~$2.50).
    - **ESD on F-conn:** PESD3V3L1BA class low-cap TVS (~$0.20).
    - **DC block:** C0G 0.1 µF 50 V (~$0.10).
    - **Mezzanine:** Samtec **TSM-105-01-T-DV** (header) + **SSM-105-S-DV** (socket), 10-pin 0.1" dual-row, ~$3 the pair. Single connector pair sufficient since no high-speed digital crosses the boundary (composite is 6 MHz baseband; I²C and power are slow).
    - **Mezzanine pin assignment:** GND × 4, +3.3 V, +5 V, COMPOSITE (carrier → card, 75 Ω, 1 Vpp), I²C SCL, I²C SDA, ENABLE (Zynq PS GPIO active-high).
    - **Daughter card PCB:** 50×50 mm 2-layer FR-4 with solid ground plane under RF section (~$4 at qty 100 via JLCPCB / PCBWay).
  - **Carrier-side additions (on every V1 carrier, base + broadcast + period):** mezzanine header footprints + termination passives + one additional LMH6643 op-amp channel routed to header for composite tap leg. ~$1.50 in unpopulated passives on Base/Broadcast carriers (header lands unpopulated). No silicon impact on Base/Broadcast.
  - **Rear-panel mechanical:** single F-connector cutout (~10 mm), blanked on Base + Broadcast SKUs, populated on Period SKU.
  - **Daughter card BOM total: ~$38 per unit at qty 100.** Period SKU adds this on top of Base.
  - **FCC strategy:** stay within Part 15.119 cable-output device limits (shielded RF section + LPF harmonic suppression + low output power + coax-only output). Expected formal Part 15 test campaign: ~$5–10K at an accredited lab when SKU ships commercially. Adds to Schindler cert scope but isolated to Period tier.
  - **Open questions documented for bench-eval phase:** (a) final modulator chip ADL5391 vs AD835; (b) output LPF topology (Chebyshev vs Butterworth); (c) 50→75 Ω matching (resistive pad vs Mini-Circuits TC4-1W+ transformer); (d) Si5351 reference source (local 25 MHz crystal vs carrier reference); (e) V1.x audio carrier pilot decision pending customer evidence; (f) channel-selection UI surface (front-panel vs web-only) pending UI spec phase.
  - **Full architecture and parts spec banked in new doc:** `docs/rf-modulator-daughter-card.md`. Spec entry added to `01-spec.md` between SDI daughter card section and Sync conversion capability section. BOM section 7 added to `bom-v1.md`.
- 2026-05-11 (PM, RF locked in) — **RF subsystem confirmed: baked into V1 carrier, not a daughter card. SKU axis collapses to Base + Broadcast.** Five decisions banked this session:
  - **EVALZ pricing correction.** ADI ADL5391-EVALZ is ~$300 at DigiKey, not the $95 I'd quoted earlier. Confirmed cheap-bench-eval path: **EC Buying ADL5391 breakout board** (~$15-25 AliExpress) + **ADL5391ACPZ-R7** bare chip ($15 DigiKey, known-authentic backup against counterfeit-chip risk on Chinese board) + **AD835ARZ** ($25 DigiKey, architectural fallback). Total ~$55 in silicon vs $300 ADI EVALZ. Justin's pattern (cheap thing for bench + known-good backup) applied.
  - **"One analog out, selectable" architecture committed.** Operator picks one of three analog output modes via UI: composite (BNC live), RF Ch3 or RF Ch4 (F-conn live, ADV7393 stays in composite mode), or component (3× component BNC live, ADV7393 in component mode). Composite and RF share the same ADV7393 composite encoding; they differ only on which output path is gated. HDMI and SDI remain independently live regardless of analog-out mode. Mode-mux on the carrier: ADG419 SPST switch on composite BNC + FET switch on ERA-3 bias supply, both driven by Zynq PS GPIOs.
  - **Bake into every carrier, drop daughter-card framing.** BOM delta (~$33) too small to justify SKU bifurcation. Customer segments fuzzy (any DP could encounter a period CRT). FCC scope already covers every unit (WiFi/BT cert mandatory regardless), so RF is incremental in cert, not bifurcating. Clean product story: every Schindler 2.0 has HDMI + SDI + one selectable analog out. **SKU axis collapses to Base + Broadcast only.** Period SKU tier eliminated.
  - **Ch3/Ch4 only — NTSC US scope.** Drops earlier VHF Ch2-13 framing. US-centric customer base, every period US set tunes Ch3 or Ch4 as VCR-connect channel pair. Cleaner spectrum: 56–73 MHz bandpass filter covers both video + audio carriers for both channels, rejects everything outside band including 2nd harmonics (122.5–134.5 MHz). Eliminates need for separate harmonic LPF. Simpler UI: Ch3/Ch4 toggle. PAL/NTSC-J/PAL-M expansion deferred to firmware-only V1.x if international demand materializes (same hardware, different Si5351 register loads + wider bandpass swap).
  - **Audio Path A confirmed (silent pilot, no FM modulation).** Si5351 ch2 generates unmodulated CW carrier at video_carrier + 4.5 MHz (65.75 MHz for Ch3, 71.75 MHz for Ch4). TV's audio detector sees carrier presence (satisfies intercarrier AGC on touchy 1970s sets); no audio to demodulate; speaker stays silent. Schindler's mission is camera-captured visuals; film cameras don't record CRT speaker audio, so audible audio is not a requirement. **Audio FM modulation analysis documented but deferred:** if V1.x customer evidence drives speaker output need, the Path B approach (discrete Colpitts VCO with varactor, FPGA-generated 1 kHz test tone via PWM + RC LPF, sigma-delta modulator in fabric — ~$3 BOM, ~1 day HDL) is the documented next step. 2-channel "stereo" via BTSC MTS explicitly rejected for V1 (BTSC didn't exist until 1984; every period set in target market is mono).
  - **Audio FPGA capability noted for future reference:** Zynq-7020 can generate audio trivially (NCO + sigma-delta + PWM out + audio buffer). Audio I/O is the gating question, not FPGA capability. Si5351 cannot FM-modulate at audio rates (I²C register-write rate is way too slow), so FM audio requires either a discrete VCO (Path B) or FPGA-direct synthesis via a fast DAC (Path C — over-engineered for V1).
  - **RF subsystem BOM (per V1 unit, all SKUs):** ADL5391ACPZ-R7 ($18) + dedicated Si5351A-B-GT + crystal ($2) + ERA-3SM+ ($3.50) + bandpass LC filter ($1.50) + 50→75 Ω match ($1) + audio combiner passives ($0.50) + mode-mux ADG419 + FET ($1.80) + F-conn + ESD + DC block ($1.80) + shield can ($2.50) + bypass passives ($1) = **~$33 per unit**. Built into every V1 carrier; no daughter card, no mezzanine, no separate PCB.
  - **Dedicated Si5351 for RF subsystem** (separate from genlock Si5351). Reasoning: genlock Si5351 is constantly nudged by FPGA loop filter to track reference; RF wants stable fixed frequencies. Cross-coupling avoided by separation. Genlock Si5351 ch1/ch2 stay reserved for future GPSDO 10 MHz distribution. RF Si5351 channel allocation: ch1 = video carrier (Ch3 61.25 MHz / Ch4 67.25 MHz), ch2 = audio pilot (Ch3 65.75 MHz / Ch4 71.75 MHz), ch0 free.
  - **Rear-panel placement:** F-connector lives **beside** the composite BNC. Both physically present, only one electrically live at a time per mode-mux state. Absorbed in the existing ~179 mm of unused panel slack documented in `panel-layout.md` — no connector reorganization needed.
  - **Updated BOM rollup:** Base unit ~$817 (was $784, +$33 RF). Broadcast unit ~$849 (was $816, +$33 RF). Period tier eliminated.
  - **Doc operations:** New authoritative doc `docs/rf-modulator-subsystem.md` written. Prior doc `docs/rf-modulator-daughter-card.md` overwritten with redirect stub (can be deleted at convenience). `01-spec.md` RF section rewritten from `[PROPOSED]` daughter card to confirmed built-in. `bom-v1.md` Section 7 rewritten; rollup table loses Period column.
- 2026-05-11 (PM, MVPHD bank) — **10 high-priority MVPHD-feature gaps closed for V1.** After authoring `mvphd-comparison.md` and reviewing the gap list, Justin confirmed 9 items as must-have and one (#2 EFX) expanded to 13 effects total. Banked into `01-spec.md` + `ui-menu.md` + `mvphd-comparison.md`.
  - **Still image buffers** (4 FLASH-backed slots on TE0720 eMMC, selectable as input source). Use cases: power-on splash, idle reference, brand idents, signal-loss fallback to a known image. Storage budget ~24 MB total of 8 GB eMMC.
  - **Front-panel BLACK quick-action** — fade-to-black with configurable transition time, default Q1 binding.
  - **Front-panel MONO quick-action** — monochrome toggle, default Q2 binding.
  - **Shutter Phase Reference test pattern** (renamed from MVPHD's F1-BLU/F2-YEL — the underlying alternating-field two-color signal is industry convention, not proprietary). Default Blue/Yellow; color pair operator-configurable (also Red/Cyan, Magenta/Cyan, Black/White, Custom). Visual companion to the wide-back-porch wisdom for filming CRTs.
  - **YUV color-circle color-temperature adjust** — X/Y axes on the chroma plane, in addition to RGB white-point trim. Preserves luminance + saturation when shifting color temp. Inherited from MVPHD Ch. 5 approach; preferred by video colorists.
  - **3:2 cadence auto-detect** + **Motion filter selection** (Quadratic / Linear / Off). Cleaner 24 p extraction from telecined 30 / 60 fps source than blind frame-rate conversion.
  - **Proc Amp Enable bypass** — single per-input toggle to disable all proc-amp adjustments. Default Q3 binding for raw-vs-adjusted quick compare.
  - **Custom user-loaded test signals** (8 slots, web upload, eMMC-persistent). Operator can add focus charts, alignment grids, brand idents.
  - **14:9 Letter/Pillar Box ARC mode** + reworked § 4.2 Aspect Ratio Conversion showing both directions (16:9 → 4:3 AND 4:3 → 16:9) per the MVPHD pattern operators are familiar with.
  - **EFX library (full 13 effects + modifiers)** — Justin chose to extend beyond MVPHD's 5 with on-brand CRT-prop effects. The list:
    - From MVPHD: Freeze frame, Random noise, Block artifacts (collapsed from MVPHD's small/large split into one intensity-configurable effect), Fade-to-Black (handled by the BLACK button).
    - New on-brand CRT/period effects: CRT power-off (collapse to line → dot → flash → black, ~1.5 s — Justin's idea, on-brand differentiator), CRT power-on (paired flash + scan-in), Vertical hold loss (rolling), Snow burst (channel change), Color rolling (chroma desync), VHS tracking error (drifting noise bars), Hum bars, Burn-in ghost overlay, Scanline emphasis (for **CRT look on a downstream LCD** — shoot an LCD prop that reads as a CRT in-camera), Blur (Gaussian — Tier 3 HDL cost, may land later in V1), Solarize, Posterize.
    - Modifiers: blend/mixer (0–100 % wet/dry), transition time (0–240 frames), per-effect intensity parameters.
    - Profile-persistent: effects can be temporarily toggled OR saved into a per-CRT profile.
    - HDL effort: ~2–3 weeks for MVPHD set + Tier 1 CRT effects post-first-light; blur deferred if needed.
  - **Skipped (per Justin's call):** Y/C Delay input control. Analog composite isn't the headline feature; silicon supports it for V1.x firmware add if a niche customer asks.
  - **UI menu doc restructure:** new § 8 Effects inserted; § 8-12 renumbered to § 9-13 (Profiles / Behavior / Test+Maint / System / Compliance). Cross-references updated.
- 2026-05-11 (PM, still buffers detail) — **Still image buffer + microSD slot specifics banked.** Following the MVPHD-bank entry above, detail-pass through the still image buffer feature:
  - **Format:** PNG, up to 1920×1080 (downscaled on the fly to active output rate).
  - **Storage tier 1: TE0720 eMMC** (4 slots, ~25 MB of 8 GB used). Always present, fast.
  - **Storage tier 2: front-panel microSD slot** (resolves prior `panel-layout.md` open question — now confirmed). Push-push panel-mount socket, ~$2 BOM. Dual-purpose: (a) firmware updates without rear-panel access (MVPHD-familiar workflow), (b) extended still-image library — operator loads images from card into one of the 4 active buffers.
  - **Load time:** < 1 s cold (Zynq A9 dual-core PNG decode ~250–500 ms dominates), < 10 ms cached in DDR3 after first load.
  - **First-boot state:** Buffer 1 pre-populated at factory with Schindler splash (logo + IP + firmware version, identifiable before any config). Buffers 2–4 ship empty.
  - **Burn-in ghost source:** EFX § 8.4 burn-in ghost overlay sources its image from one of the 4 still buffers (no separate upload mechanism).
  - **Static only in V1** — no animated buffer support; static-image is sufficient for the planned use cases.
  - **Thumbnails:** front-panel TFT shows 2×2 grid (~220 × 128 px each at production 480 × 272 panel resolution); web UI shows full-quality thumbnails.
  - **Front-panel TFT resolution decision:** production target confirmed as **480 × 272 WQVGA on 2.8" 16:9 LTDC** parallel panel (sweet spot for 1 RU panel height + thumbnail readability). Prototype path stays on 320 × 240 ILI9341 SPI.
  - Updated `01-spec.md` Still image buffers + Front panel sections, `ui-menu.md` § 1.7, and `panel-layout.md` front-panel inventory + ASCII sketch + open-question resolution.
- 2026-05-11 (PM, display part-number bank) — **Front + rear display modules confirmed.** Replaces the prior aspirational "2.8" 16:9 WQVGA" + "2.4" 16:9 SPI" placeholders with actual Newhaven part numbers after dimensional review of three candidate datasheets (Justin's downloads). Decision drivers: (a) 1 RU front-panel vertical budget hard-capped at ~30 mm — rules out standard 2.8" 4:3 modules whose outline is 50 mm tall, (b) bar / ultra-wide TFT form factor is the pro-broadcast 1 RU convention.
  - **Front TFT: Newhaven NHD-2.9-376960AF-ASXP** — 2.9" 376×960 IPS TFT, ST7701SN controller, mounted **rotated 90° to landscape (effective 960 × 376)**. Module outline 32.6 × 78.7 mm; bezel-opening cutout **69 × 28 mm** in landscape orientation; recessed pocket ~80 × 33 × 3 mm. Interface options: 24-bit parallel RGB **OR 4-wire SPI** — the SPI path lets the STM32H735 drive it from a standard SPI peripheral without LTDC parallel routing. 190 PPI density (~6× the pixel count of the prior 480×272 plan) → crisp text, sharp buffer thumbnails. Chosen over the alternative NHD-3.9-480128AF-ASXP bar TFT (3.9" 480×128, 119 PPI) because of the 6× pixel count and the SPI interface option, despite the 3.9" being marginally wider/more "broadcast-bar-look."
  - **Rear status LCD: Newhaven NHD-1.5-240240AF-CSXP** — 1.5" 240×240 IPS square TFT, ST7789VI controller (common, well-supported by Zynq Linux fbtft). Module outline 32.52 × 35.32 mm; active-area cutout **28 × 28 mm**; recessed pocket ~33 × 36 × 3 mm. Interface: 8-bit 8080-II parallel OR 3/4-wire SPI (SPI preferred — one Zynq PS SPI peripheral). The 1:1 square aspect requires a redesign of the rear status view from "full I/O grid" to "paginated summary" (selected ref + lock state + IP + page-through I/O detail) — workable since the rear LCD is read-only and the operator scrolls pages by approaching the rear panel anyway.
  - **Thumbnail layout updated:** still-buffer thumbnails on the front-panel TFT change from a 2×2 grid (at the prior 480×272 plan) to a **4-wide horizontal strip** at the new 960×376 landscape resolution. Each thumbnail ~240 × 180 px with buffer name + slot number label below. Web UI still shows full-quality thumbnails.
  - **BOM impact:** front TFT ~$30–45 (depends on supplier — Newhaven direct or distributor), rear LCD ~$15–25. Total displays ~$45–70 per unit. `bom-v1.md` update deferred to Justin's RF-modulator commit.
  - Files updated: `01-spec.md` Front panel + Rear panel + Still buffer thumbnail sections; `panel-layout.md` front-panel inventory + cutout specs in mechanical TODO + open-question resolution; `ui-menu.md` surface-owners table + thumbnail layout note + front-panel TFT bus open question. `bom-v1.md` skipped to avoid colliding with Justin's uncommitted RF section additions.
- 2026-05-11 (PM, RF MLP correction) — **50→75 Ω transformer swapped for resistive minimum-loss pad. Corrects an earlier spec error.**
  - **The error:** prior RF subsystem spec offered Mini-Circuits TC4-1W+ transformer as the dB-preserving alternative to a resistive pad for 50→75 Ω matching. **TC4-1W+ is a 1:4 impedance ratio transformer (50↔200 Ω), NOT 50↔75.** Same applies to MACOM MABAES0061 which Justin flagged as a cheaper substitute. Confirmed by datasheet re-read 2026-05-11 PM. Both parts are wrong for the application; swapping one for the other was substituting one mistake for a cheaper version of the same mistake.
  - **Why no commercial "1:4 transformer" does 50↔75:** the impedance ratio needed is 1.5 (75÷50), which means turns ratio √1.5 ≈ 1.22:1. That's not a standard manufacturing ratio. True 50↔75 transformers (Mini-Circuits TM2-43X+, TCM2-33X+ class) exist with internal 1:1.5 turns but cost $3–8 and aren't justified here.
  - **The right answer: resistive Minimum-Loss Pad (MLP).** Two 1% resistors: **43.2 Ω series + 86.6 Ω shunt** (off-the-shelf 43 Ω + 82 Ω 1% is close enough; 0.7% Z-mismatch is invisible at our level budget). **5.7 dB insertion loss** — mathematically optimal for a purely resistive 50↔75 Ω match. Broadband DC-to-GHz. No tuning, no drift, no parasitic resonances, $0.10 in passives.
  - **Why 5.7 dB doesn't matter for us:** ERA-3SM+ has ~22 dB gain. Target output is −40 to −30 dBm at the F-connector. CRT tuners accept −50 to −10 dBm. The pad loss is rounding error inside the available dB headroom. Trading the pad for a $3–8 transformer to save dB we don't need is solving a problem that doesn't exist.
  - **Trigger for the catch:** Justin questioned the TC4-1W+ price against the cheaper MABAES0061. Investigating the substitution exposed that both are 1:4 ratio, neither does 50↔75, and the original recommendation was wrong. Honest BOM review caught a real error.
  - **BOM impact:** RF subsystem per-unit drops $33 → $32. Rollup: Base unit ~$816 (was $817), Broadcast unit ~$848 (was $849). Bench-eval starter drops ~$75–80 → ~$65–70 (TC4-1W+ ×2 removed, resistor pair added).
  - **Open-question closure:** "50→75 Ω match: resistive pad vs TC4-1W+ transformer" is no longer an open bench-eval-phase question — the layout-phase decision is committed to the MLP.
  - **Doc operations:** Updated four docs to align on MLP language and the corrected totals — `docs/rf-modulator-subsystem.md` (architecture diagram, § 4 50→75 Ω match section, BOM table, bench bring-up checklist, open-questions list), `docs/bom-v1.md` (§ 7 RF chain bullet, bench eval parts list, section subtotal table, open BOM questions, V1 rollup table), `docs/01-spec.md` (RF modulator output section: architecture summary line, total BOM line, open-questions list, baked-in-vs-daughter-card BOM-delta figure), and this changelog entry.
- 2026-05-11 (PM, front-panel mezzanine architecture) — **Front panel becomes its own mezzanine board with RP2040 + BridgeTek BT817Q EVE 4. STM32H735IGT6 retires from V1 production spec.** Architectural pivot driven by the dimensional review of the NHD-2.9 panel datasheet, which revealed (a) the panel's "Driver / No Controller" architecture means it needs continuous parallel-RGB pixel data — no SPI-only path was actually viable for pixel data, and (b) the 4-wire SPI option is for init commands only. Combined with Justin's preference to make the front panel its own board with RP2040 as the local MCU, the decision flow landed on a dedicated graphics-controller chip + RP2040 + simple host link.
  - **New front-panel mezzanine BOM:**
    - **RP2040** + 12 MHz crystal + W25Q16 QSPI boot flash + decoupling — ~$3 (UI MCU; reads encoders + buttons via PIO/GPIO, drives front-panel LED column, sends EVE command lists over SPI, syncs UI state to Zynq PS over UART)
    - **BridgeTek BT817Q EVE 4** graphics controller + 12 MHz crystal + decoupling — ~$10–13 single qty, ~$8 at qty 100 (drives NHD-2.9 over 24-bit parallel RGB, holds 1 MB internal RAM_G frame buffer, handles all rendering autonomously from RP2040 command lists)
    - **NHD-2.9 backlight boost regulator** (TI TPS61040 class) — ~$0.50 (the panel's 6.0 V / 100 mA backlight needs a small boost from the 5 V / 12 V rail; can't drive from 3.3 V directly)
    - **Front-mezzanine ↔ main-carrier connector** — small ribbon, ~6 pins (UART TX/RX + 12 V + 5 V + GND + reserve), ~$3 / pair
  - **STM32H735IGT6 retires from V1 production spec.** Was the planned UI MCU on the main carrier. Replaced by RP2040 + BT817Q on the front-panel mezzanine. **STM32H735G-DK already procured stays in inventory as a bench spare / educational asset only** (no longer in V1 production path).
  - **Two RP2040s total in V1:** one on the main carrier for genlock slow-control (previously banked), one on the front-panel mezzanine for UI duties. Different roles, different boards, no shared firmware, no interference. Bare RP2040 chips ~$1 each — negligible BOM impact.
  - **UI framework simplifies dramatically.** No TouchGFX, no LVGL, no LTDC parallel routing. BridgeTek EVE Asset Builder / EVE Screen Editor + the FT8xx command set is a higher-level paradigm: RP2040 sends display lists ("draw rect, draw text, load JPEG, set brightness"), EVE renders to RAM_G, drives the panel. Built-in primitives include rectangles, lines, anti-aliased text, JPEG/PNG decode, button widgets, gauges, sliders, screen rotation, audio synthesis.
  - **Front-panel TFT drive path correction:** the prior changelog note that the NHD-2.9 could be driven over SPI directly from the STM32H735 was wrong — the SPI on this panel is for init only; pixel data must come over parallel RGB. BT817Q EVE chip resolves this by holding the frame buffer internally and driving parallel RGB to the panel.
  - **Rear LCD (NHD-1.5) detail updates from datasheet review:** has built-in controller + frame RAM (write-once, hold-forever — perfect for 1 Hz status updates). Interface mode hardwired to 4-wire SPI via strap pins IM0=0, IM1=1, IM2=1. 3.0 V / 100 mA backlight needs a small dedicated regulator (LDO from 3.3 V is sufficient, ~$0.20). 1200 cd/m² brightness. Owned by Zynq PS over one dedicated SPI port; remains a carrier-board element (not mezzanine).
  - **Mezzanine ↔ carrier link is UART + power only.** No SPI, no I²C, no parallel buses cross the mezzanine connector. Cleaner cable, smaller connector, no high-speed signal integrity concerns.
  - **Boot time:** UI alive in < 1 s from cold boot via RP2040 (no Linux dependency). Main system can take 15-30 s to boot Linux on Zynq PS behind the scenes with progress bar shown on the front TFT.
  - **Bench eval kit additions needed:** Raspberry Pi Pico (RP2040 dev board, ~$4) + a BT817Q dev board (Crystalfontz CFA10110 or Riverdi RVT-EVE-eval, ~$80–150) for front-panel firmware development.
  - **Files updated:** `01-spec.md` (Hardware foundation UI MCU bullet, Development hardware section, Front panel TFT bullet, UI architecture section, Rear panel status display section with backlight + strap-pin details); `ui-menu.md` (surface-owners table + front-panel TFT bus open-question resolution); `panel-layout.md` (front-panel inventory adds RP2040+BT817Q row, TFT description updated to reflect new drive path); `signal-flow.md` diagram 3 control plane (STM32H735 block replaced with `UIMEZ` mezzanine subgraph containing RP2040 + BT817Q + the panel-side elements, wires updated to show RP2040 → SPI → BT817Q → parallel RGB → TFT chain, UART link to Zynq PS state aggregator, notes section); this changelog. `bom-v1.md` not touched — Justin's RF-modulator additions are unstaged there; he'll roll in the mezzanine BOM line when finalizing.
- 2026-05-13 — **Active dev priority shift: HD pipeline first, analog terminal encoders last.** Justin's call: skip chroma burst bench verification for now (Phase 2 finishing work); focus on building the HD pipeline top-down (HDMI in/out → VDMA → scaler → FRC → color → geometry → re-attach analog terminal encoders at the end). Active dev platform stays the **Digilent Zybo Z7-20** (same Z-7020 silicon family as production TE0720; HDL ports 1:1). The chroma burst, I/Q chroma modulator, R2R amplitude calibration, and colored test patterns work all become Phase G work — paused, not abandoned. New phase tasks A–G filed in TaskList.
- 2026-05-13 — **Doc tree consolidation: one internal-electronics spec, two packaging variants.** Justin's call: Mini and Pro share the same carrier PCB design and TE0720 SOM. SKU split is packaging-only (chassis form factor + front-panel hardware + rear-panel I/O complement + carrier stuffing variant). Internal architecture is one design.
  - **Merged into a single canonical `01-spec.md`:** prior `01-spec.md` (Pro-tier full spec) + `mini-spec.md` (Mini scope) + `carrier-board.md` (production carrier design). New `01-spec.md` covers the unified electronics architecture with `[All SKUs]` / `[Pro only]` / `[stuffing variant]` annotations per subsystem.
  - **New `packaging-skus.md`** captures everything SKU-specific: chassis form factor, front-panel hardware (Mini = mono OLED + tactile; Pro = NHD-2.9 + mezzanine), rear-panel I/O complement, carrier stuffing matrix, per-SKU BOM rollups, open packaging decisions (Mini WiFi chip, Mini PSU strategy, Mini S-Video connector).
  - **New `dev-roadmap.md`** = SSOT for active dev arc + recently-completed work + deferred work + forward-looking hardware migration + forward-looking SKU build-out. Prevents the doc-misuse trap where forward-looking architecture docs get mistaken for active dev state.
  - **Deleted:** `mini-spec.md`, `mini-phase1-bringup.md`, `carrier-board.md` (absorbed into `01-spec.md` + `packaging-skus.md` + `dev-roadmap.md`); `rf-modulator-daughter-card.md` (redirect stub from when RF moved from daughter-card to built-in); `02-features-backlogREPLACED BY 01-SPEC.md` (already marked stale); `03-chroma-implementation.md` (legacy Phase 2 chroma detail — content folded into `01-spec.md` § 2.3 + `dev-roadmap.md` Phase G).
  - **Decisions banked during merge:**
    - **RF modulator: Pro-tier only** (Mini stuffing omits ADL5391 + dedicated Si5351 + ERA-3 + bandpass + shield can + F-connector). Period CRT support is a Pro feature.
    - **Genlock: both SKUs.** Mini gets the RP2040 + Si5351 + LTC6912 + AD9204 genlock front-end (1 BNC REF IN), no dual SYNC OUT driver chain (Pro adds that).
    - **Pro mezzanine UI (RP2040 + BT817Q + NHD-2.9 + NHD-1.5 + per-connector LEDs + rear status LCD): Pro-only.** Mini uses simpler 1.3" mono OLED + 9 tactile switches driven directly by Zynq PS via `i2c-dev` + `gpio-sysfs`.
    - **Stuffing-variant approach over daughter-card-on-headers** for SDI silicon — Pro factory-stuffs GS3470 + GS2962; Mini doesn't. Cleaner manufacturing than headers-and-daughter-card. (The expansion header design rule remains for future add-on capability, not SDI-specifically.)
  - **TE0701 references removed from spec docs.** TE0701 was a mistaken entry in yesterday's docs; never actually procured (only TE0703-07 was). All non-TE0720 hardware references (Smart Artix, Smart Zynq SL, TE0712, TinyZynq, TE0703, TE0720-04-31C33MA, TE0720-04-61C530A, Arty S7-25) are scoped to `dev-roadmap.md` § 6 (future-evaluation candidates) and `00-index.md` "future-evaluation hardware" section. Active dev platform is **Zybo Z7-20**; production target is **TE0720-04-62I33MA**.
  - **`bom-v1.md`** lightly updated (status header + SKU scope) but content preserved — Justin has unstaged RF additions there that he'll commit separately.
  - **Light SKU-scope notes** added to: `signal-flow.md` (Pro-architecture diagrams, Mini differences noted), `panel-layout.md` (Pro panel; Mini in packaging-skus.md), `ui-menu.md` (Pro UI; Mini UI deferred), `mvphd-comparison.md` (Schindler 2.0 in comparison = Pro feature set).
  - **`00-index.md`** rewritten to reflect the new doc tree and SKU strategy.
- 2026-05-15 — **Inbound hardware logged + Pro mezzanine dev platform decided + VGA OUT moved from killed to under consideration.** Three discrete updates batched into one banking pass while filesystem MCP was intermittently disconnected.
  - **Inbound 2026-05-13 hardware section added to `00-index.md`.** Two orders logged:
    - *Digilent (FedEx 487403305746):* Pmod OLED 128×32 mono (410-222), Pmod OLEDrgb 96×64 color (410-323), Pmod ENC rotary encoder ×2 (410-117), Pmod SWT 4-switch (410-083), Pmod R2R (410-165), Pmod TPH2 test points (410-135), Pmod Cable Kit + splitter (240-021-2), Pmod VGA (410-345). Aimed at Arty S7-25 ecosystem for parallel front-panel UI prototyping + (conditional) VGA OUT prototyping if banked.
    - *HelloFPGA (China):* Smart Artix V1.3 + Smart Zynq SL V1.3 (inventory only — already archived in `docs/Hardware/`), LT8619C HDMI-to-RGB chips ×5 (production-quantity HDMI-input silicon stockpile), LT8619C demo board (second eval).
    - Net effect: enables a parallel front-panel UI prototyping arc on Arty S7-25 + Pmods that doesn't block on Zybo HD pipeline phases A-G, plus production-quantity HDMI-input silicon on hand.
  - **Pro mezzanine EVE dev platform: Riverdi RVT43HLBFWN00** (4.3" 480×272 EVE4 intelligent display with BT817Q + flash + boost regulator + everything on a single board, ~$62). Selected over the previously considered BridgeTek ME817EV evaluation board (~$100–120) for three reasons: (a) **interface match** — ME817EV's 50-pin RGB connector and 40-pin LVDS connector don't pin-match the production NHD-2.9 panel's 40-pin FFC (different pitch, different pin order), would require custom adapter PCB to actually drive NHD-2.9; (b) **complete out of the box** — RVT43HLBFWN00 is an intelligent display, so EVE chip + LCD + flash + backlight regulator all integrated and ready to send SPI command lists from a Pico host; no adapter PCB to fab, no level shifters to wire; (c) **matches production silicon exactly** — BT817Q (EVE4) is what gets soldered onto the production Pro mezzanine. Different resolution and aspect ratio than NHD-2.9 (480×272 landscape vs 376×960 portrait-rotated-landscape) is acceptable since EVE programming model is panel-agnostic and the resolution can be re-tuned at deployment. Order pending at Mouser (DigiKey out of stock; Riverdi direct $100 shipping rejected). Banked into `dev-roadmap.md` § 5.2 as Pro mezzanine dev hardware and noted in `00-index.md` inbound section. **Phase ordering:** RVT43HLBFWN00 supports EVE toolchain learning + Pro UI flow prototyping in parallel with Zybo HD pipeline work; NHD-2.9 production panel validation deferred to mezzanine schematic phase (later) via custom adapter board.
  - **EVE generation evaluation:** Bridgetek launched BT820B (EVE5) March 2025. Considered as an upgrade path for the Pro mezzanine, ruled out for V1: (a) BT820B outputs LVDS only — not parallel RGB — so it can't drive the NHD-2.9 (parallel RGB panel) without an LVDS-to-RGB converter; (b) 329-ball LFBGA package vs BT817Q's VQFN64 adds X-ray inspection + more complex assembly partner; (c) external DDR3 SDRAM required vs BT817Q's internal 1 MB RAM_G; (d) targeted at 1920×1200 industrial HMI panels with live video blending — overkill for a 376×960 status display. BT817AQ (refinement of BT817Q, pin-compatible, current production variant) noted as a minor variant worth tracking for production BOM but not requiring spec change at this time. **Decision: stay with BT817Q on production mezzanine.**
  - **VGA OUT moved from killed (§ 22) to under consideration (§ 21).** Earlier `01-spec.md` § 22 row "VGA in/out (HD-15) | Killed by design..." replaced with narrower "VGA IN (HD-15) | Significant HDL complexity (auto-positioning + sample-phase recovery) for a declining input format. Out of scope for V1." — i.e., only VGA IN remains killed; VGA OUT promoted to open-question status.
    - **Use case driving reconsideration:** driving VGA-input CRTs on camera at 24/30 fps film cadences. Period sets and modern shoots where a VGA computer monitor needs to be visible on-camera showing source content at the camera's frame rate. Most VGA monitors won't lock below ~31 kHz horizontal sync, so raw 24/30 Hz output won't display — the solution is frame-doubling to 48/60 Hz refresh (24p → 48 Hz, 30p → 60 Hz), which gives VGA-monitor-compatible refresh rates while keeping integer camera-shutter / CRT-refresh alignment.
    - **Architecture sketched (pending bank-decision):** ADV7125BCPZ-AAAA triple 8-bit video DAC (330 MSPS, ~$6) + 74AHCT125 sync level shifter (~$0.50) + HD-15 panel-mount connector (~$2) + 75 Ω termination passives (~$1.50) → ~$10/unit BOM addition. Both SKUs. Drives a dedicated rear-panel HD-15 with R/G/B analog + HSYNC/VSYNC. Independent of the ADV7393 analog terminal — runs from its own DAC chain off the HD signal bus so it can output at VGA-compliant refresh rates while the CRT analog terminal runs at native 24/30 fps.
    - **HDL implications (pending bank-decision):** new VGA terminal encoder block in the FPGA. Taps HD signal bus → 1:2 frame doubler → VGA-rate pixel timing generator → RGB to ADV7125 + HSYNC/VSYNC through level shifter. Operator selects output resolution (640×480 / 800×600 / 1024×768 / 1280×720) and encoder derives refresh rate from source cadence. New HDL effort — not absorbed by existing blocks. Bench prototype path: Digilent Pmod VGA (410-345, on inbound) provides R-2R DAC + HD-15 on Zybo Z7-20 for HDL block bring-up before committing to ADV7125 on production carrier.
    - **Why this isn't banked yet:** Justin wants VGA OUT off the killed list but explicitly not yet a confirmed feature — only under consideration. So this changelog entry captures the analysis done in case the decision flips to YES later, but the spec docs (§ 3 subsystems, § 4.2 output rates, § 16 rear panels, packaging-skus stuffing matrix, dev-roadmap Phase G) are NOT modified to assume VGA OUT will ship. Only § 21 open questions carries the VGA OUT under-consideration entry with the architecture summary. **Pending Justin's call.**
  - **Files updated:** `00-index.md` (Inbound section added, Pmod VGA note flagged as conditional on banking decision); `01-spec.md` (§ 21 adds VGA OUT under consideration entry, § 22 narrowed to kill only VGA IN); `packaging-skus.md` (no content change — considered adding ME817EV reference but decision pivoted to RVT43HLBFWN00 which lives in `dev-roadmap.md`); `dev-roadmap.md` (§ 5.2 Pro mezzanine adds RVT43HLBFWN00 as EVE dev hardware with rationale).
  - **Working-style note (process correction):** initial banking pass over-committed VGA OUT as a confirmed feature — added full § 3.10 subsystem detail, § 4.2 output rates, § 16 HD-15 rows, packaging-skus VGA stuffing row + BOM additions, and Phase G HDL block in dev-roadmap. Justin's reply clarified: "VGA is just off the NO list and back to under consideration for both Mini and Pro in the same format, as described." Rolled back the over-commit; only § 21 open-question entry remains in spec docs proper, full architecture detail preserved here in changelog for future reference. Confirms working-style preference: don't auto-rebuild scope based on inferred sign-off; require explicit decision-to-bank.
- 2026-05-15 — **Pre-carrier-layout open question banked: second GbE jack on Pro v2 rear panel.** Not a Schindler decision per se — flagged here because the carrier PCB is pre-layout and the decision must be made before that work activates to avoid a board respin later. **Context:** TE0720 SOM exposes the Zynq-7020's two hard GEMs. Current Schindler spec uses one for management; the second is unused. Adding a second GbE PHY + magnetics + rear-panel RJ45 at carrier layout time costs ~$10–20 BOM and roughly half a day of additional layout work. Pulling it out later would require a board respin. **Why it's worth flagging now:** preserves the option for a hypothetical LED Processor SKU built on the same carrier architecture (see `_PROJECTS/LED-Processor-Concept/00-index.md` for the broader concept). Doesn't commit to that product, doesn't expand Schindler scope, doesn't change Schindler messaging. If the LED Processor concept never activates, the second jack is a redundant management interface or a future-expansion port. **Decision:** **OPEN** — pending Justin's call at carrier-layout-go time. Justin's working-style note above applies: not auto-baking this into the spec; only flagging here in the changelog and §21 open questions until explicit decision-to-bank.
- 2026-06-12 — **RF modulator made truly optional (tier decision).** With the RF chain committed to a genuine standalone shielded daughter board (2026-06-11 partition), the tier framing is simplified to its cleanest form: RF is **never standard, never default-populated** — fitted only when ordered, on any build, as a clean populate/omit with no carrier respin. The carrier (common to both SKUs) always carries the ~$1.70 interface footprints (u.FL baseband-in jack + 6-pin DC/I²C header; the u.FL→u.FL video-in cable and the u.FL→rear-panel-F output cable are bought only when RF is fitted). This kills the two conflicting prior framings — both the 2026-05-11 "RF is universal / populated on every unit" bake-in **and** the later "Pro-only, fitted on Pro" reading. RF is now positioned as a **Pro-tier option**; **Mini-eligibility left as an open product/commercial call** (technically fittable on any carrier — carrier + composite buffer are common to both SKUs). Reconciled across `01-spec.md` (§0 stuffing bullet + SKU table + post-table note + §3.9 retagged [Optional module]), `rf-modulator-subsystem.md` (Tier line + superseded-banner cleanup), and `rf-modulator-daughter-board-option.md` (Open Decisions → Tier). No change to the RF *chain* architecture or parts (ADL5391 etc. unchanged). Decision by Justin.
- 2026-06-12 — **Optional second composite output banked (pre-layout) + COTS-modulator alternative noted.** (1) The analog-out buffer stage has a spare LMH6643 channel (2× duals = 4 ch, 3 used). Route it to a second buffered CVBS output so the carrier can expose a second rear composite BNC. Preferred implementation — in the **no-RF stuffing variant** the rear F-connector position becomes a second composite BNC (RF fitted → F-connector; RF omitted → 2nd composite out); an always-present composite mult/loop is the alternative. Must be fixed before carrier layout (footprint + back-term + panel position) — respin to add later, same class as the 2nd-GbE-jack flag. RF baseband tap unaffected (high-Z bridge off the first composite channel). Banked in `01-spec.md` §3.4. (2) **COTS-certified-modulator alternative** to the custom ADL5391 chain: a turnkey analog NTSC Ch3/4 composite-to-RF modulator (e.g. CIMPLE CO ~$33, RFM-1C ~$14) fed from the composite tap arrives FCC-certified, sidestepping the ~$8–15K intentional-radiator cert. Tradeoff = signal quality / integration elegance / host-auth nuance vs. the custom chain; custom chain stays default, COTS kept as budget/cert-sidestep/prototype option. Banked in `rf-modulator-daughter-board-option.md`.
- 2026-06-13 — **SDI IN Loop added; HDMI IN Loop rejected.** Added an SDI input loop-through output (reclocked/buffered loop re-using the GS3470 loop/mux path parked 2026-05-11), **Pro-only**, one extra BNC → Pro rear-panel BNC count 14→15. Placed carrier-side (rear-panel **Row 1**) next to the GS3470 as an SI-critical 3G serial line. It's an **active** loop (drops on power loss), **not** a passive DA loop, and explicitly **not** the original passive tee (passive 3G-SDI loops degrade the signal) — confirm the exact GS3470 loop mechanism + any external reclocker/buffer at schematic. **HDMI IN loop evaluated and rejected:** no passive HDMI loop exists; a TMDS splitter/redriver + HDCP-repeater path is out of proportion for V1, and concurrent outputs (§2.2) already serve the downstream-monitor use case. Banked in `01-spec.md` (§3.6 + §16.2) and `panel-layout.md` (inventory + totals). KiCad implementation (loop BNC on the SDI sheet + rear-panel placement) is the code agent's to do. Decision by Justin.
- 2026-06-13 — **Rear-panel BNC finalized: Molex 73101-0120 confirmed; Amphenol RF 031-70352 = second source.** Closes the rear-BNC finalization carried in the 2026-06-13 session handoff, which had tentatively floated Amphenol RF **031-70352** as the *primary* candidate. Catalog + price verification settles it the other way: the 2026-06-12 part-lock pass already locked **Molex 73101-0120** for all 13+ BNCs, and the confirmed specs back that choice — 75 Ω, right-angle through-hole bulkhead rear-mount, **integrated board-locks** (mechanical PCB retention, valuable for connectors that get hand-patched repeatedly), **DC–4 GHz** (covers 3G-SDI 2.97 Gb/s, overkill for REF/analog), **~$4.49 ea** single-qty (TestEquity, multiples of 20; Molex 73101 series marketed to SMPTE/HD-video return-loss). **Amphenol RF 031-70352** (equivalent 75 Ω R/A TH bulkhead rear-mount, ~4 GHz class) recorded as a **drop-in second source** for supply resilience — note Amphenol's catalog frames 031-70352 as a standard BNC (≈1–4 GHz class), so it is appropriate for the same role but is not a 12G-optimized part (neither is the Molex; Schindler HD tops out at 3G, so standard 75 Ω BNC is correct — a 12G upgrade would mean HD-BNC, out of scope). No BOM part change (Molex was already the locked part); `bom-v1.md` updated to add the Amphenol second-source line. Decision by Justin.
- 2026-06-13 — **Rear-panel reorg + SDI OUT mirror + REF interconnect (Option A) banked; KiCad structural pass triaged.** Five decisions from the 2026-06-13 session, banked together.
  - **(1) SDI OUT mirror — ADDED.** The GS2962 exposes two serial-digital outputs (**C10 / D10**); the second drives a buffered duplicate of the same processed SDI stream to a free BNC. **Active** (drops on power loss), SI-critical 3G → carrier-side, rear **Row 1** next to the GS2962. Pro rear BNC count **15 → 16**. Banked in `01-spec.md` §3.6 + §16.2 and `panel-layout.md`. KiCad: the agent already placed it as **J703** on Sheet 7 (alongside J700 IN / J702 IN-LOOP / J701 OUT).
  - **(2) Backplane left-to-right order revised:** `PWR → WiFi/Net/USB → Display(LCD) → INPUTS → OUTPUTS → REF (all 4 sync BNCs grouped) → RF (far-right, isolated)`. This **overturns** the prior `panel-layout.md` organising principle #2 ("sync follows the IN/OUT direction"): REF is now a single grouped right-side zone rather than split across the input/output sections. RF on the far right keeps the one VHF-radiating connector away from the genlock REF front-end. The LCD moves from centre to a left-of-inputs position next to PWR/Net/USB.
  - **(3) Vertical row rule:** **Row 2 (top) = analog** (composite + component, in & out); **Row 1 (bottom) = digital** (SDI + HDMI). Within the REF zone: REF IN/LOOP on the top row, both SYNC OUT on the bottom row. The analog-top rows are the SI-tolerant lines that ride the **riser** sub-board; the digital-bottom rows stay carrier-rooted. (Riser partition / A4-stub formal write still pending Justin's go — see OPEN below.)
  - **(4) Stale-composite changelog correction:** the 2026-06-12 "Optional second composite output" entry described routing the spare LMH6643 channel to a 2nd rear composite BNC. Superseded direction — **we will tap, no second composite BNC added**; the spare channel is not exposed as a panel connector in the current plan. The 2026-06-12 entry and `01-spec.md` §3.4 are left as-written for history but should be read as superseded by this line.
  - **(5) REF interconnect — Option A (pigtail) banked.** Phase-critical genlock REF must not cross a board-to-board mezzanine hop. Resolution: panel-mounted REF BNCs → short **75 Ω coax pigtail** → **Hirose U.FL-R-SMT-1** receptacle on the carrier (50 Ω, 6 GHz, ~$0.65–1.30 ea), keeping continuous coax from panel to the carrier genlock front-end regardless of which physical sub-board the BNC mounts to. 50 Ω u.FL on a few-cm pigtail is an electrically negligible reflection at genlock/tri-level edge rates. **Decision basis:** the ≤3-SI-line heuristic (REF = 2 lines → pigtail) AND catalog reality — a true **75 Ω blind-mate float-bullet is essentially a custom part** (Amphenol RF AFI/HD-AFI/SMP/SMPM/PSMP and Samtec SMP/SMPM board-to-board float families are all 50 Ω; the only 75 Ω board-level option is MMCX, which is push/snap, not floating blind-mate). **Documented upgrade path:** if impedance-exact + serviceable is ever wanted on those 2 lines, swap to a **75 Ω MMCX** PCB jack (~500 mating cycles, larger, ~$3–6 ea). This also **killed the separate sync-daughter-board idea** — the genlock loop is closed through the carrier (Si5351 ch0 = FPGA master clock + the digital PLL lives in the FPGA), so genlock can't be cleanly amputated to its own board, unlike the one-way RF chain. Banked in `01-spec.md` §3.7, `bom-v1.md` §2 (carrier-side u.FL + pigtail lines added), and this changelog.
  - **KiCad structural pass (#11 + SDI) triaged — sound.** TE0720 single 4-unit symbol replaced by 3 physical Razor Beam connectors (J200/J201 = Samtec LSHM-150 2×50 → JM1/JM2; J202 = LSHM-130 2×30 → JM3; 100/100/60 = 260 pins). Synthesized `Conn_02x50_Odd_Even` housed in a new project lib `CarrierGen.kicad_sym` + registered in sym-lib-table (no JustinLibrary edits); pre-layout swap to a real Samtec LSHM-150 symbol logged as a layout-phase to-do. ERC + netlist export both exit 0; 132 components. **BOM reconciliation handled here:** added the 3 carrier-side Samtec SoM sockets as an explicit `bom-v1.md` line, and added **J702/J703** to `refdes-map.md`. The TE0720 module ($300) remains a mechanical/SoM BOM line with no schematic refdes (the 3 connectors are its carrier sockets) — noted in the BOM.
  - **Still OPEN (Justin's go needed):** riser-partition formal spec + A4-stub doc (riser = new 4th PCB carrying the SI-tolerant analog video BNCs + one relocated TLC59116; REF/RF/Display zones stay carrier-rooted); and the `panel-layout.md` **ASCII rear-panel sketch redraw** to match the new order + row rule (flagged, not silently redrawn — geometry deserves Justin's eye, and he's mocking it in SketchUp). The KiCad agent is holding its wiring pass pending this carrier-vs-riser physical decision. Decisions by Justin.
- 2026-06-13 — **Power-tree datasheet-verify corrections + eFuse part swap to TPS26601.** A datasheet pass on Sheet 3 (`power-tree-design.md` §0a) produced four items plus the eFuse part decision.
  - **(1) eFuse → TI TPS26601** (replaces TPS26600). The chosen **latch-off** fault posture *is* the '601's MODE-open default, so **MODE is left open — no strap component**; the '600's MODE-open default is *auto-retry*, which would have needed a strap to reach latch. Identical pinout/family, so the placed KiCad symbol is reused (set value to '601). Pairs with the LTC2954 → SHDN soft-power chain — a button cycle clears a latched fault. Swap by Justin.
  - **(2) LTC2954 PDT corrected** — capacitor-only timer at **6.4 s/µF** (no series R, contrary to the prior note); for the intended ~5 s hard-off, **C311 ≈ 0.82 µF** (the prior 0.1 µF gave only ~0.64 s).
  - **(3) LTC2954 ONT added** to the netlist — float = default ~64 ms turn-on debounce; **C312 ≈ 0.1 µF** recommended for a deliberate anti-accidental ~0.64 s hold-to-power-on.
  - **(4) ADV7511 analog corrected off `+3V3_A`** — the ADV7511 analog/PLL supplies are **1.8 V**, not 3.3 V (3.3 V is DVDD-IO only); `+3V3_A` correctly serves **ADV7393 VAA only**, ADV7511 analog moves to the 1.8 V domain (resolve at the ADV7511 load sheet). Also banked the ADP7142 POL targets: U307/U308 = 1.8 V, U309 = 3.3 V (each ADJ set at its load sheet).
  - Reconciled across `power-tree-design.md` (§0/§0a/§2.1/§4), `bom-v1.md` §3 + part-lock list, `refdes-map.md` Sheet 3, and `01-spec.md` §1.3 (eFuse part). Corrections by Claude under delegation. **Carry-forward:** the ADV7511-analog fix lives in `power-tree-design.md` + this changelog; `01-spec.md` §1.3's "3.3 V analog branch" line still lists ADV7511 analog and should be corrected when the SSOT power section is next revised.
- 2026-06-13 — **Per-connector status LED selected: Lumex SSF-LXH409SISUGW.** Closes the rear-status-LED part-lock open item. The committed driver is **3× TLC59116F** (constant-current **sink**), which forces a **common-anode** LED (anodes → V+, each color's cathode → its own sink channel). Selected the **Lumex SSF-LXH409SISUGW** — 3 mm bi-color red (636 nm, 350 mcd) / green (574 nm, 130 mcd), **common-anode**, **one-piece right-angle PCB indicator** (housed CBI — emits parallel to the board → faces the rear panel with no separate holder or light pipe), 3-lead offset-cathode, 60° dome, 5–25 mA, Vf 2.0/2.2 V (internal die SSL-LX3059SISUGW). **Replaces** the prior placeholder Kingbright **L-3VEGW-CA** (vertical-emit — would have needed a lay-down/right-angle mount or a light pipe). Two other RA candidates evaluated and rejected this session: **Dialight 551-3513F** (common-*cathode* — wrong polarity for a sink driver) and the **VCC H101CBC + H-101C 90° holder** combo (common-anode and workable, but a two-piece LED-in-holder solution vs the Lumex one-piece). **Build note:** balance R/G in TLC59116 PWM duty — red is brighter than green at equal current. **Cost:** placeholder was ~$0.20/ea; the housed RA CBI runs ~$0.60–1.00/ea (confirm at procurement), so the UX/Panel subsystem subtotal rises ~$10 (21× LEDs ~$4 → ~$13–16) — reconcile the roll-up at procurement. Reconciled across `bom-v1.md` §4 + part-lock list, `refdes-map.md` Sheet 11 (D1100–D1120), `panel-layout.md` (principle #6 + ASCII legend + Open-questions placement item), and `01-spec.md` §16.4. The only remaining LED open item is the silkscreen/PCB position relative to each connector (above/below/beside), a mechanical-design detail. Decision by Justin.
- 2026-06-13 — **HDMI-out TX reconciliation: production = external ADV7511; stale BOM/changelog cleanup.** Caught during the Sheet-3/Sheet-8 KiCad review gate. The BOM's "HDMI Output" section + the 2026-05-10 9th-update entry still described the early **direct-FPGA-TX** plan ("Xilinx free HDMI 1.4 TX IP, no separate chip"), which had been **reversed to an external ADV7511KSTZ HDMI transmitter** ~2026-06-11 (see §3.2's dated independent-output-bus note). The spec body (§2.3 "drives the external ADV7511," §3.2, §3.4, §1.3), `refdes-map.md` Sheet 4 (U403 = ADV7511KSTZ), and `power-tree-design.md` (ADV7511 analog on the 1.8 V domain) were all **already correct**; only the BOM HDMI-Output line, the silicon subtotal, and the FPGA-fabric Xilinx-IP list were stale. **Resolution — production HDMI out = ADV7511KSTZ** (LQFP-100, **non-HDCP** variant: no encryption asserted on the TMDS output, preserving the §3.5 monitoring/analysis posture), fed parallel RGB/YCbCr from the FPGA on its own 16-bit bus. **The Xilinx HDMI 1.4 TX IP / direct-FPGA-TMDS path is dev-board/Zybo bring-up only** — the Z-7020 has no MGTs (fine for Zybo, but the ADV7511 is the clean production transmitter). Reconciled in `bom-v1.md`: HDMI-Output TX line → ADV7511KSTZ (~$7); signal-path silicon subtotal +$7 (Base ~$43→~$50, Broadcast ~$75→~$82); roll-up unit total +$7 (~$807→~$814 / ~$839→~$846); FPGA-fabric HDL list tagged dev-board. No spec-body change (already correct); the 9th-update entry left as historical. Correction by Justin — caught a Claude misread that had briefly mis-flagged the ADV7511 as a phantom during the review gate.
- 2026-06-13 — **B33 re-strapped to 1.8 V for the AD9204; new `+1V8_D` digital rail; SDI control = SPI; ADV7511-analog rail corrected.** From the Sheet-8 review gate. (1) **AD9204 DRVDD confirmed 1.8 V** (Justin) — its 1.8 V CMOS data won't clear a 3.3 V LVCMOS bank's ~2.0 V VIH, so **B33 VCCIO33 is re-strapped 3.3 V → 1.8 V**. The TE0720 allows VCCIO33 = 1.2–3.3 V on bank 33 and it's carrier-fed on JM2-5, so the ADC data + DCO land native LVCMOS18 with no level translator (Option A, chosen over a translator). (2) **New `+1V8_D` digital rail** — small LDO (U310) off `+3V3`, ~0.1 A, feeds VCCIO33 + AD9204 DRVDD, kept off the analog `+1V8_A` so output-driver switching doesn't couple into the ADC AVDD. AD9204 AVDD stays on its dedicated POL (U307 = `AVDD_GENADC`); AD9204 VREF bypass = 470 nF / 6.3 V / X5R. (3) **GS3470/GS2962 control = SPI (GSPI), not I²C** (confirmed from the GS3470 CS/SCLK/SDIN/SDOUT pinout) — removed from I²C bus A. (4) **LTC6912 PGA SPI confirmed RP2040-mastered**, not in B33 (resolves the SoM-doc §6-vs-§7 conflict; frees the B33 L18 pair). (5) **ADV7511 analog/PLL = 1.8 V** corrected in spec §1.3 + §3.4 (was wrongly on the 3.3 V analog branch — the §0a-4 carry-forward, now done). Reconciled across `sheet3-te0720-som-backbone.md` (§1/§2/§5/§6/§7/§8), `power-tree-design.md` (§0/§1/§4), `refdes-map.md` Sheet 3 (U310), `bom-v1.md` §3, and `01-spec.md` §1.3/§3.4/§3.6. **Sheet 3 gains the U310 LDO — the KiCad agent revisits Sheet 3 for that one part.** Decisions by Justin.
- 2026-06-13 — **UI unified across all SKUs onto a standalone off-SoM MCU (kills the control-plane fork).** Trigger: the Mini can't host PetaLinux the way the Pro can, so a PS/PetaLinux-hosted UI + PS-served web app can't be the universal solution. **Committed:** one UI firmware on an off-SoM MCU drives **both** the front-panel TFT **and** the web UI for all SKUs; `schindlerd` shrinks to a **thin PS-side AXI register agent** (universal contract = MCU-head ↔ thin-PS-agent ↔ AXI); the catalog / JSON-RPC+COBS protocol / profile schema in `control-plane-architecture.md` are reused, just split (catalog/profiles/web-server on the MCU, register writes on the PS agent). Supersedes the PS-hosted-UI model (Pro = RP2040 panel + PS web; Mini = PS-direct OLED). **Open sub-decision (ratify before Sheet 10/11 wiring + BOM lock):** the head MCU must host networking for the web UI — **RP2040 has none** — so choose **ESP32-S3** (integrated WiFi, one chip drives EVE + serves HTTP/WS) vs **RP2040 + W5500/W6100** (wired Ethernet, keeps RP2040 firmware) vs **RP2040 + CYW43439** (WiFi, keeps RP2040). Cascades to **(a)** SoM network disposition (drop vs keep GbE/LWB5+ now that the web UI is off-SoM — Sheet 10 control+net + BOM) and **(b)** MCU↔PS transport (planned UART vs a PL-side AXI-Lite bridge for PS-independence). Direction captured in `control-plane-architecture.md` (dated block at top); spec §15/§17 + `packaging-skus.md` propagate when the MCU is locked. Direction by Justin.
- 2026-06-13 — **Control head locked = ESP32-S3; control path made PS-independent (FPGA-fabric AXI-Lite bridge); LWB5+ dropped.** Follows the unified-off-SoM-UI decision. Head = **ESP32-S3** — integrated WiFi drives the BT817Q EVE + serves the web UI + reads encoders/buttons on one chip. **Control path revised to PS-independent:** ESP32 → serial link → an **AXI-Lite bridge in the FPGA fabric**, no Zynq PS in the operator-control loop (supersedes the "thin PS agent" first drafted, which assumed a Mini PS — the intent is *no Mini PS*). This makes the control system portable across video silicon. On the Pro the PS still runs PetaLinux for the heavy pipeline + storage but is out of the control path. **Front-panel interconnect:** ESP32 lives on the Pro mezzanine with the EVE/TFT/encoders/buttons (all UI I/O local; EVE↔TFT parallel RGB stays on-board); mezzanine↔carrier = one **FFC** carrying power + a UART control link to the fabric bridge; Mini runs the same ESP32 driving its OLED directly (SKU-gated firmware). **LWB5+ WiFi dropped** (ESP32 provides WiFi; saves ~$30 + the SDIO routing). **Still open:** whether "no Mini PS" / "other chips for other systems" means the Mini leaves the TE0720 for different silicon — breaks the §0 one-carrier/same-SoM premise and re-homes Mini PetaLinux-dependent features (EDID §11, still images §13, OTA/logging §14, DDR frame buffers); needs a scope call before the SKU/packaging/refdes/BOM rewrite. Captured in `control-plane-architecture.md` direction block. Decisions by Justin.
- 2026-06-13 — **Genlock Si5351 (U902) corrected off the PS video I²C onto the RP2040's bus.** Caught in the KiCad straight-through review: the agent placed the genlock Si5351 on `I2C_VID` (PS-mastered) per `sheet3-te0720-som-backbone.md` §7's bus-A listing — but the genlock RP2040 (U900) masters the Si5351 (refdes-map Sheet 9 "U900 … I²C → Si5351"; spec §3.7; §5/§6 genlock-loop description; and §7's own RP2040 line). §7 bus-A was self-contradictory. Fixed §7: removed Si5351 from I²C bus A, added **I²C bus C (genlock, RP2040-mastered): Si5351 @ 0x60**, clarified the RP2040 line + tagged bus B master = PS. Agent to relocate U902 off I2C_VID onto the genlock RP2040 I²C. Correction by Claude under delegation; confirmed against refdes-map + spec §3.7.
- 2026-06-13 — **Control path finalized = PS thin agent (fabric bridge dropped); Mini-silicon scope closed; firmware/update paths set.** Justin confirmed the Mini stays on a TE0720 (never below a 0720) — so it has a Zynq PS, and the earlier 'no Mini PS / PS-independent fabric bridge' is dropped. **Final control architecture:** ESP32-S3 = unified UI head (panel + web, both SKUs); **ESP32 ↔ UART ↔ PS thin agent ↔ AXI** (PS = register authority / `schindlerd`: full PetaLinux on the Pro, thin/bare-metal agent on a lighter-memory Mini 0720). §0 one-carrier / same-TE0720 premise intact — no packaging rewrite for different silicon. **Firmware / update paths (proposed):** rear **USB-C → PS** (recovery/console + FPGA/Linux image) + GbE/WiFi OTA + JTAG; **ESP32 via WiFi OTA** (web UI) with **PS-over-UART recovery** (PS drives EN + GPIO0 across the FFC → single-USB whole-box recovery, brick-proof); **genlock RP2040 via a small SWD/BOOTSEL service header**. Mezzanine FFC grows ~6 → ~10 pins (power + UART + PWR_BTN + EN + GPIO0). LWB5+ stays dropped (ESP32 WiFi); GbE kept. Captured in `control-plane-architecture.md` direction block. Architecture by Justin; update-path specifics proposed by Claude pending ratification. **Pending propagation:** spec §14/§15/§17 + `packaging-skus.md` rewrite; `refdes-map.md` Sheet 10/11 + A2 (drop LWB5+, A2 MCU → ESP32-S3, FFC pin-count, RP2040 service header) + BOM.
- 2026-06-13 — **Analog signal-path conditioning ratified (§7) + B34 re-strapped to 1.8 V for SDI (Option A); SYNC-1 DAC relocated B34→B35.** Two coupled outcomes from the analog-conditioning review gate (`analog-signal-conditioning-proposal.md`).
  - **§7 ratified (Justin):** (1) **AC-couple** analog/sync outputs (220 µF; CRT/PVM clamp restores DC — consistent with `opamp-stage.md`). (2) **×2 gain, doubly-terminated** buffers (1.0 Vpp composite / 700 mV component at the load; re-verify the ADV7393 full-scale). (3) **Per-input switchable term via an I²C GPIO expander on `I2C_HK`** (loop inputs REF/SDI require it; composite/component may be fixed-term; switch on the term-resistor ground leg = SI-clean). (4) **Low-cap (<3 pF) video TVS at the panel BNCs + BAV99 IC-side clamp; SDI gets ultra-low-cap (<0.5 pF) ESD, not BAV99.** (5) **SDI rails (datasheet-confirmed):** GS2962 = 1.2 V core / 1.2 V PLL-VCO (RC-filtered) / 3.3 V sensitive-AVDD / 1.8 V I/O / cable-driver on `+3V3_SDIDRV`; GS3470 = 1.2 V core / 1.2 V + 1.8 V analog / 1.8 V I/O / external 27 MHz ref clock.
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

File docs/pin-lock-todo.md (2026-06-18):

# Schindler 2.0 — Pin-Lock TODO (carrier A1, `SchindlerCarrierBoard_V1`)

**Date:** 2026-06-17 · **Status:** open tracker. The PS-EMIO / PL pin-lock has become the defining piece of remaining carrier work. Everything below draws from **one shared SoM pin pool** (TE0720 via J200/J201/J202 — LSHM) and **must be allocated as a single pass**, not piecemeal — otherwise signals get wired against an assignment that later moves.

This doc is the index of what that pass must cover. Detail lives in the linked docs; this is the scope + dependency map.

---

## The pin pool

Per [`pin-budget.md`](pin-budget.md): **152 PL I/O** across banks — now **extracted to concrete pins** in [`pin-lock-substrate.md`](pin-lock-substrate.md) (from the Trenz TEBA0841 workbook, sheet `RAW_m_TE0720_REV04`). Real bank/voltage split: **B35 (48, JM1) + B13 (50, JM2) = 3.3 V; B34 (36, JM3) + B33 (18, JM2) = 1.8 V.** Demand 119/152 reconciles, every bank within capacity (B35 fullest at 42/48). Plus **PS-MIO** (dedicated, mostly spoken-for by DDR/QSPI/SD/etc.) and **PS-EMIO** (64-wide GPIO from the PS, but each externally-routed line costs **one PL package pin** in a voltage-matched bank). Current PL ≈ 78 % used (~33 free) **before** the items below are all placed.

**Golden rule:** EMIO control lines and parallel data buses compete for the same PL package pins. Free-pin headroom must be checked **after** the fast buses are allocated.

---

## Items the pin-lock pass must allocate

### A. Fast parallel data buses (front-end PL egress) — the bulk of the pins
Enumerate exact widths/pins at lock; approximate scope:

| Bus | Chip | ~width | Voltage / bank | Clock pin? |
|-----|---|---|---|---|
| BT.656 video out | ADV7280 (U500) | 8 data + LLC (+3 if discrete HS/VS/FIELD) + INTRQ* | 3.3 V | **LLC = clock-capable** |
| Pixel bus in | ADV7393 (U600) | ~16 data + CLKIN + HS/VS | 3.3 V | CLKIN (MMCM out) |
| Pixel bus out | ADV7511 (U403) | ~16–24 data + DE/HS/VS/PCLK | **1.8–3.3 V — inputs accept either (flex bank)** | PCLK (MMCM out) |
| RGB out | LT8619C (U402) | ~24 data + DE/HS/VS/PCLK | 3.3 V | **PCLK recovered = clock-capable** |
| SDI RX parallel | GS3470 (U700) | 20 (DOUT) + PCLK + status | 1.8 V (B34) | **PCLK recovered = clock-capable** |
| SDI TX parallel | GS2962 (U701) | 20 (DIN) + PCLK | 1.8 V (B34) | PCLK (MMCM out) |
| ADC out | AD9204 (U801) | dual 10-bit + DCO | (verify) | **DCO = clock-capable** |
| DAC in | AD9742 (U903) | ~10–14 + sample clk | (verify) | sample clk (PLL out) |

⚠ Widths are from interface knowledge — **enumerate against the netlist's deferred (`unconnected-`) bus pins at lock.**

### B. Control / housekeeping EMIO + I²C
- **I²C buses:** I2C_VID (PS-EMIO → ADV7280/7393/7511 + LT8619C), I2C_HK (PS → U803 PCA9555 + others), I2C_GENLK (RP2040-side). The EMIO-routed ones consume PL pins.
- **SPI buses:** SDI_SPI (GS3470/GS2962 host), GENLK_SPI, LCD_SPI — confirm which ride PL vs PS-MIO.
- **Status/interrupts:** ADV7280 INTRQ* and any per-chip IRQ/status that needs a host pin.

### C. Reset / power-down nets — see [`reset-strategy.md`](reset-strategy.md)
**TWO named reset nets, both PS-EMIO-driven, pull-DOWN + PS-drives-HIGH-to-release** (the parts mandate a power-up reset — see reset-strategy.md). Allocate here so reset isn't wired twice:
| Net | Voltage | Idle pull | Release | Members |
|-----|---|---|---|---|
| `VIDEO_RESET_N` | 3.3 V | 10 kΩ → **GND** | PS-EMIO drives HIGH | ADV7280 RESET*, ADV7393 *RESET, LT8619C RESET_N |
| `SDI_RESET_N` | 1.8 V | 10 kΩ → **GND** | PS-EMIO drives HIGH | GS3470 ~RESET, GS2962 ~RESET |

**ADV7511 PD is NOT an EMIO net** — it's a **static 2 kΩ → +1V8_A** tie that latches I²C address **0x7A** + active-low PD at power-up (the part has no reset pin; recovery = I²C script or box power-cycle). This **frees the EMIO** the earlier `HDMI_TX_PD_N` net would have cost → reset/PD now costs **2 EMIO, not 3**.

Plus standalone pulls (no EMIO, place anytime but easiest in this pass): GS2962 STANDBY (pull-**down** GND), GS3470 ~TRST (**leave unconnected** — internal pull-down), RP2040 RUN (10 kΩ → +3V3 + 100 nF + test point).

### D. Clock-capable pin constraints
Recovered/reference clocks must land on **clock-capable PL pins** (MRCC/SRCC → BUFR/BUFG), per [`pin-budget.md`](pin-budget.md) §4:
- **Captured (BUFR):** ADV7280 LLC, LT8619C HDMI-in pixel clock, GS3470 SDI recovered clock, AD9204 DCO.
- **Synthesized (MMCM/PLL out → specific pins):** shared HDMI-out/SDI-out pixel clock (ADV7511 + GS2962), ADV7393 27 MHz CLKIN, AD9742 sample clock.
- These take priority for the limited clock-capable pins — allocate **before** general data bits.

---

## Cross-cutting constraints (apply to the whole pass)

1. **Voltage-bank match** — every signal lands in a bank whose VCCO matches its logic level: 3.3 V signals (ADV7280/7393 buses, LT8619C, VIDEO_RESET_N) → 3.3 V bank; 1.8 V signals (GS buses, SDI_RESET_N) → 1.8 V bank (B34/B33). **ADV7511 pixel bus is flex (inputs accept 1.8–3.3 V)** → place in whichever bank has room after the fixed buses. *(Same class of mistake as the C716/C717 GND_A catch — wrong rail/domain is silent until it bites.)*
2. **EMIO accounting after data buses** — confirm ≥2 voltage-matched control pins (the 2 reset nets) remain once A is placed (see reset-strategy.md EMIO note).
3. **Clock pins first** — D's clock-capable requirements constrain placement more than data bits; reserve them up front.
4. **U803 PCA9555 fallback** — on I2C_HK (off I2C_VID, so it survives an I2C_VID wedge); 3.3 V outputs only → fallback for VIDEO_RESET_N only, not the 1.8 V SDI net. PS-EMIO preferred for both reset nets.

---

## Sequencing

Do this as **one allocation pass**: (1) reserve clock-capable pins (D), (2) place the fast parallel buses (A) by voltage bank, (3) confirm control/EMIO headroom (B + C), (4) then wire — reset/PD nets, standalone pulls, and the bus connections together. Wiring any sub-part before the map is fixed means redoing it.

## Source docs
- [`reset-strategy.md`](reset-strategy.md) — the 3 reset/PD nets, per-pin polarity/rail/refdes (ratified plan).
- [`pin-budget.md`](pin-budget.md) — bank counts, MMCM/PLL budget, clock architecture.
- [`decoupling-audit.md`](decoupling-audit.md) — unrelated (decoupling/functional); kept separate on purpose.

## Open / to-confirm at lock
- Exact bus widths from the netlist deferred-pin list (A).
- Exact EMIO bit indices + PL pin locations (live in the Vivado PS block design, not the repo).
- AD9204 / AD9742 interface widths + clock-pin needs (B/D rows marked verify).
- ADV7511 PD polarity/level — **CONFIRMED**: no reset pin; static 2 kΩ → +1V8_A latches addr 0x7A + active-low PD (reset-strategy.md). ADV7511 inputs **accept 1.8–3.3 V logic** → pixel bus is **flex** bank-placement (constraint relaxed, row A updated). *(Residual: confirm U403's supply-pin set all got bypass — minor symbol-match check, decoupling-pass.)*
- Free clock-capable-pin count per bank vs the clock list in D.

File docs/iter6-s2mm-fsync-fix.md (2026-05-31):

# iter6: bottom-bars artifact — root cause + fix

**Status:** **RESOLVED 2026-05-22.** Bench-verified on monitor + DDR3 dump on branch `iter5-1080p-clean` head with iter6 changes applied.

**TL;DR:** The "bottom-bars artifact" / "bottom-rows leak" was on the **S2MM (write) side of VDMA**, not the scaler. The default AXIS-TUSER-driven frame boundary detection in `axi_vdma` v6.3 has ~27 rows of internal pipeline lag between TUSER on AXIS and the actual slot-pointer transition in DDR3. The first 27 rows of frame K+1 get written into the tail of slot K. **Fix:** drive S2MM's external `s2mm_fsync` input with a 1-cycle pulse on the rising edge of source vsync (`dvi2rgb_0/vid_pVSync`), enable `c_use_s2mm_fsync=1` and `c_flush_on_fsync=1`. The hardware fsync bypasses the AXIS-side detection entirely.

This doc supersedes:
- iter4g's hypothesis that the scaler was emitting wrong tap data ([docs/iter4g-diagnostic-findings.md](iter4g-diagnostic-findings.md)). The scaler is healthy — see "Counter evidence" below.
- iter4h's `VSIZE=747` over-allocate workaround which masked the bug but introduced 1-row-per-frame scroll.
- The memory note `schindler-bottom-bars-artifact` (mark RESOLVED).

## Symptom

On a 1280×720 output substrate fed by 1920×1080 SMPTE bars:

- **Slot K rows 0-693**: correct frame K content.
- **Slot K row 693**: BLACK (one cosmetic row, see "Side note" below).
- **Slot K rows 694-719**: **frame K+1's top-of-bars content** — exact byte-for-byte match against slot K+1 rows 0-26. **The 27-row leak.**
- **Guard row 720**: `0x000000` — S2MM does NOT write past VSIZE.

On the bench monitor with `MM2S +STRIDE shift` enabled (iter3i): the bottom ~26 displayed rows show SMPTE-main-bars content instead of PLUGE content. Visually presents as a thin colored strip at the very bottom of the frame.

**Deterministic across boots.** Not a coin-flip; not rate drift. Same content position every frame on a static source.

**Hidden by three confounders** prior to 2026-05-21:
1. MS2109 capture stick's framebuffer smooths out partial-row artifacts.
2. A faulty bench monitor displayed the artifact as different geometry than reality.
3. Osee GoStream switcher's input 2 was a motion loop; the motion masked the static leak signature.

## Counter evidence — the bug is on S2MM's side

Add scaler_v output TLAST counter ([hdl/scaler_v.v](../hdl/scaler_v.v) — see `out_tlast_count_snap`). Per source frame, snapshotted at input TUSER:

| Counter | Value | Meaning |
|---|---|---|
| `h_in` | 1080 | scaler_h received 1080 input TLASTs (= source rows) ✓ |
| `v_in` | 1080 | scaler_v received 1080 input TLASTs ✓ |
| `v_emit` | 720 | scaler_v fired 720 `v_cross` events (= internal emit triggers) ✓ |
| `v_out_tlast` | **720** | scaler_v's `m_axis_tlast` handshake fired 720 times ✓ |

Scaler emits exactly **720 valid output rows per source frame**, each with a proper TLAST handshake. The leak cannot be on the scaler side.

This counter was the critical piece of evidence. iter4g had `v_emit=720` but lacked `v_out_tlast`, leaving it ambiguous whether the scaler was aborting the last emits silently. iter6's counter rules that out.

### Latent bug discovered along the way: CDC truncation

`hdl/axi_sync_inputs.v` declared `diag_counts_async` as 64-bit input but the internal 2-FF synchronizer regs and `diag_counts_sync` output were **48-bit**. The upper 16 bits were silently truncated by Vivado. This had been harmless until iter6 because the old occupant of `[63:48]` (`axis_to_vid_io_0/mm2s_tlast_snap`) always read 0 anyway. Fixed in the iter6 commit — widened the entire CDC to 64-bit. Worth checking on any branch that uses `axi_sync_inputs`.

## Root cause — S2MM's internal SOF pipeline lag

With `c_use_s2mm_fsync=0` (default for axi_vdma v6.3), S2MM uses AXIS `tuser` as the start-of-frame marker. iter4h's analysis was on the right track:

> "S2MM's end-of-frame state machine (firing at VSIZE-complete) was queuing frame N+1's first 26 rows into slot K's last 26 rows."

Specifically: there's a ~27-row pipeline between where TUSER arrives on AXIS and where S2MM's slot pointer actually updates in its AXI-write address generator. When TUSER lands on AXIS for frame K+1's first beat, S2MM has 27 rows still in flight on the slot K transfer; those 27 beats get committed to DDR3 at slot K's tail addresses before the slot pointer advances.

The 27 rows is **not** a configurable burst size or FIFO depth — it's an architectural property of the IP's slot-transition state machine. No firmware-side or AXIS-side tweak can avoid it while the IP is in TUSER-driven mode.

## The fix

Hardware fsync. Drive `axi_vdma_0/s2mm_fsync` with a clean 1-cycle pulse on the rising edge of source vsync. Combined with `c_flush_on_fsync=1`, S2MM aborts any in-flight transfer on the fsync edge and re-anchors the slot pointer immediately, bypassing the AXIS-side pipeline.

### Concrete file changes

**`tcl/build_phase_b.tcl`:**

```tcl
# Add vsync_cdc_pulse to add_files:
add_files -norecurse [file join $project_root hdl vsync_cdc_pulse.v]

# In the axi_vdma_0 set_property block:
CONFIG.c_flush_on_fsync {1}   ;# was 0

# Replace the explicit c_use_s2mm_fsync=0 override:
set_property -dict [list CONFIG.c_use_s2mm_fsync {1}] [get_bd_cells axi_vdma_0]

# After rst_axi is created (e.g., right before the LED composition block):
create_bd_cell -type module -reference vsync_cdc_pulse s2mm_fsync_pulse_gen
connect_bd_net $pclk_in                                      [get_bd_pins s2mm_fsync_pulse_gen/dst_clk]
connect_bd_net [get_bd_pins rst_axi/peripheral_aresetn]      [get_bd_pins s2mm_fsync_pulse_gen/dst_rstn]
connect_bd_net [get_bd_pins dvi2rgb_0/vid_pVSync]            [get_bd_pins s2mm_fsync_pulse_gen/vsync_async]
connect_bd_net [get_bd_pins s2mm_fsync_pulse_gen/pulse_out]  [get_bd_pins axi_vdma_0/s2mm_fsync]
```

**`hdl/vsync_cdc_pulse.v`:** already existed (was orphan HDL). 2-FF synchronizer + edge detector. Both clocks tied to `pclk_in` (`dvi2rgb_0/PixelClk`) for this use because `vid_pVSync` and `s_axis_s2mm_aclk` are both on `pclk_in`.

**`hdl/scaler_v.v`:** added `out_tlast_count_snap` output and counter logic. Snapshotted at input TUSER. Not strictly required for the fix, but lets future agents verify the scaler is healthy in one DIAG line.

**`hdl/scaler_top.v`:** forwarded `out_tlast_snap` as a new 16-bit output port. Wired into BD's `diag_concat/In1` (replacing the dead `axis_to_vid_io_0/mm2s_tlast_snap` slot).

**`hdl/axi_sync_inputs.v`:** widened `diag_counts_q1/q2/_sync` from 48 to 64 bits (the CDC bug noted above).

**`sw/phase-b/src/main.c`:** renamed the diag field to `v_out_tlast` and updated the DIAG print format.

### Acceptance criteria

After applying the fix, on iter5-1080p-clean substrate with 1080p60 SMPTE bars source through Osee input 1 → 720p60 output:

- ✅ Monitor: clean SMPTE bars, no thin colored strip at the bottom.
- ✅ DDR3 dump of slot 0 rows 690-719: uniform PLUGE-like content (`col90=000000 col270=FFFFFF col460=FFFFFF col640=000000 col820=000000 col1010=000000`). No SMPTE-bars-top fingerprint anywhere in those rows.
- ✅ DDR3 dump of slot 1 row 0: `000000` (BLACK — the scaler's lbuf_fresh first-row cosmetic). Rows 1+: SMPTE-bars-top.
- ✅ `v_out_tlast=720` per source frame (scaler still healthy).
- ⚠️ `S2MM_SR` shows `SOFLate` flag (`0x800`) set every frame. **Benign.** It just means S2MM sees fsync slightly before AXIS TUSER arrives (TUSER follows the scaler's input-pipeline latency, so fsync from raw source vsync rising edge is a few rows earlier). With `c_flush_on_fsync=1`, S2MM handles this cleanly. If aesthetics matter, mask this bit in the firmware DIAG print.

## Side note: the 1-row BLACK at slot top

Every slot's row 0 is `0x000000` after the fix. That's **not the bug** — it's scaler_v's known-cosmetic lbuf_fresh warmup. The first `v_cross` of a new frame fires at input row 1's TLAST, with only 2 of 4 lbufs marked fresh (`lbuf_fresh = 0011`). The shipped MAC-bypass output picks `tap1` which under that v_cross's `tap0_slot=2` rotation reads `lbuf3` (not fresh), gated to zero. So the first output row is always BLACK.

This was documented in `hdl/scaler_v.v` lines 20-22 (the "First-cut simplifications still present" comment) and shows up in the dump as `slot 1 row 0 = 000000`. One row of black at the top of every frame on the monitor; barely perceptible. Not addressed by iter6.

## Reproducing the diagnostic

If you encounter this bug on another branch:

1. **Confirm the symptom is the bottom-rows leak**, not the Phase D vsync coin-flip or output-clock drift:
   - Static source (Osee input 1 = ImagePro SMPTE bars).
   - Cold-boot ≥3 times — pattern is identical across boots → not coin-flip.
   - Watch for ≥10 seconds — no rolling content → not drift.
   - Source-rate UART read shows `src=60.9 Hz` (NTSC source, pre-iter4a-bias-fix branches) or `src=59.94 Hz` (post-fix branches).

2. **Add the `out_tlast_count_snap` counter** to scaler_v if the branch doesn't already have it. See [hdl/scaler_v.v](../hdl/scaler_v.v) post-iter6. The counter, the scaler_top forwarding, and the BD rewiring of `diag_concat/In1` are the minimum changes.

3. **Fix the `axi_sync_inputs.v` 48→64 CDC bug** if the branch has it. Reading `v_out_tlast=0` is the telltale: the counter is incrementing in scaler_v but the value is being silently truncated in the CDC.

4. **Run the firmware dump probe** (`dump_slot_bytes` in [sw/phase-b/src/main.c](../sw/phase-b/src/main.c)). Confirm slot 0 rows 694-719 show SMPTE-main-bars-top fingerprint matching slot 1 rows 0-8. That's the leak signature.

5. **Apply the iter6 BD edits.** Rebuild Vivado. The leak should be gone in one rebuild.

## Reproducibility on other branches

**Yes, the fix replicates cleanly to any branch that has the same VDMA + scaler topology.** The fix is mechanically a 4-file change (1 TCL, 3 HDL, optional 1 firmware) with no dependency on iter5-specific state.

Branches that should benefit, ranked by likely impact:

| Branch | Current state per build manifest | iter6 applicability | Notes |
|---|---|---|---|
| `iter5-1080p-clean` | ✅ iter6 fix verified here 2026-05-22 | (applied) | Production substrate. |
| `mackin-impl-wip` | Forked from iter5 substrate; bench never validated under no-coin-flip rule | **High** — should apply iter6 before any bench work. Bug would propagate through the Mackin blender unchanged. | Same VDMA + scaler topology. |
| `phase-e1-pll-spike` | Forked from earlier iter5 + PLL tracking added. Memory says "claimed Phase E1 SHIPPED 2026-05-19" but tip has moved | **High** — the bench-session-2 doc on this branch identified the same 27-row leak under a different lens (PI-loop phase offset). iter6 fix likely resolves that "product blocker" too. Worth re-reading `tests/phase-e1/phase_e2_psincdec_limit.md` after applying. | Same topology + Si5351/MMCM tracking layer on top. Phase tracking work doesn't conflict with iter6. |
| `iter4g-counter-infra` | Pre-iter5 ancestry, merged to main as PR #3 | **N/A — superseded.** Don't apply; just use iter5 substrate. | iter4g introduced the diagnostic counters iter6 builds on. |
| `iter4h-axis-fifo` | Strictly worse than iter5 (scroll + bottom-bars both present) | **N/A — abandoned.** Don't apply; iter4h's premise (VSIZE=747 over-allocate) is the wrong mechanism. | Listed for completeness. |
| `iter5-bisect-720p`, `iter5-wip`, `iter4f-wip-pattern-diag`, `main` | Pre-iter5 or abandoned WIP | **Probably N/A.** Bug exists but no reason to fix on cold-storage branches. | Use iter5-1080p-clean. |
| `phase-g-iter1` | Phase G ADV7393 hardware bring-up; hardware-blocked on chip replacement | **No video path regression risk** — Phase G isn't about image quality. iter6 can be merged in when phase-g resumes, but no urgency. | Different bring-up axis. |

### Replication procedure (for any target branch)

```bash
git checkout <target-branch>
# Cherry-pick the four files. Adjust line numbers as needed:
git checkout iter5-1080p-clean -- \
  hdl/scaler_v.v \
  hdl/scaler_top.v \
  hdl/axi_sync_inputs.v \
  hdl/vsync_cdc_pulse.v
# Then re-apply the BD TCL edits to the target branch's tcl/build_phase_b.tcl:
#   1. add_files line for vsync_cdc_pulse.v
#   2. CONFIG.c_flush_on_fsync {0} → {1}
#   3. CONFIG.c_use_s2mm_fsync {0} → {1}
#   4. The s2mm_fsync_pulse_gen instantiation + 4 connect_bd_net lines,
#      placed AFTER rst_axi is created and $pclk_in is set.
#   5. Remove (or update) the diag_concat/In1 wiring from
#      axis_to_vid_io_0/mm2s_tlast_snap → scaler_0/out_tlast_snap.
# Rebuild Vivado + Vitis, program, verify dump.
```

The TCL edits don't `git cherry-pick` cleanly because they're inline in a long file — easiest to hand-apply by searching for the iter6 comment markers in the iter5-1080p-clean version and replicating to the target.

### Branches that might NOT have this bug (worth checking before applying)

- **`phase-a-hdmi-passthrough` lineage**: Phase A has no DDR3 buffer, no VDMA — output VSync IS the source VSync. The leak can't exist architecturally. Don't apply iter6 here.
- **Any TPG-only branch**: if there's no real scaler→S2MM AXIS path, the bug doesn't manifest.

When in doubt, run the dump probe first. If `slot K rows ~694-719` show main-bars-top instead of expected end-of-frame content, you have the bug and iter6 applies.
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

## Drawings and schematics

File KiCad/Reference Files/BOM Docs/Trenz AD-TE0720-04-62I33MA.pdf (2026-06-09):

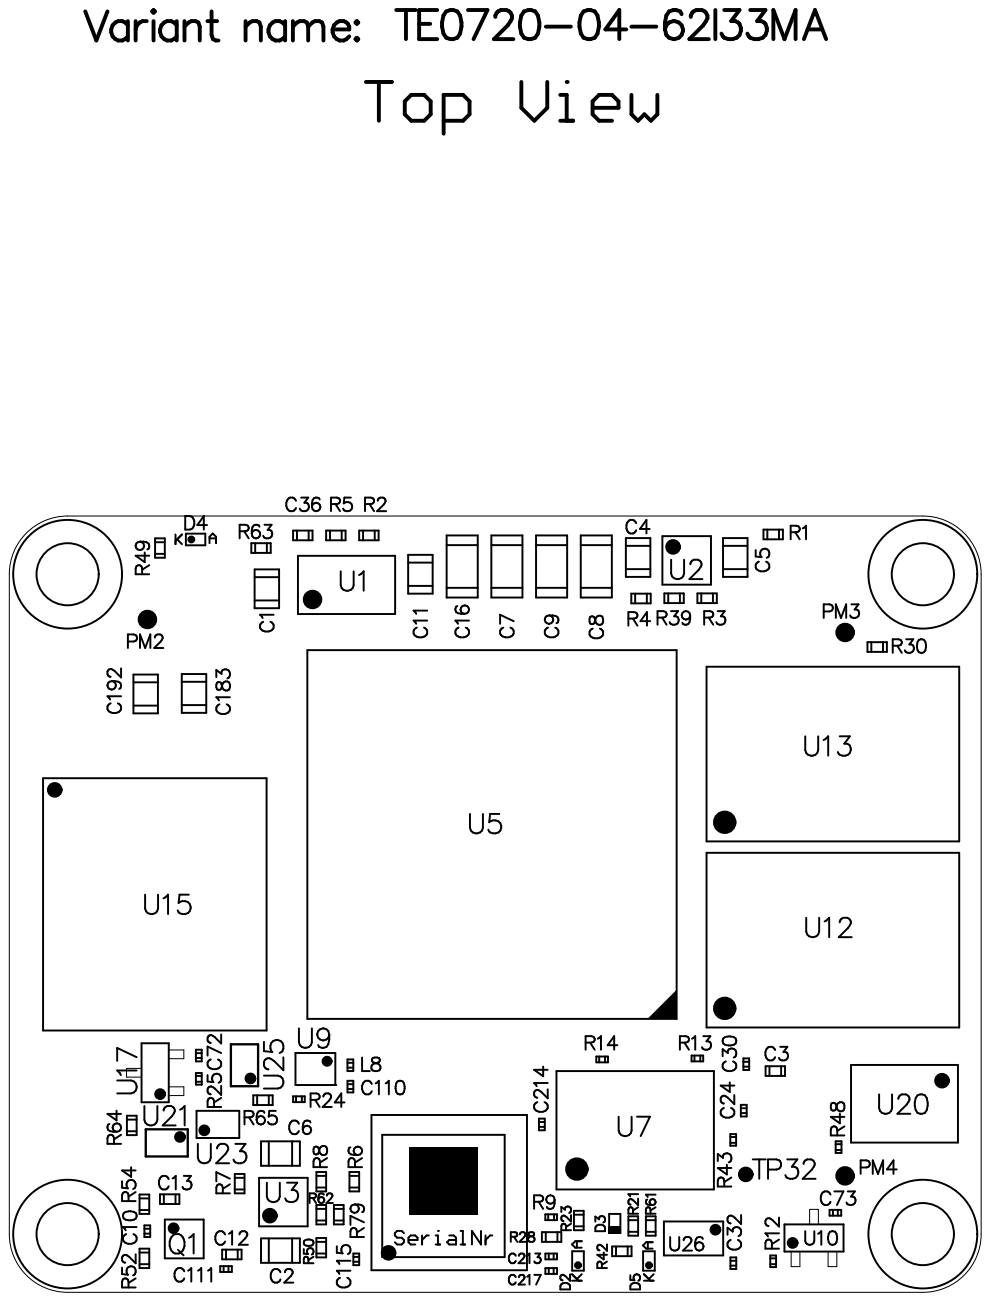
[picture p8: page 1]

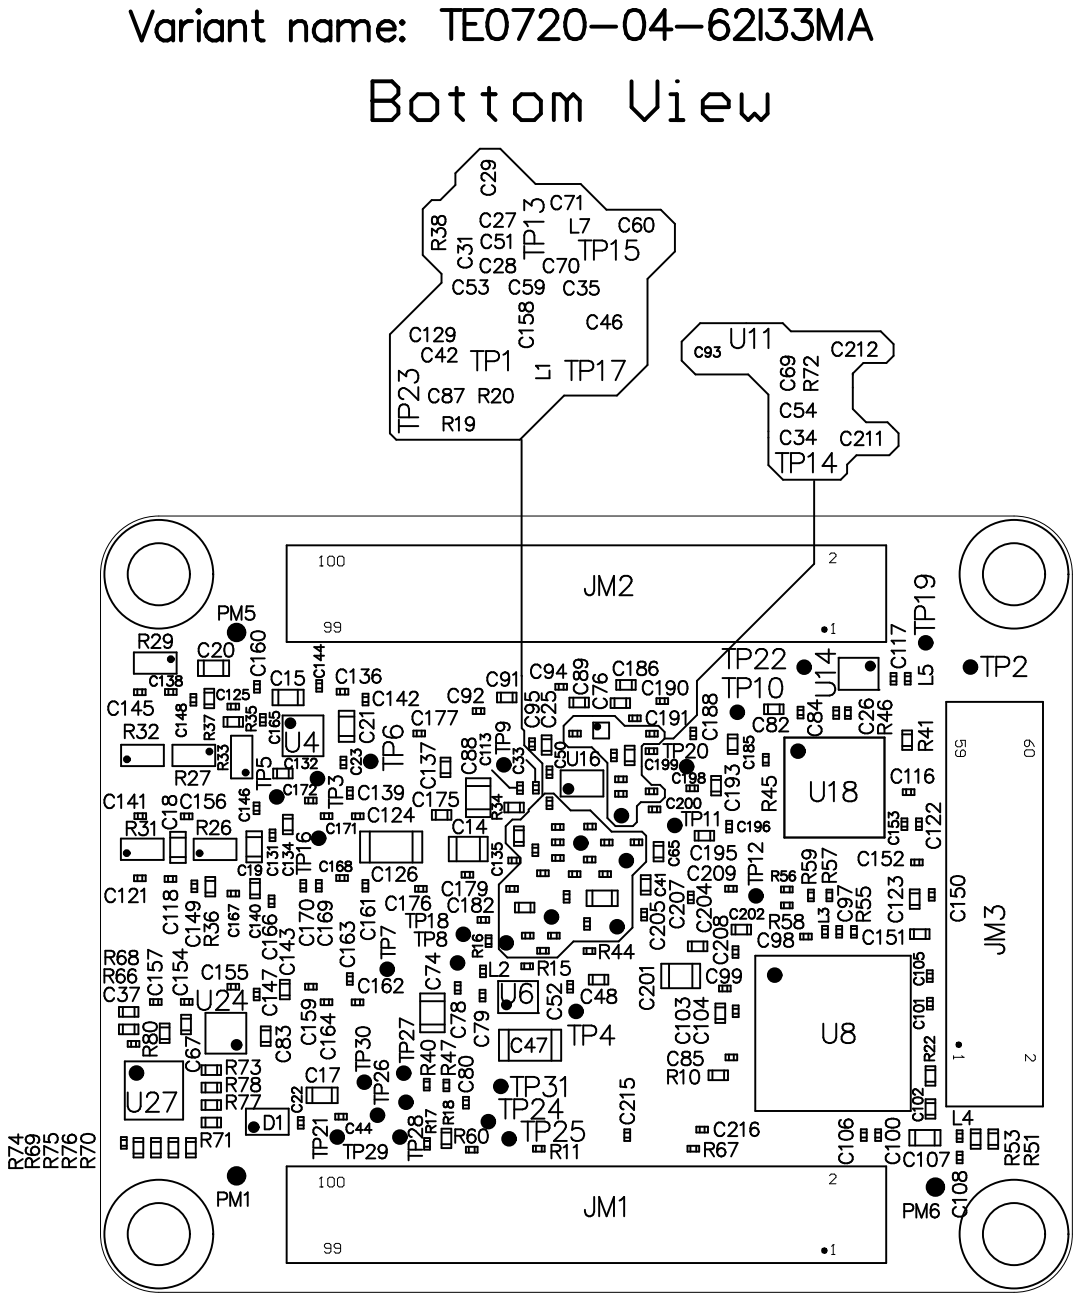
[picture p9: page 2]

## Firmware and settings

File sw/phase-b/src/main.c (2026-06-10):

/*
 * main.c — Phase B.1 bare-metal VDMA + VTC init for Schindler 2.0.
 *
 * Boots on the Zynq-7020 PS, configures the AXI VDMA to write incoming video
 * frames to a 3-frame ring buffer in DDR3 (S2MM channel), reads them back to
 * drive the HDMI TX (MM2S channel), and configures the Video Timing Controller
 * to generate 1920x1080@60p sync downstream of the VDMA.
 *
 * No interrupts. No DMA controller scatter-gather. Once configured, the VDMA
 * runs autonomously in circular-buffer mode; the PS is idle in a WFI loop.
 *
 * Frame format: RGB888 with one pixel-per-clock; VDMA AXIS data width 24-bit;
 * memory data width 64-bit (one pixel per 32-bit word — VDMA pads RGB888 to
 * 32-bit; verify against your axi_vdma config).
 */

#include <stdio.h>
#include <string.h>
#include "xil_printf.h"
/* Generated by tcl/build_phase_b_app.tcl from the live catalog filename;
 * defines CATALOG_VERSION. Fallback below if the header isn't present
 * (e.g. building outside the tcl flow). */
#if __has_include("catalog_version.h")
#  include "catalog_version.h"
#endif
#ifndef CATALOG_VERSION
#  define CATALOG_VERSION "unknown"
#endif

/* Generated by tcl/build_phase_b_app.tcl from KERNEL_GPIO_INDEX env var;
 * defines SCALER_KERNEL_GPIO_BASEADDR. Fallback to the iter5-production
 * GPIO 7 slot if the header isn't present (legacy build paths). */
#if __has_include("kernel_gpio_index.h")
#  include "kernel_gpio_index.h"
#endif
#ifndef SCALER_KERNEL_GPIO_BASEADDR
#  ifdef XPAR_AXI_GPIO_7_BASEADDR
#    define SCALER_KERNEL_GPIO_BASEADDR XPAR_AXI_GPIO_7_BASEADDR
#  endif
#endif
#include "xil_cache.h"
#include "xil_io.h"
#include "sleep.h"
#include "xparameters.h"
#include "xaxivdma.h"
#include "xvtc.h"
#include "xtime_l.h"   /* Phase D iter-4a: SCU timer for precise rate measurement */

// iter5-1080p-clean 720p re-validation (2026-05-17 evening): 1080p60 source
// scaled to 720p60 output (matched rate). Build with SCALER_MODULE=scaler_top
// env var. Tests row 2 of format-support-matrix on the production substrate
// (NUM_FRAMES=5, no iter4h additions).
/* 2026-05-31: FRAME_W/H parametrized by OUTPUT_1080P compile-time define.
 * Mirrors the tcl/build_phase_b.tcl OUTPUT_MODE env var. The Vitis tcl
 * (tcl/build_phase_b_app.tcl) reads OUTPUT_MODE from the environment and
 * passes -DOUTPUT_1080P=1 to gcc when OUTPUT_MODE is 1080p30 or 1080p60.
 *
 *   No env var set (default)          → 720p60 production substrate
 *   OUTPUT_MODE=720p                  → 720p60 production substrate
 *   OUTPUT_MODE=1080p30               → 1080p30 passthrough (in -1 spec)
 *   OUTPUT_MODE=1080p60               → 1080p60 (dev-board blocked; see
 *                                        zynq7020_rgb2dvi_1080p60_limit) */
/* READENGINE_FULLMASTER (route-B): the input scaler is bypassed
 * (SCALER_MODULE=scaler_bypass_1080p) so S2MM captures the FULL 1920×1080
 * source as the DDR master; the read-engine scales it per output. FRAME_W/H
 * (= VDMA/DDR master size) becomes 1920×1080, but the VTC output stays 720p
 * (see vtc_setup below — gated on OUTPUT_1080P, NOT this). Without it, S2MM
 * sized to 720p over a bypassed 1080p stream stores only the top-left crop. */
#if defined(OUTPUT_1080P) || defined(READENGINE_FULLMASTER)
#define FRAME_W           1920
#define FRAME_H           1080
#else
#define FRAME_W           1280
#define FRAME_H           720
#endif
/* Output raster (VTC + read-engine OUT_W/OUT_H) = the VTC mode. For the SCALER build this is 720p even
 * with a 1080p master (it scales down). For the WARP build at OUTPUT_MODE=1080p30/60 the engine emits the
 * FULL 1080p raster, so OUT_RASTER follows OUTPUT_1080P (the VTC), NOT the master. */
#ifdef OUTPUT_1080P
#define OUT_RASTER_W      1920
#define OUT_RASTER_H      1080
#else
#define OUT_RASTER_W      1280
#define OUT_RASTER_H      720
#endif
/* AXIS data width on the VDMA is 24-bit (RGB888, one pixel-per-clock with no
 * padding). Memory stride must therefore be 3 bytes/pixel, NOT 4 — using 4
 * was the actual reason v_axi4s_vid_out couldn't lock and S2MM was reporting
 * EOLEarly/EOLLate framing errors. Confirmed via UART diag dumps. */
#define BYTES_PP          3
#define STRIDE            (FRAME_W * BYTES_PP)
#define FRAME_BYTES       (STRIDE * FRAME_H)
/* iter5-bisect-720p: NUM_FRAMES 5 → 3 to isolate scroll cause. Bisect shows
 * 5 framestores is the only iter5 substrate change vs. clean iter4h; revert
 * to 3 to confirm. BD config c_num_fstores must also match (3 in TCL). */
/* iter5-1080p-clean: NUM_FRAMES 3 → 5 to give S2MM enough cycle headroom
 * to not lap MM2S during its 41.7 ms read window at 24p output. 5 × 16.7
 * = 83 ms cycle time vs. MM2S 41.7 ms read = 2× headroom. Addresses the
 * FRC tear-line-that-drifts symptom. BD c_num_fstores must match. */
#define NUM_FRAMES        7   /* #28: 5->7 (MUST == VDMA c_num_fstores) so cadence lag reaches 2 for Mackin blend. 7*SLOT_STRIDE=43.6MB from FRAME_BUF_BASE. */
#define FRAME_BUF_BASE    0x10000000U

static XAxiVdma vdma;
static XVtc    vtc;

static int vdma_setup_channel(int direction, UINTPTR *frame_addrs)
{
    XAxiVdma_DmaSetup cfg;
    int status;

    /* iter5-bisect FINAL (2026-05-17 evening): both channels VSIZE = FRAME_H.
     * Pure iter4d-3 substrate. Production-clean visually at matched rate
     * with laptop source. Bottom-bars artifact (if it reappears with other
     * sources) will need a non-over-allocate fix. */
    cfg.VertSizeInput     = FRAME_H;
    cfg.HoriSizeInput     = STRIDE;
    cfg.Stride            = STRIDE;
#ifdef ORIENT_TILED
    /* ORIENT_TILED: the S2MM stores the source TILED (16x16 tiles, tile-row-major) from
     * pg_raster_to_tile. Each tile = one VDMA "line": 768 B (256 px * 3), tlast per tile,
     * tuser=SOF per frame. 1920x1080 -> TILES_X=120, full tile-rows = 1080/16 = 67 (the
     * partial half-row is dropped/overwritten) -> 8040 tiles/frame, contiguous (stride 768).
     * The read engine (pg_tile_dma TILED=1) fetches tile (tx,ty) at base+(ty*120+tx)*768. */
    if (direction == XAXIVDMA_WRITE) {
        cfg.HoriSizeInput = 768;     /* one tile = 16*16*3 bytes */
        cfg.VertSizeInput = 8040;    /* 67 tile-rows * 120 tiles  */
        cfg.Stride        = 768;     /* tiles contiguous in DDR    */
    }
#endif
#if defined(READENGINE_FULLMASTER)
    /* DIAGNOSTIC 2026-06-02: in full-master mode S2MM stores the full 1920×1080
     * master, but the output VTC raster is 1280×720. The MM2S (read) leg must
     * therefore read a geometry-correct CROP, else it streams a 1920-wide raster
     * into 1280-wide output timing and the lines wrap ("doubling" seen at
     * engine=0). Give MM2S: HSIZE = 1280*3 valid bytes/line, Stride = 5760 (the
     * master line pitch in DDR, unchanged), VSIZE = 720 lines → a clean top-left
     * 1280×720 crop of the master with NO scaling. S2MM (write) stays full
     * 1920×1080. NOTE: this makes the read geometry differ from the write
     * geometry — watch the dynamic-genlock handshake (see
     * schindler_genlock_geometry_must_match); revert if HDMI loses lock. */
    if (direction == XAXIVDMA_READ) {
        cfg.VertSizeInput = OUT_RASTER_H;            /* 720 lines              */
        cfg.HoriSizeInput = OUT_RASTER_W * BYTES_PP; /* 1280*3 = 3840 valid B  */
        /* cfg.Stride stays STRIDE (5760) = DDR master line pitch */
    }
#endif
    /* Phase D iter-4d-3: MM2S as genlock slave with FrameDelay=1 — slave
     * trails master by 1 frame in the 3-FB ring, hardware-enforced (PG020:
     * "Slave follows the Master by the frames set in Frame Delay register
     * either by skipping or repeating frames"). S2MM stays at 0 since it's
     * the master and free-runs at source rate.
     *
     * Replaces iter-4d-2's firmware PARK loop. That approach (PARK mode +
     * per-vsync PARK_PTR_REG writes from firmware) was non-atomic at MM2S
     * SOF; the writes landed mid-burst and produced 2-3 horizontal seams
     * per frame. Xilinx never intended PARK + firmware for live video — the
     * documented FRC path is Dynamic Genlock master/slave (iter-4d-3 step 2
     * upgrades from plain to Dynamic), and even plain genlock + FrameDelay=1
     * should kill the seams that PARK was hand-rolling badly. */
    /* MM2S follows S2MM by 1 frame in Dynamic Genlock (the standard pairing).
     * Note: per iter4h FrameDelay observation, this register reads-as-zero
     * in our IP config — the value is set per spec but Xilinx's IP locks the
     * bits. We keep the assignment for documentation / matching reference
     * designs. See memory: xilinx-vdma-dmasr-bits + schindler-bottom-bars-artifact. */
    cfg.FrameDelay        = (direction == XAXIVDMA_READ) ? 1 : 0;
    cfg.EnableCircularBuf = 1;
    /* EnableSync=1 on MM2S asserts DMACR bit 3, which enables slave-mode
     * frame-pointer following (required for FrameDelay/genlock to apply).
     * It is NOT the per-frame fsync gate we were treating it as in iter-4d-2. */
    cfg.EnableSync        = (direction == XAXIVDMA_READ) ? 1 : 0;
    cfg.PointNum          = 0;
    cfg.EnableFrameCounter = 0;
    cfg.FixedFrameStoreAddr = 0;

    status = XAxiVdma_DmaConfig(&vdma, direction, &cfg);
    if (status != XST_SUCCESS) {
        xil_printf("VDMA DmaConfig %s failed: %d\r\n",
                   (direction == XAXIVDMA_WRITE) ? "S2MM" : "MM2S", status);
        return status;
    }

    status = XAxiVdma_DmaSetBufferAddr(&vdma, direction, frame_addrs);
    if (status != XST_SUCCESS) {
        xil_printf("VDMA SetBufferAddr %s failed: %d\r\n",
                   (direction == XAXIVDMA_WRITE) ? "S2MM" : "MM2S", status);
        return status;
    }

    status = XAxiVdma_DmaStart(&vdma, direction);
    if (status != XST_SUCCESS) {
        xil_printf("VDMA DmaStart %s failed: %d\r\n",
                   (direction == XAXIVDMA_WRITE) ? "S2MM" : "MM2S", status);
        return status;
    }

    return XST_SUCCESS;
}

/* Phase D iter-3 — firmware-side VTC alignment.
 *
 * The AXI GPIO at XPAR_AXI_GPIO_0_BASEADDR exposes two synchronized inputs:
 *   bit 0 = dvi2rgb pLocked (2-FF synced from pclk_in to FCLK_CLK0)
 *   bit 1 = dvi2rgb vid_pVSync (2-FF synced)
 * Polling these from the PS at ~666 MHz gives us microsecond-tight detection
 * of source events. Calling vtc_setup_720p immediately after this returns
 * aligns the generator's first frame to within ~1 µs of source vsync.
 */
#define VSYNC_GPIO_PLOCKED_MASK      0x1   /* dvi2rgb source HDMI lock        */
#define VSYNC_GPIO_VSYNC_MASK        0x2   /* dvi2rgb source vsync             */
#define VSYNC_GPIO_VSYNC_OUT_MASK    0x4   /* VTC output vsync (iter-4d-1)     */
#define VSYNC_GPIO_PCLK_LOCKED_MASK  0x8   /* clk_wiz_pixclk_out MMCM lock     */

/* Vitis names this macro inconsistently across versions / BD hierarchies.
 * Match whichever one the generated xparameters.h actually emits. */
#if defined(XPAR_AXI_GPIO_0_BASEADDR)
#  define VSYNC_GPIO_BASEADDR XPAR_AXI_GPIO_0_BASEADDR
#elif defined(XPAR_AXI_GPIO_0_S_AXI_BASEADDR)
#  define VSYNC_GPIO_BASEADDR XPAR_AXI_GPIO_0_S_AXI_BASEADDR
#elif defined(XPAR_PHASE_B_BD_AXI_GPIO_0_BASEADDR)
#  define VSYNC_GPIO_BASEADDR XPAR_PHASE_B_BD_AXI_GPIO_0_BASEADDR
#else
#  error "AXI GPIO 0 base address not found in xparameters.h"
#endif

/* iter4e: AXI GPIO 1 — 32-bit output, drives scaler runtime IN_W/IN_H.
 *   bits [15:0]  = IN_W
 *   bits [31:16] = IN_H
 * Written once at startup after VTC detector reports DASIZE. */
#if defined(XPAR_AXI_GPIO_1_BASEADDR)
#  define SCALER_DIMS_GPIO_BASEADDR XPAR_AXI_GPIO_1_BASEADDR
#elif defined(XPAR_AXI_GPIO_1_S_AXI_BASEADDR)
#  define SCALER_DIMS_GPIO_BASEADDR XPAR_AXI_GPIO_1_S_AXI_BASEADDR
#elif defined(XPAR_PHASE_B_BD_AXI_GPIO_1_BASEADDR)
#  define SCALER_DIMS_GPIO_BASEADDR XPAR_PHASE_B_BD_AXI_GPIO_1_BASEADDR
#else
#  error "AXI GPIO 1 (scaler dims) base address not found in xparameters.h"
#endif

/* Color AXI GPIO 3 — dual-channel output, drives the color pipeline.
 *   Channel 1: [31:24]=saturation, [23:16]=black_b, [15:8]=black_g, [7:0]=black_r
 *   Channel 2: [31:24]=spare,      [23:16]=white_b, [15:8]=white_g, [7:0]=white_r
 * Saturation factor: 0 = grayscale, 255 ≈ identity (~0.4% error). */
#if defined(XPAR_AXI_GPIO_3_BASEADDR)
#  define COLOR_GPIO_BASEADDR XPAR_AXI_GPIO_3_BASEADDR
#elif defined(XPAR_AXI_GPIO_3_S_AXI_BASEADDR)
#  define COLOR_GPIO_BASEADDR XPAR_AXI_GPIO_3_S_AXI_BASEADDR
#elif defined(XPAR_PHASE_B_BD_AXI_GPIO_3_BASEADDR)
#  define COLOR_GPIO_BASEADDR XPAR_PHASE_B_BD_AXI_GPIO_3_BASEADDR
#else
#  error "AXI GPIO 3 (color correct) base address not found in xparameters.h"
#endif
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
int main(void)
{
    XAxiVdma_Config *vdma_cfg;
    UINTPTR          s2mm_frame_addrs[NUM_FRAMES];
    UINTPTR          mm2s_frame_addrs[NUM_FRAMES];
    int              i;
    int              status;

    xil_printf("\r\n=== Schindler 2.0 — Phase B.1 ===\r\n");
    xil_printf("VDMA + VTC bare-metal init\r\n");

    /* Compute frame addresses in DDR3 (triple buffer).
     *
     * MM2S read addresses are offset +STRIDE bytes so MM2S starts reading at
     * scaler emit row 1 instead of row 0. Reason: scaler_v's first emit row
     * still leaks 1 line of previous-frame bottom-PLUGE content into output's
     * row 0 (iter3i's lbuf_fresh gating reduces this to ~50% intensity but
     * doesn't fully eliminate). Shifting the MM2S window by +1 line hides
     * emit row 0 in the previous buffer's tail.
     *
     * To stop MM2S's TAIL read (now 1 line past the active-data region) from
     * scribbling into the NEXT buffer (which is either being mid-written by
     * S2MM or holds previous-frame content — producing an intermittent
     * flicker line at output row 719), each buffer slot is sized to
     * FRAME_BYTES + STRIDE: the last STRIDE bytes are a GUARD region that's
     * never written by S2MM, pre-filled with black at init. MM2S's tail
     * lands there and outputs a solid-black row instead of stale data. */
    /* iter3i MM2S +STRIDE shift RESTORED (2026-05-17 evening): bench at 720p
     * with scaler_top shows the row-0 leak still exists (one line of previous-
     * frame bottom visible at top of displayed frame). Earlier bisect (Option B)
     * tested without scaler_top engaged — bypass module doesn't have the
     * leak. With scaler_top, the shift is still needed. Pre-iter4h pattern. */
    const UINTPTR GUARD_BYTES = STRIDE;
    const UINTPTR SLOT_BYTES  = FRAME_BYTES + GUARD_BYTES;
    for (i = 0; i < NUM_FRAMES; i++) {
        s2mm_frame_addrs[i] = FRAME_BUF_BASE + (UINTPTR)(i * SLOT_BYTES);
        mm2s_frame_addrs[i] = s2mm_frame_addrs[i] + STRIDE;
        volatile u8 *guard = (volatile u8 *)(s2mm_frame_addrs[i] + FRAME_BYTES);
        for (UINTPTR g = 0; g < GUARD_BYTES; g++) guard[g] = 0;
    }
    UINTPTR *frame_addrs = s2mm_frame_addrs;  /* legacy alias for the diag loop */
    xil_printf("Frame buffers: 0x%08lx, 0x%08lx, 0x%08lx (each %d bytes)\r\n",
               (unsigned long)frame_addrs[0],
               (unsigned long)frame_addrs[1],
               (unsigned long)frame_addrs[2],
               FRAME_BYTES);

    /* Caches off in the DDR3 frame-buffer region so the VDMA sees fresh writes
     * without needing flush/invalidate dances. Simplest correct behavior for
     * Phase B.1; future phases that touch frames from the PS will revisit. */
    Xil_DCacheDisable();

    /* The video pipeline (VDMA AXIS sides + video adapters + VTC) runs on the
     * RX-recovered PixelClk from dvi2rgb. If we try to init the VDMA before
     * PixelClk is stable, the IP's reset state machine stalls waiting for
     * its AXIS clock domain to acknowledge reset → driver times out.
     *
     * Phase D iter-3: instead of a blind sleep(5), poll the AXI GPIO that
     * exposes dvi2rgb's pLocked and vid_pVSync (2-FF synced into FCLK_CLK0
     * domain). Wait for pLocked to be stable for ≥100 ms, then wait for the
     * NEXT rising edge of source vsync, then immediately run vtc_setup_720p.
     * The CTL register write at the end of vtc_setup_720p is what triggers
     * the generator's first frame; landing it within microseconds of source
     * vsync gives per-boot deterministic alignment. */
    /* iter4e: read source dimensions from v_tc_rx detector FIRST and program
     * scaler runtime IN_W/IN_H via axi_gpio_1 before we engage the vsync
     * alignment path. The detector takes ~50-100 ms to lock + settle, so it
     * MUST run before the source-vsync edge wait (otherwise the alignment
     * window we found would be invalidated by the detector wait).
     *
     * The vtc_detector_read function also requires pLocked; it polls for
     * detector LOCKED which implies pLocked + stable timing. So this
     * subsumes the initial pLocked wait. */
    xil_printf("Waiting for dvi2rgb lock + reading source dimensions...\r\n");
    u32 src_hactive = 1920, src_vactive = 1080;  /* fallback defaults */
    u32 src_htotal = 0, src_vtotal = 0;
    if (vtc_detector_read(&src_hactive, &src_vactive,
                          &src_htotal, &src_vtotal) != XST_SUCCESS) {
        xil_printf("WARN: detector failed, using defaults 1920x1080\r\n");
    }
    /* DIAG: read GPIO initial value to verify C_DOUT_DEFAULT applied at boot. */
    u32 gpio_initial = Xil_In32(SCALER_DIMS_GPIO_BASEADDR + 0x00);
    xil_printf("SCALER GPIO initial value: 0x%08x (expect 0x04380780 = 1920x1080)\r\n",
               (unsigned)gpio_initial);
    scaler_dims_write(src_hactive, src_vactive);
    xil_printf("SCALER: programmed IN_W=%u IN_H=%u\r\n",
               (unsigned)src_hactive, (unsigned)src_vactive);

    /* NOW align VTC generator CTL write to the next source vsync edge.
     * Detector activity above is complete; remaining latency is just the
     * vsync-edge spin in wait_for_aligned_source_vsync. */
    if (wait_for_aligned_source_vsync() != XST_SUCCESS) return -1;

    /* CRITICAL: NO printfs between wait_for_aligned_source_vsync and the CTL
     * register write inside vtc_setup_720p. UART at 115200 baud is ~87 µs/char,
     * and source vsync is only HIGH for ~74 µs per frame. Any inter-line print
     * here would push the CTL write past the vsync window into a random phase.
     *
     * (Empirically the firmware-to-CTL latency does not shift the displayed
     * picture because alignment is driven by VDMA frame-buffer timing rather
     * than VTC vsync_out phase. The top-of-frame artifact iter3e showed is
     * actually scaler_v.v's cosmetic warmup — 3 rows of mixed previous-frame
     * data because the V-filter's tap rotation reads from BRAM lbufs that
     * haven't yet been refreshed with the new frame. A future HDL fix should
     * tackle this WITHOUT the iter3g-style conditional m_axis_tdata mux,
     * which mysteriously corrupted the B channel in synthesis.) */

    /* --- VTC first --- so fsync_out is pulsing when VDMA inits (its reset
     * state machine waits for fsync activity with c_use_mm2s_fsync=1).
     *
     * iter-4d-3-FRC-test: select 720p50 to drive Dynamic Master's down-FRC
     * skip behavior. Source stays 60p (ImagePro RGB), output is 50p, ratio
     * 6:5 means master drops one source frame every 6 to keep ahead of slave.
     * Switch to MODE_720P60 to revert. */
    /* 720p re-validation (2026-05-17): 1080p60 source → 720p60 output on
     * production substrate (NUM_FRAMES=5, post-bisect). Matched rate, no
     * FRC. Expected PHASE deltas all 1 (every source frame consumed).
     *
     * 2026-05-31: OUTPUT_1080P compile-time switch picks MODE_1080P30 for
     * the 1080p30 passthrough test build. Was a missed hardcode that left
     * VTC generating 720p timing on 1080p builds — VDMA HSIZE was correct
     * (per FRAME_W param) but VTC told axis_to_vid_io to gate 1280 cols of
     * active video per row → output rendered ~half-width, repeated. */
#ifdef OUTPUT_1080P
    if (vtc_setup(&MODE_1080P30) != XST_SUCCESS) return -1;
#else
    if (vtc_setup(&MODE_720P60) != XST_SUCCESS) return -1;
#endif
    xil_printf("VTC aligned to source vsync\r\n");
    sleep(1);  /* give VTC time to start pulsing fsync before VDMA reset */

    /* --- VDMA ------------------------------------------------------------- */
    vdma_cfg = XAxiVdma_LookupConfig(XPAR_AXI_VDMA_0_DEVICE_ID);
    if (!vdma_cfg) {
        xil_printf("VDMA LookupConfig failed\r\n");
        return XST_FAILURE;
    }
    status = XAxiVdma_CfgInitialize(&vdma, vdma_cfg, vdma_cfg->BaseAddress);
    if (status != XST_SUCCESS) {
        xil_printf("VDMA CfgInitialize failed: %d\r\n", status);
        return status;
    }

    if (vdma_setup_channel(XAXIVDMA_WRITE, s2mm_frame_addrs) != XST_SUCCESS) return -1;
    if (vdma_setup_channel(XAXIVDMA_READ,  mm2s_frame_addrs) != XST_SUCCESS) return -1;

    xil_printf("VDMA running — S2MM + MM2S enabled, %d-frame ring\r\n", NUM_FRAMES);
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

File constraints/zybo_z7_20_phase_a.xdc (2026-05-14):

# zybo_z7_20_phase_a.xdc — Phase A constraints for Zybo Z7-20 HDMI passthrough.
#
# Sources: Digilent Zybo Z7-20 master XDC + board file part0_pins.xml.
# Only the pins used by top_phase_a.v are constrained.

# ============================================================================
# Onboard 125 MHz oscillator (input to MMCM that generates the 200 MHz refclk)
# ============================================================================
set_property -dict { PACKAGE_PIN K17 IOSTANDARD LVCMOS33 } [get_ports sys_clk]
create_clock -period 8.000 -name sys_clk_125mhz [get_ports sys_clk]

# Allow sys_clk's IBUF → top-level MMCM (mmcm_inst) to use the clock backbone.
# With 3 MMCMs in the design (top-level refclk gen + dvi2rgb internal + rgb2dvi
# internal), the placer can no longer keep sys_clk's IBUF and our MMCM in the
# same clock region — dvi2rgb's MMCM needs to be near the HDMI RX IO bank, and
# rgb2dvi's MMCM eats another region. BACKBONE adds ~hundreds of ps of clock
# insertion delay (negligible here; the MMCM filters jitter regardless) but
# satisfies the clock placer rule. See UG472 / Place 30-575.
set_property CLOCK_DEDICATED_ROUTE BACKBONE [get_nets sys_clk_IBUF]

# ============================================================================
# BTN0 (reset)
# ============================================================================
set_property -dict { PACKAGE_PIN K18 IOSTANDARD LVCMOS33 } [get_ports btn_rst]

# ============================================================================
# HDMI RX port (TMDS IN from external HDMI source)
# ============================================================================
set_property -dict { PACKAGE_PIN U18 IOSTANDARD TMDS_33 } [get_ports TMDS_IN_clk_p]
set_property -dict { PACKAGE_PIN U19 IOSTANDARD TMDS_33 } [get_ports TMDS_IN_clk_n]

set_property -dict { PACKAGE_PIN V20 IOSTANDARD TMDS_33 } [get_ports {TMDS_IN_data_p[0]}]
set_property -dict { PACKAGE_PIN W20 IOSTANDARD TMDS_33 } [get_ports {TMDS_IN_data_n[0]}]
set_property -dict { PACKAGE_PIN T20 IOSTANDARD TMDS_33 } [get_ports {TMDS_IN_data_p[1]}]
set_property -dict { PACKAGE_PIN U20 IOSTANDARD TMDS_33 } [get_ports {TMDS_IN_data_n[1]}]
set_property -dict { PACKAGE_PIN N20 IOSTANDARD TMDS_33 } [get_ports {TMDS_IN_data_p[2]}]
set_property -dict { PACKAGE_PIN P20 IOSTANDARD TMDS_33 } [get_ports {TMDS_IN_data_n[2]}]

set_property -dict { PACKAGE_PIN W19 IOSTANDARD LVCMOS33 } [get_ports hdmi_rx_hpd]
set_property -dict { PACKAGE_PIN W18 IOSTANDARD LVCMOS33 PULLUP TRUE } [get_ports hdmi_in_ddc_scl]
set_property -dict { PACKAGE_PIN Y19 IOSTANDARD LVCMOS33 PULLUP TRUE } [get_ports hdmi_in_ddc_sda]

# ============================================================================
# HDMI TX port (TMDS OUT to external monitor)
#
# Note: pin file lists IOSTANDARD LVCMOS33 for TMDS_OUT — Zybo HDMI TX uses
# OSERDESE2 + OBUFDS at LVCMOS33 differential to synthesize TMDS levels. The
# rgb2dvi IP handles this internally. TMDS_33 standard isn't supported for
# outputs on the Z-7020 IO banks; LVCMOS33 with the IP's serialization is the
# Digilent-blessed pattern.
# ============================================================================
set_property -dict { PACKAGE_PIN H16 IOSTANDARD TMDS_33 } [get_ports TMDS_OUT_clk_p]
set_property -dict { PACKAGE_PIN H17 IOSTANDARD TMDS_33 } [get_ports TMDS_OUT_clk_n]

set_property -dict { PACKAGE_PIN D19 IOSTANDARD TMDS_33 } [get_ports {TMDS_OUT_data_p[0]}]
set_property -dict { PACKAGE_PIN D20 IOSTANDARD TMDS_33 } [get_ports {TMDS_OUT_data_n[0]}]
set_property -dict { PACKAGE_PIN C20 IOSTANDARD TMDS_33 } [get_ports {TMDS_OUT_data_p[1]}]
set_property -dict { PACKAGE_PIN B20 IOSTANDARD TMDS_33 } [get_ports {TMDS_OUT_data_n[1]}]
set_property -dict { PACKAGE_PIN B19 IOSTANDARD TMDS_33 } [get_ports {TMDS_OUT_data_p[2]}]
set_property -dict { PACKAGE_PIN A20 IOSTANDARD TMDS_33 } [get_ports {TMDS_OUT_data_n[2]}]

set_property -dict { PACKAGE_PIN E18 IOSTANDARD LVCMOS33 } [get_ports hdmi_tx_hpd]

# ============================================================================
# Status LEDs (Zybo 4× user LEDs LD0-LD3)
# ============================================================================
set_property -dict { PACKAGE_PIN M14 IOSTANDARD LVCMOS33 } [get_ports {leds[0]}]
set_property -dict { PACKAGE_PIN M15 IOSTANDARD LVCMOS33 } [get_ports {leds[1]}]
set_property -dict { PACKAGE_PIN G14 IOSTANDARD LVCMOS33 } [get_ports {leds[2]}]
set_property -dict { PACKAGE_PIN D18 IOSTANDARD LVCMOS33 } [get_ports {leds[3]}]
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

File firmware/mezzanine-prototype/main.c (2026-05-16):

/*
 * Schindler 2.0 - Mezzanine UI Prototype Firmware
 *
 * Target: RP2040-Zero (Waveshare) - same silicon as production Pro mezzanine.
 * Firmware ports 1:1 to the production board with pin remapping only.
 *
 * Hardware layout (perfboard test rig):
 *   GP0  - 5-way nav: UP
 *   GP1  - 5-way nav: DOWN
 *   GP2  - 5-way nav: LEFT
 *   GP3  - 5-way nav: RIGHT
 *   GP4  - 5-way nav: CENTER (press)
 *   GP5  - Set button
 *   GP6  - BTN_B (perfboard "Reset" button - NOT hardware reset)
 *   GP8  - ENC A quadrature A
 *   GP9  - ENC A quadrature B
 *   GP10 - ENC A push-switch (shaft press)
 *   GP11 - ENC B quadrature A
 *   GP12 - ENC B quadrature B
 *   GP13 - ENC B push-switch (shaft press)
 *   GP16 - WS2812 status LED (on-board RP2040-Zero)
 *   GP26 - I2C1 SDA  -> OLED B
 *   GP27 - I2C1 SCL  -> OLED B
 *   GP28 - I2C0 SDA  -> OLED A
 *   GP29 - I2C0 SCL  -> OLED A
 *
 * All switches active-low with internal pull-ups enabled.
 * Both OLEDs: SSD1306, I2C addr 0x3C, 128x32 (0.91" form factor).
 *
 * Encoder note: EC11E18244AU is 18 PPR / 36 detents = half-step pattern.
 * Each detent click = 2 quadrature edges in 4x counting. The firmware
 * tracks raw 4x edges (count_raw) and displays detents = raw/2 so
 * "1 click" = "+/-1 detent" in the user's view.
 */

#include <stdio.h>
#include <string.h>
#include <stdlib.h>

#include "pico/stdlib.h"
#include "hardware/i2c.h"
#include "hardware/gpio.h"
#include "hardware/timer.h"
#include "hardware/pio.h"
#include "hardware/clocks.h"

#include "ws2812.pio.h"
#include "ssd1306.h"

/* ----- Pin definitions ----- */
#define NAV_UP          0
#define NAV_DOWN        1
#define NAV_LEFT        2
#define NAV_RIGHT       3
#define NAV_CENTER      4
#define BTN_SET         5
#define BTN_B           6

#define ENC_A_PINA      8
#define ENC_A_PINB      9
#define ENC_A_SW       10
#define ENC_B_PINA     11
#define ENC_B_PINB     12
#define ENC_B_SW       13

#define WS2812_PIN     16

#define I2C0_SDA       28
#define I2C0_SCL       29
#define I2C1_SDA       26
#define I2C1_SCL       27

/* ----- Constants ----- */
#define OLED_ADDR        0x3C
#define I2C_BAUD         400000
#define DEBOUNCE_US      5000      /* 5 ms */
#define POLL_PERIOD_US   500       /* 2 kHz - plenty of headroom for EC11 mechanical rates */
#define RENDER_PERIOD_MS 33        /* ~30 fps */
#define RPM_DECAY_AFTER_US 200000  /* RPM fades to 0 if no edge in 200 ms */
#define TELEM_MIN_US     50000     /* USB-CDC encoder log rate-limited to 20 Hz */

/* Button table */
#define N_BTN 9
enum {
    B_NAV_UP, B_NAV_DOWN, B_NAV_LEFT, B_NAV_RIGHT, B_NAV_CENTER,
    B_SET, B_BTN_B,
    B_ENC_A_SW, B_ENC_B_SW
};
static const uint8_t BTN_PIN[N_BTN] = {
    NAV_UP, NAV_DOWN, NAV_LEFT, NAV_RIGHT, NAV_CENTER,
    BTN_SET, BTN_B,
    ENC_A_SW, ENC_B_SW
};
static const char *BTN_NAME[N_BTN] = {
    "UP", "DN", "LF", "RT", "CTR", "SET", "BTN_B", "ENC_A", "ENC_B"
};

/*
 * Quadrature transition lookup table.
 *
 * Encoding: state = (A << 1) | B  (range 0..3)
 * Index    = (prev_state << 2) | curr_state  (range 0..15)
 * Value    = -1, 0, or +1 (detent direction)
 *
 * Forward rotation sequence (A leads B): 0 -> 2 -> 3 -> 1 -> 0
 * Reverse rotation sequence:             0 -> 1 -> 3 -> 2 -> 0
 *
 * If physical rotation feels backwards, swap ENC_x_PINA <-> ENC_x_PINB
 * in the #defines above.
 */
static const int8_t QUAD_LUT[16] = {
     0, -1, +1,  0,   /* prev=00 */
    +1,  0,  0, -1,   /* prev=01 */
    -1,  0,  0, +1,   /* prev=10 */
     0, +1, -1,  0    /* prev=11 */
};

/* ----- Global state (volatile = updated in timer ISR) ----- */
typedef struct {
    volatile int32_t  count_raw;     /* 4x quadrature count (2 per detent) */
    volatile uint8_t  prev_ab;       /* last seen 2-bit quadrature state */
    volatile uint32_t last_event_us; /* timestamp of last valid edge */
    volatile float    rpm;           /* EMA-filtered rotation rate */
    volatile uint32_t missed;        /* invalid transitions (skipped state) */
} encoder_t;

static encoder_t enc_a = { .prev_ab = 0 };
static encoder_t enc_b = { .prev_ab = 0 };

typedef struct {
    volatile bool     state;         /* debounced state (true = pressed) */
    volatile bool     last_raw;      /* last raw GPIO reading */
    volatile uint32_t last_change_us;
    volatile uint32_t press_count;
} button_t;

static button_t btn[N_BTN];

static volatile int      last_btn_event    = -1;
static volatile uint32_t last_btn_event_ms = 0;
static volatile bool     any_held          = false;

/* WS2812 PIO handles */
static PIO  ws_pio = pio0;
static uint ws_sm  = 0;

/* ----- Encoder update (called from timer ISR) ----- */
static inline void encoder_update(encoder_t *e, uint pin_a, uint pin_b, uint32_t now_us)
{
    uint8_t curr = (uint8_t)((gpio_get(pin_a) << 1) | gpio_get(pin_b));
    if (curr == e->prev_ab) return;

    uint8_t idx   = (uint8_t)((e->prev_ab << 2) | curr);
    int8_t  delta = QUAD_LUT[idx];

    if (delta == 0) {
        /* Skipped state (00<->11 or 01<->10) - missed an edge */
        e->missed++;
    } else {
        e->count_raw += delta;
        uint32_t dt = now_us - e->last_event_us;
        if (dt > 100 && dt < 1000000) {
            /* 72 edges per revolution at 4x quadrature counting (18 PPR * 4) */
            float inst_rpm = 60.0f * 1.0e6f / (72.0f * (float)dt);
            e->rpm = 0.7f * e->rpm + 0.3f * inst_rpm;
        }
        e->last_event_us = now_us;
    }
    e->prev_ab = curr;
}
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

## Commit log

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2026-05-10 Phase 1 v1: top.v + MMCM + Zybo Z7-20 first-light bitstream
    top.v wires onboard 125 MHz → MMCM (54 MHz exact) → vid_timing →
    sample_gen → 8 MSBs of DAC out to Pmod JC. SW0/SW1 select pattern,
    BTN0 resets, LD0 mirrors MMCM lock.
    XDC maps the Zybo Z7-20 pinout (sys_clk K17, BTN0 K18, SW0/1 G15/P15,
    LD0 M14, JC1..JC10 V15/W15/T11/T10/W14/Y14/T12/U12).
    tcl/build.tcl creates the Vivado project from sources, runs synth +
    impl + bitstream, exits non-zero on failure. tcl/program.tcl flashes
    top.bit via JTAG.
    Verified on hardware 2026-05-09: bitstream programs, MMCM locks
    (LD0 lit), reset path works (BTN0). DAC pins toggling on JC awaiting
    the R-2R DAC perfboard.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
    [zybo_z7_20.xdc]
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2026-05-11 Spec restructure + V1 architecture decisions banked
    Major round of architectural confirmations from 2026-05-11 session:
    - Spec doc reorganized: revision history split out of docs/01-spec.md
    into new docs/01-spec-changelog.md so spec holds current state only.
    - Pi CM4 dropped from V1 → Zynq PS hosts the full control plane under
    PetaLinux (web UI, EDID, config, color pipeline, OTA).
    - RP2040 confirmed for genlock slow-control; LTC6912 confirmed as PGA
    (MIKROE-2555 click board inbound for bench eval).
    - SDI broadcast tier flipped from firmware-unlock to factory-populated
    hardware option, with daughter-card-on-headers as a field-upgrade
    delivery vector (new section in spec covers co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
    [Parts List.xlsx]
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2026-05-14 Phase B + C: VDMA frame buffer + polyphase scaler
    Phase B — 1080p HDMI through DDR3 frame buffer. Brings up axi_vdma +
    v_vid_in_axi4s + v_tc + axis_to_vid_io on the Zybo Z7-20. Mac desktop
    running through DDR3 at 1080p60.
    Phase C.1 — custom 8-tap H / 4-tap V polyphase scaler at 1080p→720p,
    Lanczos-2. Pivoted from 480p due to rgb2dvi kClkRange floor. Build #5
    produced clean bitstream but bench-broken; xsim caught scaler_v's
    2-cycle/pixel pipeline colliding with back-to-back v_cross. Build #6
    rewrites scaler_v to 1-cycle throughput → bench-passing. Residual
    cross-clock-domain tearing is Phase D scope.
    Phase C.2 — scaler_top + h/v are generic-driven (IN/OUT/PHASES/TAPS);
    hardcoded p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
    [Parts List.xlsx]
2026-05-14 Phase D iter 2: source-event logging (no auto-recovery)
    Firmware tracks VDMA S2MM PARK_PTR each tick and logs source-quiet /
    source-restored transitions to UART. Useful for diagnosing pipeline
    state at the bench.
    Auto-recovery was tried and removed. Two approaches both failed:
    1. Poll VTC CTL register to detect "VTC reset" and re-init.
    Abandoned because direct VTC register polling appeared to hang
    the PS (later proved to be a file-read race on uart.log, not an
    actual hang — but the approach was misguided anyway).
    2. Every quiet tick, re-call vtc_setup_720p() + XAxiVdma_DmaStop /
    DmaStart on S2MM. Bench-tested: S2MM stays wedged across a source
    disconnect/replug, the stand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
    [main.c]
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2026-05-16 Phase D iter 3: deterministic vsync alignment + edge-noise reduction + scaler_v warmup fix
    12/12 boots Q-y=944 (spread=0px); edge overshoots 0.4-3.0% (vs Lanczos baseline 2.5-4.6%).
    HDL:
    - hdl/axi_sync_inputs.v (new): 2-FF CDC of dvi2rgb pVSync/pLocked into FCLK_CLK0
    - hdl/scaler_h.v, scaler_v.v: round-to-nearest MAC (`sum + 1024 >>> 11`)
    - hdl/scaler_v.v: lbuf_fresh[3:0] tracking gates stage-0 tap latches, eliminating
    the previous-frame-leak warmup band at top of each output frame
    - hdl/scaler_coeffs_{h,v}.hex: regenerated with Mitchell-Netravali kernel
    (max negative-lobe -0.036 vs Lanczos-2 -0.063 — half the overshoot magnitude)
    BD (tcl/build_phase_b.tcl):
    - axi_gpio_0 added (2 inp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
    [main.c]
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2026-05-16 Phase D iter 3n-3q + iter 4a: ILA-localized edge artifact → scaler MAC bypass → source rate detection
    iter-3n: System ILA on scaler_top/m_axis and axi_vdma_0/M_AXIS_MM2S to localize
    per-frame edge speckles user reported. Native ILA + manual signal-peel-off
    fails on AXIS interface bundles; System ILA monitoring the interface bundle
    works cleanly. 5 ILA captures triggered on TUSER showed scaler MAC G channel
    varying 0..226 across captures on same trigger position at the magenta-bar
    edge — confirmed per-frame variation IS in the scaler output.
    iter-3o: bypass MACs with nearest-neighbor (out_r = window[3][23:16]). Edge
    speckles GONE on bench. Confirmed Mitchell's -0.036 sidelo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
    [main.c]
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2026-05-16 Phase D iter 4d-2 (WIP): cadence engine + VDMA park/genlock-slave
    Cadence FSM correct: classifies source rate into REGIME, drives MM2S
    PARK per pattern. 60p uses [1] (1:1), 30p uses [2] (2:1 repeat), 24p
    uses [3,2] (3:2 pulldown). Switched MM2S to park mode and genlock-slave
    (EnableSync=1) so fsync from VTC drives frame switches.
    Bench progress vs visual artifact:
    iter4d-2-v0 (circular): catastrophic ~1/3-frame wrap, rolling
    iter4d-2-v1 (park, no sync): 3 thick horizontal seams
    iter4d-2-v2 (park + genlock): 2 faint subpixel seams
    Residual seams indicate PARK-write vs VDMA's internal fsync-latch
    timing race that needs deeper PG020 analysis. The cadence FSM itself
    is correct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
    [main.c]
2026-05-16 Phase D iter 4d-3: Dynamic Genlock — drop firmware PARK loop
    Replaces iter 4d-2's per-vsync firmware PARK_PTR_REG writes with the
    documented Xilinx FRC pattern: VDMA Dynamic Master / Dynamic Slave.
    PG020 never specifies that PARK writes latch atomically at MM2S SOF;
    the iter 4d-2 approach produced 2-3 horizontal seams per frame because
    writes landed mid-burst. Dynamic Master ("skips the frame buffers that
    Dynamic Slave is working on") provides hardware-enforced collision
    avoidance, and repeat_en=1 absorbs the 0.2% rate delta between
    free-running output (iter 4c) and source by holding a frame instead of
    rolling.
    Changes:
    - tcl/build_phase_b.tcl: c_s2mm_genlock_mode 0->2, c_mm2s_genlock_mo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
    [main.c]
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2026-05-16 Phase D iter 4d-3 FRC validation: 720p60->720p50 via Dynamic Master
    Parameterizes vtc_setup() with a vtc_mode_t struct (MODE_720P60 +
    MODE_720P50). Selects 720p50 by default for FRC validation: source
    stays 60p (ImagePro RGB), output drops to 50p via the new HTOTAL=1980
    timing at the same 74.25 MHz pixel clock. No clk_wiz or rgb2dvi
    changes needed.
    Bench: 4 captures over 6 sec are byte-identical (md5 576583c9...).
    Real SMPTE signal (reverse strip + PLUGE + Q-square present), no
    seams, no roll. Dynamic Master skip-when-collision behavior handles
    the 6:5 cadence in hardware with zero firmware involvement —
    production-shape confirmation that iter 4d-3's substrate is FRC-ready,
    not just passt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
    [main.c]
2026-05-16 Phase D iter 4e: robust scaler — runtime IN_W/IN_H from VTC detector
    Resolves the hardcoded IN_W=1920/IN_H=1080 assumption in the polyphase
    scaler. Now any source dimension within [320..4096, 200..2160] is
    auto-detected at boot via a v_tc detector watching dvi2rgb's sync, and
    the scaler is programmed via AXI GPIO. Matches the firmware-mediated
    detection pattern used by Xilinx VPSS (PG231) and pro-video gear
    (AJA/Blackmagic/Imagine).
    - scaler_h.v: IN_W is now a runtime input (in_w_runtime), latched at
    input TUSER into in_w_active for frame-atomic commit. Replaces hardcoded
    parameter with IN_W_DEFAULT/IN_W_MAX. PHASE_MUL_Q10 unchanged (depends
    only on fixed OUT_W).
    - scaler_v.v: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
    [main.c]
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2026-05-17 Phase D iter 4g (WIP): per-stage counter infrastructure + pipeline doc
    Systematic decomposition of the HDMI pipeline for bug localization.
    Adds frame-boundary-latched counters at every interesting handoff,
    exposed via a new AXI GPIO (input-only, dual-channel, 64 bits total)
    with 2-FF CDC into the AXI clock domain. Firmware prints all counters
    per status interval to UART.
    Counters:
    - scaler_h s_axis_tlast count per source frame (= v_vid_in_axi4s out)
    - scaler_v s_axis_tlast count per source frame (= scaler_h out)
    - scaler_v emit (v_cross) count per source frame (= scaler m_axis out)
    - axis_to_vid_io s_axis_tlast count per OUTPUT frame (= MM2S delivered)
    First read confirmed h_in=1080, v_in=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
    [main.c]
2026-05-17 iter4g diagnostic session: hard counter data + VDMA reg dump + findings doc
    Added per-stage counter infrastructure (already in earlier commit) plus
    VDMA register dump in firmware boot + per-status-interval error decode.
    Confirmed hard data:
    - Scaler emits 720 v_cross events per source frame (correct)
    - VTC RX detector reports source HACTIVE=1920 VACTIVE=1080 (standard 1080p)
    - VDMA VSIZE/HSIZE both correctly configured at 720/3840
    - EOLLateErr fires every frame on BOTH S2MM and MM2S (persists after W1C)
    - Same artifact at 720p50 (FRC) and 720p60 (matching) — not FRC-related
    - Removing +STRIDE MM2S offset doesn't change artifact pattern
    Open: scaler counter says 720 emits per frame but sl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
    [main.c]
2026-05-17 Phase D iter4h: S2MM VSIZE=747 over-allocate fixes bottom-bars artifact
    Firmware-only resolution to the bottom-bars leak that had survived iter4d
    through iter4g. S2MM's end-of-frame state machine (firing at VSIZE-complete)
    was queuing frame N+1's first 26 rows into slot K's last 26 rows. Setting
    S2MM VertSizeInput to FRAME_H+27 (747) keeps S2MM mid-frame until TUSER
    arrives, so that pathological state never fires. MM2S still reads 720 rows
    per slot; the spillover lands in rows 720-746 (outside MM2S range) and DDR3
    byte-readback confirms it stays zero — the leak is gone, not hidden.
    S2MM fsync wiring was tested in parallel (Fix B) and rejected — it shifted
    the leak by exactly 1 row, neve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
    [main.c]
2026-05-17 iter5 step 1: 1080p substrate + 60→24 FRC + FrameStores 3→5
    Pivots the iter4h substrate from 720p to 1080p frames, bypasses the
    polyphase scaler (true identity passthrough), and outputs 1080p24 to
    exercise Dynamic Genlock drop/repeat at the 5:2 cadence ratio. Output
    reuses the existing 74.25 MHz clk_wiz output (1080p24 reduced-blanking
    pixel clock is the same as 720p60). No clk_wiz reconfig.
    - hdl/scaler_bypass_1080p.v (new): 1-cycle identity AXIS passthrough
    matching scaler_top's port signature. Drop-in BD replacement.
    - c_num_fstores 3 → 5. Drift headroom per xilinx-vdma-drift-limits
    memory: 3 framestores + FrameDelay=1 is brittle under sustaine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
    [main.c]
2026-05-17 iter5 step1 debug: AXIS px/line counters + 1080p30 bisect mode
    scaler_bypass_1080p: repurpose diag_counts to expose AXIS source line/
    frame stats — px-per-line (16b), lines-per-frame (16b), max-px-per-line
    (16b). Reset on TUSER. Confirms source AXIS delivers exactly 1920×1080
    per frame in steady state, so EOLEarly on S2MM is NOT a source-side
    TLAST timing issue. Scroll cause remains under investigation.
    main.c: relabel DIAG print fields (h_in→px, v_in→lines, v_emit→maxpx)
    to match the new counter semantics. Added MODE_1080P30 (CEA-861 mode
    34, 2200×1125@30, 74.25 MHz — same clk_wiz output as 1080p24/720p60,
    no BD reconfig needed). vtc_setup currently calls MODE_1080P30 for a
    cle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
    [main.c]
2026-05-17 iter5 firmware: add 2s timeout to v_tc_rx LOCKED-stable check
    The lock_stable_ms loop in vtc_detector_read() had no timeout — if the
    source's vsync was flickering at all (e.g., laptop HDMI vs. a clean
    ImagePro feed), the firmware would spin forever waiting for 50ms of
    continuous LOCKED. Exposed at the bench when the source was switched
    from ImagePro to laptop.
    Fix: cap stability wait at 2 seconds, print WARN and proceed with
    whatever DASIZE has. Caller already falls back to 1920×1080 defaults
    if values look wrong.
    [main.c]
2026-05-18 iter5 scroll bisect: revert iter4h additions + drop iter3i +STRIDE shift
    After today's bench session, the source of the smooth-vertical-scroll bug
    (observed since iter5) is fully isolated and the iter4h-era "fixes" turn
    out to be the cause, not the solution. This commit ships the clean
    production substrate.
    Bench bisect log (2026-05-17, laptop HDMI 1080p60 source → 720p60 out,
    matched-rate, no FRC):
    1. iter5 baseline (1080p + scaler_bypass_1080p + 5 framestores + iter4h
    substrate) = scrolling at ~1.5 fps full roll.
    2. Revert 1080p → 720p, scaler_bypass → scaler_top, NUM_FRAMES 5 → 3 (one
    at a time) = still scrolling at same rate.
    3. Revert iter4h additions (AXIS FIFO + c_flus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
    [main.c]
2026-05-18 iter5 1080p clean: 1080p60→1080p24 5:2 FRC validated on post-bisect substrate
    Firmware-only change on top of the post-bisect substrate (commit 81e17a8):
    - FRAME_W 1280 → 1920, FRAME_H 720 → 1080
    - vtc_setup() switched from MODE_720P60 to MODE_1080P24
    - NUM_FRAMES stays 3; slot allocation now FRAME_BYTES + STRIDE guard at
    1080p = ~6.23 MB per slot, 3-slot ring = ~18.7 MB DDR3 footprint
    Bitstream uses SCALER_MODULE=scaler_bypass_1080p (TCL default). Source
    1080p60 passes through unchanged to S2MM. MM2S reads 1080 rows per output
    vsync at 24p. Dynamic Genlock skip/repeat handles the 5:2 cadence.
    Bench validation (2026-05-17 evening, laptop HDMI 1080p60 source):
    - DIAG steady state: px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
    [main.c]
2026-05-18 iter5 1080p clean + NUM_FRAMES=5 — drift-tear fixed
    5 framestores fix the FRC drift-tear under Dynamic Genlock with FrameDelay
    locked at 0. At NUM_FRAMES=3 with 60→24 (5:2) cadence: S2MM cycles 3 slots
    in 50 ms, barely longer than MM2S's 41.7 ms slot-read time, so S2MM
    periodically laps MM2S mid-read. Tear position drifts with source/sink
    pclk relative drift (6-7 sec beat period at ~5 ppm clock offset).
    With NUM_FRAMES=5: S2MM cycles 5 slots in 83.3 ms = 2× headroom over
    MM2S's 41.7 ms read window. S2MM never laps MM2S within a read cycle.
    No tear.
    This was the scenario iter4h tried to address with over-allocate (which
    introduced its own scroll bug) and AXIS FIFO (defensive but not lo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
    [main.c]
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2026-05-18 iter5: validate 1080p25 ugly 12:5 FRC + add MODE_1080P25 vtc_mode_t
    MODE_1080P25 (CEA-861 mode 33): 1920×1080@25, 2640×1125 HTOTAL/VTOTAL,
    74.25 MHz pixel clock (same as 1080p24/p30/720p60, no clk_wiz reconfig).
    Bench validation (2026-05-17 evening, laptop HDMI 1080p60 → 1080p25 12:5):
    - PHASE telemetry confirms 12:5 cadence: deltas averaging 2.4 per output
    frame; each 5-output super-cycle contains pattern `2,3,2,2,3` (or
    rotation) summing to 12 source frames per 5 outputs.
    - Pipeline clean on UART: S2MM_SR=0x11000, MM2S_SR=0x11000, no error bits.
    - Visual: remote capture can't resolve cadence judder (capture stick is
    itself 30/60p, aliases) but nothing alarming.
    This is the kind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
    [main.c]
2026-05-18 iter5: restore iter3i MM2S +STRIDE shift — row-0 leak real with scaler_top
    Bench at 720p60 with scaler_top showed a 1-row "bottom-of-frame at top"
    artifact, characteristic of the iter3i scaler row-0 leak — scaler_v's
    first emit row has stale lbuf content (previous-frame bottom) for the
    first frame. The earlier bisect erroneously concluded the +STRIDE shift
    was unnecessary because it was tested with scaler_bypass_1080p (no real
    scaler engaged, no leak).
    With real scaler_top in the pipeline, the shift is still required.
    Restored: mm2s_frame_addrs[i] = s2mm_frame_addrs[i] + STRIDE.
    Side effect on bypass cases (1080p modes): cosmetic 1-row vertical shift
    upward + 1 black row at bottom. Bar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
    [main.c]
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2026-05-18 color_saturation: Rec.601 luma-mix saturation control — SHIPPED
    New HDL module color_saturation inserted before color_correct in the
    output pipeline. Single 8-bit saturation knob:
    s = 0 → grayscale (out = luma)
    s = 128 → 50% saturation
    s = 255 → identity (~0.4% error from 255/256 vs 1.0)
    Math per channel: out_c = luma + s · (in_c - luma)
    where luma uses Rec.601 integer weights (76, 150, 30, summing to 256
    for exact white reproduction). 2-stage pipeline keeps timing comfortable
    at the output pclk.
    - color_saturation_0 cell created, inserted between MM2S and color_correct
    (sat runs BEFORE color_correct, so tint adjustments are applied t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
    [main.c]
2026-05-18 color_saturation: widen sat to 16-bit Q1.15 — 0..200% range
    Upgraded color_saturation from 8-bit Q0.8 (capped at ~1.0) to 16-bit
    Q1.15. Now supports 0..200% saturation:
    0x0000 = grayscale
    0x4000 = 50%
    0x8000 = identity (1.0)
    0xC000 = 150%
    0xFFFF ≈ 200%
    HDL (hdl/color_saturation.v):
    - sat_async widened from [7:0] to [15:0]; reset value 0x8000.
    - 2-FF synchronizer regs sat_q1/sat_q2 widened to 16-bit.
    - Multiplier: 17-bit unsigned ({1'b0, sat_q2}) × 10-bit signed diff_c
    → 27-bit signed product. Shift right by 15 (was 8) to convert Q1.15
    back to integer. Result is 12-bit signed.
    - Sum (luma + scaled_c) widened to 13-bit signed; clamp logic uses
    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
    [main.c]
2026-05-18 color_matrix: 3x3 RGB matrix + UART command parser — SHIPPED
    color_matrix.v: general 3x3 RGB transform with signed Q2.14 coefs
    + signed 8-bit offsets per channel. 3-stage AXIS pipeline (mul/sum/
    shift+offset+clamp). 2-FF ASYNC_REG synchronizers on all 12 buses.
    Identity at reset; firmware writes Rec.601 luma matrix for grayscale,
    identity for color, etc. R-B-G byte order honored.
    BD: color_matrix_0 inserted DOWNSTREAM of color_correct_0 (pipeline
    becomes MM2S -> color_saturation -> color_correct -> color_matrix
    -> axis_to_vid_io). axi_gpio_4/5/6 added with xlslice cells routing
    m00..m22 (16-bit) and off_r/g/b (8-bit) to color_matrix_0 inputs.
    Firmware: color_matrix_set(9 coefs + 3 offset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
    [main.c]
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2026-05-22 iter6: S2MM fsync from source vsync — bottom-bars 27-row leak RESOLVED
    Root cause: axi_vdma v6.3's AXIS-TUSER-driven S2MM slot transition has
    ~27 rows of internal pipeline lag between TUSER on AXIS and the actual
    slot-pointer transition in DDR3. First 27 rows of frame K+1 get written
    into slot K's tail before S2MM advances. Bug had been open since iter4g
    (2026-05-16) and previously masked by iter4h's VSIZE=747 over-allocate
    (which fixed visibility but introduced 1-row-per-frame scroll).
    Fix: external hardware fsync. c_use_s2mm_fsync=1, c_flush_on_fsync=1,
    new s2mm_fsync_pulse_gen cell emits a 1-cycle pclk_in pulse on rising
    edge of dvi2rgb_0/vid_pVSync (via existing hdl/vsync_cdc_pulse.v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
    [main.c]
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2026-05-24 iter12+iter13: scaler kernel rework — H-shift + V missing-lines RESOLVED
    The 2-3 pixel per-line H-shift left over from iter6 and the "every other
    horizontal grid line missing" V-bug were the same class of defect: both
    scalers were doing NN single-tap bypass with carryover from the previous
    row/column-set, rather than the polyphase MAC the modules were designed
    for. DDR3 boundary-col dumps localized the H-shift to scaler_h.v's MAC
    window (not S2MM/MM2S as originally hypothesized in iter6-h-shift-analysis.md).
    Patch chain (iter7→iter13, this session):
    - iter7: clear scaler_h window[0..7] on TLAST — prevents row-tail bleed.
    - iter12 (final H): 2-tap boxcar `(s_axis_tdata + window[0])/2`.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
    [main.c]
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2026-05-31 post-iter13b cleanup: SOFLate DIAG noise + scaler_h window-clear scope
    Two pure-cleanup items from the 2026-05-30 audit panel that hadn't been
    addressed yet. Neither changes pipeline behavior.
    1. SOFLate suppression on S2MM_SR DIAG print (KNOWN-BUGS [fw-1]):
    Per docs/iter6-s2mm-fsync-fix.md "Open items §3", S2MM SOFLate is set
    every frame post-iter6 because hardware fsync arrives slightly ahead
    of AXIS TUSER. Picture is clean; the flag is cosmetic. Suppress it
    from the DIAG print (raw s2mm_sr hex is still visible). MM2S SOFLate
    is NOT suppressed since that side has no fsync re-timing.
    2. scaler_h.v iter7 window-clear scoped to window[0] only (HDL Audit
    improvement #2): i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
    [main.c]
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2026-05-31 firmware: VTC mode selection follows OUTPUT_1080P (was hardcoded MODE_720P60)
    Bug found 2026-05-31 during the 1080p30 passthrough bench test: the
    vtc_setup() call at line 1311 always used MODE_720P60 regardless of the
    OUTPUT_1080P compile define. VDMA HSIZE was correct (parametrized via
    FRAME_W → STRIDE), but VTC told axis_to_vid_io to gate only 1280 cols
    of active video per row. At 1080p builds the output rendered ~half
    each row, then VTC's HSync fired and started the next row, producing
    the visible horizontal-doubling artifact on the bench monitor.
    Fix is the same #ifdef pattern already used for FRAME_W/H:
    #ifdef OUTPUT_1080P
    if (vtc_setup(&MODE_1080P30) != XST_SUCCESS) return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
    [main.c]
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2026-05-31 control-plane: schindlerd v0.1 skeleton (V0a item #5)
    Single-file Python daemon bridging:
    - Firmware over /dev/ttyUSB1 (J-command JSON-RPC)
    - Web/remote clients over WebSocket on :8081
    - Catalog v0.1.0 loaded from control-plane/catalog-v0.1.0.json
    Architecture per docs/control-plane-architecture.md §V0a.
    Key pieces:
    - CatalogControl handles enum string↔int translation so client-side values
    stay human-readable (\"boxcar_2tap\") while firmware sees plain ints.
    - UartBridge runs serial I/O in a worker thread, uses asyncio.Future to
    rendezvous with the asyncio dispatch coroutine. JSON_LINE_RE filters
    firmware log noise from JSON-RPC replies.
    - Dispatcher exposes 8 me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
    [schindlerd.py]
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2026-05-31 control-plane: V0a bench polish — availability gating + slider coalesce
    Three fixes surfaced during the first end-to-end browser smoke:
    1. Hide controls the firmware doesn't actually implement
    - Daemon probes firmware system.list_controls at first system.catalog
    request and annotates each catalog entry with available=true/false.
    - requires_status=\"placeholder\" forces unavailable (frc.mackin_alpha).
    - UI skips controls with available===false. Mackin slider no longer
    renders on iter5-1080p-clean (it depends on mackin-impl-wip wiring).
    2. Coalesce slider input events per control
    - Dragging the saturation slider fires 100 control.set/sec, which
    overwhelms the ser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
    [boot_capture.py, jsmoke.py, schindlerd.py]
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2026-05-31 control-plane: V0a+1 #2 + #3 — version handshake + multi-client sync
    #2 Catalog version handshake (UI-side)
    - UI declares UI_CATALOG_VERSION = "0.2.0" (bumped when the UI starts
    relying on new schema features).
    - At connect, checks daemon's reported version (already in
    system.identify response).
    - Same-major + UI <= daemon: silent ok.
    - Same-major + UI > daemon: yellow banner ("daemon is older, unknown
    new UI features will be inert").
    - Different major: red banner ("major mismatch — controls may not
    render"). UI continues but warns.
    - Banner element added with warn/error styles.
    #3 Multi-client coordination (daemon-side)
    - After every successful _m_control_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
    [schindlerd.py]
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2026-05-31 control-plane: fix status panel race — status.snapshot RPC method
    Bug surfaced by Justin on bench 2026-05-31: status panel only showed
    the fluctuating source_rate field; stable values (S2MM_SR, MM2S_SR,
    source_lock, output_rate) stayed at "—".
    Root cause: connect-time snapshot replay raced with browser-side
    renderCatalog. The WS handler immediately sent all 5 known status
    notifications to the freshly-connected client, but the browser's
    controlRows[id] map was still empty (catalog hadn't been fetched +
    rendered yet) — handleStatusUpdate found `rec === undefined` for
    every one and silently dropped them. Then dedup in TelemetryParser
    prevented stable values from re-publishing, so the pan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
    [schindlerd.py]
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
